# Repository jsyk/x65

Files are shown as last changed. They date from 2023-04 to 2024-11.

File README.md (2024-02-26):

X65
====

The X65 is an ultimate computer for everyone interested in the venerable 65-series of 8-bit and 16-bit CPUs,
i.e. the 6502 and 65816. Specifically, it is built with the W65C02S or W65C816S CPU chips from Western Design Centre.
The 16-bit 65816 (W65C816S) CPU variant is the default and preferred CPU, as all screen-shots shown below were done on the 16-bit system.
The 65816 CPU powered the [Super Nintendo Entertainment System (SNES)](https://en.wikipedia.org/wiki/Super_Nintendo_Entertainment_System) 
and the [Apple IIGS](https://en.wikipedia.org/wiki/Apple_IIGS).
The older 8-bit 6502 CPU was the heart of NES, Apple I and II, many Ataris, Commodore 64, and many many more.

The design of X65 is fully open-source and open-hardware, and we also prefer to use just the open-source development tools
whenever possible. The X65 computer hardware is designed with modern electronics parts, but with a little bit of retro feel.
The computer is backward compatible with the 8-bit Commander X16 -- i.e. it can run their ROM, but since that ROM is copyrighted
and non-free, this is a no-go in the long run.
The goal is to build a fully *open* 8/16-bit system with good architecture and retro-gaming performance.

Compared with modern powerful platforms like x86, ARM or RISC-V, the small 65-series 8-bit or 16-bit system has the advantage
that one person, a software programmer or electronics designer, can fully comprehend the whole system with all details. 
There are not many abstraction layers hidden in supporting libraries or big frameworks. (In fact, there are none. It is just bare metal.) 

_Interfaces_: VGA 640x480 out, Stereo sound out (FM and PSG), PS/2 keyboard and mouse, SNES controller 2x ports,
Ethernet LAN 10/100Mpbs with RJ45, SDHC card slot, power-in 5V USB-C port, In-Circuit Debugger (ICD) over the USB-C with 
PC host software in Python and supporting JTAG-like functions for the 65xx platform (CPU step, trace, memory dump & poke).

Project web pages: http://www.x65.eu  -> currently links to http://www.jsykora.info

3D-render of the *Single-Board Computer* version:

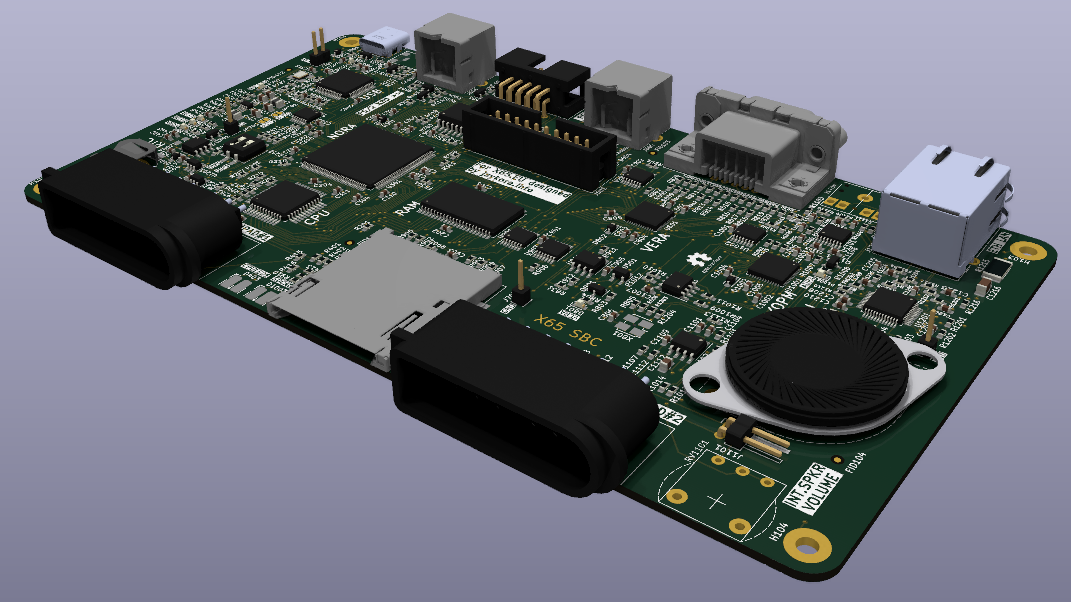
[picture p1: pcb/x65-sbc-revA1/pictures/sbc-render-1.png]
Version SBC


Desktop setup with X65-SBC, PS/2 mouse and keyboard and a VGA monitor. Running `Planet X16' by David Murray with CX16 ROMs:

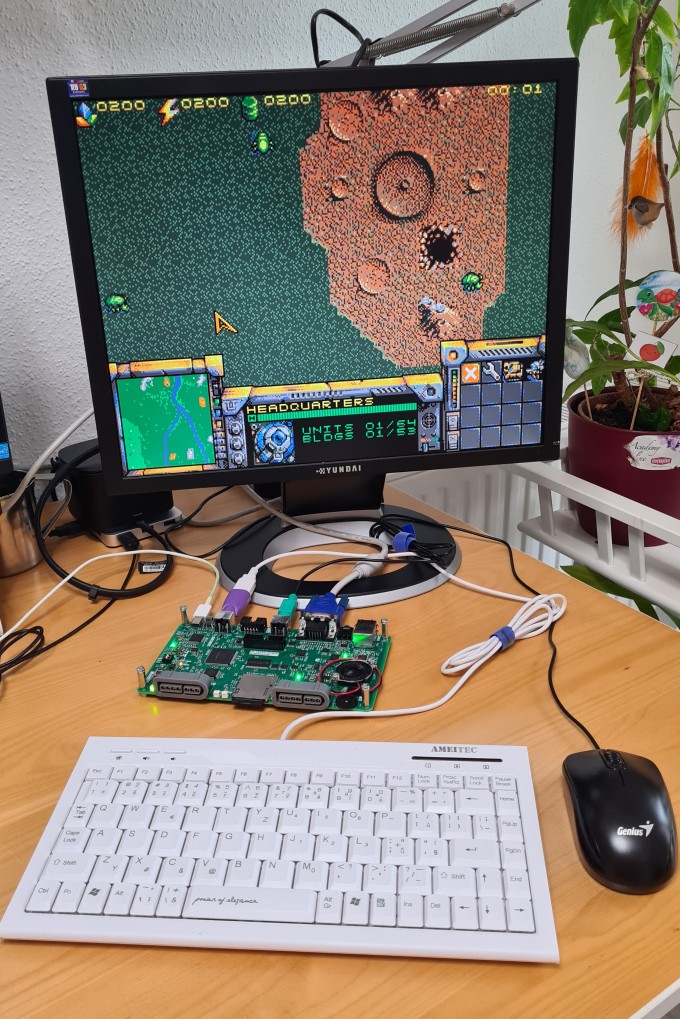
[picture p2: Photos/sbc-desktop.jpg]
Desktop with SBC


General Project Features:
-------------------------

* The CPU is W65C02 (8-bit) or the W65C816 (16-bit; default-preferred). The PCB supports both assembly options.
* Backward software compatibility with the [Commander X16](https://www.commanderx16.com/) computer.
  Can run unmodified CX16 ROM for testing purposes (beware: the ROMs are copyrighted non-free code!).
* Designed with components (chips) that are in production and available from normal electronics parts distributors in 2024,
  such as Mouser, Farnell, Digikey etc. We avoid obsolete parts.
* Balanced modern/retro design built around the central 65xx CPU supported by semi-ASICs (FPGAs) for system control (NORA),
  video (VERA) and audio (AURA) generation. The FPGAs are the little ones from the iCE40 series, and coded in verilog.
  These are modern takes on the "old masters'" designs with ULA, VIA, SID etc.
  *There is no hidden ARM or RISC-V doing heavy lifting in the background.*
* Free and open-source design. DIY and hobby-builders friendly. 
  Low-cost to build even in small quantities by individual hackers.

Block Diagram
---------------

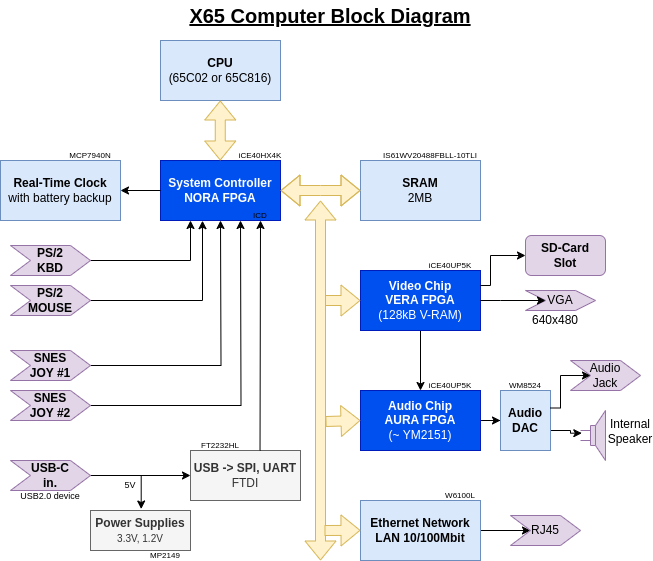
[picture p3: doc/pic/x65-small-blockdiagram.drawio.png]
Block Diagram


Hardware Specification:
------------------------

* **CPU**: [W65C02 or W65C816](doc/cpu02vs816.md) in the QFP-44 package, running at 8MHz, supplied by 3.3V.
* **Memory**: 2MB asynchronous SRAM, common for ROM and RAM.
* **System controller** semi-ASIC, aka north-bridge, aka NORA: Lattice FPGA iCE40HX4K (TQFP-144) handles address decoding, 
  glue logic, PS/2 interfaces, in-circuit debugger and more. 
  "NORA" stands for NORth Adapter, has a similar function like the north bridge in a PC/X86 architecture.
  NORA takes care of the [memory address map](doc/mem-map.md) and hosts most of the [IO registers](doc/ioregs.md).
* Two ports for **SNES-style controllers**, handled by NORA.
* Two **PS/2 ports** for keyboard and mouse, handled by NORA. (note: we reimplement CX16 arduino code in pure hardware logic in verilog.)
* **Colour video** output through VGA connector, up to 640x480 pixels. 
  Generated by [VERA FPGA](https://github.com/X16Community/vera-module): the Video Embedded Retro Adapter, in Lattice FPGA iCE40UP5K. 
  The same is used in Commander X16.
* **Stereo audio** output through 3.5mm jack port. 
  Sound comes from two sources: FM-synthesis (OPM) by YM2151 clone [IKAOPM](https://github.com/ika-musume/IKAOPM) 
  implemented in [AURA FPGA](doc/aura_ym2151.md) (iCE40UP5K),
  and Programmable Sound Generator (PSG) available in VERA FPGA. These are digitally mixed in AURA and passed to a DAC.
  Besides the output jack connector, the sound can be also heard from a small on-board mono speaker.
* **SD-card slot** supporting SDHC cards (handled by VERA FPGA).
* **LAN 10/100Mbps** Ethernet port (RJ45) implemented by [Wiznet W6100](https://www.wiznet.io/product-item/w6100/) chip, 
  with hardware-integrated TCP/IP v4/v6 stack.
* **Real-time clock** (RTC) chip with battery backup.
* [**In-circuit debugger**](doc/icd.md) (ICD) integrated with NORA and accessible over the device USB-C port from a host PC
  running Linux or Windows. The ICD can write all permanent (SPI-Flash) memories in the system, 
  even in a totally empty / bricked state. PC host software is written in Python and should be portable to other 
  fruitful systems besides Linux and Windows.
  Together with NORA the ICD supports JTAG-like functions like memory poke/dump, CPU stop/step, instruction
  trace buffer, interrupt forcing/blocking etc.
* **Power input** 5V from a standard USB Type-C device port.
  The X65 computer can be powered from a normal host-PC USB port (for development with ICD), 
  or runs standalone from a common Mains/USB phone charger with just 5V output.
* Single-board PCB 180x100mm, 4-layers.

Hardware Photos:
----------------

Overview photos (2024/02) - Single-Board version:

**SBC Front view photo**:

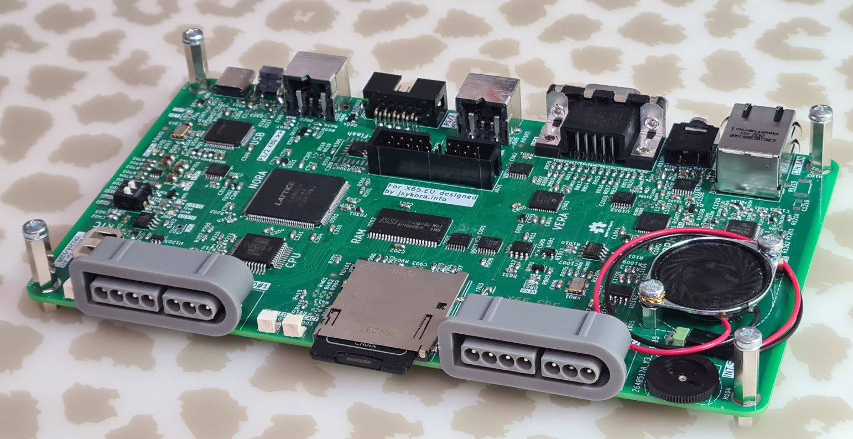
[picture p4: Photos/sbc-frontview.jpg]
Front view photo


**SBC Rear view photo**:

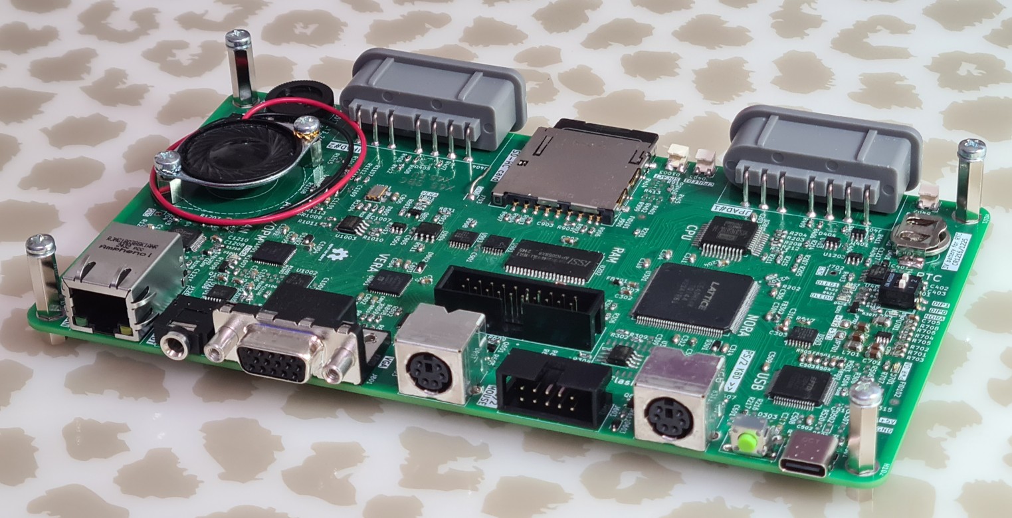
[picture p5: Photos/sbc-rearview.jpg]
Rear view photo


**SBC Top view with labels**:

Engineering testing samples, hand-assembled:

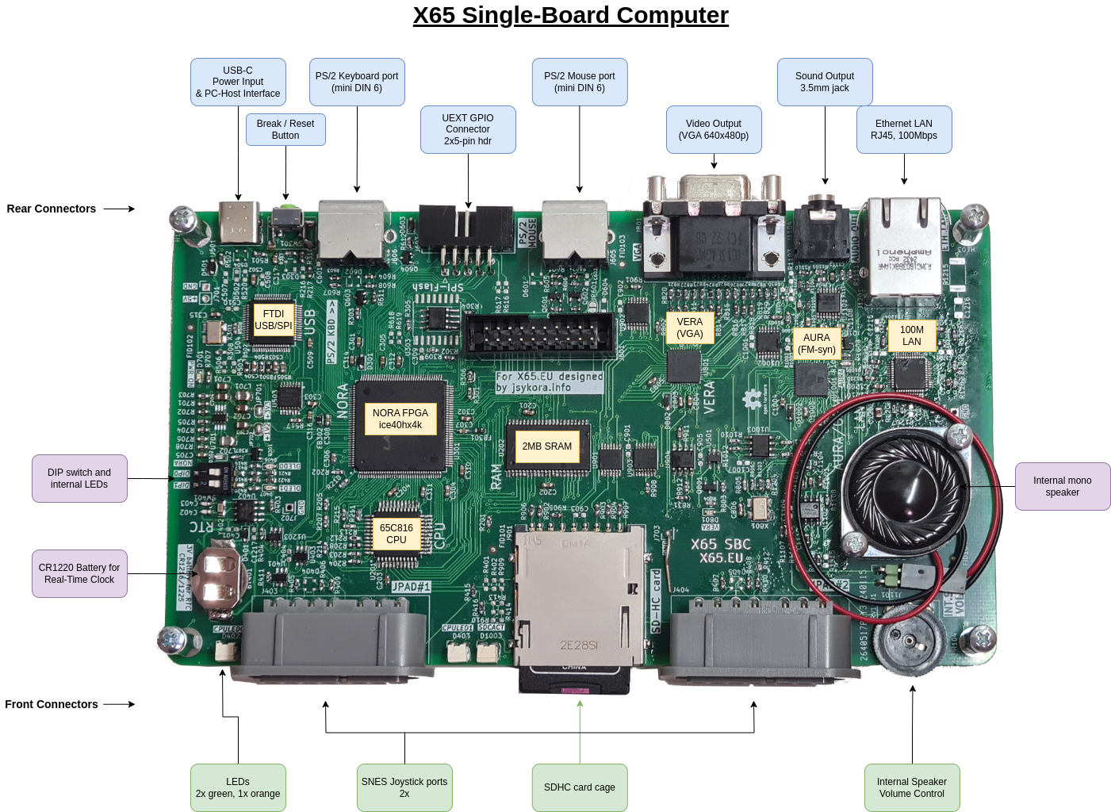
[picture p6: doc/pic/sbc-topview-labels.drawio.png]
SBC topview with labels


Demo Software Screen Photos
----------------------------

Running Commander X16 ROM and BASIC program (compatibility testing only, not allowed in production use due to a proprietary license):

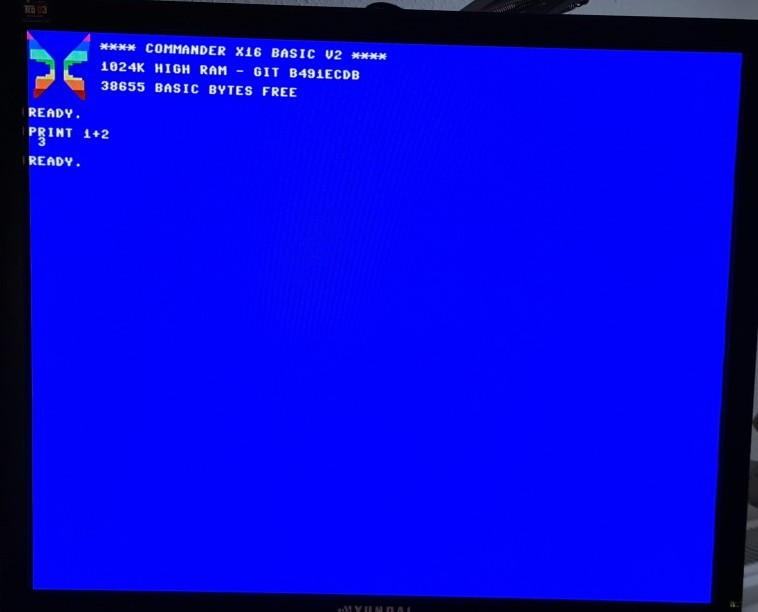
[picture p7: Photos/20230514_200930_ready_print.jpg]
X16 Booted


**BAD METAL** demo from CX16:

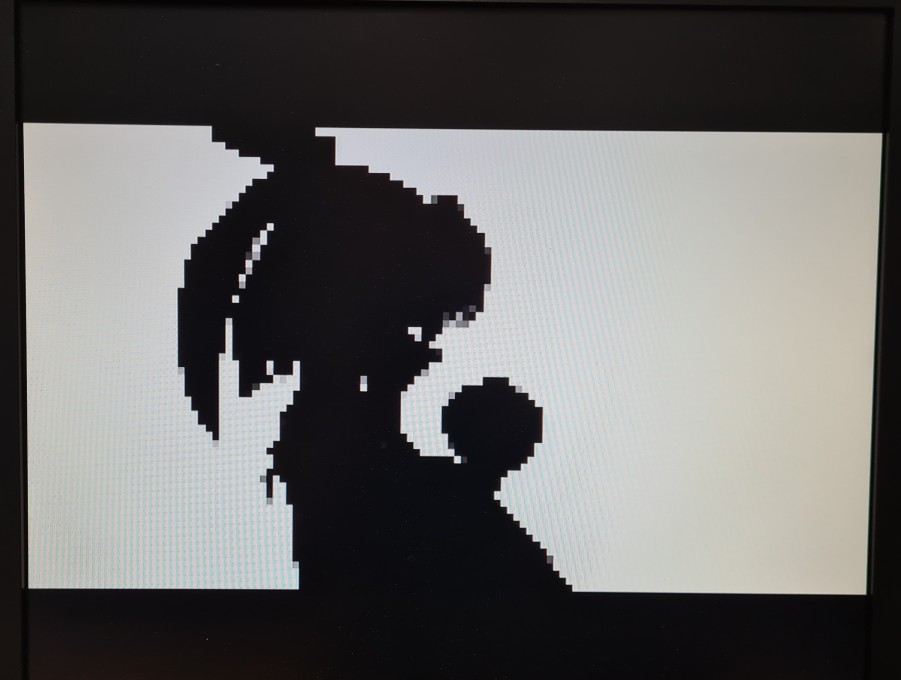
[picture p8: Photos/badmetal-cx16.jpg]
BadMetal


**CALLIOPE** music player from CX16:

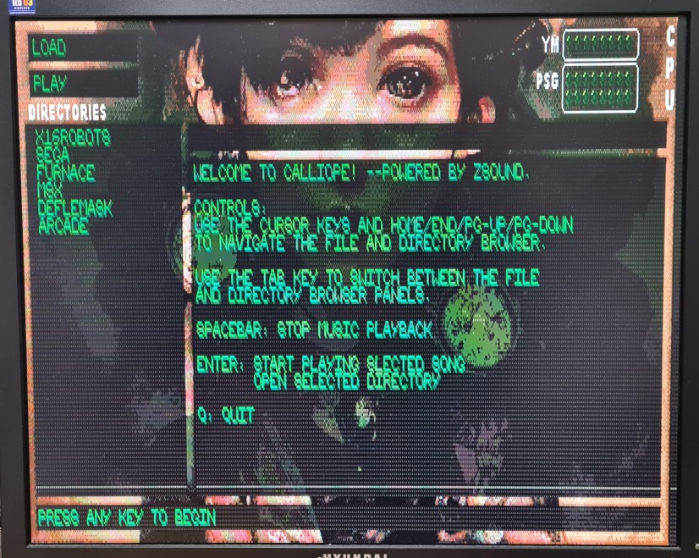
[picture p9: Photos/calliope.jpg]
Calliope


**Crazy Boulders**, a CX16 game by Dušan Štrakl:

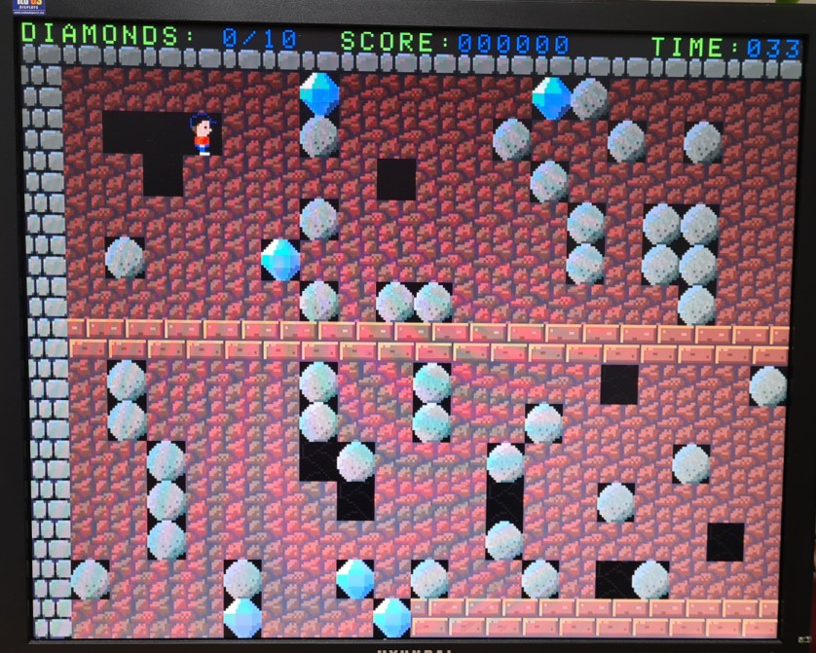
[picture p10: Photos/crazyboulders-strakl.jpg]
Crazy Boulders


**Crazy Lander**, a CX16 game by Dušan Štrakl:

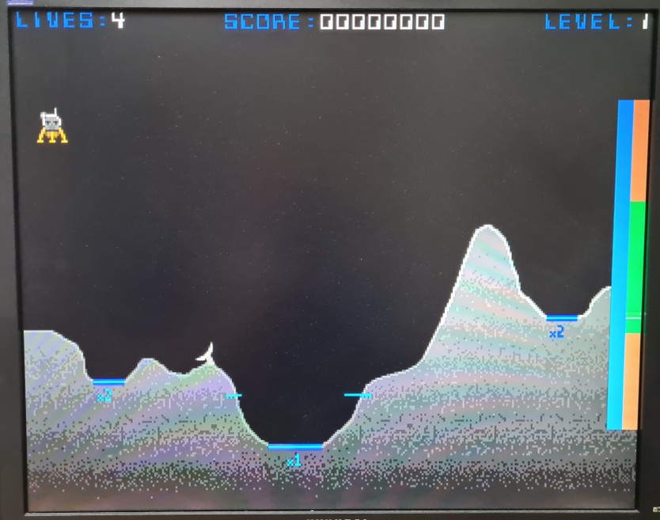
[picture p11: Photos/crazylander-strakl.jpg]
Crazy Lander


**Crazy Pong**, a CX16 game by Dušan Štrakl:

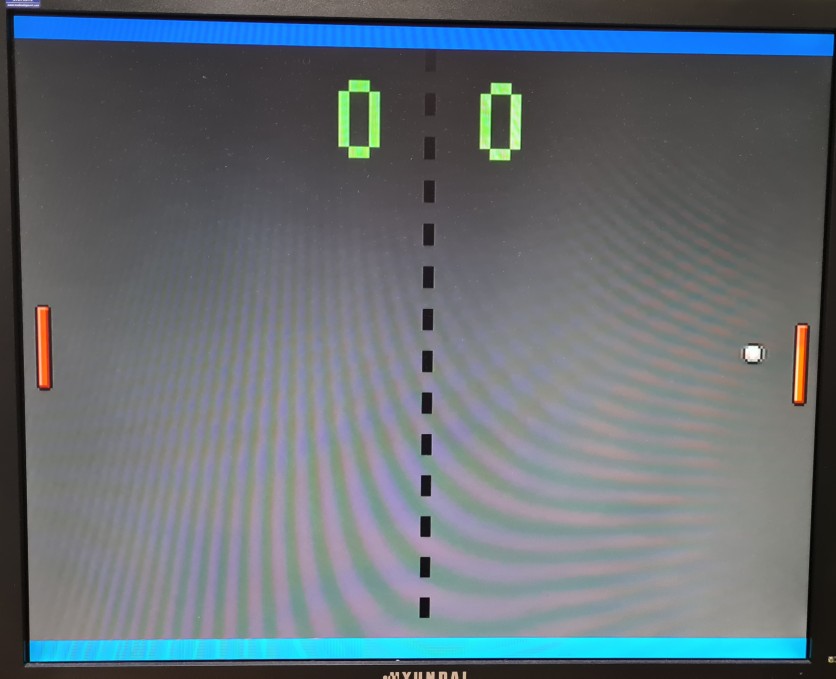
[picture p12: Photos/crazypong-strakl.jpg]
Crazy Pong


**Planet X16**, a CX16 game by David Murray:

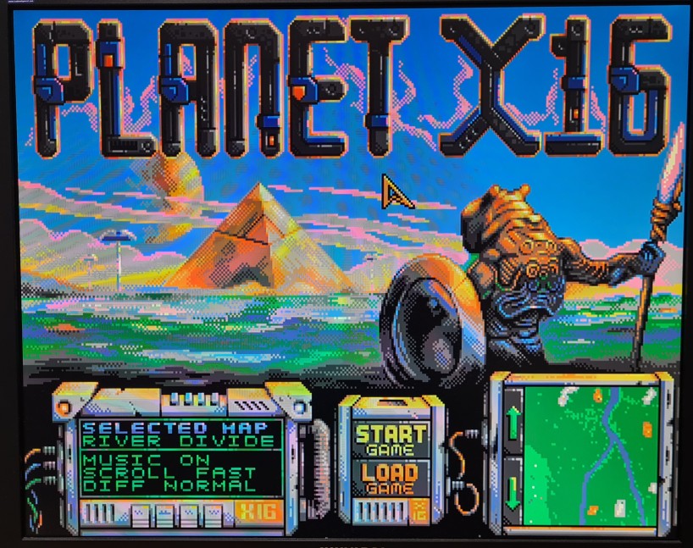
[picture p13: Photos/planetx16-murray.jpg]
Planet X16


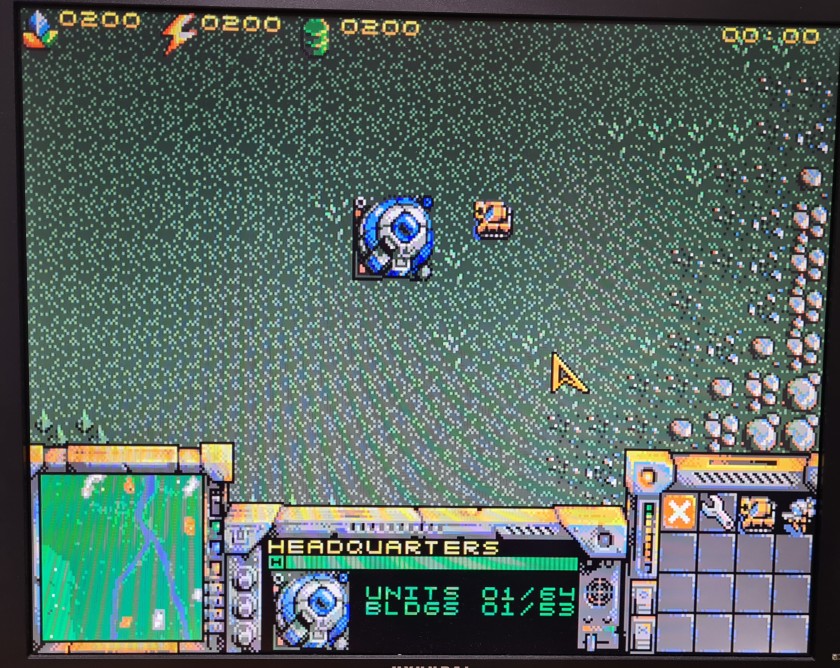
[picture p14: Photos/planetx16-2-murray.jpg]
Planet X16


[**Integrated In-Circuit Debugger**](doc/icd.md) can live-trace the CPU from a Linux PC over the USB:

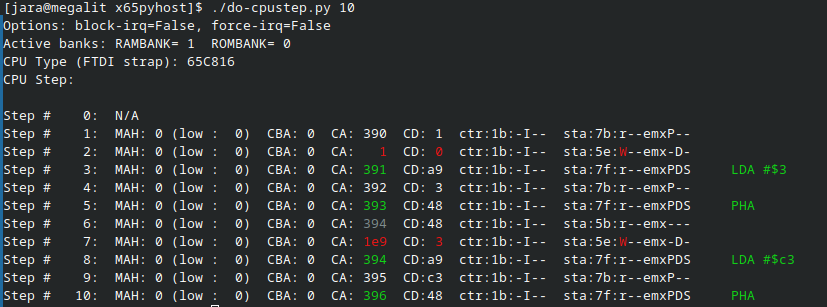
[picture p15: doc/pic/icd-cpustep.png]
ICD CpuStep


Structure of the GIT repository:
---------------------------------

* `doc' --> documentation
* `fpga-aura' --> verilog code for the AURA FPGA (Audio) with referenced IKAOPM sources.
* `fpga-nora' --> verilog code for the NORA FPGA on the motherboard.
* `fpga-vera' --> VERA FPGA bitstream (100% derived from https://github.com/fvdhoef/vera-module)
* `pcb' --> hardware projects in Kicad:
  - `mobo-rev01' --> Motherboard rev01 - OBSOLETE
  - `vabo-rev01' --> Video/Audio board rev01 - OBSOLETE
  - `x65-sbc-revA1' --> *Single-Board computer*
* `x65prog' --> linux software to program the on-board SPI flash memories from a host Linux PC via the USB link.
* `x65pyhost' --> python scripts for accessing/debugging the X65 from a host PC via the USB link.

Schematics in PDF:
------------------

**SBC Revision A1:**

* [X65-SBC, revA1 - PDF scm](pcb/x65-sbc-revA1/x65-sbc-revA1.pdf)

**SBC Revision B1:**

* [X65-SBC, revB1 - PDF scm](pcb/x65-sbc-revB1/x65-sbc-revB1.pdf)

Software:
-----------

The X65 is software-backwards-compatible with the *Commander X16*. 
It means the X65 could run unmodified CX16 ROM and programs, excluding programs depending on some of the hardware features 
in CX16 that are not supported here: cartridges, Commodore IEC port.
However, the CX16 ROM is a **proprietary**, non-open-source and non-free, piece of software created by Commodore
and (somehow) licensed to the CX16 creators. *The licensees do not wish that the ROM runs on any other HW than their own.*
Therefore, I could not recommend running that ROM on the X65 computer.

Presently I am not decided which operating system or runtime shell would be the best / easiest to port to X65.
There some existing systems that could be ported here, for example:

* [MEGA65 OPEN-ROMs](https://github.com/MEGA65/open-roms) (true free open-source sw),
* [FastBasic](https://github.com/dmsc/fastbasic)
* [GeckOS](http://www.6502.org/users/andre/osa/index.html)
* ...

Random Questions & Answers
---------------------------

**Why was this project started?**

This project started in March 2023 when I saw a prototype of Commander X16 in one of the youtube videos
of the 8-bit guy, David Murray. I immediately wanted to play with it but at the time his project was not released to the public,
the hardware could not be bought. So I decided to build one myself, based on public information available
about the CX16. And at the same time I was not too pleased with the architecture and implementation
of the CX16, not satisfied with many design choices they did. 
Consequently, my X65 tries to improve in many areas while being software-compatible.

**What is the relation to *Commander X16* and its authors?**

I have no relation or contact to the authors of Commander X16.
The public discussion forums for CX16 on discord and reddit have the policy that any discussion or mention of any
*clones* of CX16 is forbidden. 
While I find this policy strange for a community project, I respect it.
Therefore I do not tell the guys about the X65 project.

**What is the license of X65 project? Which copyrighted material was used?**

I used publicly available information on wikipedia and in the X16Community's public forums and repositories to reconstruct the CX16 architecture.
I don't have access to the schematics of X16, and I don't own that computer and never seen it in person.
My analysis of the CX16 architecture is available in the file [cx16.md](doc/cx16.md).
The [VERA](https://github.com/fvdhoef/vera-module) FPGA by Frank van den Hoef, also [here](https://github.com/X16Community/vera-module),
 was reused as-is and it is covered by the open-source MIT license.
The AURA FPGA is based on [IKAOPM](https://github.com/ika-musume/IKAOPM), a YM2151 reconstruction in verilog, and it is covered by the BSD 2-Clause License.
All my documents and designs in this repository are covered by the [MIT license](LICENSE).
The restricted CX16 ROMs are not part of this repository.

**What are the advantages of X65-SBC over other retro-modern-computers?**

The X65-SBC is a complete computer system with ports for a keyboard and a mouse, a high-resolution VGA output (128kB Video-RAM), 
and high-quality stereo audio capable of PCM, PSG (Programmable Sound Generator) and FM-synthesis sound generation.
Compared with other 65xx-based computers, we support the 16-bit processor 65C816 which is capable of direct addressing of 
up to 16MB of RAM; the X65-SBC includes 2MB of fast SRAM by default.
System controller is realized by NORA FPGA (lattice ice40hx4k) and potentially allows experimenting with additional
features like virtual memory or mathematical coprocessors.
The hardware supports direct programming of FPGA bitstreams via the USB-C port from a Linux PC; in a way the X65-SBC
is a self-contained FPGA development platform.
The design is fully open-source.

**Where can I get the hardware?**

As all relevant HW design data is available in this repository, anybody with appropriate electronics knowledge 
and a lab can build own copy of the X65-SBC hardware.
The cost of electronics components is around 130 EUR, plus the cost of board assembly (which can be done DIY if necessary).
Maybe in the future I can run a very small series build for interested programmers and "hackers". 
However, as these builds surely will not have the requisite FCC / UL / CE approvals (that costs addional money), 
the resulting devices could only be used in a lab for development purposes by knowledgable users.
I am open to the possibility that some company decides to commercionalize X65-SBC as a sellable product and puts it on the market :-)

**Is there an emulator for PC?**

Presently an emulator is not developed yet.
It could be done perhaps based on the [CX16 emulator](https://github.com/commanderx16/x16-emulator); 
the CPU emulation has to be extended to 65C816 and new features (registers)
available in NORA and in W6100 (ethernet interface) need be implemented.

Contact
--------

**Jaroslav Sýkora**
- Personal: http://www.jsykora.info,
- GIT account: https://github.com/jsyk,
- Mastodon: https://oldbytes.space/@jarda,
- (Physically in the Czech Republic.)

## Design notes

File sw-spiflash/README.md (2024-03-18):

Software in NORA's SPI-Flash
=============================

This directory contains the software for NORA's SPI-Flash, which acts as a ROM for the system.
The SPI-Flash is divided in blocks of 64kB.
The first three blocks (192kB) are reserved for NORA FPGA bitstream.
That is followed by a 64kB block for Secondary Bootloader (SBL), and then the operating system
or a standalone application.

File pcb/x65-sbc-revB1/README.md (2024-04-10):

X65-SBC-rev.B1
================

X65 Single-Board Computer, schematic & PCB revision B1.

3D render view of the X65-SBC rev.A1 (Kicad)

Schematic (PDF)

Interactive BOM

!! WORK IN PROGRESS !!
=======================

I restarted changes to revB1 on 04/2024 with the following goals:
* fix remaining issues (SDC power, ESD, see below)
* optimize for machine assembly

To-Be-Done changes from rev.A1 to rev.B1
-------------------------------------------
* add power switch for SDC +3.3V, add digital lines disconnect
    - probably AP2191D ?
* change ESD protection
* change decoupling caps
* move speaker connector
* ...??? see pdf

Implemented changes from rev.A1 to rev.B1
-------------------------------------------
* change green LED resistors to 2k7 (although this depends on LED).
* Remove D504 (USB ESD): the SP0503 is not suitable!
* Add 5V and +3.3V pins to J601 internal mem.bus connector.
* Changed AURA FPGA footprint to the smaller EP pad (now the footprint is the same as VERA)

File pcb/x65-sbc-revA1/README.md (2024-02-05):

X65-SBC-rev.A1
================

X65 Single-Board Computer, schematic & PCB revision A1.

3D render view of the X65-SBC rev.A1 (Kicad)

Schematic (PDF)

Interactive BOM

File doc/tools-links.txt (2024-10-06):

Tools and Sources
===================

Kicad 6, 7

Assembler: 
* ca65 / ld65 -- used in vera at least, in C16 ROMs
    https://cc65.github.io/doc/
    https://cc65.github.io/doc/ca65.html#ss1.1
    Part of Fedora RPMs package cc65
* cc65 - eg in C16 ROMs; can do 6502 and 65816 (directive .p816)
    https://github.com/cc65/cc65/tree/master
    Part of Fedora RPMs package cc65
* ACME - used in some examples; has 6502 and 65816
    https://github.com/martinpiper/ACME
    https://github.com/meonwax/acme

YosysHQ/IceStorm for iCE40 FPGA synthesis
    https://clifford.at/icestorm
    https://yosyshq.net/
    https://github.com/YosysHQ
    
* compiler for 65c816
    http://forum.6502.org/viewtopic.php?f=2&t=7573
    https://github.com/lcc-816
    https://github.com/hth313/Calypsi-tool-chains
    http://forum.6502.org/viewtopic.php?f=2&t=6717
    https://github.com/nArnoSNES/tcc-65816
    https://www.calypsi.cc/

https://llvm-mos.org/wiki/Welcome

https://wiki.superfamicom.org/
https://wiki.superfamicom.org/learning-65816-assembly

PROG8
    https://github.com/irmen/prog8

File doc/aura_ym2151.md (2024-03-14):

AURA FPGA: The replacement of YM2151
====================================

*Abstract:
The article discusses the sound system in the X65 computer. It explains that the sound is generated by two sources: 
the Programmable Sound Generator (PSG) in the VERA FPGA and the MIDI FM-synthesis chip YM2151. 
The article provides a block diagram of the sound subsystem and explains the functionality of each component. 
It also discusses the principle of FM sound synthesis and mentions the difficulty in finding modern software compatible 
replacements for the YM2151 and YM3012 chips. The article introduces an FPGA emulation solution called AURA, 
which uses the Lattice iCE40 FPGA to replicate the YM2151. The implementation of AURA on the x65 board is described, 
along with a cost comparison between the Yamaha chips and the AURA FPGA. 
The article concludes by mentioning a demo application called Calliope that runs on the x65 hardware 
and plays sound files through AURA. 
Overall, the AURA FPGA solution is presented as a viable and cost-effective alternative to the original Yamaha chips.*

Sound in Commander X16
-----------------------

Sound in Commander X16 is generated by two sources that are mixed together:

  1) by the Programmable Sound Generator (PSG) in VERA FPGA, and
  2) by the MIDI FM-synthesis chip YM2151. 

The following picture is a block diagram of the sound subsystem in C'X16:

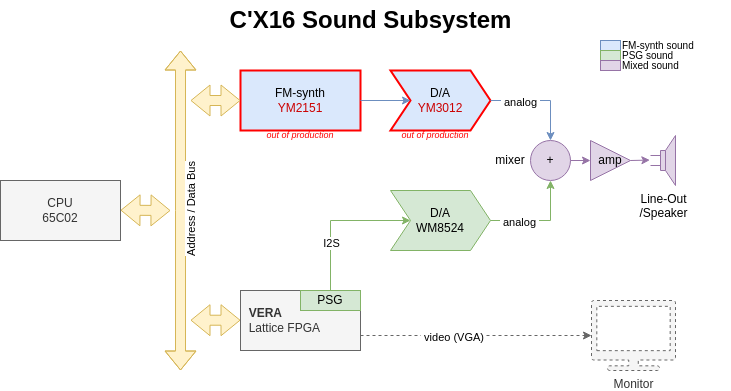
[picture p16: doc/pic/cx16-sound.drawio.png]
Block Diagram of Sound Generator in C'X16


The PSG in VERA FPGA is a stereo sound generator loosely based on SID. It supports 16 channels (voices) and PCM playback.
There is no ADSR or filters. This must be provided by software.
The PSG is an integral part of VERA FPGA user logic that also generates the VGA video output.

MIDI-like sound synthesis is provided by YM2151. Yamaha called it an FM operator Type-M (OPM).
The chip outputs sound digitally as a 10-bit mantissa / 3-bit exponent samples, two channels (left and right),
at the audio sample frequency of about 55 kHz. This digital sound stream is converted to an analog signal 
using special a D/A converter YM3012, also developed by Yamaha.
The picture below illustrates the basic circuit, as taken from the datasheet:

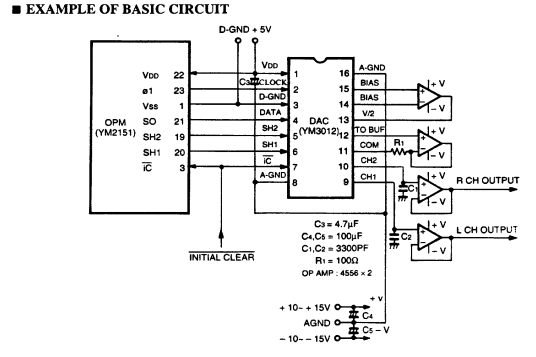
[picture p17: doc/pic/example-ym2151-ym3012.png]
Example of Basic Circuit ym2151+ym3012


YM2151 was created by Yamaha in 1980's, being used by Atari and Sega arcade systems starting in 1984.
As of 2023, this chip is perhaps a quarter of century out of production.
The chip interfaces with then-standard 5V TTL logic, and the D/A converter YM3012 even requires +/- 12V rails for its analog output.

Principle of FM Sound Synthesis
-------------------------------

FM sound synthesis is quite complex topic and I do not claim to understand it so well.
I would recommend the following article which provides some background and details:

https://www.perfectcircuit.com/signal/what-is-fm-synthesis

Sound in x65
------------

I was looking for a modern software compatible replacement of these chips and, since the architecture is unique, 
the only practical solution is via an emulation in FPGA. I wanted to use a Lattice iCE40 FPGA, to keep in line with the rest
of my x65 design (both NORA and VERA are iCE40 FPGAs). 
There are multiple YM2151 emulations for FPGA available on the open-source internet; I found two: jt51 and [IKAOPM](https://github.com/ika-musume/IKAOPM).
The problem with both, or rather the problem with the original design is that it is using a lot of flip-flops as delay shift-registers.
This is actually not a big deal for modern FPGAs from Altera/Intel or Xilinx/AMD, as they could implement shift-registers efficiently in LUTs.
But an old architecture like iCE40 struggles and is forced to use a lot of basic logic blocks to implement these shift registers.
Therefore, jt51 could not be used because it does not fit in a suitable FPGA of the iCE40 line.
The IKAOPM, after some configuration (USE_DPRAM=1), thankfully fits in the 5K device (ice40up5k-sg48) - allocating around 80% capacity of the 5K device.

I call the FPGA device implementing the compatible FM-synthesis "AURA", from AUdio Retro Adapter.
It is Lattice ice40up5k-sg48 FPGA, the same type used for VERA, so the x65 has twice the same FPGA on the board - for audio and for video.
The emulation main part is done by IKAOPM project, which is a verilog synthesisable replica of the YM2151.

The picture below shows the sound subsystem of x65:

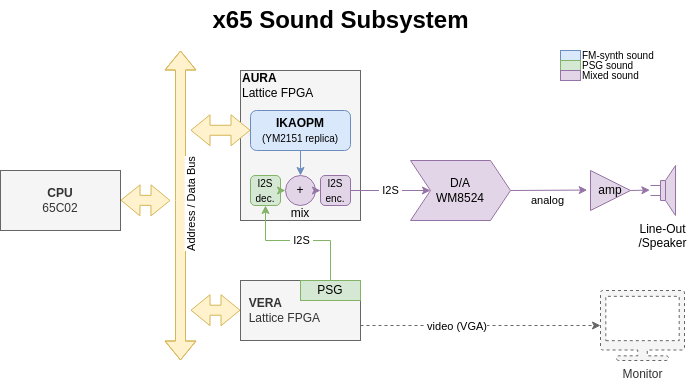
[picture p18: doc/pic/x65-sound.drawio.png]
x65 Sound Subsystem


AURA outputs the sound in the stereo 16-bit I2S format, which is converted to the analog signal by the WM8524 D/A converter.
The PSG sound from VERA is also in the same I2S format. AURA has an auxiliary I2S input for the PSG sound; mixing of both sound sources
is done digitally in AURA.

Implementation on the x65 Board
-------------------------------

The photo bellow shows the x65 audio/video board with the VERA and AURA FPGAs labelled. The DAC chip and the audio and video output connectors
are also visible and marked.

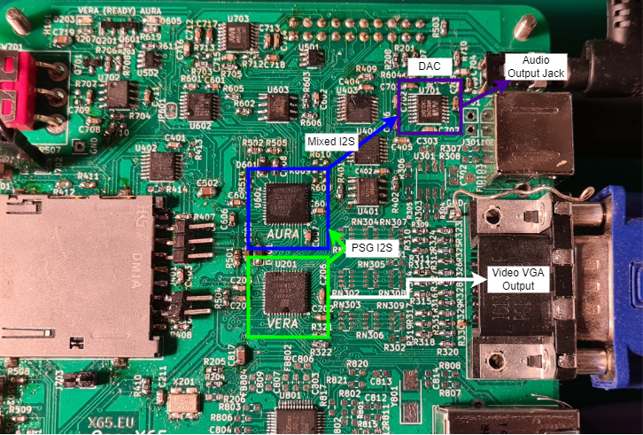
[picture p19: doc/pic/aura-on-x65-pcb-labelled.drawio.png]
Photo of x65 PCB with VERA, AURA and DAC chips labelled


TBD: record sound played through VERA + AURA.

Cost Comparison
---------------

Both Yamaha chips are long out of production (discontinued). 
It is not possible to buy them from normal distributors of electronic parts  like Mouser, Farnell, Digikey etc. 
The Yamaha chips are typically to be had on ebay from various sellers, in various quantities and prices.
A brief ebay listings overview shows that the D/A YM3012 costs around 1 EUR/1pc, and the FM-synth YM2151 around 9 EUR/1pc. 
Therefore the total cost using Yamaha parts could be 10 EUR, plus the analog sound mixer.

The AURA FPGA, ice40up5k-sg48, costs around 9.30 EUR/1pc, or 7.8 EUR in 100-piece quantity. 
To this we should add the cost of one SPI-Flash memory necessary to store the FPGA bitstream; 
I use W25Q16JVSNIQ which costs 0.45 EUR/1pc. 
I do not calculate the cost of the D/A converter WM8524 since it is equally present in both solution (for VERA PSG).
Therefore, the total cost using AURA FPGA is around 10 EUR in 1pc quantity (or better, if bought in quantity).

Demo
----

[Calliope](https://github.com/ZeroByteOrg/calliope) is a player / jukebox application for Commander X16.
It can play files in the ZSM format. It supports output through the VERA PSG and YM2151 FM-synth.
This is a photo od Calliope running on X65 hardware, playing a sound file through the AURA:

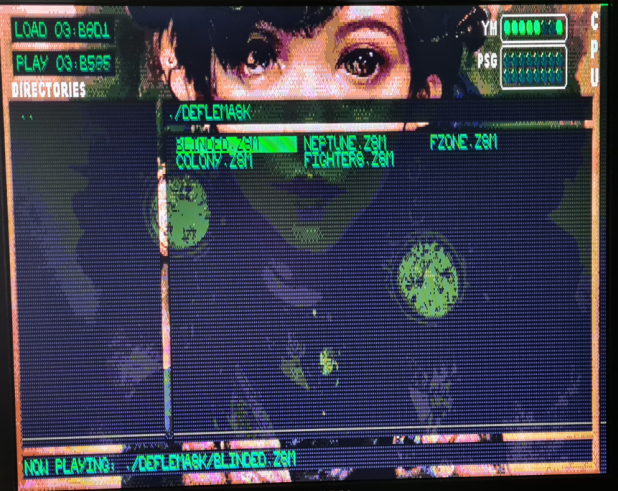
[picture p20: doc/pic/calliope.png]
Calliope on X65


Conclusion
----------

In conclusion, the solution with AURA FPGA has the following advantages:

* good availbility of chips at distributors, 
* the same or better cost, 
* direct interfacing with the 3.3V LVTTL logic used in the x65 design, 
* not requiring +/- 12V for the DAC, 
* smaller total footpring size on the PCB because of small component packages.

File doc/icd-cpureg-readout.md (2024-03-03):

Reading of 6502/65816 CPU Registers by a PC-based Debugger
============================================================

Modern microcontrollers and microprocessors have built-in facilities for external debuggers
to read/write registers, set breakpoints and generally fully control the CPU. 
This is one of the main usecases of the standard [JTAG](https://en.wikipedia.org/wiki/JTAG#Debugging) interface.
The 6502 and 65816 CPUs were created more than a _decade_ before the first version of JTAG was even defined.
They contain no support for external debuggers whatsoever. 

To overcome the lack of debugger support, the system bus controller "NORA" in X65 implements 
the necessary functions for a debugger running on a host PC (with Linux or Windows) and connected over the USB-C port. 
With this support in NORA a debugger can control the 6502/65816 CPU at the instruction level.

One of the basic functions of a debugger is to read out the contents of the programmer visible CPU registers.

For the 8-bit 6502 CPU these are: A, X, Y, S (= SP) (all 8-bit), PC (16-bit), and flags (8-bit); shown below:

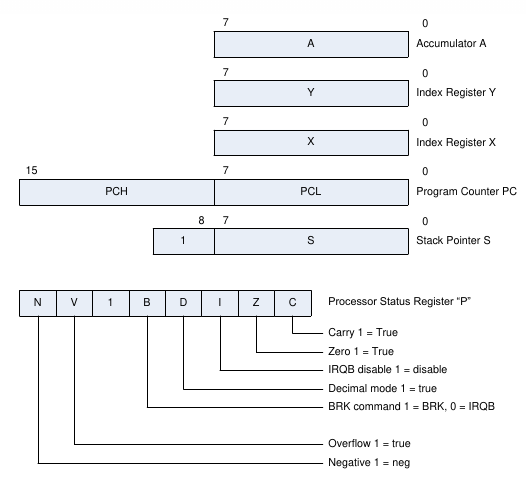
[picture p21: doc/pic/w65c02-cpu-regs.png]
W65C02 CPU registers


For the 16-bit 65816 CPU these are: A, X, Y, S (= SP) (all 16-bit), PC (24-bit), DBR (Data Bank Register, 8-bit), 
Direct Register (DH:DL, 16-bit), and the flags (8-bit); shown below:

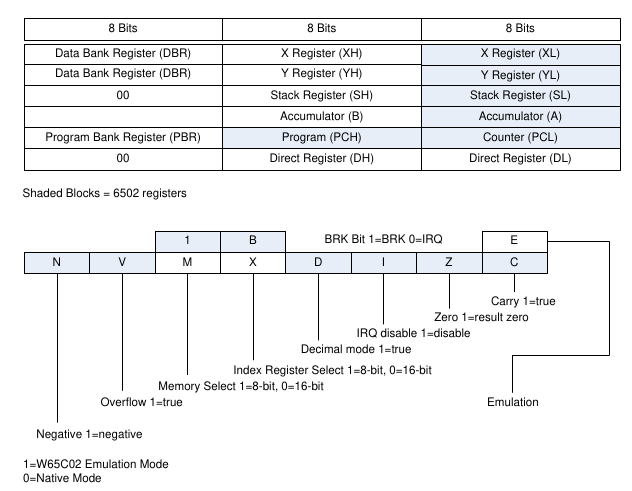
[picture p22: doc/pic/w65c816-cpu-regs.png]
W65C816 CPU registers


Block Diagram of NORA's In-Circuit Debugger (ICD)
--------------------------------------------------

The block diagram below shows the concept of the In-Circuit Debugger (ICD) in the X65 computer.
NORA FPGA implements all interfaces between the 65xx CPU, and the memory bus with SRAM, VERA and AURA FPGAs.
The particular verilog module in NORA that implements the CPU/memory interface is called [bus_controller](../fpga-nora/src/bus_controller.v).
Another module, the [phaser](../fpga-nora/src/phaser.v), generates the CPU clock signal PHI2 
and additional internal timing signals that must be in sync with the CPU execution. 
The third module mentioned in the picture is the [icd_controller](../fpga-nora/src/icd_controller.v)
which controls the bus_controller and phaser during debug sessions, and during system startups,
but othertimes it is idle.

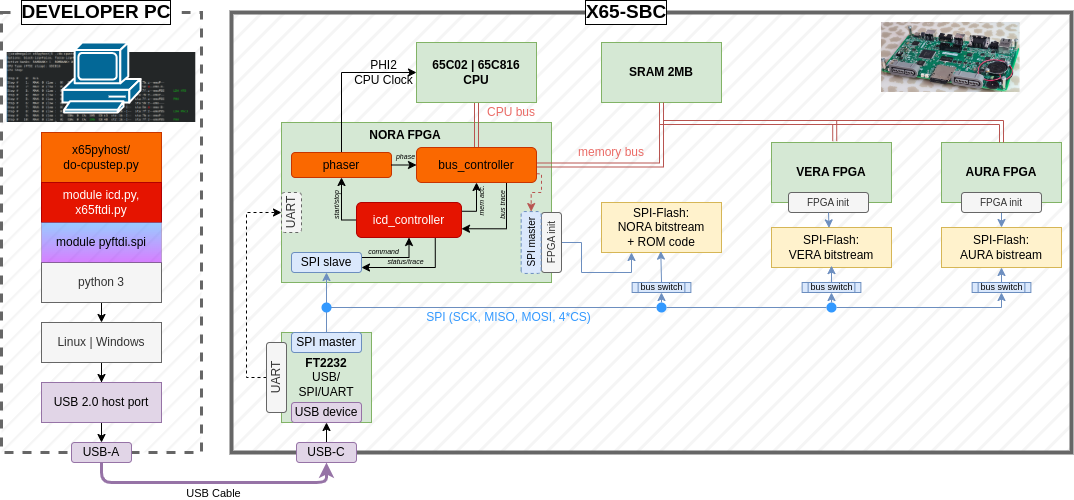
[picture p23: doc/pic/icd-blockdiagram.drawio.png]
ICD Block Diagram


The icd_controller itself responds to commands received from an [SPI Slave](../fpga-nora/src/spi_slave.v)
port, which is connected to physical SPI pins on the FPGA (signals ICD_CSn:in, ICD_MOSI:in, ICD_MISO:out, ICD_SCK:in).
These pins are connected on PCB to the FTDI USB/SPI+UART converter (FT2232H), and from there via a USB cable
to a host PC with a debugger software.

Debugger software for X65 is implemented in Python 3 (with the pyftdi module) and it is available in the
git repository in subfolder x65pyhost.
For simplicity of development, debugger commands are not yet integrated in an IDE but they are available as individual
programs called from a command line.
The most commonly used commands (= python scripts) are listed in the table:

| Command (script)  | Description |
| ---|---|
| do-cpureset.py | Reset and stop the 65xx CPU |
| do-cpurun.py | Run the CPU |
| do-cpustep.py | Stop the CPU and step it for the given number of instructions or CPU cycles |
| do-dump.py | Memory dump (including IO areas) |
| do-loadbin.py | Load a binary from specified host file into X65 memory |
| do-loadprg.py | Load a C64/CX16 program from a .PRG file into X65 memory |
| do-poke.py | Write memory location in X65 memory (incl. IO area) |
| do-readregs.py | Read CPU registers (the CPU must be stopped) |

Register Reading Sequence
--------------------------------------------------

Reading of 65xx CPU internal registers is implemented in the do-readregs.py and do-cpustep.py scripts that communicate
with the ICD module in NORA FPGA over the USB/SPI bridge implemented on the PCB of X65 computer.
Lets discuss how the registers are obtained from the CPU by NORA.
As mentioned previously, the 65xx CPUs have absolutely zero support for external debuggers wishing to access internal registers
outside of a program running in the processor.

The access is gained by forcing a predefined sequence of instructions to the CPU and observing
signals on the CPU Data and Address Buses.
At each CPU cycle, the 65xx processor accesses the external memory for either a read or write.
By observing CPU status signals VPA and VDA (or SYNC), it is possible to determine if any given cycle is an opcode fetch.
If it is an opcode fetch cycle, the debugger can instruct the ICD in NORA to force an *alternative* opcode
to the CPU than what would be read from a memory, thus altering the program flow at will.

The following instruction sequence is forced from the debugger to read out all registers:

    orig_pc:
        PHP             ; we get PC, SP, Flags
        PLP             ; 
        STA $2          ; block writes; We get A, and on 65816 we get B depending on flag M, and we get DH:DL (DPR) on address bus
        STX $4440       ; block writes; We get X, and on 65816 we get XH depending on flag X, we get DBR from CPU Bank Address.
        STY $6          ; block writes; We get Y, and on 65816 we get YH depending on flag X
        BRA orig_pc     ; jump back to the back to leave CPU registers in the original state

The code (PHP-PLP-STA-STX-STY-BRA) is position-independent: it could be execute at any CPU state.
The first two 65xx instructions are *PHP* (Push Flags to Stack) and *PLP* (Pull Flags from Stack).
NORA captures the trace of the the CPU Data Bus, Address Bus and Status signals while these instruction execute
and the debugger uses the trace to reconstruct the original PC (Program Counter) address and 
the SP (Stack Pointer) address, and the flags register.

Screenshot below shows the trace output of *do-cpustep.py* (on Linux PC) when the 65xx CPU (actually 65C816 in Emulation Mode)
is executing the opening PHP-PLP sequence. 
The screenshot is annotated at the top with explanations of trace columns, and at the bottom with the trace fields
that correspond to exposed CPU internal registers:

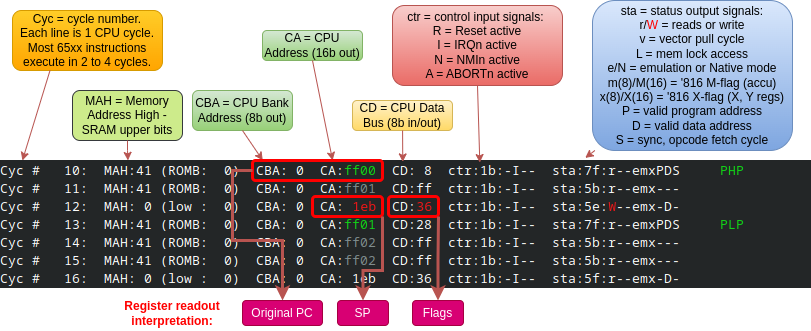
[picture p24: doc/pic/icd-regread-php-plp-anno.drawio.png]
Trace of PHP-PLP instruction in 6502, with annotations


The original PC (Program Counter) is the op-code fetch address of the first instruction.
The SP (Stack Pointer) is the write address in the third CPU cycle (Cyc #12), and the CPU flags are the data value
written to the memory at that cycle.
The instruction PLP is necessary to restore the contents of SP inside the CPU to the original value.

The next screenshot shows the trace of the remaining instructions in the sequence: STA-STX-STY-BRA.
The contents of registers A, X and Y is obtained from the data bus write cycles during the execution 
of the STA (Store Accumulator), STX (Store X-reg) and STY (Store Y-reg) instructions.
To not disturb the original memory contents by these writes, the memory write signal is silently blocked by NORA, 
although this is not reflected in the trace buffer.

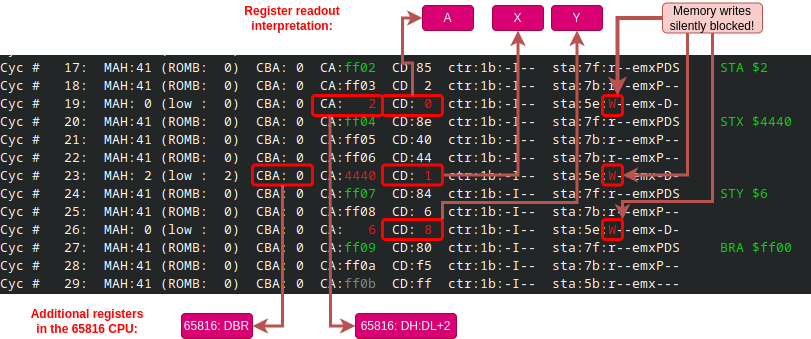
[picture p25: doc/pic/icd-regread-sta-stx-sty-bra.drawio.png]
Trace of STA-STX-STY-BRA


The final instruction BRA (Branch Always) is necessary to restore the original contents of the PC register; 
it instructs the CPU to jump five instruction back.

The 65816 CPU
---------------

So far we discussed how to obtain registers from the 8-bit 6502 processor.
The 16-bit 65816 processor has the common registers extended to 16-bits, plus it has some additional registers.
The traces shown above were obtained on the 65816 CPU running in the 8-bit *Emulation Mode*, where the processor
is behaving like the 8-bit 6502. 
(Emulation Mode is indicated by the "e" in the "sta" field of the trace. 
Mode information is available on an output pin of the processor.)

When the 65816 processor switches to the 16-bit *Native Mode*, the additional registers DBR (Data Bank Register),
PBR (Program Bank Register, part of PC) and DH:DL (Direct (Page) Register) get activated.
The traces above mark where these registers are exposed as well.
Then, depending if the new M and X flags in the CPU Flag Register are cleared, also the Accumulator and Index Registers X/Y are extended to 16-bits.
The M-flag controls the width of the accumulator (A -> AH:AL) and of the memory accesses (in all LD and ST-type instructions), 
and the X-flag control the widths of registers X (XH:XL) and Y (YH:YL).
These three important flags (Emulation or Native mode, M-flag, and X-flag) are available on CPU pins, 
therefore they are always visible in the trace buffer.

The screenshot below shows the trace of the sequence PHP-PLP-STA-STX-STY in case the 65816 CPU is in the 16-bit *Native Mode* 
and also the accumulator and index registers are switched to the 16-bit mode (i.e. M-flag=0, X-flag=0). 
(The BRA instruction is not shown for brevity, but it is also part of the forced sequence.)
We can see that the execution of the STA, STX and STY opcodes gains one additional CPU cycle during which the upper parts
of the A/X/Y registers are written to the memory (these writes are blocked in NORA), and exposed for the debugger.
The contents of the new address registers PBR, DBR, and DH:DL is meanwhile also available on the address bus.

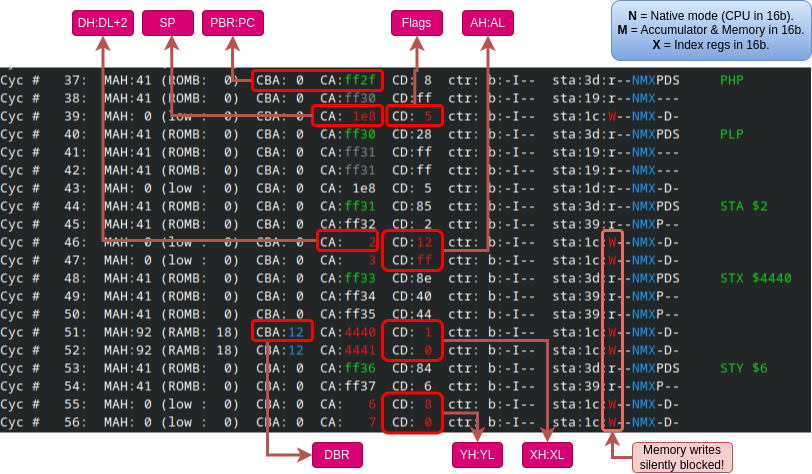
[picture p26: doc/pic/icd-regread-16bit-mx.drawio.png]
Trace of PHP-PLP-STA-STX-STY in 16-bit Native Mode


Integration
-------------

The complete register readout sequence is integrated in the script do-cpustep.py.
This script dumps the 65xx CPU trace buffer and then executes a user-specified number of following instructions.
Finally, the script executes the readout sequence in the background and prints the CPU register values.
The forced readout sequence is not shown in the printed trace, of course.

The screenshot below shows the user interface when the command "./do-cpustep.py 3" (step for 3 instruction) 
is started on a Linux host PC connected with a USB cable to the X65 computer.
The last line is the CPU register contents after the last instruction executed (and before "Upcoming", 
which has *not* been executed yet, it is just the prediction of the debugger based on PC).
Notice how the displayed contents of the A register ($03) in the last line corresponds to the LDA instruction (LDA #$03),
and the contents of the SP register ($1e9) corresponds to the push-address in the first PHA instruction 
($1ea = the SP is decremented AFTER pushing).

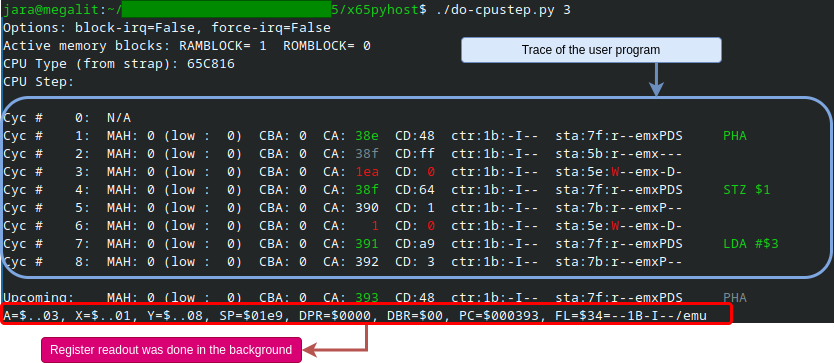
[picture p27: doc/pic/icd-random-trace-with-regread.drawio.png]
Register readout integrated in trace


Conclusion
------------

In embedded systems reading of processor registers via a JTAG connection from a host PC is the basic functionality
that we take for granted.
Using the "NORA" FPGA as the system controller in the X65 computer brings this functionality also to the world
of 6502/65816 processors.

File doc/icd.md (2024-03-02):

In-Circuit Debugger (ICD) for 6502/65816 CPUs
================================================

**In-circuit debugger** (ICD) integrated with NORA and accessible over the device USB-C port from a host PC
running Linux or Windows. 
The ICD can write all permanent (SPI-Flash) memories in the system, even in a totally empty / bricked state. 
PC host software is written in Python and should be portable to other fruitful systems besides Linux and Windows.

Together with NORA the ICD supports JTAG-like functions like memory poke/dump, CPU stop/step, instruction
trace buffer, interrupt forcing/blocking etc.

Example: Live trace/step of the CPU:

ICD CpuStep

Example: Dump of the IO area ($9F00 to $9FFF):

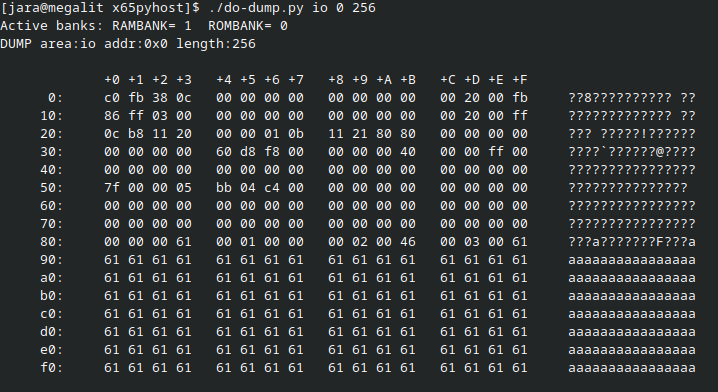
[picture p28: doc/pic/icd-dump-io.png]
ICD Dump of IO area


ICD Block Diagram

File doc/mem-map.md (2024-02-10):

Memory Map
===========

This document describes the memory map of the X65 computer.

Introduction
-------------

To follow the 6502 aesthetics, we write here addresses in hexadecimal numbers with the leading character '$'.
For example, $1234 is the hexadecimal address 0x1234. If the underscore '_' character is used, it hase no functional meaning 
and serves just to visually divide long hex string into human-readable chunks. For example, $123456 could be written also $12_3456.

The X65 computer supports two slightly different processors: 65C02 and 65C816. Default is 65C816.
Following the CPU type, the CPU address space is either 64kB (16-bit) long in case of 65C02 CPU, 
or 16MB (24-bit) long in case of 65C816 CPU.

The 16-bit addresses are specified with four hex-digits, and the 24-bit addresses with 6 hex digits.
When we specify a 16-bit address, e.g. $1234, in the context of the 65C816 this gets extended on the left by 00, 
i.e. it is just identical to $001234 (= $00_1234).

Memory Quantities
------------------

The official 65C02 and 65C816 documentation defines the following multi-byte quantities:

* **PAGE** = 256 Bytes (typically alligned).
* **BANK** = 64 kB (alligned).

The 8-bit 65C02 processor has the special **PAGE ZERO** from $0000 to $00FF and **PAGE ONE** from $0100 to $01FF, for stack. 
It has exactly one 64kB **BANK** from $0000 to $FFFF, which is its entire address space.

The 16-bit 65C816 processor is more complex. It has a **DIRECT PAGE**, which by default is the same as the ZERO PAGE in 65C02, 
but software can relocate it anywhere in the first **BANK** (64kB) of the address space (even to an unaligned address).

Then the 16-bit processor has 256 BANKs of 64kB each. The BANK address is simply the highest-order 8 bits of the 24-bit address.
The lower 16 address bits specify offset within a BANK, which can be up to 64kB.
Since 256 * 64kB = 16MB, this defines the entire CPU 65C816 address space.

Relation to Commander X16 "banks"
---------------------------------

Quite unfortunately, in the Commander X16 (CX16) parlance, the english word "bank" is used in the RAMBANK and ROMBANK mechanism 
that provides 8kB and 16kB-based multiplexing of "high memory" (above 64kB boundary) into the base 64k memory of 65C02. 
This use of the word "bank" clashes with the official BANK (64kB quntity) from the 65C816 CPU documentation.

In X65 computer the identical memory multiplexing mechanism is called RAMBLOCK and ROMBLOCK, 
to distinguish it from the BANK registers of the 65C816 processor.
Functionally our RAMBLOCK and ROMBLOCK registers are compatible with CX16's RAMBANK and ROMBANK.

CPU Address Space View
------------------------

The picture below shows the CPU address map view.
The entire physical space is 2MB and it is mostly direct-mapped to the 2MB SRAM.
The bottom 64kB (BANK 00) of CPU has a special layout comprising of IOREGS, RAM-Block frame and ROM-Block frame.

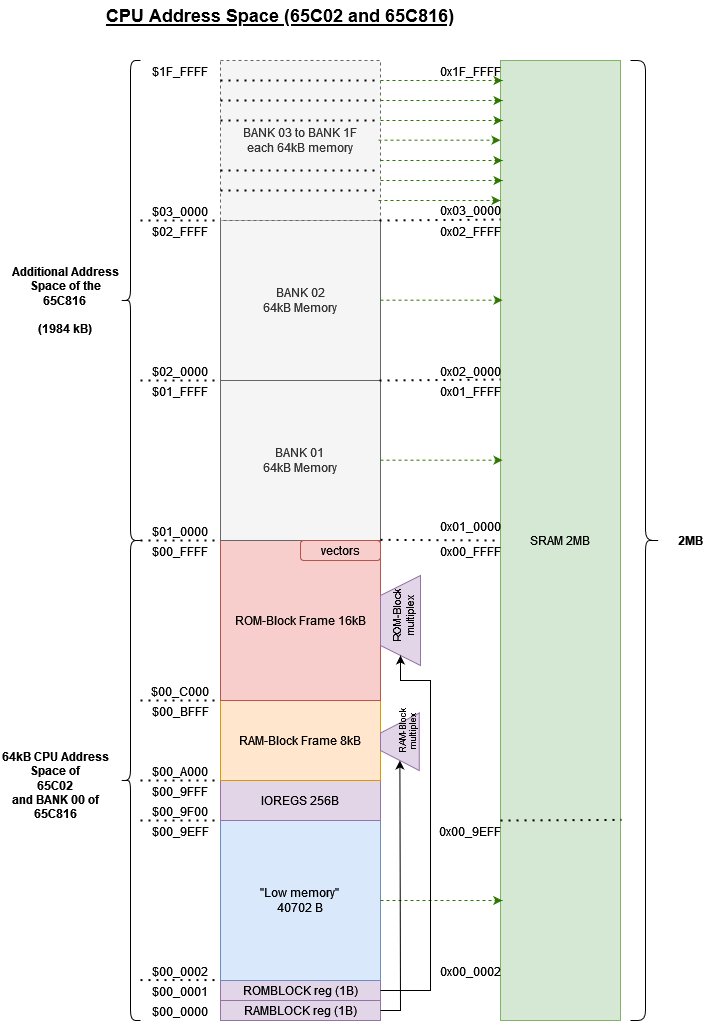
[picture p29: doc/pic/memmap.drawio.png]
CPU Memory Map


SRAM 2MB
---------

The SRAM is 2MB or 2048kB long (physical address is 21-bits wide).
Since X65 has no traditional parallel ROM devices, all "ROM" code is just loaded in RAM and made accessible as such.
(In case of legacy CX16 runtime mode, the CX16 system 'sees' just 1MB of RAM through the RAM-Block mechanism
because the other 1MB is used to store the ROM blocks and the low memory.)

In case of the 16-bit processor 65C816 the 2MB SRAM is directly accessible starting from the bottom of the CPU address space at the address $00_0000.
The 2048kB of SRAM is (2048/64) = 32 BANKs, therefore the (64kB) BANKs 0 to 31 directly map to the SRAM.
In other words the 65C816 CPU sees the RAM from $00_0000 to $1F_FFFF. Banks 32-255 are not defined.
The first bank, BANK 0, has a special mapping as shown above.

In case of the 8-bit processor 65C02, which can directly address just the BANK 0 (64kB), the first cca 40kB of the SRAM are mapped to the CPU address space ($0000 to $9EFF).
The other cca 24kB of the 65C02 address space is used by I/O space and by the RAM and ROM BLOCK frame - see below.
With the RAM and ROM BLOCK mechanism the 65C02 can indirectly access the whole 2MB of the SRAM, but at the cost of added SW complexity.

RAM/ROM-Block multiplexing registers - RAMBLOCK and ROMBLOCK
---------------------------------------------------------------------

To gain access to the whole 2MB of SRAM from 65C02, which is limited to BANK 0 (64kB), the system employs 
a memory multiplexing mechanism called RAMBLOCK and ROMBLOCK.
(Note: the mechanism described here works exactly the same in the 65C816 processor as well.)
The 8kB area of CPU address space from $A000 to $BFFF (in CPU BANK 0) is called a RAMBLOCK Frame.
And the 16kB area of CPU address space from $C000 to $FFFF (in CPU BANK 0) is called a ROMBLOCK Frame.
For these Frames there are two corresponding 8-bit register called RAMBLOCK and ROMBLOCK that multiplex SRAM blocks in the frames.
The register RAMBLOCK is at the address $0000 (in BANK 0) and ROMBLOCK is at the address $0001 (in BANK 0).
The registers are described in detail in [I/O Registers](ioregs.md).

__Mapping of RAMBLOCKs to SRAM__

The 2MB SRAM has exactly (2048kB / 8kB) = 256 of 8kB RAM-Blocks. With the RAMBLOCK-Frame multiplexing any byte of the SRAM is potentially reachable through the frame.
Mapping of a RAM-Block number 0 - 255 to SRAM is straight-forward albeit with a small detail: 
the top bit (bit 7) of RAMBLOCK register is inverted and then the result is taken as SRAM memory address bits 21:14. 
Therefore, RAMBLOCKs 0 to 127 are mapped to the SRAM area between 1MB and 2MB (from $10_0000 to $1F_0000),
and RAMBLOCKs 128 to 256 are mapped to SRAM area between 0 and 1MB (from $00_0000 to $0F_FFFF).
The reason for this twisted mapping is software compatibility. 
Legacy SW, such as CX16 ROMs, will use RAMBLOCKs starting from 0 up to some number, and we don't want
to have these mapped at the beginning of SRAM where the important low-memory (BANK 0) is located.

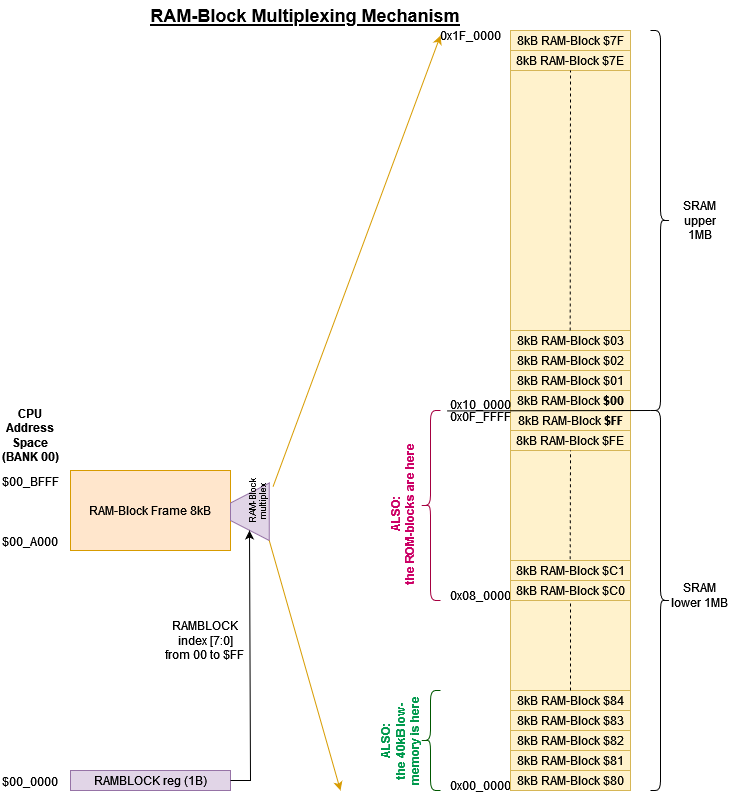
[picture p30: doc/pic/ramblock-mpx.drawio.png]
ROM-Block Multiplexing Mechanism


__Mapping of ROMBLOCKs to SRAM__

There are 32 ROM-Blocks, each 16kB, for a combined capacity (32 * 16kB) = 512kB.
ROM-Blocks are mapped in the SRAM in the area between 512kB and 1MB.
ROM-Block 0 maps to SRAM address from $08_0000 to $08_3FFF, followed by ROM-Block 1 from $08_4000 to $08_7FFF, and so on.
Tha last ROM-Block 31 is in SRAM address from $0F_C000 to $0F_FFFF, which is the middle of SRAM.

Note that the SRAM area from $08_0000 to $0F_FFFF used by ROM-Blocks is also accessible via the RAM-Block mechanism.
ROM-Block 0 is the same as RAM-Block 192 and 193 (remember ROM-Blocks are 16kB but RAM-Blocks 8kB, so we need two),
ROM-Block 1 is at RAM-Block 194 and 195, and so on, until ROM-Block 31 is at RAM-Block 254 and 255.

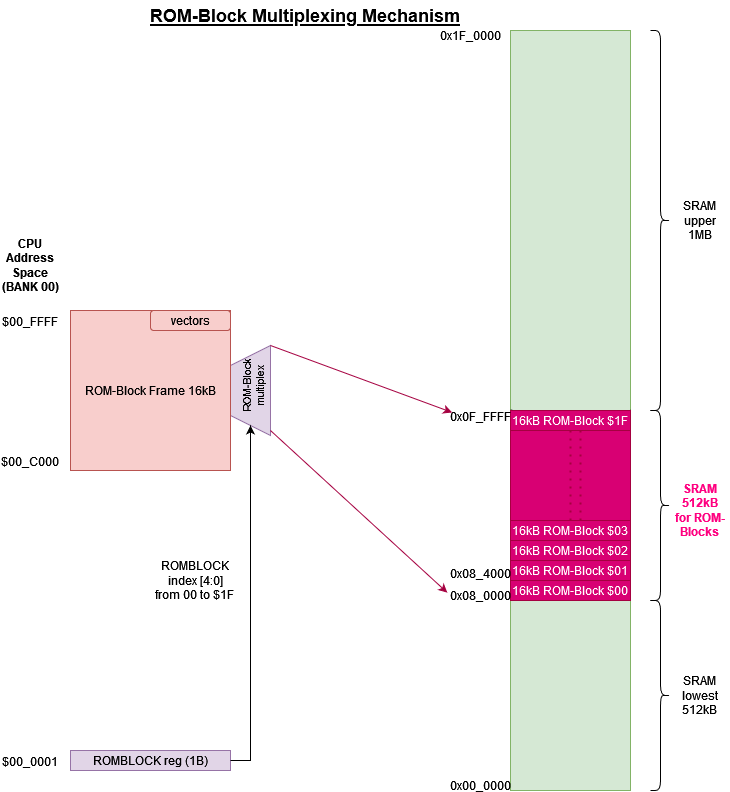
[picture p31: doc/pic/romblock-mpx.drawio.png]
ROM-Block Multiplexing Mechanism


I/O device space: 256 Bytes from $9F00 to $9FFF
------------------------------------------------

The 256 Byte long I/O device space is mapped in CPU address space from $9F00 to $9FFF in CPU BANK 0.
Find more details in [ioregs.md](ioregs.md).

PBL (Primary Bootloader) ROM: 512 Bytes
------------------------------------------

PBL ROM gets activated when register ROMBLOCK bit 7 is 1.
Then it is dislayed in the ROM-Block Frame starting at $00_C000. 
The 512B PBL ROM is mirrored over the entire 16kB ROM-Block frame.

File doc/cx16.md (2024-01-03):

Commander X16 - Architecture Analysis
======================================

Useful links regarding the CX16:

* Wiki: https://www.c64-wiki.com/wiki/Commander_X16
* Sources: https://github.com/X16Community
* https://www.reddit.com/r/CommanderX16/
* Tips for CX16 commands: https://voidstar.blog/voidstars-commander-x16-notes/

Memory Map (CPU view):
----------------------

    Address Range 	Size 	Description
    0x0000-0x0001 	2 bytes 	RAM, ROM bank control bytes
        
        Address 	Description
        $0000 	Current RAM bank (0-255)
        $0001 	Current ROM bank (0-31)

                    SRAM fixed low-mem:
    0x0002-0x0021 	32 bytes 	16 bit ABI registers r0-r15 for KERNAL API
    0x0022-0x007F 	94 bytes 	User zero page
    0x0080-0x00FF 	128 bytes 	KERNAL and BASIC zero page variables
    0x0100-0x01FF 	256 bytes 	Accumulator stack
    0x0200-0x03FF 	512 bytes 	KERNAL and BASIC variables, vectors
    0x0400-0x07FF 	1024 bytes 	User space

    0x0800-0x9EFF 	38,656 bytes 	BASIC program/variable RAM

                    I/O Area
    0x9F00-0x9FFF 	256 bytes 	I/O registers

        This is the memory map of the I/O Area:
        Addresses 	Description
        9F00−9F0F 	VIA I/O controller #1
                    GPIO mapping:
                    Port A:
                        PA0 => I2C_SDA
                        PA1 => I2C_SCL
                        PA2 => NESLATCH
                        PA3 => NESCLOCK
                        PA4 => (NESDATA3)
                        PA5 => (NESDATA2)
                        PA6 => NESDATA1
                        PA7 => NESDATA0
                    Port B:
                        PB0 => unused
                        PB1 => unused
                        PB2 => unused
                        PB4..PB7 => IEEE bus

        9F10−9F1F 	VIA I/O controller #2 (optional - not fitted)
        9F20−9F3F 	VERA video controller
                    https://github.com/X16Community/vera-module
        9F40−9F41 	YM2151 audio controller
        9F42−9F4F 	Reserved
        9F50−9F5F 	Reserved
        9F60−9FFF 	External devices

                    SRAM banked:
    0xA000-0xBFFF 	8192 bytes* 	RAM Bank window (512K total, expandable to 2MB)

        This is the allocation of banked RAM in the KERNAL/BASIC environment.
        Bank 	Description
        0 	Used for KERNAL/CBDOS variables and buffers
        1-255 	Available to the user

        (On systems with only 512 KB RAM, banks 64-255 are unavailable.)

        During startup, the KERNAL activates RAM bank 1 as the default for the user.

                    ROM banked:
    0xC000-0xFFFF 	16,384 bytes* 	ROM Bank window (512K total)

        This is the allocation of the banks of banked ROM:
        Bank 	Name 	Description
        0 	KERNAL 	KERNAL operating system and drivers
        1 	KEYBD 	Keyboard layout tables
        2 	CBDOS 	The computer-based CBM-DOS for FAT32 SD cards
        3 	GEOS 	GEOS KERNAL
        4 	BASIC 	BASIC interpreter
        5 	MONITOR 	Machine Language Monitor
        6 	CHARSET 	PETSCII and ISO character sets (uploaded into VRAM)
        7 	CODEX 	CodeX16 Interactive Assembly Environment / Monitor
        8 	GRAPH 	Kernal graph and font routines
        9 	DEMO 	Demo routines
        10 	AUDIO 	Audio routines
        11-31 	– 	[Currently unused]

GPIO Map (VIA I/O Controllers)
-------------------------------

VIA I/O Controller #1 (9F00−9F0F):

    Pin     Direction       Description
    PA0     Bidi            I2C SDA
    PA1     Bidi            I2C SCL
    PA2     Out             NES Common Latch
    PA3     Out             NES Common Clock
    PA4     In              NES 3 Data
    PA5     In              NES 2 Data
    PA6     In              NES 1 Data
    PA7     In              NES 0 Data

    PB0-7                   TBD

VIA I/O Controller #2 (9F10−9F1F):

    All pins unused.

I2C Map
----------

I2C bus is bit-banged by the CPU on VIA #1 GPIO ports PA0 (SDA) and PA1 (SCL).

There are two slave devices on the bus:
* SMC (System Management Controller) on the 7-bit (unshifted) I2C address 0x42
* Real-Time Clock (RTC) chip MCP7940N on the 7-bit (unshifted) I2C address 0x6F

SMC I2C Slave registers:

        Register 	Value 	Description
        $01 	    $00 	Power off
        $01 	    $01 	Hard reboot
        $02 	    $00 	Inject RESET
        $03 	    $00 	Inject NMI
        $04 	    00..FF 	Power LED brightness
        $05 	    00..FF 	Activity LED brightness
        $08                 debug: set echo_byte // read echo_byte
        $09                 debug: print echo_byte

        $07 	    - 	    Read from keyboard buffer (.ino:264)
        $18 	    - 	    Read ps2 status  //Get keyboard command status (.ino:278: ret Keyboard.getCommandStatus() 
                                            -> PS2_CMD_STATUS: IDLE = 0,  CMD_PENDING = 1,   CMD_ACK = 0xFA,  CMD_ERR = 0xFE)
        $19 	00..FF 	    Send ps2 command: //Send command to keyboard (one byte) (.ino:251)
        $1A                 //Send command to keyboard (two bytes) (.ino:255) ** not documented!
        
        $21 	    - 	    Read from mouse buffer: //Get mouse packet (.ino:281) -- ret 3B or 0

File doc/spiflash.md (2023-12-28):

SPI Flash Memories
====================

TBD: Describe here which SPI Flash memories we have, how they are connected and used.

NORA ROM
W25Q128JVS          8p-SOIC-208mil
(16MB)

AURA, VERA ROM
W25Q16JVSNIQ        8p-SOIC-150mil
(2MB)

--> change to??
W25Q16JVSSIQ        8p-SOIC-208mil??

--> a) make all footprints compatible with both 150mil and 208mil packages???
--> b) for NORA, provide overlapping footprints for 8p-SOIC-150mil (208mil??) and 16p-SOIC-300mil

W25Q512JVFIQ        16p-SOIC-300mil (10.3mm x 7.5mm)
(64MB)

IS25WP256D-xM
(32MB)

SOIC-16
up to 1Gb devices available from Infineon

also SOP2-16
up to 1Gb devices available from Micron

PSRAM:
IS66WVS4M8BLL-104NLI-TR

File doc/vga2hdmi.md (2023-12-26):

VGA to HDMI
=============

Tested:
Vention VGA to HDMI Converter
https://ventiontech.com/products/hdmi-to-vga-converter

Available from:
https://www.amazon.com/Monitor-Connector-VENTION-Adapter-Computer/dp/B08GZ159FJ?th=1    
https://www.alza.cz/vention-vga-to-hdmi-converter-with-female-micro-usb-and-audio-port-0-15m-black-d5827559.htm

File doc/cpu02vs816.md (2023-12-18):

Differences between the 65C02 and 65C816 Processors in 8-bit Mode
====================================================================

In X65 the assembled CPU is either the 8-bit W65C02S or 16-bit W65C816S. 
The W65C816S is (partially) compatible with W65C02S. 
This page summarizes the differences from the low-level hardware point of view and in the case that the 65C816
is running in the 8-bit *Emulation Mode*.

These two photos shows the processors assembled on X65 main board:

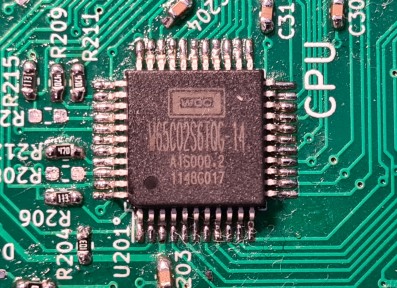
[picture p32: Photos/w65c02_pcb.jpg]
W65C02 on PCB

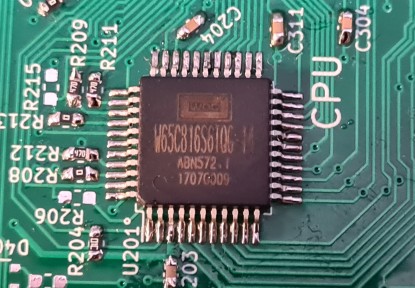
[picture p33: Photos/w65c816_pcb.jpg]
W65C816 on PCB


Processor Pinout Comparison
----------------------------

Both processors are available in the same QFP-44 package, so they could be assembled alternatively on the same PCB.

The drawing below shows processor pin functions side by side.
I marked pins with differing function in red colour:

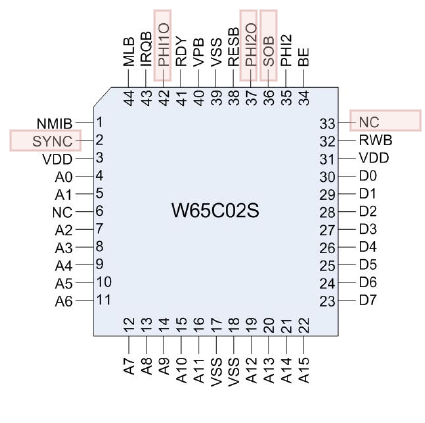
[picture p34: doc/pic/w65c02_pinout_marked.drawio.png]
W65C02 pinout

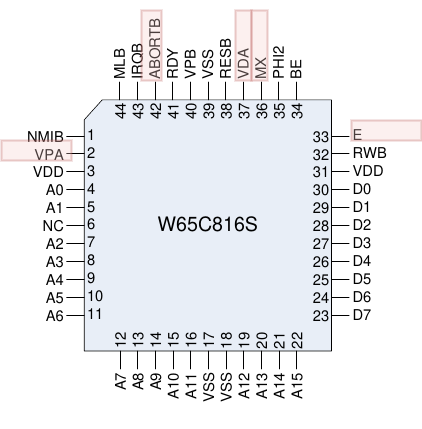
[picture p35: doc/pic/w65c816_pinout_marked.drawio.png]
W65C816 pinout


The following table compares those pins.
In case of 65C02, most of these pins (except of SYNC) can be just ignored since their function is not important.
In case of 65C816 the pins provide additional status information from the processor (E, MX, VPA, VDA),
or new features (ABORTB).

| Pin | 65C02 | 65C816 | Difference |
|-----|---|---|---|
| 2 | SYNC | VPA | See below. |
| 33  | NC (no connect)  | E | 816: Status of the E-flag (emulation mode). |
| 36  | SOB (Set Overf.) | MX | 02: Ignore (pull-up). 816: Status of M and X flags. |
| 37  | PHI2O | VDA | 02: Ignore. 816: see below. |
| 42  | PHI1O | ABORTB | 02: Ignore. 816: Instruction abort input (MMU support). |

The SYNC pin in 65C02 provides an important feature for instruction tracing: it goes high when 
the first instruction byte is being fetched by the CPU. By observing SYNC it is possible to single-step
the CPU or reconstruct the instruction stream.

In case of 65C816, instead of SYNC two other signals are provided: VPA (Valid Program Address)
and VDA (Valid Data Address). All four combinations of VPA and VDA provide useful processor status:

| VDA | VPA | State (65C816) |
|-----|-----|---|
| 0 | 0 | Internal Operation Address and Data Bus available. The Address Bus may be invalid. |
| 0 | 1 | Valid program address-may be used for program cache control. |
| 1 | 0 | Valid data address-may be used for data cache control. |
| 1 | 1 | Opcode fetch-may be used for program cache control and single step control. == SYNC in 65C02 !! |

The SYNC signal of 65C02 is equivalent to (VPA==1 && VDA==1) in 65C816.

Bus Signal Timing Comparison
-----------------------------

Below I put the bus timing pictures of 65C02 and 65C816 next to each other.
I colour-marked the differences between the processors: 
* **green** marks the identical timing of read and write data: they are valid at the falling edge of PHI2.
* **red** marks the new feature of Bank Address, which is available on Data Bus at the rising edge of PHI2.
    This was not present in 65C02.
* **yellow** marks new signals in 65C816, not available previously.

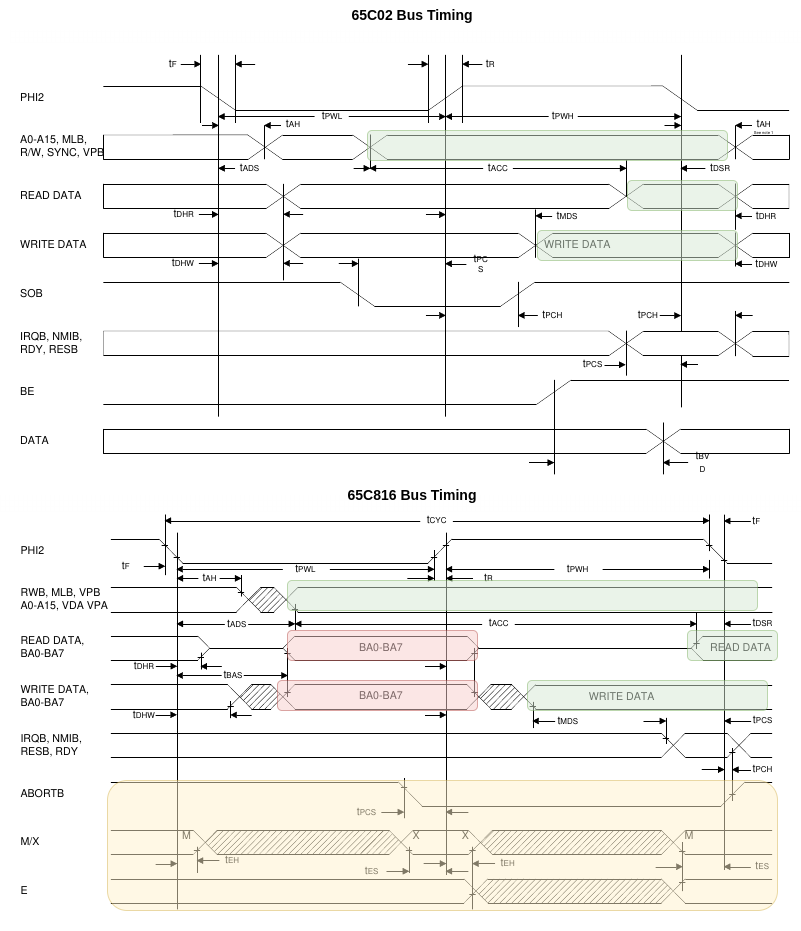
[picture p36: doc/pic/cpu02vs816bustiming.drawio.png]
CPU Bus Timing Comparison


Observations:

* Data Bus is always actively driven by 65C816 in the first half-cycle (PHI2 low) to provide the Bank Address to the outside world,
    even if the current cycle is a Read (RWB=1). Therefore, external circuits must never drive the Data Bus
    when PHI2=low. The RWB applies just to the second phase (PHI2=high).
* New signals VPA and VDA indicate a valid address. In case both are zero, then the memory address provided by the CPU is potentially
    invalid ==> the external circuit must not decode & respond to that address.

Instruction Cycle Timing Comparison
-------------------------------------

Looking at cycle-by-cycle traces of one example instruction 'ROL $a823' we can spot some minor differences.
This instruction is supposed to read a value at memory address $a823, rotate left by 1 bit, and write the result
back to the same memory location.

**65C02:**

    Step #   1:  MAH:c0 (ROMB:  0)  CA:d54a  CD:2e  ctr: b:-I--  sta:3f:r--EPDS     ROL $a823
    Step #   2:  MAH:c0 (ROMB:  0)  CA:d54b  CD:23  ctr: b:-I--  sta:1f:r--E-D-     
    Step #   3:  MAH:c0 (ROMB:  0)  CA:d54c  CD:a8  ctr: b:-I--  sta:1f:r--E-D-     
    Step #   4:  MAH: 0 (RAMB:  0)  CA:a823  CD:ff  ctr: b:-I--  sta:1f:r--E-D-     
    Step #   5:  MAH: 0 (RAMB:  0)  CA:a823  CD:ff  ctr: b:-I--  sta: f:r-LE-D-     
    Step #   6:  MAH: 0 (RAMB:  0)  CA:a823  CD:ff  ctr: b:-I--  sta: e:W-LE-D-     

**65C816:** (in Emulation Mode)

    Step #   1:  MAH:c0 (ROMB:  0)  CA:d54a  CD:2e  ctr: b:-I--  sta:3f:r--EPDS     ROL $a823
    Step #   2:  MAH:c0 (ROMB:  0)  CA:d54b  CD:23  ctr: b:-I--  sta:3b:r--EP--     
    Step #   3:  MAH:c0 (ROMB:  0)  CA:d54c  CD:a8  ctr: b:-I--  sta:3b:r--EP--     
    Step #   4:  MAH: 0 (RAMB:  0)  CA:a823  CD:ff  ctr: b:-I--  sta: f:r-LE-D-     
    Step #   5:  MAH: 0 (RAMB:  0)  CA:a823  CD:ff  ctr: b:-I--  sta: a:W-LE---     
    Step #   6:  MAH: 0 (RAMB:  0)  CA:a823  CD:ff  ctr: b:-I--  sta: e:W-LE-D-     

First, what is identical:
* Cycle count = 6
* Addresses seen on the address bus (field CA) are identical.
* The first 3 steps are reading the instruction bytes. We can see the bytes "2e 23 a8" on the data bus (field CD).
    - The 65C02 generates the SYNC flag just on the first op-code byte. (The D flag in field 'sta' is fixed to 1 in NORA for 65C02 processors, 
        so it is *always* set in the traces and therefore meaningless.)
    - The 65C816 does not have a dedicated SYNC pin, but it sets the P and D flags (these are the VPA and VDA signals)
        on the op-code fetch (Step 1), and then just the P flag on the operand value fetches (Steps 2 and 3).
        This is as expected and the P flags provides a potentially valuable information to NORA that these are instruction fetches.

Then there are differences:
* In Step 4 both processors read the value at memory address $a823. It happens to be $ff.
    - 65C02 reads the value *without a lock*.
    - 65C816 reads the value *with lock* signal set (flag L). I would expect this behaviour.
* In Step 5, the behaviour differs quite a lot:
    - 65C02 reads (flag 'r') the value at $a823 again, but this time *with* lock flag set (L).
    - 65C816 already *writes* to memory (flag 'w'), but it **does not** set any of P or D flags (VPA, VDA) => the memory address on CA
        is potentially invalid and this write should be ignored in the memory! 
* In Step 6, both processors behave the same - the result value is written to the memory with lock flag (L) set
    and the D flag (VDA; 65C816 only) set.

Instruction Set Comparison
----------------------------

So far the differences mentioned are quite minor.
However, regarding the Instruction Set Architecture (ISA), 32 instructions are different between the processors.
The following two tables, copied from datasheets of the processors, highlight them.
They are in the column 7 and F, i.e. the problematic instructions have the op-code x7 and xF, where x is 0..F.

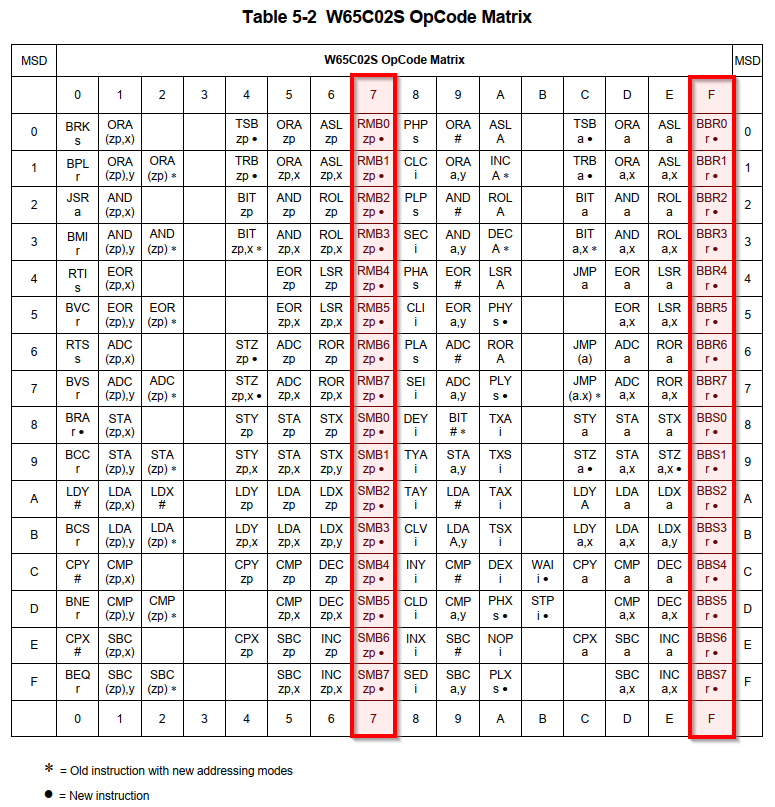
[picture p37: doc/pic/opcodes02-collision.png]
Opcodes 65C02

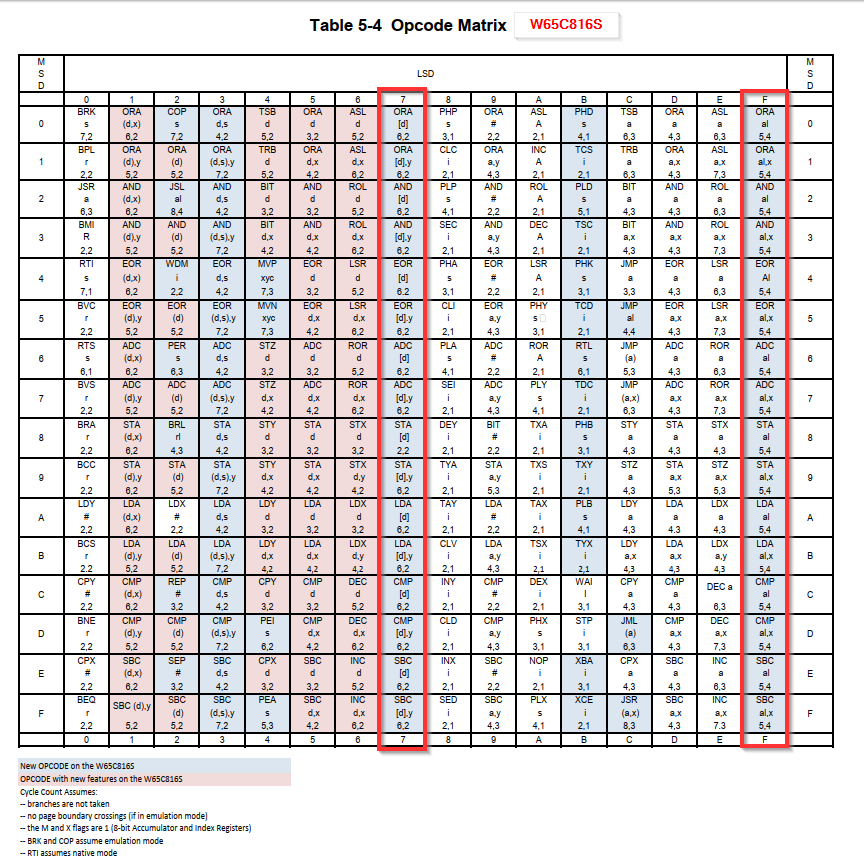
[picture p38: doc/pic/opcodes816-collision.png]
Opcodes 65C816


The problematic instructions (from the 65C816 point of view) are the following 65C02 instructions:
* RMB0..RMB7 = Reset Memory Bit
* SMB0..SMB7 = Set Memory Bit
* BBR0..BBR7 = Branch on Bit Set
* BBS0..BBS7 = Branch on Bit Reset

If 65C816 (in the Emulation Mode) should run a program originally written for 65C02, these instructions must be replaced
with an alternative code.

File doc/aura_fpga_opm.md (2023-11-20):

AURA FPGA: The replacement of YM2151 and YM3012
===============================================

Sound in Commander X16
-----------------------

Sound in Commander X16 is generated by two sources that are mixed together:

  1) by the Programmable Sound Generator (PSG) in VERA FPGA, and
  2) by the MIDI FM-synthesis chip YM2151. 

The following picture is a block diagram of the sound subsystem in C'X16:

Block Diagram of Sound Generator in C'X16

The PSG in VERA FPGA is a stereo sound generator loosely based on SID. It supports 16 channels (voices) and PCM playback.
There is no ADSR or filters. This must be provided by software.
The PSG is an integral part of VERA FPGA user logic that also generates the VGA video output.

MIDI-like sound synthesis is provided by YM2151. Yamaha called it an FM operator Type-M (OPM).
The chip outputs sound digitally as a 10-bit mantissa / 3-bit exponent samples, two channels (left and right),
at the audio sample frequency of about 55 kHz. This digital sound stream is converted to an analog signal 
using special a D/A converter YM3012, also developed by Yamaha.
The picture below illustrates the basic circuit, as taken from the datasheet:

Example of Basic Circuit ym2151+ym3012

YM2151 was created by Yamaha in 1980's, being used by Atari and Sega arcade systems starting in 1984.
As of 2023, this chip is perhaps a quarter of century out of production.
The chip interfaces with then-standard 5V TTL logic, and the D/A converter YM3012 even requires +/- 12V rails for its analog output.

Principle of FM Sound Synthesis
-------------------------------

https://www.perfectcircuit.com/signal/what-is-fm-synthesis

Sound in x65
------------

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

I call the FPGA device implementing the compatible FM-synthesis "AURA", from AUdio Retro Adapter.
It is Lattice ice40up5k-sg48 FPGA, the same type used for VERA, so the x65 has twice the same FPGA on the board - for audio and for video.
The emulation main part is done by IKAOPM project, which is a verilog synthesisable replica of the YM2151.

The picture below shows the sound subsystem of x65:

x65 Sound Subsystem

AURA outputs the sound in the stereo 16-bit I2S format, which is converted to the analog signal by the WM8524 D/A converter.
The PSG sound from VERA is also in the same I2S format. AURA has an auxiliary I2S input for the PSG sound; mixing of both sound sources
is done digitally in AURA.

Implementation on the x65 Board
-------------------------------

The photo bellow shows the x65 audio/video board with the VERA and AURA FPGAs labelled. The DAC chip and the audio and video output connectors
are also visible and marked.

Photo of x65 PCB with VERA, AURA and DAC chips labelled

Cost Comparison
---------------

Since both Yamaha chips are long out of production, it is not possible to buy them from normal distributors of electronic parts 
like Mouser, Farnell, Digikey etc. The parts are typically to be had on ebay from various sellers, in various quantities and prices.
Ideally one gets an old new stock part, or in a bad case a sub-par clone.
A brief ebay listings overview shows that the D/A YM3012 costs around 1 EUR/1pc, and the FM-synth YM2151 around 9 EUR/1pc. 
So the total cost with original new-old Yamaha parts could be 10 EUR, plus the analog sound mixer.

The ice40up5k-sg48 FPGA costs around 9.30 EUR/1pc, or 7.8 EUR in 100-piece quantity. To this we should add the cost of one SPI-Flash
memory necessary to store the FPGA bitstream; I use W25Q16JVSNIQ which costs 0.45 EUR/1pc. 
I do not add the cost of the D/A converter WM8524 since it is also present in the C'X16 solution for the VERA PSG output conversion.
Therefore, the total cost using AURA FPGA is also around 10 EUR in 1pc quantity (or better, if bought in quantity).

Demo
----

[Calliope](https://github.com/ZeroByteOrg/calliope) is a player / jukebox application for Commander X16.
It can play files in the ZSM format. It supports output through the VERA PSG and YM2151 FM-synth.
This is a photo od Calliope running on X65 hardware, playing a sound file through the AURA:

Calliope on X65

Conclusion
----------

In conclusion, the solution with AURA FPGA has the following advantages:

* good availbility of modern parts, 
* same or better cost, 
* direct interfacing with the 3.3V LVTTL logic of the x65 design, 
* not requiring +/- 12V for the DAC, 
* and the smaller total footpring size on the PCB because of modern component packages.

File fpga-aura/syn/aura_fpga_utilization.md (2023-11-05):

AURA FPGA Device Utilization
============================

Device: Lattice iCE40UP5K-SG48

Info: Device utilisation:
Info:            ICESTORM_LC:  4765/ 5280    90%
Info:           ICESTORM_RAM:    10/   30    33%
Info:                  SB_IO:    30/   96    31%
Info:                  SB_GB:     8/    8   100%

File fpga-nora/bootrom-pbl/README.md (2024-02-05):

Primary Bootloader
===================

This directory provides the sources of the Primary Bootloader (PBL).
Compiled code is stored in 512Byte BlockRAM inside of NORA FPGA. It gets there as part of verilog synthesis.
This special BlockRAM is mapped to CPU address space at $FE00 by configuring the register ROMBLOCK bit 7 = 1 (i.e. 0x80).
That is the default after a system reset, so that PBL starts automatically.

Note: Vector Pull (RESET, IRQ, NMI, ...) always happens from ROMBLOCK = 0, *unless* ROMBLOCK[7] = 1 is configured; 
then it happens from the PBL ROMBLOCK.

The PBL must be short (less than 512B) to fit in the FPGA.
It initializes NORA's SPI-Flash and reads the SBL starting at offset 256kB. 
(NORA bitstream takes the first cca 132kB, and flash erase is done in 64kB increments.)
Presently we load 256kB of secondary ROM.

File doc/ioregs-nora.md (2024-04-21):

NORA Registers
===============

Two special registers at the beginning of the CPU zero page ARE ONLY AVAILABLE IF THE BIT [5] MIRROR_ZP IN RMBCTRL REG. IS SET.
Otherwise, normal memory is displayed.

    Address         Reg.name            Bits        Description
    $0000           RAMBLOCK            [7:0]       MIRROR OF THE REGISTER RamBLOCK_AB at $9F50.
                                                    This 8-bit register specifies which 8kB-BLOCK of the 2MB SRAM
                                                    is mapped into the 8kB RAM-BLOCK FRAME visible at the CPU address $A000 to $BFFF.
                                                    See description of RamBLOCK_AB below.
    
    $0001           ROMBLOCK                        MIRROR OF THE REGISTER ROMBLOCK at $9F51.
                                        [4:0]       This 5-bit register specifies which 16kB-BLOCK from the SRAM's 
                                                    512kB area 0x08_0000 to 0x0F_FFFF is mapped into the 16kB ROM-BLOCK FRAME
                                                    visible at the CPU address $C000 to $FFFF.
                                                    See description of ROMBLOCK below.

NORA's main register block starts at $00_9F50 (65816 address), that is $9F50 in 6502.
The first two registers support *RAM-Block mapping* (at $A000) and *system reset* functions:

    Address         Reg.name            Bits        Description
    $9F50           RamBLOCK_AB         [7:0]       This 8-bit register specifies which 8kB-BLOCK of the 2MB SRAM
                                                    is mapped into the 8kB RAM-BLOCK FRAME visible at the CPU address $A000 to $BFFF. The contents 
                                                    of this 8b register is bit-wise ANDed with the register RAMBMASK (at $9F52) and the result 
                                                    is the SRAM RAM-block number.
                                                    (As described in memory-map, the 2MB SRAM has 256 of 8kB BLOCKs).
                                                    These RAM-Blocks are numbered in the 2MB SRAM starting in the MIDDLE and wrapping around: 
                                                        RAM-Block #0   is from SRAM 0x10_0000 to 0x10_1FFF,
                                                        RAM-Block #1   is from SRAM 0x10_2000 to 0x10_3FFF, etc.,
                                                        RAM-Block #127 is from SRAM 0x1F_E000 to 0x1F_FFFF,
                                                        RAM-Block #128 is from SRAM 0x00_0000 to 0x00_1FFF,
                                                        RAM-Block #129 is from SRAM 0x00_2000 to 0x00_2FFF, etc.,
                                                        RAM-Block #255 is from SRAM 0x0F_E000 to 0x0F_FFFF.
                                                    Note 1: in CX16 parlance this register is called "RAMBANK", but the function is (basically) the same.
                                                    Note 2: RAM-Blocks 128 to 132 are always mapped to the CPU "low-memory" addresses from $0000 to $9EFF. 
                                                    (65816: from $00_0000 to $00_9EFF => in Bank 0.)
                                                    RAM-Blocks 192 to 255 are also available as ROM-Blocks, see below.
    
    $9F51           RamBLOCK_CD                     [SHARED ADDRESS WITH ROMBLOCK reg (SEE BELOW). Must be enabled in bit [3] ENABLE_RA_CD of RMBCTRL]
                                                    This 8-bit register specifies which 8kB-BLOCK of the 2MB SRAM
                                                    is mapped into the 8kB RAM-BLOCK FRAME visible at the CPU address $C000 to $DFFF. 
                                                    The contents  of this 8b register is bit-wise ANDed with the register RAMBMASK (at $9F52) 
                                                    and the result is the SRAM RAM-block number. The mapping to SRAM is the same as for the $A000 area
                                                    -> see RamBLOCK_AB description above.
                                                    Bit [3] ENABLE_RA_CD of RMBCTRL must be set to 1 to enable this register.

    $9F51           ROMBLOCK                        [SHARED ADDRESS WITH RamBLOCK_CD reg (SEE ABOVE). Must be enabled in bit [4] ENABLE_RO_CDEF of RMBCTRL]
                                        
                                        [7:5]   reserved, write 0
                                        
                                        [4:0]   This 5-bit register specifies which 16kB-BLOCK from the SRAM's 
                                                512kB area 0x08_0000 to 0x0F_FFFF is mapped into the 16kB ROM-BLOCK FRAME
                                                visible at the CPU address $C000 to $FFFF.
                                                There are 32 x 16kB ROM-Blocks in SRAM:
                                                    ROM-Block #0  is from SRAM 0x08_0000 to 0x08_3FFF (= also known as the 8kB RAM-Blocks #192 and #193),
                                                    ROM-Block #1  is from SRAM 0x08_4000 to 0x08_7FFF (= also known as the 8kB RAM-Blocks #194 and #195), etc.,
                                                    ROM-Block #31 is from SRAM 0x0F_C000 to 0x0F_FFFF (= also known as the 8kB RAM-Blocks #254 and #255).
                                                The ROMBLOCK register allows addressing up to 64 ROM-Blocks, but only the first 32 are available in the SRAM.

    $9F52           RamBMASK            [7:0]       Mask register for RamBLOCK_AB and RamBLOCK_CD effective address calculation. 
                                                    The effective RAM-Block number is = RAMBLOCK & RAMBMASK.
                                                    For CX16 ROMs this register should be set to 0x7F to limit the RAMBLOCK addressing to 1MB.
                                                    Otherwise, RAM-Blocks 128-132, mapped to CPU "low-memory", get overwriten by the OS.
                                                    For software aware of X65 memory map this register could be set to 0xFF to allow full SRAM access even 
                                                    from 8-bit (6502) code.
                                                    (For 16-bit code (65816) using 24-bit native linear addressing the RAMBMASK is irrelevant.)
    
    $9F53           RMBCTRL                         Controls the Ram/ROM Block region mapping between $A000 to $FFFF and the function of register $9F51.

                                        [7] bit MAP_BOOTROM:
                                                When set to 1, NORA's BootRom is displayed in the ROM-Block Frame from $D000 to $FFFF, and any ROMBLOCK setting is ignored.
                                                When cleared to 0, the ROMBLOCK, if enabled in bit 4, define the contents of ROM-Block Frame.
                                                BootRom is 512B and mirrored over the 8kB frame.

                                        [6] bit AUTO_UNMAP_BOOTROM:
                                                When set to 1 together with bit [7], then the next RTI instruction (Return From Interrupt)
                                                will automatically clear bits [7] and [6], thus taking the BootRom out of the ROM-Block Frame.
                                                NMI is automatically blocked while bit [6] is set, and all other interrupts should be blocked in Sw.
                                                This is used by special handlers like ISAFIX.

                                        [5] bit MIRROR_ZP:
                                                When set to 1 the registers $9F50 and $9F51 are _also_ displayed in the zero page at the absolute 
                                                addresses $00_0000 and $00_0001. This is useful for 6502 code that needs to access these registers often
                                                and it is necessary for compatibility with CX16 code (= their "RAMBANK" and "ROMBANK" registers).
                                                When cleared to 0, the registers are not mirrored to the zero page.
                                                For 65816 systems in Native 16-bit mode, it is recommended _not_ to mirror these registers to the zero page,
                                                i.e. clear this bit to 0.
                                        
                                        [4] bit ENABLE_ROM_CDEF:
                                                When set to 1, the 16kB ROM-Block Frame from $C000 to $FFFF is enabled, 
                                                and the CPU sees the ROM-Block selected by the ROMBLOCK register at $9F51 (and $01 if MIRROR_ZP is set).
                                                When cleared to 0, the ROM-Block Frame is disabled, and the CPU sees the SRAM directly at $C000 to $FFFF.
                                                This is useful to enable for generic 6502 code and it is necessary for compatibility with CX16 code.
                                                For 65816 systems in Native 16-bit mode, it is recommended to clear this bit to 0 and not use ROM-Blocks.
                                        
                                        [3] bit ENABLE_RAM_CD:
                                                When set to 1, the second 8kB RAM-Block Frame between $C000 to $DFFF is enabled, and the CPU sees 
                                                the RAM-Block selected by the RamBLOCK_CD ($9F51) register.
                                                When cleared to 0, the second RAM-Block Frame is disabled, and the CPU sees the SRAM directly at $C000 to $DFFF.
                                                For 6502 system (8-bit) the ROM-Block Frame should be enabled (bit ENABLE_RO_CDEF=1) and this bit should be cleared to 0;
                                                this is also the necessary setting for compatibility with CX16 code.

                                                Note: it is not allowed to simultaneosly set ENABE_RAM_CD and ENABLE_ROM_CDEF bits to 1 !!
                                        
                                        [2] bit RDONLY_EF:
                                                When set (1), Read-only protect the area from $E000 to $FFFF.
                                            
                                        [1] bit RDONLY_CD:
                                                When set (1), Read-only protect the area from $C000 to $DFFF.

                                        [0] reserved, write 0

    $9F54           SYSCTRL                         System control / reset trigger.
                                        [7] bit UNLOCK: to prevent unintended system resets, the SYSCTRL must be first unlocked by writing 0x80 into the register.
                                            This bit always reads 0.
                                        [6] bit ABRT02: writing 1 (after UNLOCKing) will enable ABORTing of 65C02-only opcodes
                                            encountered during the Emulation mode of the 65816 processor: BBR, BBS, RMB, SMB.
                                            Software should then emulate the behaviour of the 65C02 instructions in the ABORT handler.
                                        [5] unused, write 0
                                        [4] unused, write 0
                                        [3] unused, write 0
                                        [2] bit NORARESET: writing 1 (after UNLOCKing) will trigger a hard NORA reset - bitstream reloading.
                                            This bit always reads 0.
                                        [1] bit CPUSTOP: writing 1 (after UNLOCKing) will stop the CPU forever.
                                            This bit always reads 0.
                                        [0] bit CPURESET: writing 1 (after UNLOCKing) will trigger CPU reset sequence. 
                                            Note: ROMBANK or any other registers are not affected!
                                            This bit always reads 0.

The next three registers control the *USB_UART* periphery:

    Address         Reg.name            Bits        Description
    $9F55           USB_UART_CTRL
                                        [2:0] = Baud Rate
                                                000 = reserved
                                                001 = reserved
                                                010 = 9600 Bd
                                                011 = 57600 Bd
                                                100 = 115200 Bd = DEFAULT
                                                101 = 230400 Bd
                                                110 = 1000000 Bd (non-standard freq)
                                                111 = 3000000 Bd (non-standard freq)
                                        [3] = Enable Parity generation/checking, DEFAULT=0
                                        [4] = Parity Configuration: 0=even (DEFAULT), 1=odd.
                                        [5] = Enable HW-FlowCtrl (RTS/CTS) - honoring the CTS signal.
                                                When the CTS input is active (low), transmission from FIFO is allowed.
                                                When the CTS input is inactive (high), transmissions are blocked.
                                                DEFAULT = OFF.
                                        [6] = Enable IRQ activation on not(RX-FIFO-empty)
                                        [7] = Enable IRQ activation on not(TX-FIFO-full)

    $9F56           USB_UART_STAT                   USB(FTDI)-UART Status
                                        [0] = reserved, 0.
                                        [1] = Is RX FIFO full?
                                        [2] = Is TX FIFO empty AND all chars were sent?
                                        [3] = Is TX FIFO full (no more TX chars can be accepted)?
                                        [4] = Framing Error Flag, latching, clear by writing 0.
                                        [5] = Parity Error Flag, latching, clear by writing 0.
                                        [6] = CTS signal Status: 1=CTS inactive (voltage=high), 0=CTS active (voltage=low).
                                        [7] = Is RX FIFO empty?

    $9F57           USB_UART_DATA       [7:0]       Reading dequeues data from the RX FIFO.
                                                    Writing enqueues to the TX FIFO.

The next three registers control the *UEXT_UART* periphery, currently NOT IMPLEMENTED:

    Address         Reg.name            Bits        Description
    $9F58           UEXT_UART_CTRL                  Same as USB_UART_CTRL but for UEXT UART. 
                                                    RTS/CTS Hw-Flow-Control is not supported on UEXT UART,
    $9F59           UEXT_UART_STAT                  Same as USB_UART_STAT but for UEXT UART. 
    $9F5A           UEXT_UART_DATA                  Same as USB_UART_DATA but for UEXT UART. 

The next three registers control the *I2C Master* periphery:

    Address         Reg.name            Bits        Description
    $9F5B           I2C_CTRL
                                        [2:0] = I2C_Command field:
                                                000 = idle/no operation.
                                                001 = START_ADDRESS: generate START condition, send ADDRESS (passed via the DATA register),
                                                        then read the ACK bit, which gets written into the DATA register.
                                                010 = SEND_DATA_READ_ACK: send data to I2C from the DATA reg., read ACK bit and write it to the DATA reg.
                                                011 = RECV_DATA: receive data from the I2C bus into DATA reg
                                                100 = WRITE_ACK
                                                101 = WRITE_NACK
                                                111 = STOP: generate stop condition
                                        
                                        [6:3] = reserved, 0
                                        [7] = Enable IRQ when not(BUSY)

    $9F5C           I2C_STAT            [3:0] = view of internal FSM state; see verilog
                                        [4] = SCL link state (high/low)
                                        [5] = SDA link state (high/low)
                                        [6] = TIMEOUT flag: reads 1 if last operation had to be cancelled due to I2C bus timeout.
                                              The flag is automatically cleared when a new operation is started.
                                        [7] = BUSY flag: reads 1 if operation in progress, otherwise 0.

    $9F5D           I2C_DATA            [7:0]       Reads/writes the DATA register.

The next five registers control the dual-PS/2 periphery through the SMC:

    Address         Reg.name            Bits        Description
    $9F5E           PS2_CTRL                        PS2 Control register
                                        [7:2] = reserved, 0
                                        [1] = Enable IRQ when kbd buffer has a byte, or mouse buffer has >= 3 bytes
                                        [0] = Disable scancode-to-keycode translation in HW. 
                                              Default is 0 = translation enabled = PS2K_BUF reads IBM key-codes.
                                              If 1 = translation disabled = PS2K_BUF reads PS/2 scan-codes.

    $9F5F           PS2_STAT                        PS2 Status Register
                                        [7] = KBD Buffer FIFO is non-empty
                                        [6] = Mouse Buffer RX-FIFO is non-empty
                                        [5] = Mouse buffer RX-FIFO has 3 or more bytes [3B = mouse movement packet]
                                        [4:0] = unused, 0

    $9F60           PS2K_BUF            [7:0]       Keyboard buffer (FIFO output).
                                                    Reading gets the next keycode (scancode) received from the keyboard,
                                                    or 0x00 if the buffer was empty.
                                                    Writing will enqueue a 1-byte command for the keyboard.
                                                    See https://wiki.osdev.org/PS/2_Keyboard#Scan_Code_Sets for the hints.

    $9F61           PS2K_RSTAT          [7:0]       Reply status from keyboard (in response from a command).
                                                    Possible values:
                                                        0x00 => idle (no transmission started)
                                                        0x01 => transmission pending
                                                        0xFA => ACK received
                                                        0xFE => ERR received
                                                    Special case: Writing will enqueue a 2-byte command for the keyboard
                                                    (both bytes must be written in PS2K_RSTAT consequtevely.)

    $9F62           PS2M_BUF            [7:0]       Mouse buffer (FIFO output).

The next three registers control the *SPI-Master* periphery in NORA.
The SPI-Master can access NORA's UNIFIED ROM (really the SPI-Flash primarilly for NORA bitstream), and the SPI bus on UEXT port:

    Address         Reg.name            Bits        Description
    $9F63           N_SPI_CTRL
                                        [7:6] = reserved, 0
                                        TBD: IRQ???
                                        [5:3] = set the SPI speed - SCK clock frequency:
                                                000 = 100kHz
                                                001 = 400kHz
                                                010 = 1MHz
                                                011 = 8MHz
                                                100 = 24MHz
                                                other = reserved.
                   
                                        [2:0] = set the target SPI slave (1-7), or no slave (CS high) when 0.
                                                000 = no slave (all deselect)
                                                001 = UNIFIED ROM = NORA's SPI-Flash
                                                010 = UEXT SPI-Bus
                                                other = reserved.

    $9F64           N_SPI_STAT                      SPI Status
                                        [0] = Is RX FIFO empty?
                                        [1] = Is RX FIFO full?
                                        [2] = Is TX FIFO empty?
                                        [3] = Is TX FIFO full?
                                        [4] = reserved, 0
                                        [5] = reserved, 0
                                        [6] = reserved, 0
                                        [7] = Is BUSY - is TX/RX in progress?

    $9F65           N_SPI_DATA                      Reading dequeues data from the RX FIFO.
                                                    Writing enqueues to the TX FIFO.

The next register controls global IRQ/NMI masking:

    $9F63           IRQCTRL         
                                        [7] = VERAIRQ_EN
                                        [6] = AURAIRQ_EN
                                        [5] = ETHIRQ_EN
                                        [4] = UEXTIRQ_EN
                                        [3] = NORAIRQ_EN (PS2, UART, IRQ, SPI)
                                        [2] = unused
                                        [1] = unused
                                        [0] = unused
    
    $9F64           IRQSTAT

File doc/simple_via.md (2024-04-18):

Simple-VIA
============

TBD: describe what is implemented in the simple-via and what not in comparison with the 6522

**Simplified VIA #1** (65C22)
------------------------------

Provides basic GPIO and Timer service.
(Timer not implemented so far.)

    Port B:  PRB @ 0x9F00, DDRB @ 0x9F02
        PB0 = CPUTYPE02 (0 => 65816, 1 => 6502)
        PB1 = 
        PB2 = 
        PB3..PB7 = IEEE488, unused, reads 11000.

    Port A: PRA @ 0x9F01, DDRB @ 0x9F03
        PA0 = SDA
        PA1 = SCL
        PA2 = NESLATCH
        PA3 = NESCLOCK
        PA4 = (NESDATA3) = 1
        PA5 = (NESDATA2) = 1
        PA6 = NESDATA1
        PA7 = NESDATA0

**Simplified VIA #2** (65C22)
------------------------------

    Port B: PRB @ 0x9F10, DDRB @ 0x9F12
        PB0 = out:CPULED0 (green, front), in:/SD_CD
        PB1 = out:CPULED1 (orange, front), in:SD_WP
        PB2 = DIPLED0, yellow, internal
        PB3 = DIPLED1, yellow, internal
        PB4 = unused
        PB5 = unused
        PB6 = unused
        PB7 = ERST, Wiznet ethernet reset, active low (has pull-up)

    Port A: PRA @ 0x9F11, DDRB @ 0x9F13
        PA0 = 
        PA1 = 
        PA2 = 
        PA3 = 
        PA4 = 
        PA5 = 
        PA6 = 
        PA7 =

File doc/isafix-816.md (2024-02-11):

ISAFIX-816
==============

Regarding the Instruction Set Architecture (ISA), 32 instructions are different between the 6502 and 65816 processors.
The following two tables, copied from datasheets of the processors, highlight them.
They are in the column 7 and F, i.e. the problematic instructions have the op-code x7 and xF, where x is 0..F.

Opcodes 65C02
Opcodes 65C816

The problematic instructions (from the 65C816 point of view) are the following 65C02 instructions:
* RMB0..RMB7 zp = Reset Memory Bit in zero-page
* SMB0..SMB7 zp = Set Memory Bit in zero-page
* BBR0..BBR7 zp, rr = Branch on Bit Set in zero-page to relative address
* BBS0..BBS7 zp, rr = Branch on Bit Reset in zero-page to relative address

If 65C816 (in the Emulation Mode) should run a program originally written for 65C02, these instructions must be replaced
with an alternative code. 

Replace:

    RMBn/SMBn   zp              ; ?7 zp

With:

    NOP                         ; EA; skip over bad instruction
    NOP                         ; EA; skip over its operand; catch zp from memory

and make changes to "(zp)" in NORA behind the scene.

Replace:

    BBRn/BBSn   zp, rr               ; ?F zp rr

With:

    NOP                         ; EA; skip over bad instruction
    BRA                         ; 80; catch zp from memory
                                ; NORA checks if interested bit is 0/1 in the zp, if the branch would be taken/not-taken.

If 6502 would not-take the branch, then we just need to skip the rr byte and we will be on correct path.
Therefore, force:

    00                         ; BRA continues to next instruction

On the other hand, if 6502 *would* take the branch, then force instruction

    .                           ; let BRA pick up the correct rr from next byte and continue.

ALTERNATIVE APPROACH: MAX IN SW
---------------------------------

Detect wrong instruction during S5H.
Generate RDY=LOW (maybe delay S5H by 1cc to ensure good RDY setup).
Then PHY2 falling edge.
Do RDY=HIGH and ABORT=LOW => the CPU should abort the bad instruction and go to the abort handler.
Rest in SW (maybe with HW accel if necessary).

IMPROVEMENT:
All the wrong instructions are multi-byte.
We could do ABORT on the second instruction byte and the result is the same!

Step #   -2:  MAH:40 (ROMB:  0)  CBA: 0  CA:ff1a  CD: 0  ctr:13:RI--  sta:5b:r--emx---     
Step #   -1:  MAH:40 (ROMB:  0)  CBA: 0  CA:ff1a  CD: 0  ctr:13:RI--  sta:5b:r--emx---     
Step #    0:  MAH:40 (ROMB:  0)  CBA: 0  CA:ff1a  CD: 0  ctr:13:RI--  sta:5b:r--emx---     
Step #    1:  MAH:40 (ROMB:  0)  CBA: 0  CA:ff1a  CD: 0  ctr:1b:-I--  sta:5b:r--emx---     
Step #    2:  MAH:40 (ROMB:  0)  CBA: 0  CA:ff1a  CD: 0  ctr:1b:-I--  sta:5b:r--emx---     
Step #    3:  MAH:41 (ROMB:  0)  CBA: 0  CA:ffff  CD:ff  ctr:1b:-I--  sta:7f:r--emxPDS     SBC $434241,X    ; WARNING: 6502-only opcode while in the EMU mode!
Step #    4:  MAH:42 (ROMB:  1)  CBA: 0  CA:ff1a  CD:58  ctr:1b:-I--  sta:5b:r--emx---     
Step #    5:  MAH: 0 (low :  0)  CBA: 0  CA: 1ff  CD: 3  ctr:1b:-I--  sta:5f:r--emx-D-     
Step #    6:  MAH: 0 (low :  0)  CBA: 0  CA: 1fe  CD:14  ctr:1b:-I--  sta:5f:r--emx-D-     
Step #    7:  MAH: 0 (low :  0)  CBA: 0  CA: 1fd  CD:24  ctr:1b:-I--  sta:5f:r--emx-D-     
Step #    8:  MAH:41 (ROMB:  0)  CBA: 0  CA:fffc  CD: 0  ctr:1b:-I--  sta:57:rv-emx-D-     
Step #    9:  MAH:41 (ROMB:  0)  CBA: 0  CA:fffd  CD:ff  ctr:1b:-I--  sta:57:rv-emx-D-     
Step #   10:  MAH:41 (ROMB:  0)  CBA: 0  CA:ff00  CD:a2  ctr:1b:-I--  sta:7f:r--emxPDS     LDX #$ff
Step #    1:  MAH:41 (ROMB:  0)  CBA: 0  CA:ff01  CD:ff  ctr:1b:-I--  sta:7b:r--emxP--     
Step #    2:  MAH:41 (ROMB:  0)  CBA: 0  CA:ff02  CD:9a  ctr:1b:-I--  sta:7f:r--emxPDS     TXS
Step #    3:  MAH:41 (ROMB:  0)  CBA: 0  CA:ff03  CD:9a  ctr:1b:-I--  sta:5b:r--emx---     
Step #    4:  MAH:41 (ROMB:  0)  CBA: 0  CA:ff03  CD:a9  ctr:1b:-I--  sta:7f:r--emxPDS     LDA #$2
Step #    5:  MAH:41 (ROMB:  0)  CBA: 0  CA:ff04  CD: 2  ctr:1b:-I--  sta:7b:r--emxP--     
Step #    6:  MAH:41 (ROMB:  0)  CBA: 0  CA:ff05  CD:8d  ctr:1b:-I--  sta:7f:r--emxPDS     STA $9f02
Step #    7:  MAH:41 (ROMB:  0)  CBA: 0  CA:ff06  CD: 2  ctr:1b:-I--  sta:7b:r--emxP--     
Step #    8:  MAH:41 (ROMB:  0)  CBA: 0  CA:ff07  CD:9f  ctr:1b:-I--  sta:7b:r--emxP--     
Step #    9:  MAH:41 (ROMB:  0)  CBA: 0  CA:9f02  CD: 2  ctr:1b:-I--  sta:5e:W--emx-D-     
Step #   10:  MAH:41 (ROMB:  0)  CBA: 0  CA:ff08  CD:a9  ctr:1b:-I--  sta:7f:r--emxPDS     LDA #$1
Step #    1:  MAH:41 (ROMB:  0)  CBA: 0  CA:ff09  CD: 1  ctr:1b:-I--  sta:7b:r--emxP--     
Step #    2:  MAH:41 (ROMB:  0)  CBA: 0  CA:ff0a  CD:48  ctr:1b:-I--  sta:7f:r--emxPDS     PHA
Step #    3:  MAH:41 (ROMB:  0)  CBA: 0  CA:ff0b  CD:48  ctr:1b:-I--  sta:5b:r--emx---     
Step #    4:  MAH: 0 (low :  0)  CBA: 0  CA: 1ff  CD: 1  ctr:1b:-I--  sta:5e:W--emx-D-     
Step #    5:  MAH:41 (ROMB:  0)  CBA: 0  CA:ff0b  CD:29  ctr:1b:-I--  sta:7f:r--emxPDS     AND #$2
Step #    6:  MAH:41 (ROMB:  0)  CBA: 0  CA:ff0c  CD: 2  ctr:1b:-I--  sta:7b:r--emxP--     
Step #    7:  MAH:41 (ROMB:  0)  CBA: 0  CA:ff0d  CD:8d  ctr:1b:-I--  sta:7f:r--emxPDS     STA $9f00
Step #    8:  MAH:41 (ROMB:  0)  CBA: 0  CA:ff0e  CD: 0  ctr:1b:-I--  sta:7b:r--emxP--     
Step #    9:  MAH:41 (ROMB:  0)  CBA: 0  CA:ff0f  CD:9f  ctr:1b:-I--  sta:7b:r--emxP--     
Step #   10:  MAH:41 (ROMB:  0)  CBA: 0  CA:9f00  CD: 0  ctr:1b:-I--  sta:5e:W--emx-D-     
Step #    1:  MAH:41 (ROMB:  0)  CBA: 0  CA:ff10  CD:a9  ctr:1b:-I--  sta:7f:r--emxPDS     LDA #$2
Step #    2:  MAH:41 (ROMB:  0)  CBA: 0  CA:ff11  CD: 2  ctr:1b:-I--  sta:7b:r--emxP--     
Step #    3:  MAH:41 (ROMB:  0)  CBA: 0  CA:ff12  CD:68  ctr:1b:-I--  sta:7f:r--emxPDS     PLA
Step #    4:  MAH:41 (ROMB:  0)  CBA: 0  CA:ff13  CD:68  ctr:1b:-I--  sta:5b:r--emx---     
Step #    5:  MAH:41 (ROMB:  0)  CBA: 0  CA:ff13  CD:68  ctr:1b:-I--  sta:5b:r--emx---     
Step #    6:  MAH: 0 (low :  0)  CBA: 0  CA: 1ff  CD: 1  ctr:1b:-I--  sta:5f:r--emx-D-     
Step #    7:  MAH:41 (ROMB:  0)  CBA: 0  CA:ff13  CD:1a  ctr:1b:-I--  sta:7f:r--emxPDS     INC A
Step #    8:  MAH:41 (ROMB:  0)  CBA: 0  CA:ff14  CD:1a  ctr:1b:-I--  sta:5b:r--emx---     
Step #    9:  MAH:41 (ROMB:  0)  CBA: 0  CA:ff14  CD: 7  ctr:1b:-I--  sta:7f:r--emxPDS     ORA [$3]    ; WARNING: 6502-only opcode while in the EMU mode!
Step #   10:  MAH:41 (ROMB:  0)  CBA: 0  CA:ff15  CD: 3  ctr:1a:-I-A  sta:7b:r--emxP--     
Step #   11:  MAH: 0 (low :  0)  CBA: 0  CA:   3  CD: 0  ctr:1b:-I--  sta:5f:r--emx-D-     
Step #   12:  MAH: 0 (low :  0)  CBA: 0  CA:   4  CD: 0  ctr:1b:-I--  sta:5f:r--emx-D-     
Step #   13:  MAH: 0 (low :  0)  CBA: 0  CA:   5  CD: 0  ctr:1b:-I--  sta:5f:r--emx-D-     
Step #   14:  MAH: 0 (low :  0)  CBA: 0  CA:   0  CD: 7  ctr:1b:-I--  sta:5f:r--emx-D-     
Step #   15:  MAH:41 (ROMB:  0)  CBA: 0  CA:ff16  CD:87  ctr:1b:-I--  sta:7f:r--emxPDS     STA [$3]    ; WARNING: 6502-only opcode while in the EMU mode!
Step #   16:  MAH:41 (ROMB:  0)  CBA: 0  CA:ff16  CD:f0  ctr:1b:-I--  sta:5b:r--emx---     
Step #   17:  MAH: 0 (low :  0)  CBA: 0  CA: 1ff  CD:ff  ctr:1b:-I--  sta:5e:W--emx-D-     
Step #   18:  MAH: 0 (low :  0)  CBA: 0  CA: 1fe  CD:14  ctr:1b:-I--  sta:5e:W--emx-D-     
Step #   19:  MAH: 0 (low :  0)  CBA: 0  CA: 1fd  CD:24  ctr:1b:-I--  sta:5e:W--emx-D-     
Step #   20:  MAH:41 (ROMB:  0)  CBA: 0  CA:fff8  CD:1a  ctr:1b:-I--  sta:57:rv-emx-D-     
Step #    1:  MAH:41 (ROMB:  0)  CBA: 0  CA:fff9  CD:ff  ctr:1b:-I--  sta:57:rv-emx-D-     
Step #    2:  MAH:41 (ROMB:  0)  CBA: 0  CA:ff1a  CD:48  ctr:1b:-I--  sta:7f:r--emxPDS     PHA
Step #    3:  MAH:41 (ROMB:  0)  CBA: 0  CA:ff1b  CD:48  ctr:1b:-I--  sta:5b:r--emx---     
Step #    4:  MAH: 0 (low :  0)  CBA: 0  CA: 1fc  CD: 2  ctr:1b:-I--  sta:5e:W--emx-D-     
Step #    5:  MAH:41 (ROMB:  0)  CBA: 0  CA:ff1b  CD:68  ctr:1b:-I--  sta:7f:r--emxPDS     PLA
Step #    6:  MAH:41 (ROMB:  0)  CBA: 0  CA:ff1c  CD:68  ctr:1b:-I--  sta:5b:r--emx---     
Step #    7:  MAH:41 (ROMB:  0)  CBA: 0  CA:ff1c  CD:68  ctr:1b:-I--  sta:5b:r--emx---     
Step #    8:  MAH: 0 (low :  0)  CBA: 0  CA: 1fc  CD: 2  ctr:1b:-I--  sta:5f:r--emx-D-     
Step #    9:  MAH:41 (ROMB:  0)  CBA: 0  CA:ff1c  CD:40  ctr:1b:-I--  sta:7f:r--emxPDS     RTI
Step #   10:  MAH:41 (ROMB:  0)  CBA: 0  CA:ff1d  CD:40  ctr:1b:-I--  sta:5b:r--emx---     
Step #   11:  MAH:41 (ROMB:  0)  CBA: 0  CA:ff1d  CD:40  ctr:1b:-I--  sta:5b:r--emx---     
Step #   12:  MAH: 0 (low :  0)  CBA: 0  CA: 1fd  CD:24  ctr:1b:-I--  sta:5f:r--emx-D-     
Step #   13:  MAH: 0 (low :  0)  CBA: 0  CA: 1fe  CD:14  ctr:1b:-I--  sta:5f:r--emx-D-     
Step #   14:  MAH: 0 (low :  0)  CBA: 0  CA: 1ff  CD:ff  ctr:1b:-I--  sta:5f:r--emx-D-     
Step #   15:  MAH:41 (ROMB:  0)  CBA: 0  CA:ff14  CD: 7  ctr:1b:-I--  sta:7f:r--emxPDS     ORA [$3]    ; WARNING: 6502-only opcode while in the EMU mode!
Step #   16:  MAH:41 (ROMB:  0)  CBA: 0  CA:ff15  CD: 3  ctr:1b:-I--  sta:7b:r--emxP--     
Step #   17:  MAH: 0 (low :  0)  CBA: 0  CA:   3  CD: 0  ctr:1b:-I--  sta:5f:r--emx-D-     
Step #   18:  MAH: 0 (low :  0)  CBA: 0  CA:   4  CD: 0  ctr:1b:-I--  sta:5f:r--emx-D-     
Step #   19:  MAH: 0 (low :  0)  CBA: 0  CA:   5  CD: 0  ctr:1b:-I--  sta:5f:r--emx-D-     
Step #   20:  MAH: 0 (low :  0)  CBA: 0  CA:   0  CD: 7  ctr:1b:-I--  sta:5f:r--emx-D-     

We need extra support to place the ABORT handler in special ROMBLOCK, switch to it / remember the old one in a shadow reg.
In the handler, disable all IRQs/NMIs, switch to Native mode and jump to secondary handler (in CBA != 0).
In the secondary handler, restore the original ROMBLOCK - so that the CBA=0 space is as-original.
Now inspect the faulting instruction and emulate it (maybe with co-proc. help).
Finally, get back to the special ROMBLOCK, switch to emulation mode and RTI; original ROMBLOCK must be restored by hw during the RTI!!
Is this easier if we can put part of the code to unpaged memory in CBA=0 ?

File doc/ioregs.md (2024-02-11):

IO Registers
=============

There are 256 Bytes of address space reserved for I/O registers, mapped from $9F00 to $9FFF
(65816: from $009F00 to $009FFF) in the CPU address space.
This 256B is generally diveded in 16-byte blocks that are assigned to individual "modules"
or "devices" in the system, roughly corresponding to individual chip-select signals.

In addition, there are two special registers outside this I/O area: RAMBLOCK and ROMBLOCK.
These are mapped in the CPU Zero page at the addresses $0000 and $0001, respectively (65816: $000000 and $000001).

Overall I/O layout
----------------------

Note: In case of 65816 CPU, all I/O registers are visible just in the first 64k-Bank $00.
    => to read the tables below correctly, just add $00 in front of the presented addresses
    to obtain the 24-bit physical address.

| Address | Module |
|---|---|
| $0000 ... $0001 | [NORA](ioregs-nora.md): RAMBLOCK, ROMBLOCK registers  |
| $9F00 ... $9F0F | [Simple-VIA #1](simple_via.md) |
| $9F10 ... $9F1F | [Simple-VIA #2](simple_via.md) |
| $9F20 ... $9F3F | [VERA](ioregs-vera.md) |
| $9F40 ... $9F4F | [AURA](ioregs-aura.md) |
| $9F50 ... $9F6F | [NORA](ioregs-nora.md) |
| $9F70 ... $9F7F | unused, reserved for NORA |
| $9F80 ... $9F8F | [W6100L](ioregs-wiznet.md) ethernet controller |
| $9F90 ... $9FEF | unused |
| $9FF0 ... $9FFF | SRAM scratchpad, used by ISAFIX handler under ABORT |

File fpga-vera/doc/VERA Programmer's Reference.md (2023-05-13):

# VERA Programmer's Reference

Version 0.9

_Author: Frank van den Hoef_

**This is preliminary documentation and the specification can still change at any point.**

This document describes the **V**ersatile **E**mbedded **R**etro **A**dapter or VERA. The VERA consists of:

- Video generator featuring:
  - Multiple output formats (VGA, NTSC Composite, NTSC S-Video, RGB video) at a fixed resolution of 640x480@60Hz
  - Support for 2 layers, both supporting either tile or bitmap mode.
  - Support for up to 128 sprites.
  - Embedded video RAM of 128kB.
  - Palette with 256 colors selected from a total range of 4096 colors.
- 16-channel Programmable Sound Generator with multiple waveforms (Pulse, Sawtooth, Triangle, Noise)
- High quality PCM audio playback from an 4kB FIFO buffer featuring up to 48kHz 16-bit stereo sound.
- SPI controller for SecureDigital storage.

# Registers

<table>
	<tr>
		<th>Addr</th>
		<th>Name</th>
		<th>Bit&nbsp;7</th>
		<th>Bit&nbsp;6</th>
		<th>Bit&nbsp;5 </th>
		<th>Bit&nbsp;4</th>
		<th>Bit&nbsp;3 </th>
		<th>Bit&nbsp;2</th>
		<th>Bit&nbsp;1 </th>
		<th>Bit&nbsp;0</th>
	</tr>
	<tr>
		<td>$00</td>
		<td>ADDRx_L (x=ADDRSEL)</td>
		<td colspan="8" align="center">VRAM Address (7:0)</td>
	</tr>
	<tr>
		<td>$01</td>
		<td>ADDRx_M (x=ADDRSEL)</td>
		<td colspan="8" align="center">VRAM Address (15:8)</td>
	</tr>
	<tr>
		<td>$02</td>
		<td>ADDRx_H (x=ADDRSEL)</td>
		<td colspan="4" align="center">Address Increment</td>
		<td colspan="1" align="center">DECR</td>
		<td colspan="2" align="center">-</td>
		<td colspan="1" align="center">VRAM Address (16)</td>
	</tr>
	<tr>
		<td>$03</td>
		<td>DATA0</td>
		<td colspan="8" align="center">VRAM Data port 0</td>
	</tr>
	<tr>
		<td>$04</td>
		<td>DATA1</td>
		<td colspan="8" align="center">VRAM Data port 1</td>
	</tr>
	<tr>
		<td>$05</td>
		<td>CTRL</td>
		<td colspan="1" align="center">Reset</td>
		<td colspan="5" align="center">-</td>
		<td colspan="1" align="center">DCSEL</td>
		<td colspan="1" align="center">ADDRSEL</td>
	</tr>
	<tr>
		<td>$06</td>
		<td>IEN</td>
		<td colspan="1" align="center">IRQ Line (8)</td>
		<td colspan="1" align="center">Scan Line (8)</td>
		<td colspan="2" align="center">-</td>
		<td colspan="1" align="center">AFLOW</td>
		<td colspan="1" align="center">SPRCOL</td>
		<td colspan="1" align="center">LINE</td>
		<td colspan="1" align="center">VSYNC</td>
	</tr>
	<tr>
		<td>$07</td>
		<td>ISR</td>
		<td colspan="4" align="center">Sprite collissions</td>
		<td colspan="1" align="center">AFLOW</td>
		<td colspan="1" align="center">SPRCOL</td>
		<td colspan="1" align="center">LINE</td>
		<td colspan="1" align="center">VSYNC</td>
	</tr>
	<tr>
		<td>$08</td>
		<td>IRQLINE_L (Write only)</td>
		<td colspan="8" align="center">IRQ line (7:0)</td>
	</tr>
	<tr>
		<td>$08</td>
		<td>SCANLINE_L (Read only)</td>
		<td colspan="8" align="center">Scan line (7:0)</td>
	</tr>
	<tr>
		<td>$09</td>
		<td>DC_VIDEO (DCSEL=0)</td>
		<td colspan="1" align="center">Current Field</td>
		<td colspan="1" align="center">Sprites Enable</td>
		<td colspan="1" align="center">Layer1 Enable</td>
		<td colspan="1" align="center">Layer0 Enable</td>
		<td colspan="1" align="center">-</td>
		<td colspan="1" align="center">Chroma Disable</td>
		<td colspan="2" align="center">Output Mode</td>
	</tr>
	<tr>
		<td>$0A</td>
		<td>DC_HSCALE (DCSEL=0)</td>
		<td colspan="8" align="center">Active Display H-Scale</td>
	</tr>
	<tr>
		<td>$0B</td>
		<td>DC_VSCALE (DCSEL=0)</td>
		<td colspan="8" align="center">Active Display V-Scale</td>
	</tr>
	<tr>
		<td>$0C</td>
		<td>DC_BORDER (DCSEL=0)</td>
		<td colspan="8" align="center">Border Color</td>
	</tr>
	<tr>
		<td>$09</td>
		<td>DC_HSTART (DCSEL=1)</td>
		<td colspan="8" align="center">Active Display H-Start (9:2)</td>
	</tr>
	<tr>
		<td>$0A</td>
		<td>DC_HSTOP (DCSEL=1)</td>
		<td colspan="8" align="center">Active Display H-Stop (9:2)</td>
	</tr>
	<tr>
		<td>$0B</td>
		<td>DC_VSTART (DCSEL=1)</td>
		<td colspan="8" align="center">Active Display V-Start (8:1)</td>
	</tr>
	<tr>
		<td>$0C</td>
		<td>DC_VSTOP (DCSEL=1)</td>
		<td colspan="8" align="center">Active Display V-Stop (8:1)</td>
	</tr>
	<tr>
		<td>$0D</td>
		<td>L0_CONFIG</td>
		<td colspan="2" align="center">Map Height</td>
		<td colspan="2" align="center">Map Width</td>
		<td colspan="1" align="center">T256C</td>
		<td colspan="1" align="center">Bitmap Mode</td>
		<td colspan="2" align="center">Color Depth</td>
	</tr>
	<tr>
		<td>$0E</td>
		<td>L0_MAPBASE</td>
		<td colspan="8" align="center">Map Base Address (16:9)</td>
	</tr>
	<tr>
		<td>$0F</td>
		<td>L0_TILEBASE</td>
		<td colspan="6" align="center">Tile Base Address (16:11)</td>
		<td colspan="1" align="center">Tile Height</td>
		<td colspan="1" align="center">Tile Width</td>
	</tr>
	<tr>
		<td>$10</td>
		<td>L0_HSCROLL_L</td>
		<td colspan="8" align="center">H-Scroll (7:0)</td>
	</tr>
	<tr>
		<td>$11</td>
		<td>L0_HSCROLL_H</td>
		<td colspan="4" align="center">-</td>
		<td colspan="8" align="center">H-Scroll (11:8)</td>
	</tr>
	<tr>
		<td>$12</td>
		<td>L0_VSCROLL_L</td>
		<td colspan="8" align="center">V-Scroll (7:0)</td>
	</tr>
	<tr>
		<td>$13</td>
		<td>L0_VSCROLL_H</td>
		<td colspan="4" align="center">-</td>
		<td colspan="8" align="center">V-Scroll (11:8)</td>
	</tr>
	<tr>
		<td>$14</td>
		<td>L1_CONFIG</td>
		<td colspan="2" align="center">Map Height</td>
		<td colspan="2" align="center">Map Width</td>
		<td colspan="1" align="center">T256C</td>
		<td colspan="1" align="center">Bitmap Mode</td>
		<td colspan="2" align="center">Color Depth</td>
	</tr>
	<tr>
		<td>$15</td>
		<td>L1_MAPBASE</td>
		<td colspan="8" align="center">Map Base Address (16:9)</td>
	</tr>
	<tr>
		<td>$16</td>
		<td>L1_TILEBASE</td>
		<td colspan="6" align="center">Tile Base Address (16:11)</td>
		<td colspan="1" align="center">Tile Height</td>
		<td colspan="1" align="center">Tile Width</td>
	</tr>
	<tr>
		<td>$17</td>
		<td>L1_HSCROLL_L</td>
		<td colspan="8" align="center">H-Scroll (7:0)</td>
	</tr>
	<tr>
		<td>$18</td>
		<td>L1_HSCROLL_H</td>
		<td colspan="4" align="center">-</td>
		<td colspan="8" align="center">H-Scroll (11:8)</td>
	</tr>
	<tr>
		<td>$19</td>
		<td>L1_VSCROLL_L</td>
		<td colspan="8" align="center">V-Scroll (7:0)</td>
	</tr>
	<tr>
		<td>$1A</td>
		<td>L1_VSCROLL_H</td>
		<td colspan="4" align="center">-</td>
		<td colspan="8" align="center">V-Scroll (11:8)</td>
	</tr>
	<tr>
		<td>$1B</td>
		<td>AUDIO_CTRL</td>
		<td colspan="1" align="center">FIFO Full / FIFO Reset</td>
		<td colspan="1" align="center">FIFO Empty</td>
		<td colspan="1" align="center">16-Bit</td>
		<td colspan="1" align="center">Stereo</td>
		<td colspan="4" align="center">PCM Volume</td>
	</tr>
	<tr>
		<td>$1C</td>
		<td>AUDIO_RATE</td>
		<td colspan="8" align="center">PCM Sample Rate</td>
	</tr>
	<tr>
		<td>$1D</td>
		<td>AUDIO_DATA</td>
		<td colspan="8" align="center">Audio FIFO data (write-only)</td>
	</tr>
	<tr>
		<td>$1E</td>
		<td>SPI_DATA</td>
		<td colspan="8" align="center">Data</td>
	</tr>
	<tr>
		<td>$1F</td>
		<td>SPI_CTRL</td>
		<td colspan="1" align="center">Busy</td>
		<td colspan="4" align="center">-</td>
		<td colspan="1" align="center">Auto-tx</td>
		<td colspan="1" align="center">Slow clock</td>
		<td colspan="1" align="center">Select</td>
	</tr>
</table>

## VRAM address space layout

| Address range | Description |
| --- | --- |
| $00000 - $1F9BF | Video RAM |
| $1F9C0 - $1F9FF | PSG registers |
| $1FA00 - $1FBFF | Palette |
| $1FC00 - $1FFFF | Sprite attributes |

**_Important note:
Video RAM locations 1F9C0-1FFFF contain registers for the PSG/Palette/Sprite attributes. Reading anywhere in VRAM will always read back the 128kB VRAM itself (not the contents of the (write-only) PSG/Palette/Sprite attribute registers). Writing to a location in the register area will write to the registers in addition to writing the value also to VRAM. Since the VRAM contains random values at startup the values read back in the register area will not correspond to the actual values in the write-only registers until they are written to once.
Because of this it is highly recommended to initialize the area from 1F9C0-1FFFF at startup._**

## Video RAM access

The video RAM (VRAM) isn't directly accessible on the CPU bus. VERA only exposes an address space of 32 bytes to the CPU as described in the section [Registers](#registers). To access the VRAM (which is 128kB in size) an indirection mechanism is used. First the address to be accessed needs to be set (ADDRx_L/ADDRx_M/ADDRx_H) and then the data on that VRAM address can be read from or written to via the DATA0/1 register. To make accessing the VRAM more efficient an auto-increment mechanism is present.

There are 2 data ports to the VRAM. Which can be accessed using DATA0 and DATA1. The address and increment associated with the data port is specified in ADDRx_L/ADDRx_M/ADDRx_H. These 3 registers are multiplexed using the ADDR_SEL in the CTRL register. When ADDR_SEL = 0, ADDRx_L/ADDRx_M/ADDRx_H become ADDR0_L/ADDR0_M/ADDR0_H.  
When ADDR_SEL = 1, ADDRx_L/ADDRx_M/ADDRx_H become ADDR1_L/ADDR1_M/ADDR1_H.

By setting the 'Address Increment' field in ADDRx_H, the address will be increment after each access to the data register. The increment register values and corresponding increment amounts are shown in the following table:

| Register value | Increment amount |
| ---: | ---: |
| 0 | 0 |
| 1 | 1 |
| 2 | 2 |
| 3 | 4 |
| 4 | 8 |
| 5 | 16 |
| 6 | 32 |
| 7 | 64 |
| 8 | 128 |
| 9 | 256 |
| 10 | 512 |
| 11 | 40 |
| 12 | 80 |
| 13 | 160 |
| 14 | 320 |
| 15 | 640 |

Setting the **DECR** bit, will decrement instead of increment by the value set by the 'Address Increment' field.

## Reset

When **RESET** in **CTRL** is set to 1, the FPGA will reconfigure itself. All registers will be reset. The palette RAM will be set to its default values.

## Interrupts

Interrupts will be generated for the interrupt sources set in the lower 4 bits of **IEN**.
**ISR** will indicate the interrupts that have occurred. Writing a 1 to one of the lower 3 bits in **ISR** will clear that interrupt status. **AFLOW** can only be cleared by filling the audio FIFO for at least 1/4.

**IRQ_LINE** (write-only) specifies at which line the **LINE** interrupt will be generated. Note that bit 8 of this value is present in the **IEN** register. For interlaced modes the interrupt will be generated each field and the bit 0 of **IRQ_LINE** is ignored.

**SCANLINE** (read-only) indicates the current scanline being sent to the screen. Bit 8 of this value is present in the **IEN** register. The value is 0 during the first visible line and 479 during the last. This value continues to count beyond the last visible line, but returns $1FF for lines 512-524 that are beyond its 9-bit resolution. **SCANLINE** is not affected by interlaced modes and will return either all even or all odd values during an even or odd field, respectively. Note that VERA renders lines ahead of scanout such that line 1 is being rendered while line 0 is being scanned out. Visible changes may be delayed one scanline because of this.

The upper 4 (read-only) bits of the **ISR** register contain the [sprite collisions](#sprite-collisions) as determined by the sprite renderer.

## Display composer

The display composer is responsible of combining the output of the 2 layer renderers and the sprite renderer into the image that is sent to the video output.

The video output mode can be selected using OUT_MODE in DC_VIDEO.

| OUT_MODE | Description |
| ---: | --- |
| 0 | Video disabled |
| 1 | VGA output |
| 2 | NTSC composite |
| 3 | RGB interlaced, composite sync (via VGA connector) |

Setting **'Chroma Disable'** disables output of chroma in NTSC composite mode and will give a better picture on a monochrome display. _(Setting this bit will also disable the chroma output on the S-video output.)_

**'Current Field'** is a read-only bit which reflects the active interlaced field in composite and RGB modes. (0: even, 1: odd)

Setting **'Layer0 Enable'** / **'Layer1 Enable'** / **'Sprites Enable'** will respectively enable output from layer0 / layer1 and the sprites renderer.

**DC_HSCALE** and **DC_VSCALE** will set the fractional scaling factor of the active part of the display. Setting this value to 128 will output 1 output pixel for every input pixel. Setting this to 64 will output 2 output pixels for every input pixel.

**DC_BORDER** determines the palette index which is used for the non-active area of the screen.

**DC_HSTART**/**DC_HSTOP** and **DC_VSTART**/**DC_VSTOP** determines the active part of the screen. The values here are specified in the native 640x480 display space. HSTART=0, HSTOP=640, VSTART=0, VSTOP=480 will set the active area to the full resolution. Note that the lower 2 bits of **DC_HSTART**/**DC_HSTOP** and the lower 1 bit of **DC_VSTART**/**DC_VSTOP** isn't available. This means that horizontally the start and stop values can be set at a multiple of 4 pixels, vertically at a multiple of 2 pixels.

## Layer 0/1 registers

**'Map Base Address'** specifies the base address of the tile map. _Note that the register only specifies bits 16:9 of the address, so the address is always aligned to a multiple of 512 bytes._

**'Tile Base Address'** specifies the base address of the tile data. _Note that the register only specifies bits 16:11 of the address, so the address is always aligned to a multiple of 2048 bytes._

**'H-Scroll'** specifies the horizontal scroll offset. A value between 0 and 4095 can be used. Increasing the value will cause the picture to move left, decreasing will cause the picture to move right.

**'V-Scroll'** specifies the vertical scroll offset. A value between 0 and 4095 can be used. Increasing the value will cause the picture to move up, decreasing will cause the picture to move down.

**'Map Width'**, **'Map Height'** specify the dimensions of the tile map:

| Value | Map width / height |
| ----: | --- |
| 0 | 32 tiles |
| 1 | 64 tiles |
| 2 | 128 tiles |
| 3 | 256 tiles |

**'Tile Width'**, **'Tile Height'** specify the dimensions of a single tile:

| Value | Tile width / height |
| ----: | --- |
| 0 | 8 pixels |
| 1 | 16 pixels |

In bitmap modes, the **'H-Scroll (11:8)'** register is used to specify the palette offset for the bitmap.

### Layer display modes

The features of the 2 layers are the same. Each layer supports a few different modes which are specified using **T256C** / **'Bitmap Mode'** / **'Color Depth'** in Lx_CONFIG.

**'Color Depth'** specifies the number of bits used per pixel to encode color information:

| Color Depth | Description |
| ---: | --- |
| 0 | 1 bpp |
| 1 | 2 bpp |
| 2 | 4 bpp |
| 3 | 8 bpp |

The layer can either operate in tile mode or bitmap mode. This is selected using the **'Bitmap Mode'** bit; 0 selects tile mode, 1 selects bitmap mode.

The handling of 1 bpp tile mode is different from the other tile modes. Depending on the **T256C** bit the tiles use either a 16-color foreground and background color or a 256-color foreground color. Other modes ignore the **T256C** bit.

### Tile mode 1 bpp (16 color text mode)

**T256C** should be set to 0.

**MAP_BASE** points to a tile map containing tile map entries, which are 2 bytes each:

<table>
	<tr>
		<th>Offset</th>
		<th>Bit&nbsp;7</th>
		<th>Bit&nbsp;6</th>
		<th>Bit&nbsp;5</th>
		<th>Bit&nbsp;4</th>
		<th>Bit&nbsp;3</th>
		<th>Bit&nbsp;2</th>
		<th>Bit&nbsp;1</th>
		<th>Bit&nbsp;0</th>
	</tr>
	<tr>
		<td>0</td>
		<td align="center" colspan="8">Character index</td>
	</tr>
	<tr>
		<td>1</td>
		<td align="center" colspan="4">Background color</td>
		<td align="center" colspan="4">Foreground color</td>
	</tr>
</table>

**TILE_BASE** points to the tile data.

Each bit in the tile data specifies one pixel. If the bit is set the foreground color as specified in the map data is used, otherwise the background color as specified in the map data is used.

### Tile mode 1 bpp (256 color text mode)

**T256C** should be set to 1.

**MAP_BASE** points to a tile map containing tile map entries, which are 2 bytes each:

<table>
	<tr>
		<th>Offset</th>
		<th>Bit&nbsp;7</th>
		<th>Bit&nbsp;6</th>
		<th>Bit&nbsp;5</th>
		<th>Bit&nbsp;4</th>
		<th>Bit&nbsp;3</th>
		<th>Bit&nbsp;2</th>
		<th>Bit&nbsp;1</th>
		<th>Bit&nbsp;0</th>
	</tr>
	<tr>
		<td>0</td>
		<td align="center" colspan="8">Character index</td>
	</tr>
	<tr>
		<td>1</td>
		<td align="center" colspan="8">Foreground color</td>
	</tr>
</table>

**TILE_BASE** points to the tile data.

Each bit in the tile data specifies one pixel. If the bit is set the foreground color as specified in the map data is used, otherwise color 0 is used (transparent).

### Tile mode 2/4/8 bpp

**MAP_BASE** points to a tile map containing tile map entries, which are 2 bytes each:

<table>
	<tr>
		<th>Offset</th>
		<th>Bit&nbsp;7</th>
		<th>Bit&nbsp;6</th>
		<th>Bit&nbsp;5</th>
		<th>Bit&nbsp;4</th>
		<th>Bit&nbsp;3</th>
		<th>Bit&nbsp;2</th>
		<th>Bit&nbsp;1</th>
		<th>Bit&nbsp;0</th>
	</tr>
	<tr>
		<td>0</td>
		<td align="center" colspan="8">Tile index (7:0)</td>
	</tr>
	<tr>
		<td>1</td>
		<td align="center" colspan="4">Palette offset</td>
		<td align="center">V-flip</td>
		<td align="center">H-flip</td>
		<td align="center" colspan="2">Tile index (9:8)</td>
	</tr>
</table>

**TILE_BASE** points to the tile data.

Each pixel in the tile data gives a color index of either 0-3 (2bpp), 0-15 (4bpp), 0-255 (8bpp). This color index is modified by the palette offset in the tile map data using the following logic:

- Color index 0 (transparent) and 16-255 are unmodified.
- Color index 1-15 is modified by adding 16 x palette offset.

### Bitmap mode 1/2/4/8 bpp

**MAP_BASE** isn’t used in these modes. **TILE_BASE** points to the bitmap data.

**TILEW** specifies the bitmap width. TILEW=0 results in 320 pixels width and TILEW=1 results in 640 pixels width.

The palette offset (in **'H-Scroll (11:8)'**) modifies the color indexes of the bitmap in the same way as in the tile modes.
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

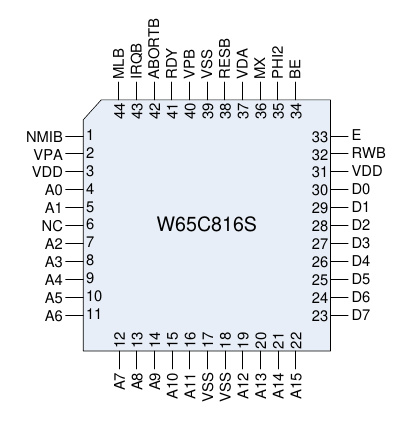
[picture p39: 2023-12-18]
doc/pic/w65c816_pinout.png

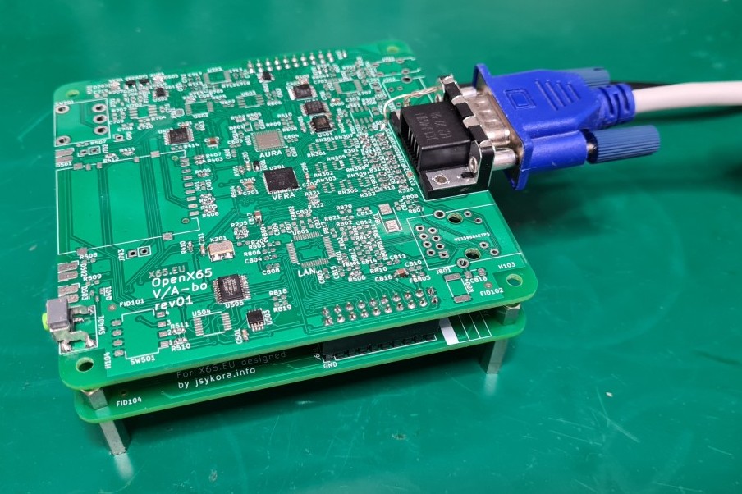
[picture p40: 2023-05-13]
Photos/20230508_200647-overview.jpg

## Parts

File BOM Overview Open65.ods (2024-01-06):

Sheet: MOBO+VABO_Rev01
module | Qty | Type | Description/Note | Cena/ks | Cena/pol | Link
Main | 1 | W65C816S6TQG-14 | cpu 16-bit | 274,00 Kč | 274,00 Kč | https://cz.mouser.com/ProductDetail/Western-Design-Center-WDC/W65C816S6TQG-14?qs=9lcNTSmDlCpDFNJ8GRf7eQ%3D%3D
Main | 1 | W65C02S6TQG-14 | cpu 8-bit | 260,00 Kč | 260,00 Kč | https://cz.mouser.com/ProductDetail/Western-Design-Center-WDC/W65C02S6TQG-14?qs=opBjA1TV900Cx5CoX8hQeQ%3D%3D
Main | 1 | ICE40HX4K-TQ144 | FPGA for NORA | 211,00 Kč | 211,00 Kč | https://cz.mouser.com/ProductDetail/Lattice/iCE40HX4K-TQ144?qs=F9A14TELRMvGNTZXkNDuOw%3D%3D
Main | 1 | IS61WV20488FBLL-10TLI | 2Mx8 SRAM | 290,00 Kč | 290,00 Kč | https://cz.mouser.com/ProductDetail/ISSI/IS61WV20488FBLL-10TLI?qs=l7cgNqFNU1hrNZYLU3MwTg%3D%3D
Main | 1 | W25Q128JVSIQ | Spi-flash 16MB, alt. | 41,00 Kč | 41,00 Kč | https://eu.mouser.com/ProductDetail/Winbond/W25Q128JVSIQ-TR?qs=qSfuJ%252Bfl%2Fd7vTyLA9kNdGw%3D%3D
Main | 1 | MCP7940N-I/SN | RTC | 21,00 Kč | 21,00 Kč | https://cz.mouser.com/ProductDetail/Microchip-Technology-Atmel/MCP7940N-I-SN?qs=o%2FJGMiCJeCOTsMP4nrR5Uw%3D%3D
Main | 0 | FT2232H-56Q-TRAY | FTDI (VQFN56) | 125,00 Kč | 0,00 Kč | https://eu.mouser.com/ProductDetail/FTDI/FT2232H-56Q-TRAY?qs=u4lROS522ZW4g0YyKZT0kg%3D%3D
Main | 1 | FT2232HL | FTDI alt. (LQFP64) | 173,00 Kč | 173,00 Kč | https://cz.farnell.com/ftdi/ft2232hl-r/usb-uart-fifo-2232-dual-64lqfp/dp/1697461?st=ft2232hl
Main | 1 | SG5032CAN 12.000000M-TJGA0 | oscillator 12M | 29,00 Kč | 29,00 Kč | https://cz.mouser.com/ProductDetail/Epson-Timing/SG5032CAN-12.000000M-TJGA0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
Main | 2 | 5749180-1 | Minidin-6 for PS/2 | 49,00 Kč | 98,00 Kč | https://cz.mouser.com/ProductDetail/TE-Connectivity/5749180-1?qs=XlZqES4cpWZV2xh%2FjR2Ukw%3D%3D
Main | 1 | USB4085-GF-A | Usb-c | 22,00 Kč | 22,00 Kč | https://cz.mouser.com/ProductDetail/GCT/USB4085-GF-A?qs=KUoIvG%2F9Ilba1bQOahfWjw%3D%3D
Main | 4 | GBK160808T-221Y-N | ferrite bead | 0,24 Kč | 0,96 Kč | https://cz.mouser.com/ProductDetail/Pulse-Electronics/GBK160808T-221Y-N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
Main | 0 | CM8V-T1A-32.768kHz-12.5pF-20PPM-TA-QC | Crystal 32.768k, SMD | 14,00 Kč | 0,00 Kč | https://cz.mouser.com/ProductDetail/Micro-Crystal/CM8V-T1A-32.768kHz-12.5pF-20PPM-TA-QC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
Main | 2 | SMD1206B050TF/15 | polyfuse 0,5A | 2,30 Kč | 4,60 Kč | https://cz.mouser.com/ProductDetail/YAGEO/SMD1206B050TF-15?qs=PzGy0jfpSMtHs3qJt7INeg%3D%3D
Main | 2 | SN74LVC2G17DBVR | driver | 10,00 Kč | 20,00 Kč | https://cz.mouser.com/ProductDetail/Texas-Instruments/SN74LVC2G17DBVR?qs=X1HXWTtiZ0RnstCufGEJxQ%3D%3D
Main | 1 | SN74LVC2G04DBVR | inverter | 10,00 Kč | 10,00 Kč | https://cz.mouser.com/ProductDetail/Texas-Instruments/SN74LVC2G04DBVR?qs=HE9hdJajmeqXJJ9RII89dg%3D%3D
Main | 1 | MP2149GJ-Z | dc/dc | 45,00 Kč | 45,00 Kč | https://cz.mouser.com/ProductDetail/Monolithic-Power-Systems-MPS/MP2149GJ-Z?qs=pdFhdcvjjggGberHhgLWyQ%3D%3D
Main | 3 | GRM21BC81C226ME44L | 22uF/16V/0805 | 10,00 Kč | 30,00 Kč | https://cz.mouser.com/ProductDetail/Murata-Electronics/GRM21BC81C226ME44L
Main | 2 | DFE252010P-2R2M=P2 | 2,2uH | 5,00 Kč | 10,00 Kč | https://cz.mouser.com/ProductDetail/Murata-Electronics/DFE252010P-2R2M%3dP2?qs=KuGPmAKtFKVG0t9I2u6EsA%3D%3D
Main | 5 | DFE252010P-1R0M=P2 | inductor 1uH/2.7A | 7,00 Kč | 35,00 Kč | https://cz.mouser.com/ProductDetail/Murata-Electronics/DFE252010P-1R0M%3dP2?qs=KuGPmAKtFKWP3jienGLHRQ%3D%3D
Main | 3 | CUS10S30,H3F | schotky | 8,00 Kč | 24,00 Kč | https://cz.mouser.com/ProductDetail/Toshiba/CUS10S30H3F?qs=cW4DzVrAanO4Xm6ySrHr7g%3D%3D
Main | 3 | LTST-S270GKT | green LED sideview 0603 | 6,00 Kč | 18,00 Kč | https://cz.mouser.com/ProductDetail/Lite-On/LTST-S270GKT?qs=sGAEpiMZZMvyj6n1w4pZD47FdTXqFYht4VAmSqE1GNY%3D
Main | 1 | LTST-S270EKT | red LED sideview 0603 | 6,00 Kč | 6,00 Kč | https://cz.mouser.com/ProductDetail/Lite-On/LTST-S270EKT?qs=O%2FWRddok7POgALoShN20Tw%3D%3D
Main | 1 | BAT-HLD-012-SMT | battery holder | 9,00 Kč | 9,00 Kč | https://cz.mouser.com/ProductDetail/Linx-Technologies/BAT-HLD-012-SMT?qs=Z0V%2FpEl%252BOGfZsSJil9WIXw%3D%3D
Main | 1 | EVQ-PUL02K | pushbutton | 14,00 Kč | 14,00 Kč | https://cz.mouser.com/ProductDetail/Panasonic/EVQ-PUL02K?qs=m7HfDvvzlLb0VFxnw%2FUN1w%3D%3D
Main | 7 | BSS123, T2N7002AK,LM | mosfet n, SOT-23 | 5,00 Kč | 35,00 Kč | https://cz.mouser.com/ProductDetail/Toshiba/T2N7002AKLM?qs=pzVvXTvk9PzfX4hYglwZ9Q%3D%3D
Main | 29 | CL10A105KO8NNWC | 1uF/16V/0603 | 1,00 Kč | 29,00 Kč | https://cz.mouser.com/ProductDetail/Samsung-Electro-Mechanics/CL10A105KO8NNWC
Main | 5 | SP0503BAHT | 3x transil 5.5V | 18,00 Kč | 90,00 Kč | https://cz.farnell.com/littelfuse/sp0503bahtg/esd-protection-device-5-5v-sot/dp/1827633?st=sp0503baht
Main | 1 | 74CBTLV3126PW,118 | bus switch | 11,40 Kč | 11,40 Kč | https://cz.farnell.com/nexperia/74cbtlv3126pw-118/bus-switch-4-bit-tssop-14/dp/2445215?st=74cbtlv3126pw,118
Main | 2 | xXxx | SNES connector |  |  | aliexpress
VABO | 2 | ICE40UP5K-SG48I | FPGA for VERA and AURA | 209,00 Kč | 418,00 Kč | https://cz.mouser.com/ProductDetail/Lattice/ICE40UP5K-SG48I?qs=Rp3RbKSfAt3UqOG1AN4%2FAg%3D%3D
VABO | 1 | WM8524CGEDT | audio DAC | 62,00 Kč | 62,00 Kč | https://cz.mouser.com/ProductDetail/Cirrus-Logic/WM8524CGEDT-R?qs=G8wrXCBxhFtUpBbVDBGrKA%3D%3D
VABO | 2 | W25Q16JVSNIQ | Flash | 12,00 Kč | 24,00 Kč | https://cz.mouser.com/ProductDetail/Winbond/W25Q16JVSNIQ?qs=qSfuJ%252Bfl%2Fd5tzEnNt99V4A%3D%3D
VABO | 1 | THS7314D | video amp | 22,00 Kč | 22,00 Kč | https://cz.mouser.com/ProductDetail/Texas-Instruments/THS7314D?qs=vD%252BlfiDS0%252BMvkYWNzhF7qg%3D%3D
VABO | 1 | DM1AA-SF-PEJ | Hirose SD-cage | 90,00 Kč | 90,00 Kč | https://cz.mouser.com/ProductDetail/Hirose-Connector/DM1AA-SF-PEJ82?qs=q%252B4FLHukgWBHaRKRr0HV%252Bw%3D%3D | https://www.tme.eu/cz/details/dm1aa-sf-pej-72/konektory-ke-kartam/hirose/dm1aa-sf-pej-72/
VABO | 1 | SG5032CAN 25.000000M-TJGA3 | oscillator 25MHz | 54,00 Kč | 54,00 Kč | https://cz.mouser.com/ProductDetail/Epson-Timing/SG5032CAN-25.000000M-TJGA3?qs=6J2kD0vu%2F2UTKuQJNmHNTw%3D%3D
VABO | 4 | 74CBTLV3126PW,118 | bus switch 4x | 14,00 Kč | 56,00 Kč | https://cz.mouser.com/ProductDetail/Nexperia/74CBTLV3126PW118?qs=jquClx72t9AHVJOkpgZFFw%3D%3D
VABO | 1 | 74AHC00PW | 4xNAND | 10,00 Kč | 10,00 Kč | https://cz.mouser.com/ProductDetail/Nexperia/74AHC00PW-Q100J?qs=5XOdhvmYM0MxkByL6vy0aA%3D%3D
VABO | 4 | BSS138 | mosfet n, SOT-23 | 1,00 Kč | 4,00 Kč | https://www.tme.eu/cz/details/bss138-tp/tranzistory-s-kanalem-n-smd/micro-commercial-components/
VABO | 2 | AA4040LCGCK-AMT | Green side-view LED, PLCC2 | 16,00 Kč | 32,00 Kč | https://cz.mouser.com/ProductDetail/Kingbright/AA4040LCGCK-AMT?qs=amGC7iS6iy%252B6P2%252BdTiLV9w%3D%3D
VABO | 2 | AA4040SESK | Orange side-view LED, PLCC2 | 11,00 Kč | 22,00 Kč | https://cz.mouser.com/ProductDetail/Kingbright/AA4040SESK?qs=rY7msk5yxfakL8ejDgvfOw%3D%3D
VABO | 9 | CAY16-1001F4LF | resistor net 4x1k | 1,00 Kč | 9,00 Kč | https://cz.mouser.com/ProductDetail/Bourns/CAY16-1001F4LF?qs=UmpSLsh52mXZ1nJ1YNGPvg%3D%3D | https://www.tme.eu/cz/details/yc164-fr-071kl/rezistorove-site/yageo/
VABO | 1 | DS1093-01-BN40 CONNFLY | S-video connector miniDin-4, alt | 20,00 Kč | 20,00 Kč | https://www.tme.eu/cz/details/mdc-204e/konektory-mini-din/connfly/ds1093-01-bn40/
VABO | 1 | ICD15S13E4GV00LF | VGA connector | 35,00 Kč | 35,00 Kč | https://cz.mouser.com/ProductDetail/Amphenol-FCI/ICD15S13E4GV00LF?qs=XRaITl65jntmDA26LPPFrA%3D%3D | https://www.tme.eu/cz/details/icd15s13e4gv00lf/zastrcky-a-zasuvky-d-sub/amphenol-communications-solutions/
VABO | 1 | 1503 07 LUMBERG | Jack 3.5mm stereo, no switch | 28,00 Kč | 28,00 Kč | https://www.tme.eu/cz/details/1503-07/konektory-jack/lumberg/1503-07/
VABO | 1 | W6100L | Wiznet hard-wired tcp/ip, LQFP48 | 99,00 Kč | 99,00 Kč | https://cz.mouser.com/ProductDetail/WIZnet/W6100L?qs=pUKx8fyJudARLmbJE2EKlA%3D%3D
VABO | 1 | RJMG1BD3B8K1ANR | RJ45 magjack | 72,00 Kč | 72,00 Kč | https://cz.mouser.com/ProductDetail/WIZnet/W6100L?qs=pUKx8fyJudARLmbJE2EKlA%3D%3D | https://www.tme.eu/cz/details/rjmg1bd3b8k1anr/konektory-rj/amphenol-communications-solutions/
VABO | 4 | GBK160808T-221Y-N | ferrite bead | 0,24 Kč | 0,96 Kč | https://cz.mouser.com/ProductDetail/Pulse-Electronics/GBK160808T-221Y-N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
VABO | 0 | LD-SP-2209 | speaker (very small) | 50,00 Kč | 0,00 Kč | https://www.tme.eu/cz/details/ld-sp-2209/reproduktory/loudity/
 | 1 | CMS-28528N-L152 | speaker (small round) | 83,00 Kč |  | https://cz.mouser.com/ProductDetail/CUI-Devices/CMS-28528N-L152?qs=Jwe3UnxISIZQi8VPnU78jQ%3D%3D
VABO | 2 | DS1023-2*10S21 | Pin-socket 2x10p | 9,00 Kč | 18,00 Kč | https://www.tme.eu/cz/details/zl262-20dg/konektory-hrebinky/connfly/ds1023-2-10s21/
VABO | 2 | DS1021-2*10SF11-B | Pin-header 2x10p | 4,30 Kč | 8,60 Kč | https://www.tme.eu/cz/details/zl202-20g/konektory-hrebinky/connfly/ds1021-2-10sf11-b/
VABO | 2 | SN74LVC1G11DBVR | 3-input AND gate, SOT-23-6 | 5,00 Kč | 10,00 Kč | https://cz.mouser.com/ProductDetail/Texas-Instruments/SN74LVC1G11DBVR?qs=nqigI8dpoHLbam7841cE5w%3D%3D | https://www.tme.eu/cz/details/sn74lvc1g11dbvr/hradla-invertory/texas-instruments/
VABO | 1 | LM4890MX/NOPB | audio amp 1W | 33,00 Kč | 33,00 Kč | https://cz.mouser.com/ProductDetail/Texas-Instruments/LM4890MX-NOPB?qs=QbsRYf82W3Fh0LrOOJ2vSA%3D%3D
VABO | 1 | 5MS3S102AM6QE | Switch slide 3-pos ON-OFF-ON | 28,00 Kč | 28,00 Kč | https://www.tme.eu/cz/details/5ms3s102am6qe/posuvne-prepinace/
VABO | 1 | A6SN-4101 OMRON OCB | Switch 4xDIP | 19,00 Kč | 19,00 Kč | https://www.tme.eu/cz/details/a6sn-4101/prepinace-dip-switch/omron-ocb/
VABO | 2 | PTS645VM13SMTR92 LFS | Mikrospínač TACT; SPST-NO; pol: 2; 0,05A/12VDC; úhlové,THT??; není | 10,00 Kč | 20,00 Kč | https://www.tme.eu/cz/details/pts645vm13smtr92/mikrospinace-tact/c-k/pts645vm13smtr92-lfs/
VABO | 1 | 74AHCT573PW,118 | 8x latch | 13,00 Kč | 13,00 Kč | https://cz.mouser.com/ProductDetail/Nexperia/74AHCT573PW118?qs=P62ublwmbi8w1EdI1aXXbg%3D%3D
VABO | 1 | 74LVC2G02DP,125 | NOR gate 2x | 11,00 Kč | 11,00 Kč | https://cz.mouser.com/ProductDetail/Nexperia/74LVC2G02DP125?qs=me8TqzrmIYWiSMBpOBB%252Bsg%3D%3D
VABO | 1 | CRCW251210M0JNTHBC | Rezistor: thick film; SMD; 2512; 10MΩ; 1W; ±5%; -55÷155°C; 200ppm/°C | 2,30 Kč | 2,30 Kč | https://www.tme.eu/cz/details/crcw251210m0jnthbc/rezistory-smd/vishay/
VABO | 1 | 1206B102K202CT | Kondenzátor: keramický; 1nF; 2kV; X7R; ±10%; SMD; 1206; 1,25mm | 3,00 Kč | 3,00 Kč | https://www.tme.eu/cz/details/1206b102k202/kondenzatory-mlcc-smd/walsin/1206b102k202ct/
VABO | 29 | CL10A105KO8NNWC | 1uF/16V/0603 | 1,00 Kč | 29,00 Kč | https://cz.mouser.com/ProductDetail/Samsung-Electro-Mechanics/CL10A105KO8NNWC
 |  | celkem: |  |  | 3 063,82 Kč
 |  |  |  |  | €122.55

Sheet: Removed
Main | 0 | W65C22S6TQG-14 | VIA, tbd included in FPGA | 245,00 Kč | 0,00 Kč | https://cz.mouser.com/ProductDetail/Western-Design-Center-WDC/W65C22S6TQG-14?qs=9lcNTSmDlCo21Y0m5rRDww%3D%3D
Main | 0 | SG5032CAN 16.000000M-TJGA | oscillator 16M | 29,00 Kč | 0,00 Kč | https://cz.mouser.com/ProductDetail/Epson-Timing/SG5032CAN-16.000000M-TJGA0?qs=MyNHzdoqoQL1oatJdxkATQ%3D%3D
Main | 0 | 93LC56BT-I/SN | EEPROM for FTDI | 8,00 Kč | 0,00 Kč | https://cz.mouser.com/ProductDetail/Microchip-Technology-Atmel/93LC56BT-I-SN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
Main | 0 | ABM3-12.000MHZ-D2Y-T | crystal 12MHz, 5x3mm | 11,00 Kč | 0,00 Kč | https://cz.mouser.com/ProductDetail/ABRACON/ABM3-12.000MHZ-D2Y-T?qs=ihRgKfnEsN4a%252Bhdo6LkcSg%3D%3D
Main | 0 | AB38T-32.768KHZ | crystal 32.768kHz, THT | 3,80 Kč | 0,00 Kč | https://cz.mouser.com/ProductDetail/ABRACON/AB38T-32.768KHZ?qs=m%252BUhWDcpCfbdp9ovMbeW3g%3D%3D
Main | 0 | SD05C-7 | transil 5.5V, SOD3V3 | 10,00 Kč | 0,00 Kč | https://cz.farnell.com/diodes-inc/sd05c-7/tvs-diode-bidir-5-5v-640w-sod/dp/3945780?st=sd05
VABO | 0 | MD-40S | S-video connector miniDin-4 | 41,00 Kč | 0,00 Kč | https://cz.mouser.com/ProductDetail/CUI-Devices/MD-40S?qs=WyjlAZoYn51t2gfmSwkdjw%3D%3D
VABO | 0 | ICE5LP1K-SG48ITR | FPGA, QFN-48 --- for AURA | 114,00 Kč | 0,00 Kč | https://cz.mouser.com/ProductDetail/Lattice/ICE5LP1K-SG48ITR?qs=ZwKJWZfDtNg6punXjA%252B0Og%3D%3D
VABO | 0 | ICE5LP2K-SG48ITR | FPGA, QFN-48 --- for AURA | 145,00 Kč | 0,00 Kč | https://cz.mouser.com/ProductDetail/Lattice/ICE5LP2K-SG48ITR?qs=ZwKJWZfDtNgAWzMHJRGDug%3D%3D
VABO | 0 | ICE5LP4K-SG48ITR | FPGA, QFN-48 --- for AURA | 181,00 Kč | 0,00 Kč | https://cz.mouser.com/ProductDetail/Lattice/ICE5LP4K-SG48ITR?qs=ZwKJWZfDtNj9QagUtdRf4g%3D%3D
VABO | 0 | SL 14 187 20 G | Pin-header 2x10p long | 97,00 Kč | 0,00 Kč | https://www.tme.eu/cz/details/sl14.187.20g/konektory-hrebinky/fischer-elektronik/sl-14-187-20-g/
VABO | 0 | ABM3-25.000MHZ-D2Y-T | crystal 25MHz for Wiznet | 13,00 Kč | 0,00 Kč | https://cz.mouser.com/ProductDetail/ABRACON/ABM3-25.000MHZ-D2Y-T?qs=ihRgKfnEsN6FZPAss%252Bj6lw%3D%3D

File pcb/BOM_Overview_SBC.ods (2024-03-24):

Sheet: SBC
Category | Qty | Type | Description/Note | Cena/ks | Cena/pol | Stock 12/23 | Stock 01/24 | Stock 2024-03-24 | Missing | Link | Line2 | Link3
Flash | 1 | W25Q128JVSIQ | SPI-Flash 128Mbit (16MB) | 41,00 Kč | 41,00 Kč | 0 | 0 | 0 | 1 | https://eu.mouser.com/ProductDetail/Winbond/W25Q128JVSIQ-TR?qs=qSfuJ%252Bfl%2Fd7vTyLA9kNdGw%3D%3D
Small Active | 1 | SG5032CAN 25.000000M-TJGA3 | oscillator 25MHz | 54,00 Kč | 54,00 Kč | 1 | 0 | 0 | 1 | https://cz.mouser.com/ProductDetail/Epson-Timing/SG5032CAN-25.000000M-TJGA3?qs=6J2kD0vu%2F2UTKuQJNmHNTw%3D%3D
Small Active | 1 | WM8524CGEDT | audio DAC | 62,00 Kč | 62,00 Kč | 1 | 0 | 0 | 1 | https://cz.mouser.com/ProductDetail/Cirrus-Logic/WM8524CGEDT-R?qs=G8wrXCBxhFtUpBbVDBGrKA%3D%3D
ASIC | 1 | W6100L | Wiznet hard-wired tcp/ip, LQFP48 | 99,00 Kč | 99,00 Kč | 1 | 0 | 0 | 1 | https://cz.mouser.com/ProductDetail/WIZnet/W6100L?qs=pUKx8fyJudARLmbJE2EKlA%3D%3D
Flash | 0 | W25Q512JVFIQ | SPI-Flash 512Mbit (64MB) in SOIC-16-300mil | 141,00 Kč | 0,00 Kč | 0 | 0 | 0 | 0 | https://cz.mouser.com/ProductDetail/Winbond/W25Q512JVFIQ?qs=l7cgNqFNU1heFREGHhA6IQ%3D%3D
FPGA | 2 | ICE40UP5K-SG48I | FPGA for VERA and AURA | 209,00 Kč | 418,00 Kč | 2 | 0 | 0 | 2 | https://cz.mouser.com/ProductDetail/Lattice/ICE40UP5K-SG48I?qs=Rp3RbKSfAt3UqOG1AN4%2FAg%3D%3D
ASIC | 1 | W65C816S6TQG-14 | cpu 16-bit | 274,00 Kč | 274,00 Kč | 1 | 0 | 0 | 1 | https://cz.mouser.com/ProductDetail/Western-Design-Center-WDC/W65C816S6TQG-14?qs=9lcNTSmDlCpDFNJ8GRf7eQ%3D%3D
Small Active | 1 | SG5032CAN 12.000000M-TJGA0 | oscillator 12M | 29,00 Kč | 29,00 Kč | 1 | 0 | 1 | 0 | https://cz.mouser.com/ProductDetail/Epson-Timing/SG5032CAN-12.000000M-TJGA0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
Small Active | 1 | LM4890MX/NOPB | audio amp 1W | 33,00 Kč | 33,00 Kč | 1 | 0 | 1 | 0 | https://cz.mouser.com/ProductDetail/Texas-Instruments/LM4890MX-NOPB?qs=QbsRYf82W3Fh0LrOOJ2vSA%3D%3D
Conn | 1 | RJMG1BD3B8K1ANR | RJ45 magjack | 72,00 Kč | 72,00 Kč | 1 |  | 1 | 0 | https://cz.mouser.com/ProductDetail/Amphenol-Commercial-Products/RJMG1BD3B8K1ANR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 | https://www.tme.eu/cz/details/rjmg1bd3b8k1anr/konektory-rj/amphenol-communications-solutions/
Conn | 1 | CMS-28528N-L152 | speaker (small round) | 83,00 Kč | 83,00 Kč | 1 |  | 1 | 0 | https://cz.mouser.com/ProductDetail/CUI-Devices/CMS-28528N-L152?qs=Jwe3UnxISIZQi8VPnU78jQ%3D%3D
Conn | 1 | DM1AA-SF-PEJ | Hirose SD-cage | 90,00 Kč | 90,00 Kč | 1 | 0 | 1 | 0 | https://cz.mouser.com/ProductDetail/Hirose-Connector/DM1AA-SF-PEJ82?qs=q%252B4FLHukgWBHaRKRr0HV%252Bw%3D%3D | https://www.tme.eu/cz/details/dm1aa-sf-pej-72/konektory-ke-kartam/hirose/dm1aa-sf-pej-72/
ASIC | 1 | FT2232HL | FTDI (LQFP64) | 173,00 Kč | 173,00 Kč | 1 | 0 | 1 | 0 | https://cz.mouser.com/ProductDetail/FTDI/FT2232HL-REEL?qs=D1%2FPMqvA100v7FHcEx164g%3D%3D | https://cz.farnell.com/ftdi/ft2232hl-r/usb-uart-fifo-2232-dual-64lqfp/dp/1697461?st=ft2232hl
FPGA | 1 | ICE40HX4K-TQ144 | FPGA for NORA | 211,00 Kč | 211,00 Kč | 2 | 1 | 1 | 0 | https://cz.mouser.com/ProductDetail/Lattice/iCE40HX4K-TQ144?qs=F9A14TELRMvGNTZXkNDuOw%3D%3D
Passive | 1 | DFE252010P-2R2M=P2 | 2,2uH | 5,00 Kč | 5,00 Kč | 1 | 2 | 2 | 0 | https://cz.mouser.com/ProductDetail/Murata-Electronics/DFE252010P-2R2M%3dP2?qs=KuGPmAKtFKVG0t9I2u6EsA%3D%3D
Passive | 1 | DFE252010P-1R0M=P2 | inductor 1uH/2.7A | 7,00 Kč | 7,00 Kč | 1 | 2 | 2 | 0 | https://cz.mouser.com/ProductDetail/Murata-Electronics/DFE252010P-1R0M%3dP2?qs=KuGPmAKtFKWP3jienGLHRQ%3D%3D
Conn | 1 | BAT-HLD-012-SMT | battery holder | 9,00 Kč | 9,00 Kč | 3 | 2 | 2 | 0 | https://cz.mouser.com/ProductDetail/Linx-Technologies/BAT-HLD-012-SMT?qs=Z0V%2FpEl%252BOGfZsSJil9WIXw%3D%3D
Small Active | 2 | SN74LVC2G17DBVR | driver | 10,00 Kč | 20,00 Kč | 3 | 1 | 2 | 0 | https://cz.mouser.com/ProductDetail/Texas-Instruments/SN74LVC2G17DBVR?qs=X1HXWTtiZ0RnstCufGEJxQ%3D%3D
Conn | 1 | JC-128 | Jack 3,5mm with switch | 11,00 Kč | 11,00 Kč | 0 | 2 | 2 | 0 | https://www.tme.eu/cz/details/jc-128/konektory-jack/
Flash | 2 | W25Q16JVSNIQ | SPI-Flash 16Mbit (2MB) | 12,00 Kč | 24,00 Kč | 3 | 2 | 2 | 0 | https://cz.mouser.com/ProductDetail/Winbond/W25Q16JVSNIQ?qs=qSfuJ%252Bfl%2Fd5tzEnNt99V4A%3D%3D
Conn | 1 | 1825058-1TE CONNECTIVITY | DIP-2 switch | 19,00 Kč | 19,00 Kč | 0 | 2 | 2 | 0 | https://www.tme.eu/cz/details/1825058-1/prepinace-dip-switch/te-connectivity/
ASIC | 1 | MCP7940N-I/SN | RTC | 21,00 Kč | 21,00 Kč | 2 | 1 | 2 | 0 | https://cz.mouser.com/ProductDetail/Microchip-Technology-Atmel/MCP7940N-I-SN?qs=o%2FJGMiCJeCOTsMP4nrR5Uw%3D%3D
Conn | 1 | USB4085-GF-A | Usb-c | 22,00 Kč | 22,00 Kč | 1 | 0 | 2 | 0 | https://cz.mouser.com/ProductDetail/GCT/USB4085-GF-A?qs=KUoIvG%2F9Ilba1bQOahfWjw%3D%3D
Conn | 1 | ICD15S13E4GV00LF | VGA connector | 35,00 Kč | 35,00 Kč | 1 | 0 | 2 | 0 | https://cz.mouser.com/ProductDetail/Amphenol-FCI/ICD15S13E4GV00LF?qs=XRaITl65jntmDA26LPPFrA%3D%3D | https://www.tme.eu/cz/details/icd15s13e4gv00lf/zastrcky-a-zasuvky-d-sub/amphenol-communications-solutions/
Small Active | 1 | MP2149GJ-Z | dc/dc | 45,00 Kč | 45,00 Kč | 2 | 1 | 2 | 0 | https://cz.mouser.com/ProductDetail/Monolithic-Power-Systems-MPS/MP2149GJ-Z?qs=pdFhdcvjjggGberHhgLWyQ%3D%3D
Conn | 2 | 5749180-1 | Minidin-6 for PS/2 | 49,00 Kč | 98,00 Kč | 3 | 2 | 2 | 0 | https://cz.mouser.com/ProductDetail/TE-Connectivity/5749180-1?qs=XlZqES4cpWZV2xh%2FjR2Ukw%3D%3D
SRAM | 1 | IS61WV20488FBLL-10TLI | 2Mx8 SRAM | 290,00 Kč | 290,00 Kč | 1 | 0 | 2 | 0 | https://cz.mouser.com/ProductDetail/ISSI/IS61WV20488FBLL-10TLI?qs=l7cgNqFNU1hrNZYLU3MwTg%3D%3D
Small Active | 1 | 24AA025E48T-I/OT | EEPROM 2K, 256x8 1.8V Serial with EUI-48 | 7,80 Kč | 7,80 Kč | 0 | 8 | 3 | 0 | https://cz.mouser.com/ProductDetail/Microchip-Technology/24AA025E48T-I-OT?qs=GCDK0xhvQh4RRiPFFnzHdA%3D%3D | https://cz.farnell.com/microchip/24aa025e48t-i-ot/serial-eeprom-2kbit-400khz-sot/dp/1814891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 | https://www.tme.eu/cz/details/24aa025e48t-i_ot/pameti-eeprom-seriove/microchip-technology/
Small Active | 1 | 74AHC00PW | 4xNAND | 10,00 Kč | 10,00 Kč | 4 | 3 | 3 | 0 | https://cz.mouser.com/ProductDetail/Nexperia/74AHC00PW-Q100J?qs=5XOdhvmYM0MxkByL6vy0aA%3D%3D
Passive | 1 | R0141-2-100K | SR-PASSIVES trimmer pot 100k | 11,00 Kč | 11,00 Kč | 0 | 3 | 3 | 0 | https://www.tme.eu/cz/details/r0141-2-100k/potenciometry-jednootackove-tht/sr-passives/
Passive | 1 | CM8V-T1A-32.768kHz-9pF-20PPM-TA-QC | Crystal 32.768k, SMD | 15,00 Kč | 15,00 Kč | 0 |  | 3 | 0 | https://cz.mouser.com/ProductDetail/Micro-Crystal/CM8V-T1A-32.768kHz-9pF-20PPM-TA-QC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
Conn | 1 | DS1013-10RSIB CONNFLY | UEXT connector, 2x5 pin header angled | 3,70 Kč | 3,70 Kč | 0 | 4 | 4 | 0 | https://www.tme.eu/cz/details/zl231-10kg/konektory-idc/connfly/ds1013-10rsib/
Conn | 1 | 826631-2 TE CONNECTIVITY | lezaty pin hdr: Kolíková lišta; kolíkové; AMPMODU MOD II; vidlice; PIN: 2; 2,54mm | 6,20 Kč | 6,20 Kč | 0 | 4 | 4 | 0 | https://www.tme.eu/cz/details/826631-2/konektory-hrebinky/te-connectivity/
Small Active | 5 | SP0503BAHT | 3x transil 5.5V | 18,00 Kč | 90,00 Kč | 5 | 5 | 4 | 1 | https://cz.farnell.com/littelfuse/sp0503bahtg/esd-protection-device-5-5v-sot/dp/1827633?st=sp0503baht
Conn | 2 | SNES_SOCKET_90DEG | SNES connector, 90deg, aliexpress | 20,00 Kč | 40,00 Kč | 4 | 2 | 6 | 0 | https://www.aliexpress.com/item/32838396935.html
LED | 1 | AA4040SESK | Orange side-view LED, PLCC2 | 11,00 Kč | 11,00 Kč | 9 | 8 | 7 | 0 | https://cz.mouser.com/ProductDetail/Kingbright/AA4040SESK?qs=rY7msk5yxfakL8ejDgvfOw%3D%3D
LED | 2 | AA4040LCGCK-AMT | Green side-view LED, PLCC2 | 16,00 Kč | 32,00 Kč | 7 | 5 | 7 | 0 | https://cz.mouser.com/ProductDetail/Kingbright/AA4040LCGCK-AMT?qs=amGC7iS6iy%252B6P2%252BdTiLV9w%3D%3D
Conn | 1 | PTS645VM13SMTR92 LFS | Mikrospínač TACT; SPST-NO; pol: 2; 0,05A/12VDC; úhlové,THT??; není | 10,00 Kč | 10,00 Kč | 9 | 8 | 8 | 0 | https://www.tme.eu/cz/details/pts645vm13smtr92/mikrospinace-tact/c-k/pts645vm13smtr92-lfs/ | https://cz.mouser.com/ProductDetail/CK/PTS645VM13SMTR92LFS?qs=%252B1mt6%252Bz2kvyajIXwbqsx1g%3D%3D
Passive | 1 | CRCW251210M0JNTHBC | Rezistor: thick film; SMD; 2512; 10MΩ; 1W; ±5%; -55÷155°C; 200ppm/°C | 2,30 Kč | 2,30 Kč |  | 9 | 9 | 0 | https://www.tme.eu/cz/details/crcw251210m0jnthbc/rezistory-smd/vishay/
Passive | 1 | 1206B102K202CT | Kondenzátor: keramický; 1nF; 2kV; X7R; ±10%; SMD; 1206; 1,25mm | 3,00 Kč | 3,00 Kč |  | 9 | 9 | 0 | https://www.tme.eu/cz/details/1206b102k202/kondenzatory-mlcc-smd/walsin/1206b102k202ct/
Small Active | 1 | SN74LVC1G08DBVR | 2-input AND gate | 7,00 Kč | 7,00 Kč | 0 |  | 9 | 0 | https://cz.mouser.com/ProductDetail/Texas-Instruments/SN74LVC1G08DBVR?qs=8yeEWhuAOtNjtL049wSCoQ%3D%3D | https://cz.farnell.com/texas-instruments/sn74lvc1g08dbvr/ic-gate-single-2-input-5sot23/dp/3120596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 | https://www.tme.eu/cz/details/sn74lvc1g08dbvr/hradla-invertory/texas-instruments/
Passive | 8 | GBK160808T-221Y-N | ferrite bead | 0,24 Kč | 1,92 Kč | 20 | 12 | 10 | 0 | https://cz.mouser.com/ProductDetail/Pulse-Electronics/GBK160808T-221Y-N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
LED | 3 |  | green LED 0603 normal |  |  |  |  | 10 | 0
Passive | 7 | GRM21BC81C226ME44L | 22uF/16V/0805 | 10,00 Kč | 70,00 Kč | 15 | 8 | 11 | 0 | https://cz.mouser.com/ProductDetail/Murata-Electronics/GRM21BC81C226ME44L | https://www.tme.eu/cz/details/grm21bc81c226me44l/kondenzatory-mlcc-smd/murata/
Small Active | 4 | 74CBTLV3126PW,118 | bus switch 4x | 14,00 Kč | 56,00 Kč | 6 |  | 12 | 0 | https://cz.mouser.com/ProductDetail/Nexperia/74CBTLV3126PW118?qs=jquClx72t9AHVJOkpgZFFw%3D%3D | https://cz.farnell.com/nexperia/74cbtlv3126pw-118/bus-switch-4-bit-tssop-14/dp/2445215?st=74cbtlv3126pw,118
Conn | 1 | DS1013-20SSIB1-B-0 CONNFLY | Zásuvka; IDC; vidlice; PIN: 20; přímý; THT; zlacený; 2,54mm | 9,30 Kč | 9,30 Kč | 0 | 4 | 14 | 0 | https://www.tme.eu/cz/details/zl231-20pg/konektory-idc/connfly/ds1013-20ssib1-b-0/
Passive | 8 | CL10A335KP8NNNC | 3.3uF/10V/0603 | 1,66 Kč | 13,28 Kč |  |  | 50 | 0 | https://cz.mouser.com/ProductDetail/Samsung-Electro-Mechanics/CL10A335KP8NNNC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
Small Active | 7 | BSS123, T2N7002AK,LM, BSS138 | mosfet n, SOT-23 | 5,00 Kč | 35,00 Kč | 10 | 10 | 94 | 0 | https://cz.mouser.com/ProductDetail/Toshiba/T2N7002AKLM?qs=pzVvXTvk9PzfX4hYglwZ9Q%3D%3D
Small Active | 6 | CUS10S30,H3F | schotky | 8,00 Kč | 48,00 Kč | 13 | 7 | 100 | 0 | https://cz.mouser.com/ProductDetail/Toshiba/CUS10S30H3F?qs=cW4DzVrAanO4Xm6ySrHr7g%3D%3D | https://cz.farnell.com/toshiba/cus10s30-h3f-t/schottky-diode-30v-1a-sod-323/dp/3872252?st=CUS10S30,H3F | https://www.tme.eu/cz/details/cus10s30/diody-schottky-smd/toshiba/cus10s30-h3f-t/
Passive | 60 | CL10A105KO8NNWC | 1uF/16V/0603 | 1,00 Kč | 60,00 Kč | 30 | 0 | 1000 | 0 | https://cz.mouser.com/ProductDetail/Samsung-Electro-Mechanics/CL10A105KO8NNWC

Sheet: notused
Main | 0 | LTST-S270GKT | green LED sideview 0603 | 6,00 Kč | 0,00 Kč | 7 | 0 | https://cz.mouser.com/ProductDetail/Lite-On/LTST-S270GKT?qs=sGAEpiMZZMvyj6n1w4pZD47FdTXqFYht4VAmSqE1GNY%3D
VABO | 0 | DS1021-2*10SF11-B | Pin-header 2x10p | 4,30 Kč | 0,00 Kč | 8 | 0 | https://www.tme.eu/cz/details/zl202-20g/konektory-hrebinky/connfly/ds1021-2-10sf11-b/
Main | 0 | EVQ-PUL02K | pushbutton | 14,00 Kč | 0,00 Kč | 1 | 0 | https://cz.mouser.com/ProductDetail/Panasonic/EVQ-PUL02K?qs=m7HfDvvzlLb0VFxnw%2FUN1w%3D%3D

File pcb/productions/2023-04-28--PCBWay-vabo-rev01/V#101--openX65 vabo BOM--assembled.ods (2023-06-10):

Source: | /home/jara/ownCloud/elektronika/Open65/pcb/vabo-rev01/openX65-vabo.kicad_sch
Date: | Pá 28. dubna 2023, 13:01:42
Tool: | Eeschema 6.0.11-3.fc36
Generator: | /usr/share/kicad/plugins/bom_csv_grouped_by_value_with_fp.py
Component Count: | 201
Ref | Qnty | Value | Cmp name | Footprint | Description | Vendor
C201, C202, C203, C205, C206, C211, C401, C402, C404, C405, C501, C601, C602, C603, C604, C606, C607, C608, C702, C703, C709, C711, C801, C802, C803, C804, C805, C807, C808, C809, C810, | 31 | 1u | C_Small | Capacitor_SMD:C_0603_1608Metric_Pad1.08x0.95mm_HandSolder | Unpolarized capacitor, small symbol
C302, C502, C719, C816, C817, | 5 | 22u/16V | C | Capacitor_SMD:C_0805_2012Metric_Pad1.18x1.45mm_HandSolder | Unpolarized capacitor
C403, C706, C707, | 3 | 4u7 | C_Small | Capacitor_SMD:C_0603_1608Metric_Pad1.08x0.95mm_HandSolder | Unpolarized capacitor, small symbol
C701, C806, | 2 | 3u3 | C_Small | Capacitor_SMD:C_0603_1608Metric_Pad1.08x0.95mm_HandSolder | Unpolarized capacitor, small symbol
C704, C705, | 2 | 2n7 | C_Small | Capacitor_SMD:C_0603_1608Metric_Pad1.08x0.95mm_HandSolder | Unpolarized capacitor, small symbol
C708, | 1 | 330n | C | Capacitor_SMD:C_0603_1608Metric_Pad1.08x0.95mm_HandSolder | Unpolarized capacitor
C811, C812, C815, | 3 | 100n | C_Small | Capacitor_SMD:C_0603_1608Metric_Pad1.08x0.95mm_HandSolder | Unpolarized capacitor, small symbol
C818, | 1 | 1nF/2kV | C | Capacitor_SMD:C_1206_3216Metric_Pad1.33x1.80mm_HandSolder | Unpolarized capacitor
D201, D601, | 2 | CUS10S30,H3F | D_Schottky | Diode_SMD:D_SOD-323_HandSoldering | Schottky diode
D203, D605, | 2 | LED_GREEN_0603 | LED | LED_SMD:LED_0603_1608Metric_Pad1.05x0.95mm_HandSolder | Light emitting diode
D501, | 1 | AA4040LCGCK-AMT | LED | ledplcc2:PLCC2_4x4mm | Light emitting diode
D502, D503, | 2 | AA4040SESK | LED | ledplcc2:PLCC2_4x4mm | Light emitting diode
FB801, FB802, FB803, FB804, | 4 | GBK160808T-221Y-N | FerriteBead_Small | Resistor_SMD:R_0603_1608Metric_Pad0.98x0.95mm_HandSolder | Ferrite bead, small symbol
J302, | 1 | DS1093-01-BN40 | Mini-DIN-4-SH | vera-module:DS1093-01-BN40 | 4-pin Mini-DIN connector
J303, | 1 | ICD15S13E4GV00LF | DB15_Female_HighDensity_MountingHoles | vera-module:ICD15S13E4GV00LF | 15-pin female D-SUB connector, High density (3 columns), Triple Row, Generic, VGA-connector, Mounting Hole
J401, | 1 | DM1AA-SF-PEJ | SD_Card_wSwitches | Connector_Card:SD_Hirose_DM1AA_SF_PEJ82 | SD Card Reader
J501, J502, | 2 | SOCK 2x10p 2,54mm | Conn_02x10_Odd_Even | Connector_PinSocket_2.54mm:PinSocket_2x10_P2.54mm_Vertical | Generic connector, double row, 02x10, odd/even pin numbering scheme (row 1 odd numbers, row 2 even numbers), script generated (kicad-library-utils/schlib/autogen/connector/)
J701, | 1 | Lumberg 1503-07 | AudioJack3 | Connector_Audio:Jack_3.5mm_Lumberg_1503_07_Horizontal | Audio Jack, 3 Poles (Stereo / TRS)
J702, J703, | 2 | PINS 1x2 | Conn_01x02 | Connector_PinHeader_2.54mm:PinHeader_1x02_P2.54mm_Vertical | Generic connector, single row, 01x02, script generated (kicad-library-utils/schlib/autogen/connector/)
J801, | 1 | RJMG1BD3B8K1ANR | RJ45_Amphenol_RJMG1BD3B8K1ANR | Connector_RJ:RJ45_Amphenol_RJMG1BD3B8K1ANR | 1 Port RJ45 Magjack Connector Through Hole 10/100 Base-T, AutoMDIX
Q201, Q401, Q601, Q701, | 4 | BSS138 | BSS123 | Package_TO_SOT_SMD:SOT-23 | 0.17A Id, 100V Vds, N-Channel MOSFET, SOT-23
R201, R203, R401, R402, R409, R410, R411, R412, R501, R502, R503, R504, R505, R506, R510, R511, R601, R602, R603, R604, R605, R606, R611, R704, R706, R708, R803, R806, R819, | 29 | 10k | R | Resistor_SMD:R_0603_1608Metric_Pad0.98x0.95mm_HandSolder | Resistor
R204, R205, R206, R809, R810, R811, R812, | 7 | 50R | R | Resistor_SMD:R_0603_1608Metric_Pad0.98x0.95mm_HandSolder | Resistor
R207, R303, R304, R507, R508, R509, R619, R807, R808, R818, | 10 | 470R | R | Resistor_SMD:R_0603_1608Metric_Pad0.98x0.95mm_HandSolder | Resistor
R208, R305, R607, | 3 | 0R | R | Resistor_SMD:R_0603_1608Metric_Pad0.98x0.95mm_HandSolder | Resistor
R301, R302, | 2 | 1k | R_Small | Resistor_SMD:R_0603_1608Metric_Pad0.98x0.95mm_HandSolder | Resistor, small symbol
R307, R308, | 2 | 75R | R_Small | Resistor_SMD:R_0603_1608Metric_Pad0.98x0.95mm_HandSolder | Resistor, small symbol
R309, R313, R317, | 3 | 510R | R_Small | Resistor_SMD:R_0603_1608Metric_Pad0.98x0.95mm_HandSolder | Resistor, small symbol
R310, R314, R318, | 3 | 910R | R_Small | Resistor_SMD:R_0603_1608Metric_Pad0.98x0.95mm_HandSolder | Resistor, small symbol
R311, R315, R319, | 3 | 2k | R_Small | Resistor_SMD:R_0603_1608Metric_Pad0.98x0.95mm_HandSolder | Resistor, small symbol
R312, R316, R320, | 3 | 4k3 | R_Small | Resistor_SMD:R_0603_1608Metric_Pad0.98x0.95mm_HandSolder | Resistor, small symbol
R321, R322, R821, | 3 | 820R | R | Resistor_SMD:R_0603_1608Metric_Pad0.98x0.95mm_HandSolder | Resistor
R323, R326, R329, | 3 | 27R | R_Small | Resistor_SMD:R_0603_1608Metric_Pad0.98x0.95mm_HandSolder | Resistor, small symbol
R324, R327, R330, | 3 | 160R | R_Small | Resistor_SMD:R_0603_1608Metric_Pad0.98x0.95mm_HandSolder | Resistor, small symbol
R325, R328, R331, | 3 | 150R | R_Small | Resistor_SMD:R_0603_1608Metric_Pad0.98x0.95mm_HandSolder | Resistor, small symbol
R403, R404, R405, R406, R407, R408, | 6 | 47k | R_Small | Resistor_SMD:R_0603_1608Metric_Pad0.98x0.95mm_HandSolder | Resistor, small symbol
R413, R707, | 2 | 4k7 | R | Resistor_SMD:R_0603_1608Metric_Pad0.98x0.95mm_HandSolder | Resistor
R701, R702, R709, R710, | 4 | 560R | R_Small | Resistor_SMD:R_0603_1608Metric_Pad0.98x0.95mm_HandSolder | Resistor, small symbol
R703, R705, | 2 | 39k | R | Resistor_SMD:R_0603_1608Metric_Pad0.98x0.95mm_HandSolder | Resistor
R801, | 1 | 12k | R | Resistor_SMD:R_0603_1608Metric_Pad0.98x0.95mm_HandSolder | Resistor
R802, | 1 | 300R | R | Resistor_SMD:R_0603_1608Metric_Pad0.98x0.95mm_HandSolder | Resistor
R804, | 1 | 10M | R | Resistor_SMD:R_2512_6332Metric_Pad1.40x3.35mm_HandSolder | Resistor
R813, R814, R815, R816, | 4 | 3R3 | R | Resistor_SMD:R_0603_1608Metric_Pad0.98x0.95mm_HandSolder | Resistor
R820, | 1 | 1k5 | R | Resistor_SMD:R_0603_1608Metric_Pad0.98x0.95mm_HandSolder | Resistor
RN301, RN302, RN303, RN304, RN305, RN306, RN307, RN308, RN309, | 9 | CAY16-1001F4LF | R_Pack04 | Resistor_SMD:R_Array_Convex_4x0603 | 4 resistor network, parallel topology
SW401, | 1 | PTS645VM13SMTR92 LFS | SW_Push_SH | switches:PTS645VM13SMTR92 LFS | Push button switch, generic, two pins
SW501, | 1 | A6SN-4101 | SW_DIP_x04 | Button_Switch_SMD:SW_DIP_SPSTx04_Slide_Omron_A6S-410x_W8.9mm_P2.54mm | 4x DIP Switch, Single Pole Single Throw (SPST) switch, small symbol
SW701, | 1 | 5MS3S102AM6QE | SW_SPDT_MSM | switches:Switch_5M_M6 | Switch, single pole double throw, center OFF position
U201, | 1 | ICE40UP5K-SG48ITR50 | ICE40UP5K-SG48ITR50 | Package_DFN_QFN:QFN-48-1EP_7x7mm_P0.5mm_EP5.3x5.3mm
U301, | 1 | THS7314D | THS7314D | Package_SO:SOIC-8_3.9x4.9mm_P1.27mm
U401, U603, | 2 | W25Q16JVSNIQ | W25Q32JVSS | Package_SO:SOIC-8_3.9x4.9mm_P1.27mm | 32Mb Serial Flash Memory, Standard/Dual/Quad SPI, SOIC-8
U402, U404, U504, U602, | 4 | 74CBTLV3126PW,118 | 74CBTLV3126PW,118 | Package_SO:TSSOP-14_4.4x5mm_P0.65mm
U403, | 1 | 74AHC00PW | 74HC00 | Package_SO:TSSOP-14_4.4x5mm_P0.65mm | quad 2-input NAND gate
U501, U502, | 2 | 74LVC1G11 | 74LVC1G11 | Package_TO_SOT_SMD:SOT-23-6_Handsoldering | Single AND 3 Input Gate, Low-Voltage CMOS
U503, | 1 | 74LVC2G02 | 74LVC2G02 | Package_SO:TSSOP-8_3x3mm_P0.65mm | Dual NOR Gate, Low-Voltage CMOS
U505, | 1 | 74AHCT573PW | 74AHCT573PW | Package_SO:TSSOP-20_4.4x6.5mm_P0.65mm
U601, | 1 | ICE5LP{1,2,4}K-SG48 | ICE5LP1K-SG48 | Package_DFN_QFN:QFN-48-1EP_7x7mm_P0.5mm_EP5.6x5.6mm | iCE40 Ultra FPGA, 1100 LUTs, 1.2V, 48-pin QFN
U701, U703 | 2 | WM8524CGEDT | WM8524CGEDT | Package_SO:TSSOP-16_4.4x5mm_P0.65mm
U702, | 1 | LM4890MX | LM4890MX | Package_SO:SOIC-8_3.9x4.9mm_P1.27mm
U801, | 1 | W6100L | W6100L | Package_QFP:LQFP-48_7x7mm_P0.5mm
X201, | 1 | SG5032CAN_25.000000M-TJGA3 | SG-5032CAN | Oscillator:Oscillator_SMD_SeikoEpson_SG8002LB-4Pin_5.0x3.2mm_HandSoldering | CMOS Clock Oscillator 1 to 75 MHz

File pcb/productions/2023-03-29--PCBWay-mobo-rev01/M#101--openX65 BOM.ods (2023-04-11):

Source: | D:\HOME\elektronika\Open65\pcb\mobo-rev01\open65.kicad_sch
Date: | 30/03/2023 13:13
Tool: | Eeschema (6.0.7)
Generator: | C:\Program Files\KiCad\6.0\bin\scripting\plugins/bom_csv_grouped_by_value.py
Component Count: | 173
Individual Components:
Item | Qty | Reference(s) | Value | LibPart | Footprint | Datasheet
 |  | BT401 | BAT-HLD-012-SMT | Device:Battery_Cell | Battery:BatteryHolder_LINX_BAT-HLD-012-SMT | ~
 |  | C201 | 1u | Device:C | Capacitor_SMD:C_0603_1608Metric_Pad1.08x0.95mm_HandSolder | ~
 |  | C202 | 1u | Device:C | Capacitor_SMD:C_0603_1608Metric_Pad1.08x0.95mm_HandSolder | ~
 |  | C203 | 1u | Device:C | Capacitor_SMD:C_0603_1608Metric_Pad1.08x0.95mm_HandSolder | ~
 |  | C204 | 1u | Device:C | Capacitor_SMD:C_0603_1608Metric_Pad1.08x0.95mm_HandSolder | ~
 |  | C301 | 1u | Device:C | Capacitor_SMD:C_0603_1608Metric_Pad1.08x0.95mm_HandSolder | ~
 |  | C302 | 1u | Device:C | Capacitor_SMD:C_0603_1608Metric_Pad1.08x0.95mm_HandSolder | ~
 |  | C303 | 1u | Device:C | Capacitor_SMD:C_0603_1608Metric_Pad1.08x0.95mm_HandSolder | ~
 |  | C304 | 1u | Device:C | Capacitor_SMD:C_0603_1608Metric_Pad1.08x0.95mm_HandSolder | ~
 |  | C305 | 1u | Device:C | Capacitor_SMD:C_0603_1608Metric_Pad1.08x0.95mm_HandSolder | ~
 |  | C306 | 1u | Device:C | Capacitor_SMD:C_0603_1608Metric_Pad1.08x0.95mm_HandSolder | ~
 |  | C307 | 1u | Device:C | Capacitor_SMD:C_0603_1608Metric_Pad1.08x0.95mm_HandSolder | ~
 |  | C308 | 1u | Device:C | Capacitor_SMD:C_0603_1608Metric_Pad1.08x0.95mm_HandSolder | ~
 |  | C309 | 1u | Device:C | Capacitor_SMD:C_0603_1608Metric_Pad1.08x0.95mm_HandSolder | ~
 |  | C310 | 1u | Device:C | Capacitor_SMD:C_0603_1608Metric_Pad1.08x0.95mm_HandSolder | ~
 |  | C311 | 1u | Device:C | Capacitor_SMD:C_0603_1608Metric_Pad1.08x0.95mm_HandSolder | ~
 |  | C312 | 1u | Device:C | Capacitor_SMD:C_0603_1608Metric_Pad1.08x0.95mm_HandSolder | ~
 |  | C314 | 1u | Device:C | Capacitor_SMD:C_0603_1608Metric_Pad1.08x0.95mm_HandSolder | ~
 |  | C315 | 1u | Device:C | Capacitor_SMD:C_0603_1608Metric_Pad1.08x0.95mm_HandSolder | ~
 |  | C316 | 1u | Device:C | Capacitor_SMD:C_0603_1608Metric_Pad1.08x0.95mm_HandSolder | ~
 |  | C317 | 100n | Device:C | Capacitor_SMD:C_0603_1608Metric_Pad1.08x0.95mm_HandSolder | ~
 |  | C401 | 1u | Device:C | Capacitor_SMD:C_0603_1608Metric_Pad1.08x0.95mm_HandSolder | ~
 |  | C402 | 6p | Device:C | Capacitor_SMD:C_0603_1608Metric_Pad1.08x0.95mm_HandSolder | ~
 |  | C403 | 6p | Device:C | Capacitor_SMD:C_0603_1608Metric_Pad1.08x0.95mm_HandSolder | ~
 |  | C404 | 1u | Device:C | Capacitor_SMD:C_0603_1608Metric_Pad1.08x0.95mm_HandSolder | ~
 |  | C405 | 1u | Device:C | Capacitor_SMD:C_0603_1608Metric_Pad1.08x0.95mm_HandSolder | ~
 |  | C406 | 1u | Device:C | Capacitor_SMD:C_0603_1608Metric_Pad1.08x0.95mm_HandSolder | ~
 |  | C501 | 100n | Device:C | Capacitor_SMD:C_0603_1608Metric_Pad1.08x0.95mm_HandSolder | ~
 |  | C502 | 3u3 | Device:C | Capacitor_SMD:C_0603_1608Metric_Pad1.08x0.95mm_HandSolder | ~
 |  | C503 | 3u3 | Device:C | Capacitor_SMD:C_0603_1608Metric_Pad1.08x0.95mm_HandSolder | ~
 |  | C504 | 3u3 | Device:C | Capacitor_SMD:C_0603_1608Metric_Pad1.08x0.95mm_HandSolder | ~
 |  | C507 | 1u | Device:C | Capacitor_SMD:C_0603_1608Metric_Pad1.08x0.95mm_HandSolder | ~
 |  | C508 | 1u | Device:C | Capacitor_SMD:C_0603_1608Metric_Pad1.08x0.95mm_HandSolder | ~
 |  | C509 | 1u | Device:C | Capacitor_SMD:C_0603_1608Metric_Pad1.08x0.95mm_HandSolder | ~
 |  | C510 | 1u | Device:C | Capacitor_SMD:C_0603_1608Metric_Pad1.08x0.95mm_HandSolder | ~
 |  | C601 | 1u | Device:C | Capacitor_SMD:C_0603_1608Metric_Pad1.08x0.95mm_HandSolder | ~
 |  | C602 | 1u | Device:C | Capacitor_SMD:C_0603_1608Metric_Pad1.08x0.95mm_HandSolder | ~
 |  | C701 | 22u/16V | Device:C | Capacitor_SMD:C_0805_2012Metric_Pad1.18x1.45mm_HandSolder | ~
 |  | C702 | 22u/16V | Device:C | Capacitor_SMD:C_0805_2012Metric_Pad1.18x1.45mm_HandSolder | ~
 |  | C703 | 22u/16V | Device:C | Capacitor_SMD:C_0805_2012Metric_Pad1.18x1.45mm_HandSolder | ~
 |  | D301 | CUS10S30,H3F | Device:D_Schottky | Diode_SMD:D_SOD-323_HandSoldering | ~
 |  | D302 | LTST-S270GKT | Device:LED | LED_SMD:LED_0603_1608Metric_Pad1.05x0.95mm_HandSolder | ~
 |  | D303 | SP0503BAHT | Power_Protection:SP0503BAHT | Package_TO_SOT_SMD:SOT-143 | http://www.littelfuse.com/~/media/files/littelfuse/technical%20resources/documents/data%20sheets/sp05xxba.pdf
 |  | D401 | CUS10S30,H3F | Device:D_Schottky | Diode_SMD:D_SOD-323_HandSoldering | ~
 |  | D402 | LTST-S270GKT | Device:LED | LED_SMD:LED_0603_1608Metric_Pad1.05x0.95mm_HandSolder | ~
 |  | D403 | LTST-S270EKT | Device:LED | LED_SMD:LED_0603_1608Metric_Pad1.05x0.95mm_HandSolder | ~
 |  | D404 | SP0503BAHT | Power_Protection:SP0503BAHT | Package_TO_SOT_SMD:SOT-143 | http://www.littelfuse.com/~/media/files/littelfuse/technical%20resources/documents/data%20sheets/sp05xxba.pdf
 |  | D405 | SP0503BAHT | Power_Protection:SP0503BAHT | Package_TO_SOT_SMD:SOT-143 | http://www.littelfuse.com/~/media/files/littelfuse/technical%20resources/documents/data%20sheets/sp05xxba.pdf
 |  | D501 | CUS10S30,H3F | Device:D_Schottky | Diode_SMD:D_SOD-323_HandSoldering | ~
 |  | D502 | LTST-S270GKT | Device:LED | LED_SMD:LED_0603_1608Metric_Pad1.05x0.95mm_HandSolder | ~
 |  | D504 | SP0503BAHT | Power_Protection:SP0503BAHT | Package_TO_SOT_SMD:SOT-143 | http://www.littelfuse.com/~/media/files/littelfuse/technical%20resources/documents/data%20sheets/sp05xxba.pdf
 |  | D601 | SP0503BAHT | Power_Protection:SP0503BAHT | Package_TO_SOT_SMD:SOT-143 | http://www.littelfuse.com/~/media/files/littelfuse/technical%20resources/documents/data%20sheets/sp05xxba.pdf
 |  | D602 | SP0503BAHT | Power_Protection:SP0503BAHT | Package_TO_SOT_SMD:SOT-143 | http://www.littelfuse.com/~/media/files/littelfuse/technical%20resources/documents/data%20sheets/sp05xxba.pdf
 |  | D701 | LTST-S270GKT | Device:LED | LED_SMD:LED_0603_1608Metric_Pad1.05x0.95mm_HandSolder | ~
 |  | F401 | SMD1206B050TF/15 | Device:Polyfuse | Fuse:Fuse_1206_3216Metric_Pad1.42x1.75mm_HandSolder | ~
 |  | F501 | SMD1206B050TF/15 | Device:Polyfuse | Fuse:Fuse_1206_3216Metric_Pad1.42x1.75mm_HandSolder | ~
 |  | F601 | SMD1206B050TF/15 | Device:Polyfuse | Fuse:Fuse_1206_3216Metric_Pad1.42x1.75mm_HandSolder | ~
 |  | FB301 | GBK160808T-221Y-N | Device:FerriteBead_Small | Resistor_SMD:R_0603_1608Metric_Pad0.98x0.95mm_HandSolder | ~
 |  | FB302 | GBK160808T-221Y-N | Device:FerriteBead_Small | Resistor_SMD:R_0603_1608Metric_Pad0.98x0.95mm_HandSolder | ~
 |  | FB501 | GBK160808T-221Y-N | Device:FerriteBead_Small | Resistor_SMD:R_0603_1608Metric_Pad0.98x0.95mm_HandSolder | ~
 |  | FB502 | GBK160808T-221Y-N | Device:FerriteBead_Small | Resistor_SMD:R_0603_1608Metric_Pad0.98x0.95mm_HandSolder | ~
 |  | J403 | SNES_Controller_Conn | :SNES_Controller_Conn_1 | snes:SNES_Controller_Conn_7p_90deg_P1Left
 |  | J404 | SNES_Controller_Conn | libsnes:SNES_Controller_Conn | snes:SNES_Controller_Conn_7p_90deg_P1Left
 |  | J501 | USB4085-GF-A | Connector:USB_C_Receptacle_USB2.0 | Connector_USB:USB_C_Receptacle_GCT_USB4085 | https://www.usb.org/sites/default/files/documents/usb_type-c.zip
 |  | J601 | PINS 2x10p 2,54mm | Connector_Generic:Conn_02x10_Odd_Even | Connector_PinHeader_2.54mm:PinHeader_2x10_P2.54mm_Vertical | ~
 |  | J602 | PINS 2x10p 2,54mm | Connector_Generic:Conn_02x10_Odd_Even | Connector_PinHeader_2.54mm:PinHeader_2x10_P2.54mm_Vertical | ~
 |  | J603 | Conn_01x14 | Connector_Generic:Conn_01x14 | Connector_PinSocket_2.54mm:PinSocket_1x14_P2.54mm_Vertical | ~
 |  | J604 | Conn_01x04 | Connector_Generic:Conn_01x04 | Connector_PinSocket_2.54mm:PinSocket_1x04_P2.54mm_Vertical_SMD_Pin1Left | ~
 |  | J605 | TE 5749180-1 | Connector:Mini-DIN-6 | mini-DIN:TE_5749180-1 | http://service.powerdynamics.com/ec/Catalog17/Section%2011.pdf
 |  | J606 | TE 5749180-1 | Connector:Mini-DIN-6 | mini-DIN:TE_5749180-1 | http://service.powerdynamics.com/ec/Catalog17/Section%2011.pdf
 |  | J702 | Conn_01x01 | Connector_Generic:Conn_01x01 | Connector_PinHeader_2.54mm:PinHeader_1x01_P2.54mm_Vertical | ~
 |  | J703 | Conn_01x01 | Connector_Generic:Conn_01x01 | Connector_PinHeader_2.54mm:PinHeader_1x01_P2.54mm_Vertical | ~
 |  | L701 | DFE252010P-2R2M=P2 | Device:L | Inductor_SMD:L_1008_2520Metric_Pad1.43x2.20mm_HandSolder | ~
 |  | L702 | DFE252010P-1R0M=P2 | Device:L | Inductor_SMD:L_1008_2520Metric_Pad1.43x2.20mm_HandSolder | ~
 |  | Q301 | BSS123 | Transistor_FET:BSS123 | Package_TO_SOT_SMD:SOT-23 | http://www.diodes.com/assets/Datasheets/ds30366.pdf
 |  | Q401 | BSS123 | Transistor_FET:BSS123 | Package_TO_SOT_SMD:SOT-23 | http://www.diodes.com/assets/Datasheets/ds30366.pdf
 |  | Q402 | BSS123 | Transistor_FET:BSS123 | Package_TO_SOT_SMD:SOT-23 | http://www.diodes.com/assets/Datasheets/ds30366.pdf
 |  | Q601 | BSS123 | Transistor_FET:BSS123 | Package_TO_SOT_SMD:SOT-23 | http://www.diodes.com/assets/Datasheets/ds30366.pdf
 |  | Q602 | BSS123 | Transistor_FET:BSS123 | Package_TO_SOT_SMD:SOT-23 | http://www.diodes.com/assets/Datasheets/ds30366.pdf
 |  | Q603 | BSS123 | Transistor_FET:BSS123 | Package_TO_SOT_SMD:SOT-23 | http://www.diodes.com/assets/Datasheets/ds30366.pdf
 |  | Q604 | BSS123 | Transistor_FET:BSS123 | Package_TO_SOT_SMD:SOT-23 | http://www.diodes.com/assets/Datasheets/ds30366.pdf
 |  | R201 | 10k | Device:R | Resistor_SMD:R_0603_1608Metric_Pad0.98x0.95mm_HandSolder | ~
 |  | R202 | 10k | Device:R | Resistor_SMD:R_0603_1608Metric_Pad0.98x0.95mm_HandSolder | ~
 |  | R203 | 10k | Device:R | Resistor_SMD:R_0603_1608Metric_Pad0.98x0.95mm_HandSolder | ~
 |  | R204 | 10k | Device:R | Resistor_SMD:R_0603_1608Metric_Pad0.98x0.95mm_HandSolder | ~
 |  | R205 | 10k | Device:R | Resistor_SMD:R_0603_1608Metric_Pad0.98x0.95mm_HandSolder | ~
 |  | R206 | 10k | Device:R | Resistor_SMD:R_0603_1608Metric_Pad0.98x0.95mm_HandSolder | ~
 |  | R207 | 10k | Device:R | Resistor_SMD:R_0603_1608Metric_Pad0.98x0.95mm_HandSolder | ~
 |  | R209 | 50R | Device:R | Resistor_SMD:R_0603_1608Metric_Pad0.98x0.95mm_HandSolder | ~
 |  | R211 | 50R | Device:R | Resistor_SMD:R_0603_1608Metric_Pad0.98x0.95mm_HandSolder | ~
 |  | R212 | 50R | Device:R | Resistor_SMD:R_0603_1608Metric_Pad0.98x0.95mm_HandSolder | ~
 |  | R214 | 10k | Device:R | Resistor_SMD:R_0603_1608Metric_Pad0.98x0.95mm_HandSolder | ~
 |  | R215 | 10k | Device:R | Resistor_SMD:R_0603_1608Metric_Pad0.98x0.95mm_HandSolder | ~
 |  | R301 | 10k | Device:R | Resistor_SMD:R_0603_1608Metric_Pad0.98x0.95mm_HandSolder | ~
 |  | R302 | 10k | Device:R | Resistor_SMD:R_0603_1608Metric_Pad0.98x0.95mm_HandSolder | ~
 |  | R303 | 10k | Device:R | Resistor_SMD:R_0603_1608Metric_Pad0.98x0.95mm_HandSolder | ~
 |  | R304 | 10k | Device:R | Resistor_SMD:R_0603_1608Metric_Pad0.98x0.95mm_HandSolder | ~
 |  | R305 | 10k | Device:R | Resistor_SMD:R_0603_1608Metric_Pad0.98x0.95mm_HandSolder | ~
 |  | R306 | 10k | Device:R | Resistor_SMD:R_0603_1608Metric_Pad0.98x0.95mm_HandSolder | ~
 |  | R307 | 470R | Device:R | Resistor_SMD:R_0603_1608Metric_Pad0.98x0.95mm_HandSolder | ~
 |  | R308 | 0R | Device:R | Resistor_SMD:R_0603_1608Metric_Pad0.98x0.95mm_HandSolder | ~
 |  | R309 | 0R | Device:R | Resistor_SMD:R_0603_1608Metric_Pad0.98x0.95mm_HandSolder | ~
 |  | R310 | 10k | Device:R | Resistor_SMD:R_0603_1608Metric_Pad0.98x0.95mm_HandSolder | ~
 |  | R311 | 2k2 | Device:R | Resistor_SMD:R_0603_1608Metric_Pad0.98x0.95mm_HandSolder | ~
 |  | R401 | 0R | Device:R | Resistor_SMD:R_0603_1608Metric_Pad0.98x0.95mm_HandSolder | ~
 |  | R402 | 0R | Device:R | Resistor_SMD:R_0603_1608Metric_Pad0.98x0.95mm_HandSolder | ~
 |  | R403 | 10k | Device:R | Resistor_SMD:R_0603_1608Metric_Pad0.98x0.95mm_HandSolder | ~
 |  | R404 | 10k | Device:R | Resistor_SMD:R_0603_1608Metric_Pad0.98x0.95mm_HandSolder | ~
 |  | R405 | 100R | Device:R | Resistor_SMD:R_0603_1608Metric_Pad0.98x0.95mm_HandSolder | ~
 |  | R406 | 100R | Device:R | Resistor_SMD:R_0603_1608Metric_Pad0.98x0.95mm_HandSolder | ~
 |  | R407 | 100R | Device:R | Resistor_SMD:R_0603_1608Metric_Pad0.98x0.95mm_HandSolder | ~
 |  | R408 | 100R | Device:R | Resistor_SMD:R_0603_1608Metric_Pad0.98x0.95mm_HandSolder | ~
 |  | R409 | 100R | Device:R | Resistor_SMD:R_0603_1608Metric_Pad0.98x0.95mm_HandSolder | ~
 |  | R410 | 100R | Device:R | Resistor_SMD:R_0603_1608Metric_Pad0.98x0.95mm_HandSolder | ~
 |  | R411 | 10k | Device:R | Resistor_SMD:R_0603_1608Metric_Pad0.98x0.95mm_HandSolder | ~
 |  | R412 | 10k | Device:R | Resistor_SMD:R_0603_1608Metric_Pad0.98x0.95mm_HandSolder | ~
 |  | R413 | 10k | Device:R | Resistor_SMD:R_0603_1608Metric_Pad0.98x0.95mm_HandSolder | ~
 |  | R414 | 10k | Device:R | Resistor_SMD:R_0603_1608Metric_Pad0.98x0.95mm_HandSolder | ~
 |  | R415 | 470R | Device:R | Resistor_SMD:R_0603_1608Metric_Pad0.98x0.95mm_HandSolder | ~
 |  | R416 | 470R | Device:R | Resistor_SMD:R_0603_1608Metric_Pad0.98x0.95mm_HandSolder | ~
 |  | R501 | 5k1 | Device:R | Resistor_SMD:R_0603_1608Metric_Pad0.98x0.95mm_HandSolder | ~
 |  | R502 | 5k1 | Device:R | Resistor_SMD:R_0603_1608Metric_Pad0.98x0.95mm_HandSolder | ~
 |  | R503 | 806k | Device:R | Resistor_SMD:R_0603_1608Metric_Pad0.98x0.95mm_HandSolder | ~
 |  | R504 | 12k | Device:R | Resistor_SMD:R_0603_1608Metric_Pad0.98x0.95mm_HandSolder | ~
 |  | R505 | 1k | Device:R | Resistor_SMD:R_0603_1608Metric_Pad0.98x0.95mm_HandSolder | ~
 |  | R506 | 10k | Device:R | Resistor_SMD:R_0603_1608Metric_Pad0.98x0.95mm_HandSolder | ~
 |  | R507 | 2k2 | Device:R | Resistor_SMD:R_0603_1608Metric_Pad0.98x0.95mm_HandSolder | ~
 |  | R508 | 10k | Device:R | Resistor_SMD:R_0603_1608Metric_Pad0.98x0.95mm_HandSolder | ~
 |  | R509 | 10k | Device:R | Resistor_SMD:R_0603_1608Metric_Pad0.98x0.95mm_HandSolder | ~
 |  | R510 | 0R | Device:R | Resistor_SMD:R_0603_1608Metric_Pad0.98x0.95mm_HandSolder | ~
 |  | R511 | 0R | Device:R | Resistor_SMD:R_0603_1608Metric_Pad0.98x0.95mm_HandSolder | ~
 |  | R512 | 0R | Device:R | Resistor_SMD:R_0603_1608Metric_Pad0.98x0.95mm_HandSolder | ~
 |  | R513 | 0R | Device:R | Resistor_SMD:R_0603_1608Metric_Pad0.98x0.95mm_HandSolder | ~
 |  | R514 | 0R | Device:R | Resistor_SMD:R_0603_1608Metric_Pad0.98x0.95mm_HandSolder | ~
 |  | R515 | 0R | Device:R | Resistor_SMD:R_0603_1608Metric_Pad0.98x0.95mm_HandSolder | ~
 |  | R516 | 0R | Device:R | Resistor_SMD:R_0603_1608Metric_Pad0.98x0.95mm_HandSolder | ~
 |  | R517 | 10k | Device:R | Resistor_SMD:R_0603_1608Metric_Pad0.98x0.95mm_HandSolder | ~
 |  | R518 | 0R | Device:R | Resistor_SMD:R_0603_1608Metric_Pad0.98x0.95mm_HandSolder | ~
 |  | R519 | 0R | Device:R | Resistor_SMD:R_0603_1608Metric_Pad0.98x0.95mm_HandSolder | ~
 |  | R520 | 470R | Device:R | Resistor_SMD:R_0603_1608Metric_Pad0.98x0.95mm_HandSolder | ~
 |  | R521 | 1k | Device:R | Resistor_SMD:R_0603_1608Metric_Pad0.98x0.95mm_HandSolder | ~
 |  | R601 | 100R | Device:R | Resistor_SMD:R_0603_1608Metric_Pad0.98x0.95mm_HandSolder | ~
 |  | R602 | 100R | Device:R | Resistor_SMD:R_0603_1608Metric_Pad0.98x0.95mm_HandSolder | ~
 |  | R603 | 100R | Device:R | Resistor_SMD:R_0603_1608Metric_Pad0.98x0.95mm_HandSolder | ~
 |  | R604 | 100R | Device:R | Resistor_SMD:R_0603_1608Metric_Pad0.98x0.95mm_HandSolder | ~
 |  | R605 | 10k | Device:R | Resistor_SMD:R_0603_1608Metric_Pad0.98x0.95mm_HandSolder | ~
 |  | R606 | 10k | Device:R | Resistor_SMD:R_0603_1608Metric_Pad0.98x0.95mm_HandSolder | ~
 |  | R607 | 10k | Device:R | Resistor_SMD:R_0603_1608Metric_Pad0.98x0.95mm_HandSolder | ~
 |  | R608 | 10k | Device:R | Resistor_SMD:R_0603_1608Metric_Pad0.98x0.95mm_HandSolder | ~
 |  | R701 | 806k | Device:R | Resistor_SMD:R_0603_1608Metric_Pad0.98x0.95mm_HandSolder | ~
 |  | R702 | 182k | Device:R | Resistor_SMD:R_0603_1608Metric_Pad0.98x0.95mm_HandSolder | ~
 |  | R703 | 10R | Device:R | Resistor_SMD:R_0603_1608Metric_Pad0.98x0.95mm_HandSolder | ~
 |  | R704 | 806k | Device:R | Resistor_SMD:R_0603_1608Metric_Pad0.98x0.95mm_HandSolder | ~
 |  | R705 | 825k | Device:R | Resistor_SMD:R_0603_1608Metric_Pad0.98x0.95mm_HandSolder | ~
 |  | R706 | 10R | Device:R | Resistor_SMD:R_0603_1608Metric_Pad0.98x0.95mm_HandSolder | ~
 |  | R707 | 470R | Device:R | Resistor_SMD:R_0603_1608Metric_Pad0.98x0.95mm_HandSolder | ~
 |  | SW301 | EVQ-PUL02K | Switch:SW_Push | Button_Switch_SMD:Panasonic_EVQPUL_EVQPUC | ~
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

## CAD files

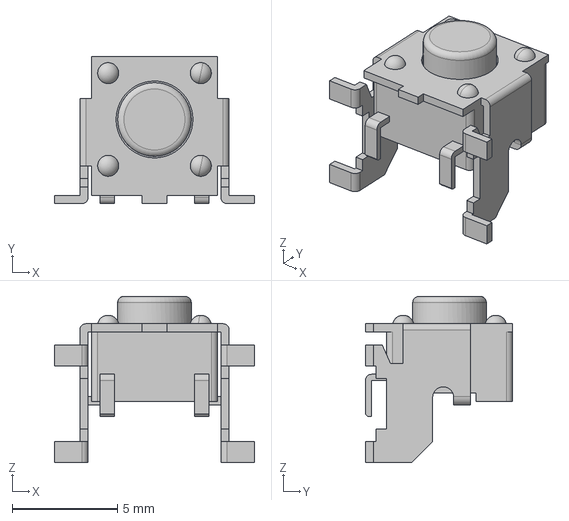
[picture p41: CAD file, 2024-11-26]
pcb/3dshapes/PTS645VN13SMTR92LFS.stp
9.50 x 7.00 x 7.90 mm

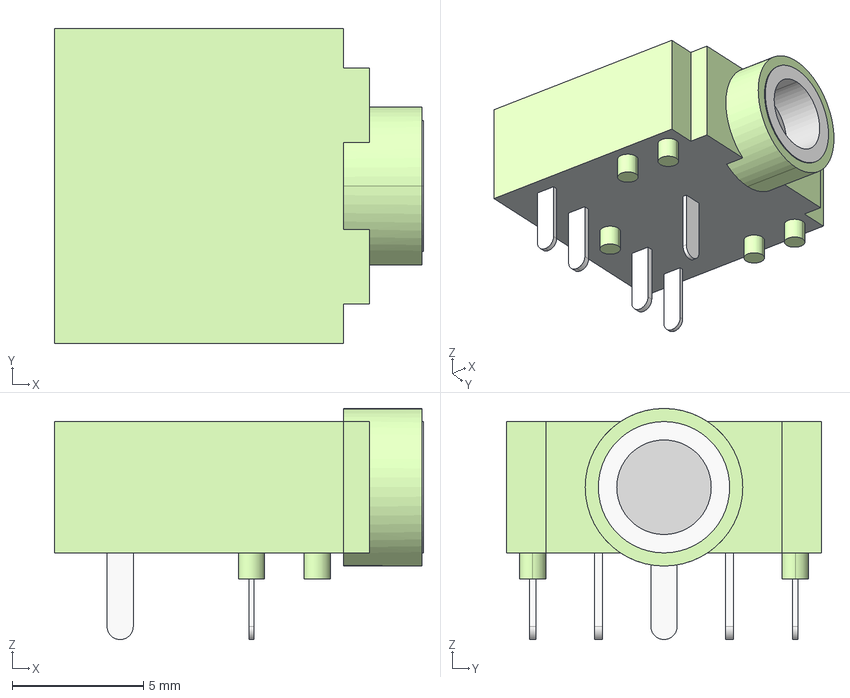
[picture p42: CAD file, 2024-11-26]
pcb/3dshapes/Same_Sky_SJ1-3525NG-GR.stp
14.1 x 12.0 x 8.80 mm

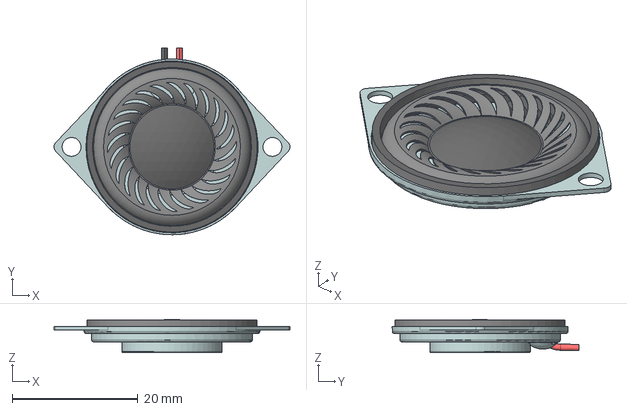
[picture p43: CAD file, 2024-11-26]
pcb/3dshapes/CMS-28528N-L152.stp
37.6 x 29.7 x 5.32 mm

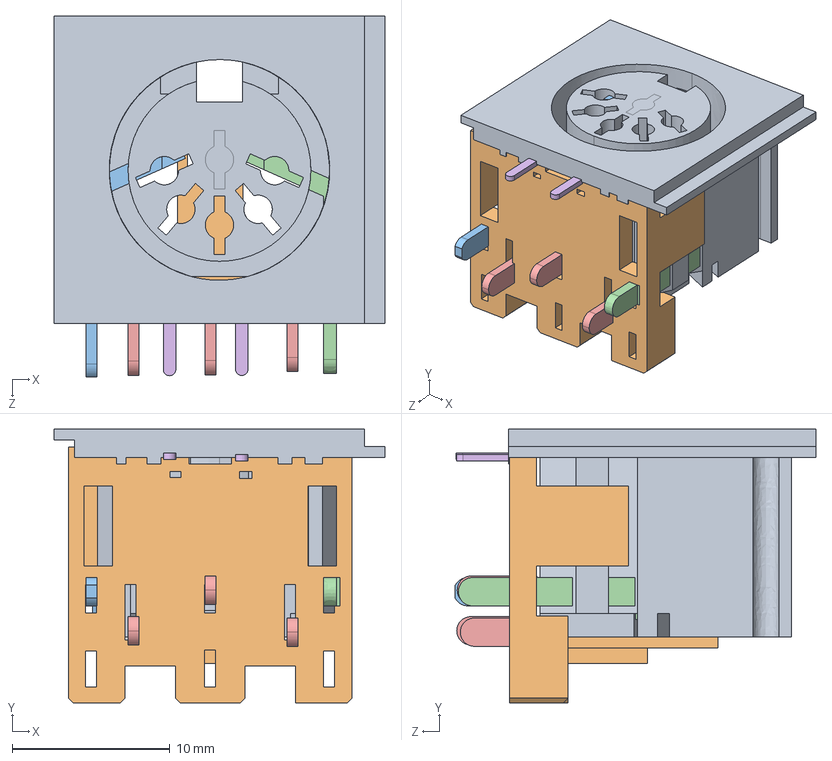
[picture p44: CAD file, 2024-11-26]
pcb/3dshapes/lumberg_0105_05.stp
21.0 x 17.4 x 22.9 mm
PRT0017
PRT0018
PRT0019
PRT0020
PRT0021
PRT0022
PRT0022_1
PRT0023
PRT0024

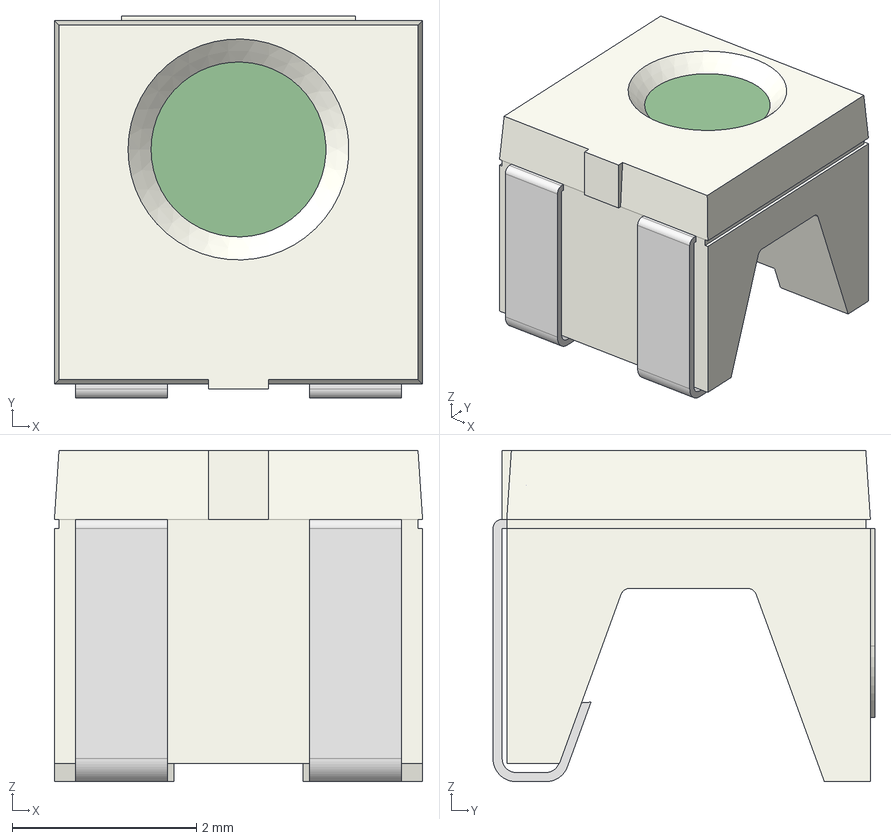
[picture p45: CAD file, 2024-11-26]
pcb/3dshapes/AA4040.stp
4.00 x 4.15 x 3.60 mm

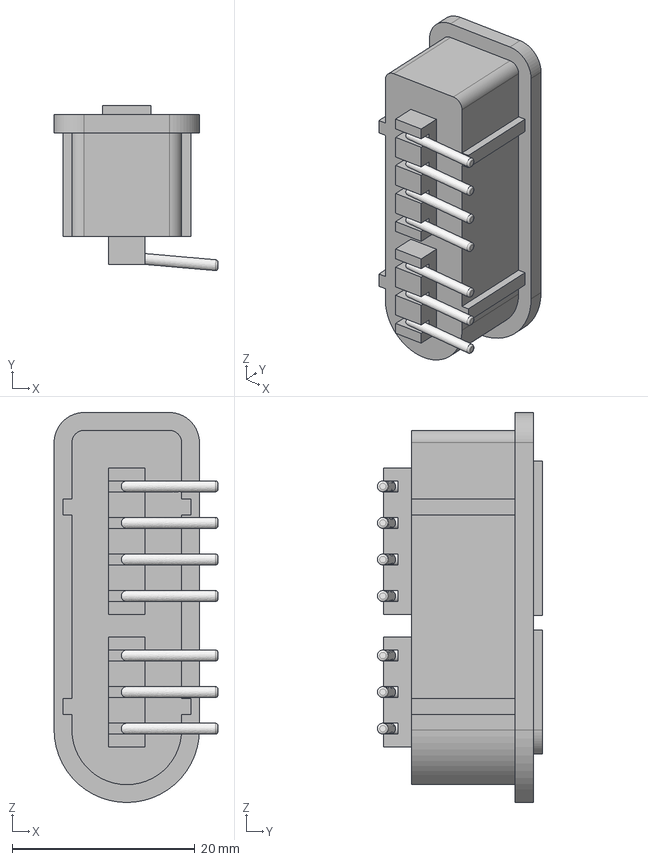
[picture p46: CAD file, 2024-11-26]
pcb/3dshapes/SNES_RA.stp
17.9 x 18.1 x 42.6 mm

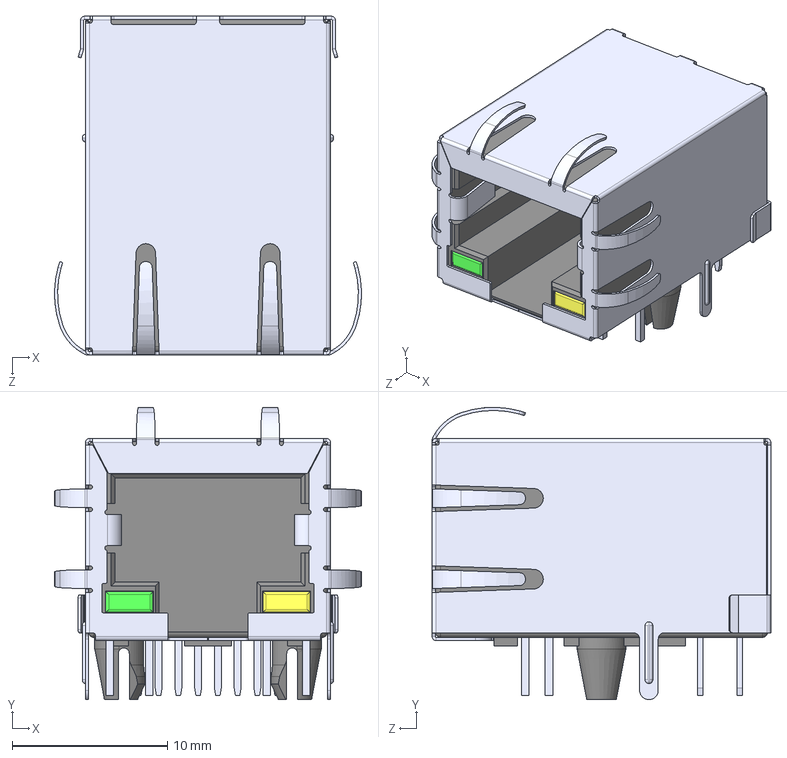
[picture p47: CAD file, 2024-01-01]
pcb/3dshapes/RJMG1BD3B8K1ANR--3DModel-STEP-56544.STEP
19.7 x 18.8 x 21.8 mm

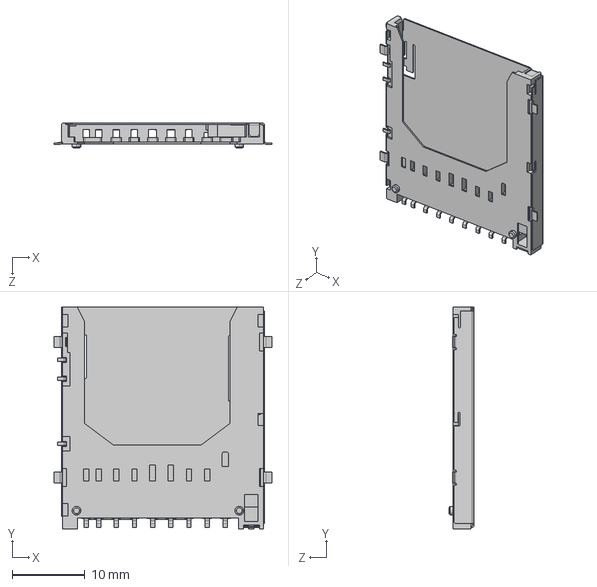
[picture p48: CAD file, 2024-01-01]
pcb/3dshapes/DM1AA-SF-PEJ.STEP
30.0 x 30.5 x 3.45 mm

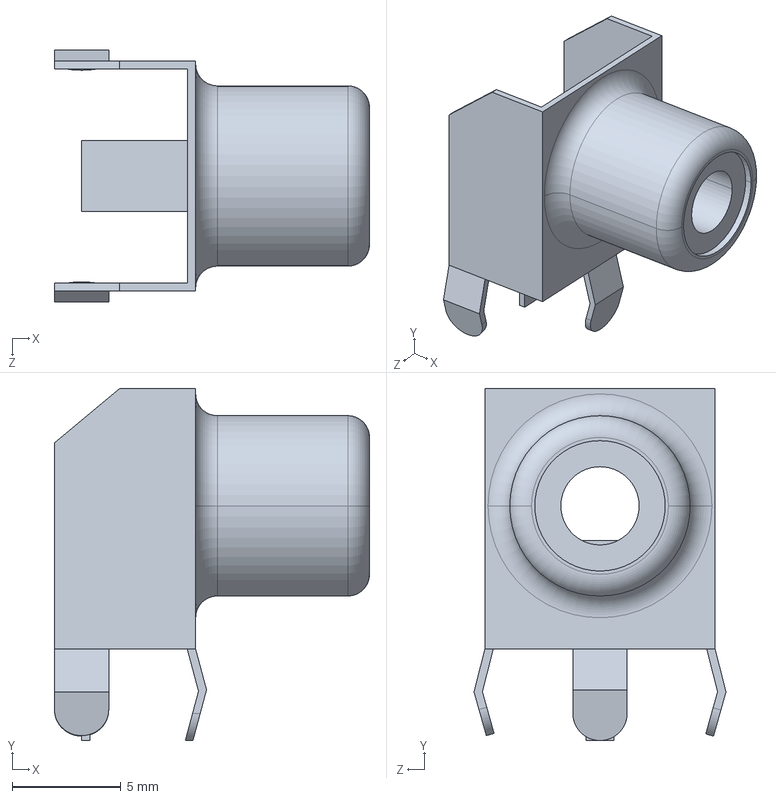
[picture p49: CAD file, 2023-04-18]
pcb/3dshapes/CUI_RCJ-014.step
14.5 x 16.2 x 11.6 mm

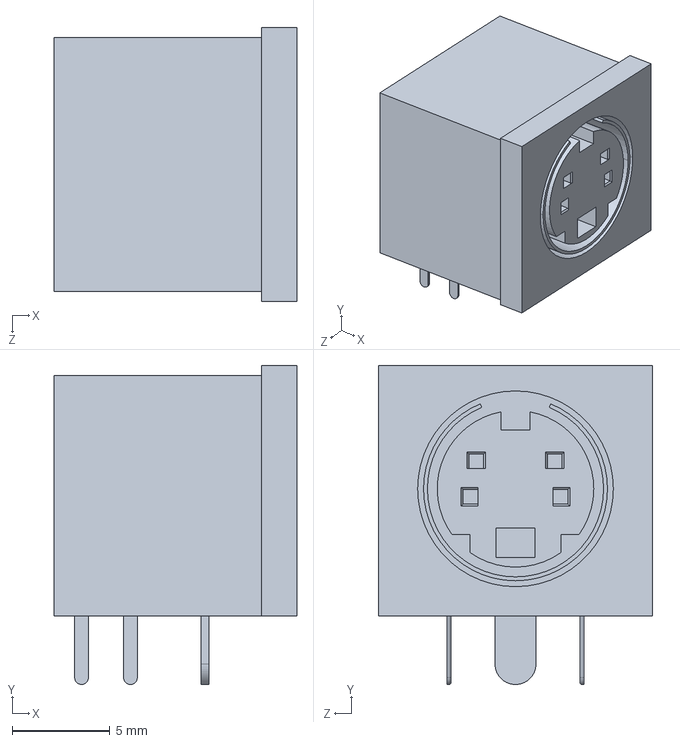
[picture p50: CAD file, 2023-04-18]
pcb/3dshapes/CUI_MD-40S.step
12.4 x 16.3 x 14.0 mm

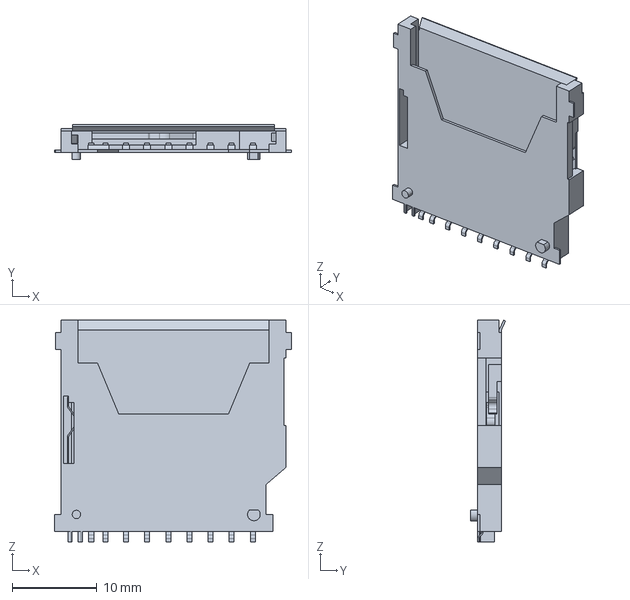
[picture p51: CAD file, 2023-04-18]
pcb/3dshapes/c-2041021-3-b-3d.stp
28.0 x 4.15 x 26.2 mm

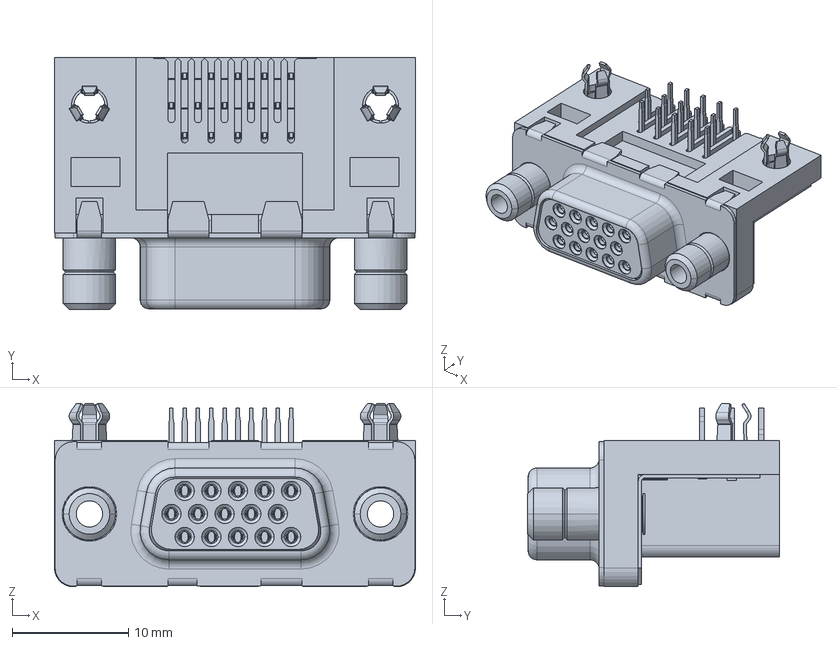
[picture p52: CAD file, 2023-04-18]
pcb/3dshapes/ICD15S13E4GV00LFc.stp
31.0 x 21.6 x 15.8 mm

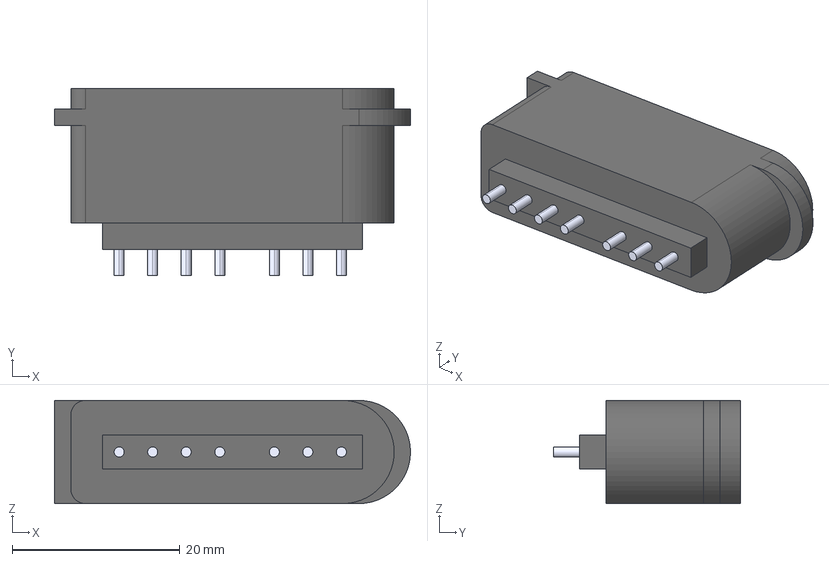
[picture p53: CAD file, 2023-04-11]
pcb/3dshapes/snes_connector_v1.STEP
42.4 x 22.4 x 12.3 mm
body_v1
pin18mm x 7

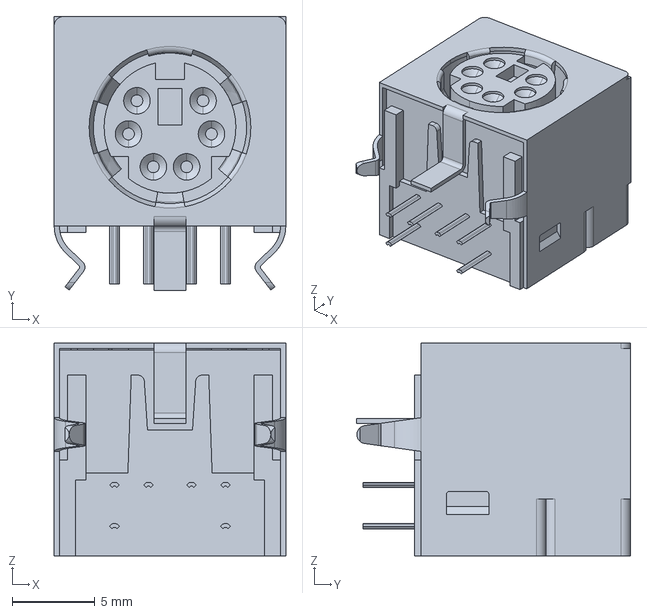
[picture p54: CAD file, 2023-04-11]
pcb/libminidin/5749180-1.step
14.0 x 16.5 x 12.8 mm

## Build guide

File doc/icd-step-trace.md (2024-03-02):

Instruction Tracing in 6502/65816 CPUs by a PC-based Debugger
==============================================================

    FPGA clk = 48MHz (1T = 20ns):
        ____      ____      ____      ____      ____      ____      ____
    ___|    |____|    |____|    |____|    |____|    |____|    |____|
        S0L       S1L       S2L       S3H       S4H       S5H
        .release_cs.        .setup_cs .                   .release_wr.
                (stopped)

    CPHI2 = 8MHz (125ns period) for the 65xx CPU:
    ___                               _____________________________
        |_____________________________|                             |__________

The CPU PHI2 clock can be also stopped at any time by this module.

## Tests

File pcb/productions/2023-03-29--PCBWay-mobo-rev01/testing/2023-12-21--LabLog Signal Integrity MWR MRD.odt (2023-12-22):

21.12.2023

Measuring complete stack, with coax probe, MWR and MRD probed on VABO:

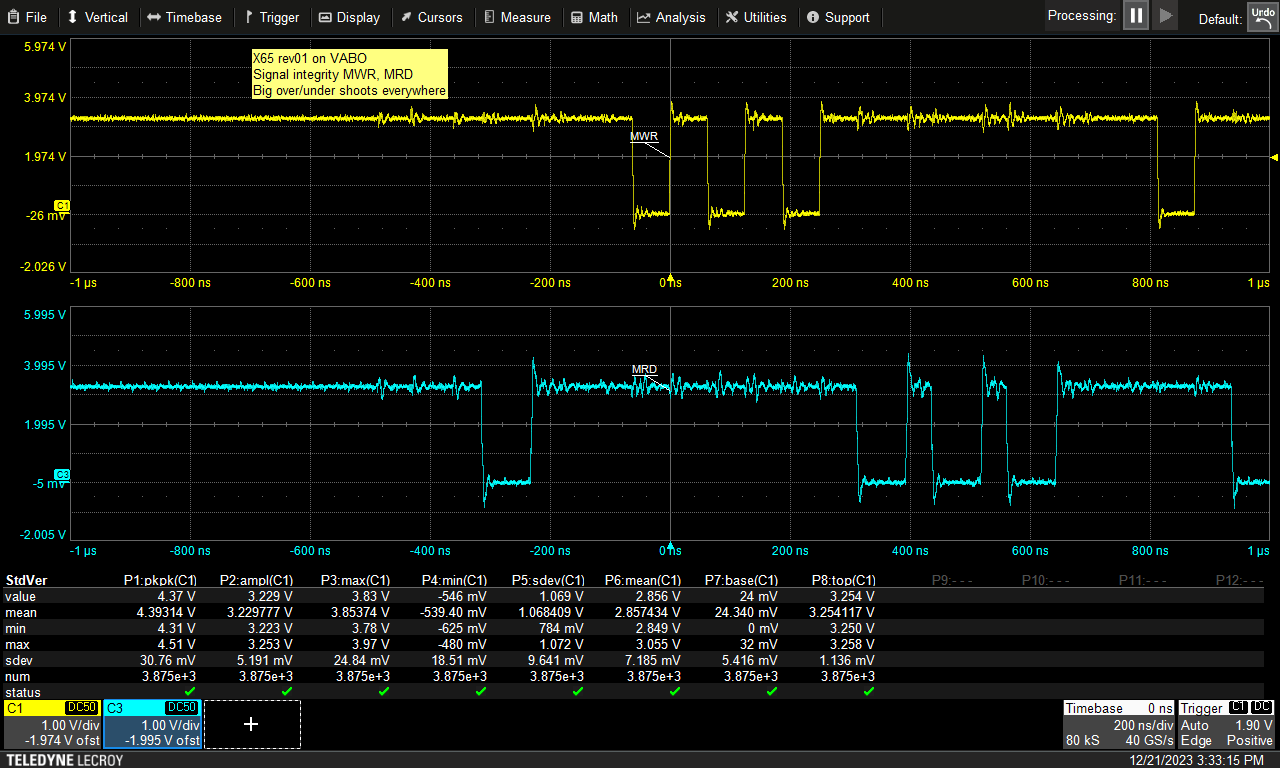
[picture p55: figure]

Edge speed is quite high:

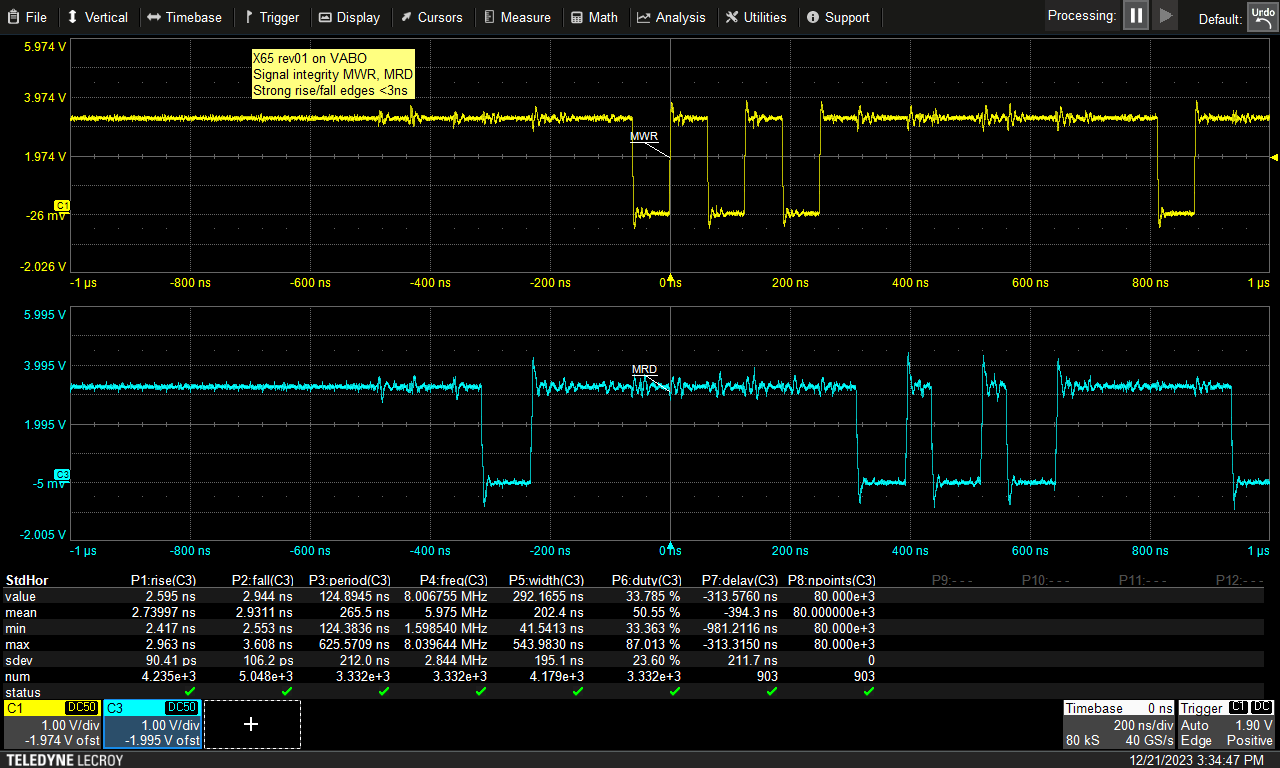
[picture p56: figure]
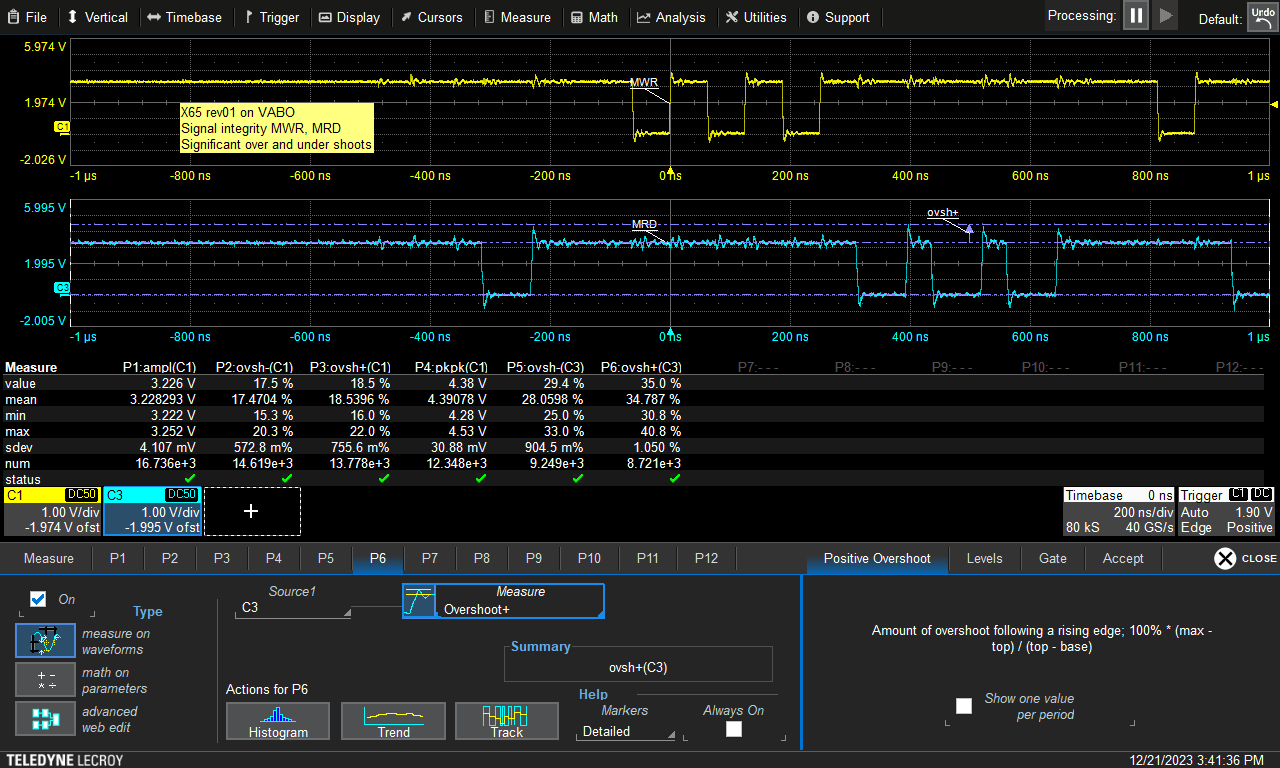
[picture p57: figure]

Without VABO – less loading much bigger overshoots!

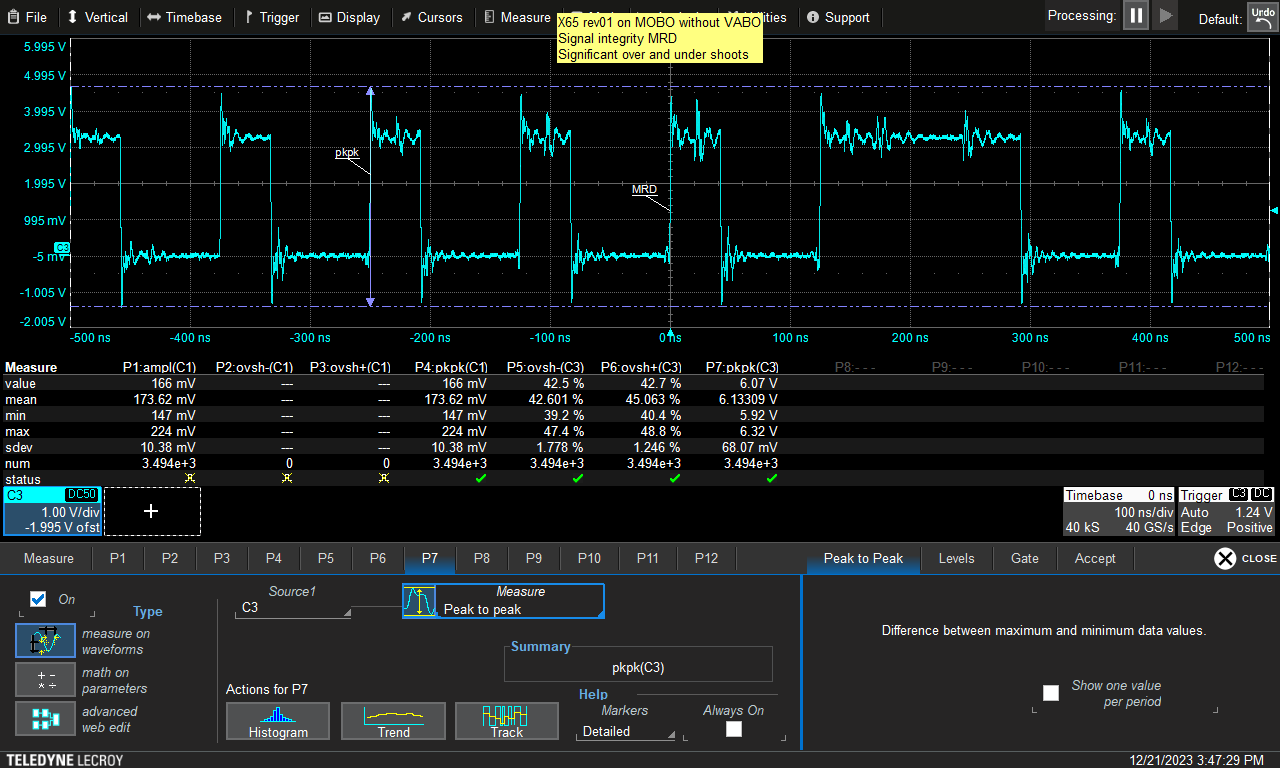
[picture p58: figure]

In detail:

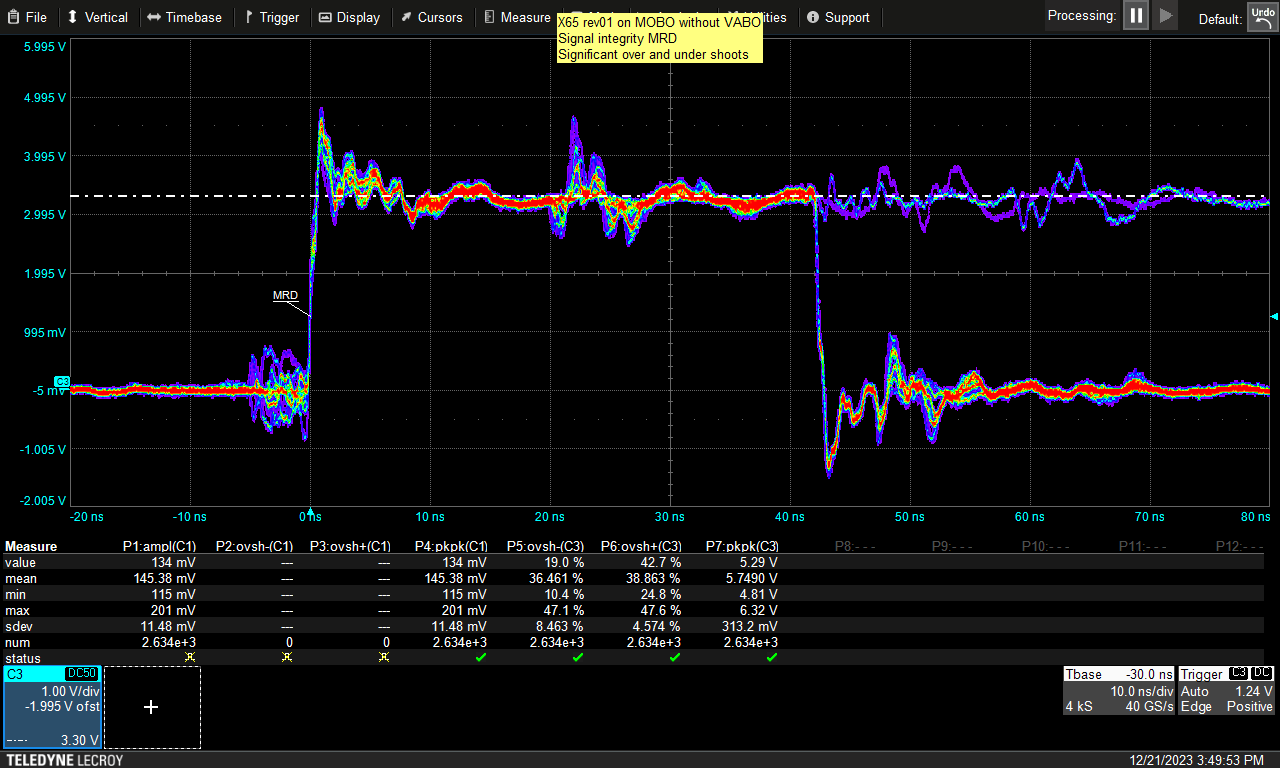
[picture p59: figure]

Rising edge in detail:

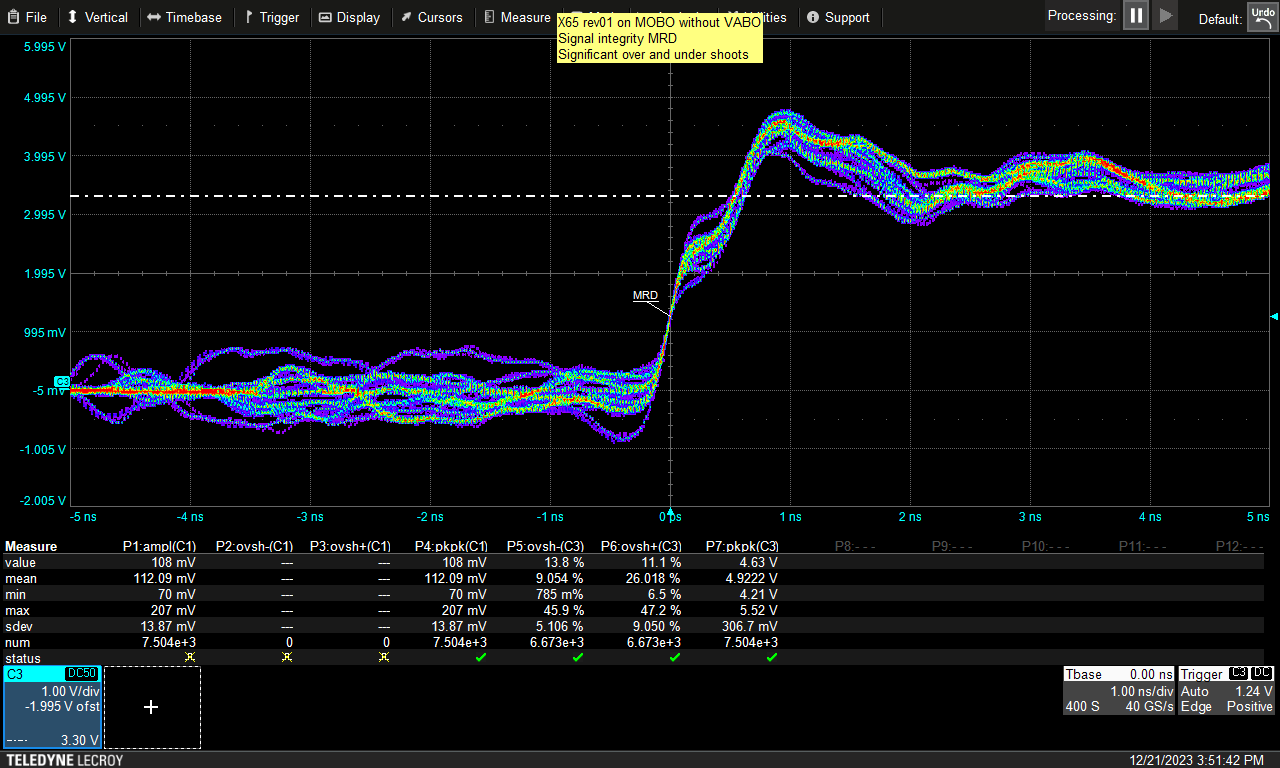
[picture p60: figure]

Same rising edge but with VABO loaded:

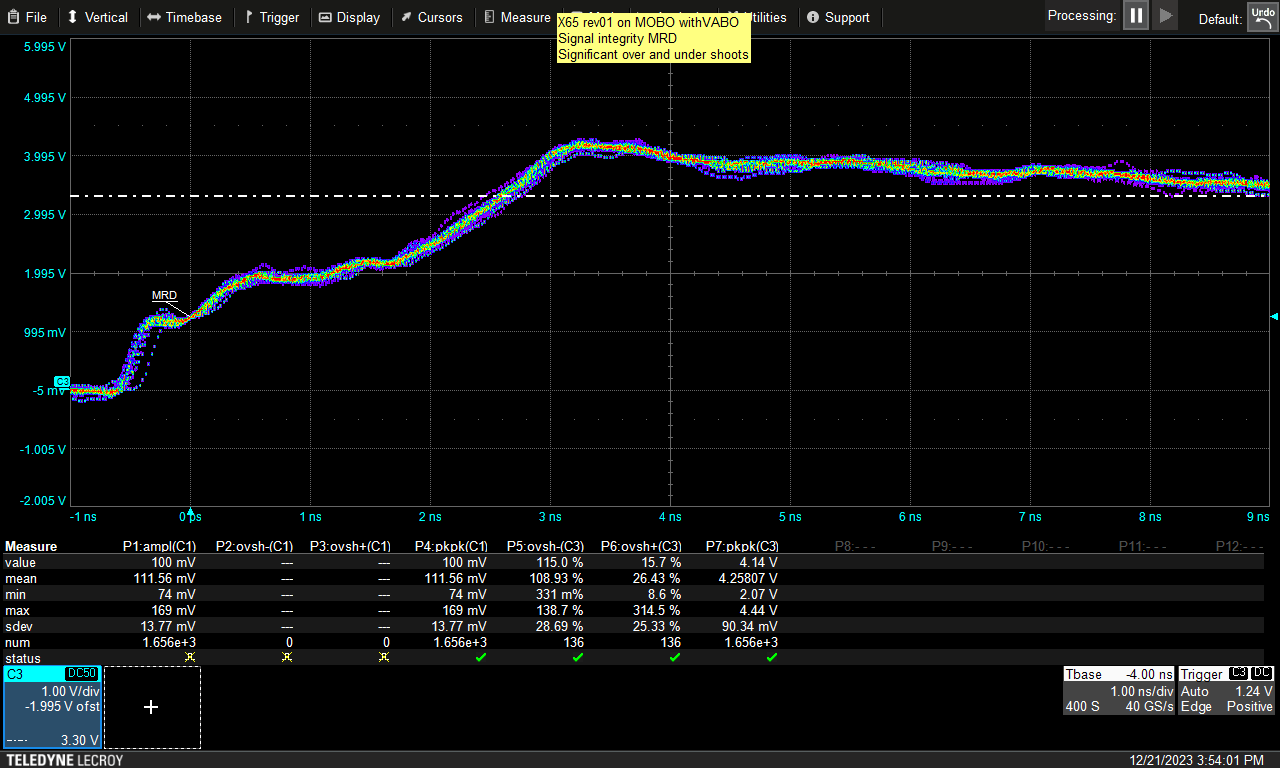
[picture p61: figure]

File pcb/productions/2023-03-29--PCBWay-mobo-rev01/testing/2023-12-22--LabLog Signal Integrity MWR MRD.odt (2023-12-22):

21.12.2023

Measuring complete stack, with coax probe, MWR and MRD probed on VABO:


Edge speed is quite high:


Without VABO – less loading much bigger overshoots!


In detail:


Rising edge in detail:


Same rising edge but with VABO loaded:


22.12.2023

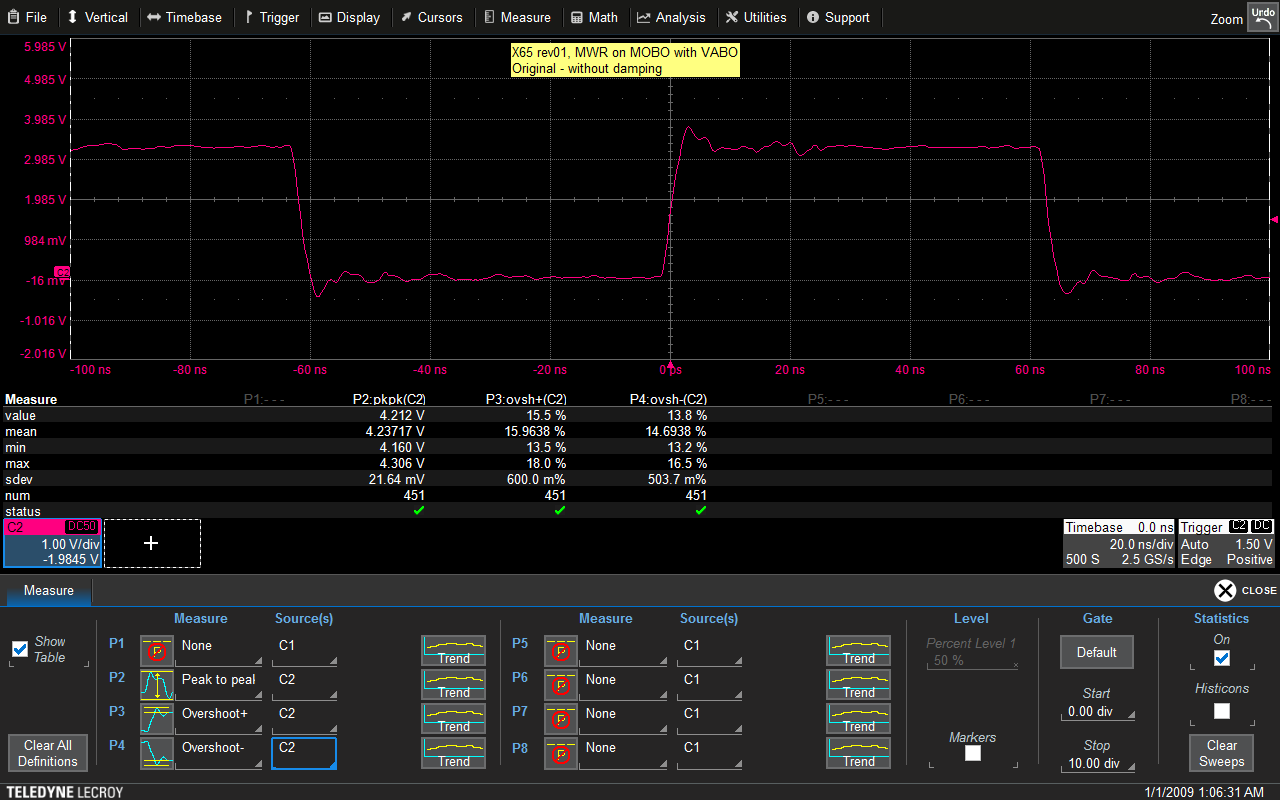
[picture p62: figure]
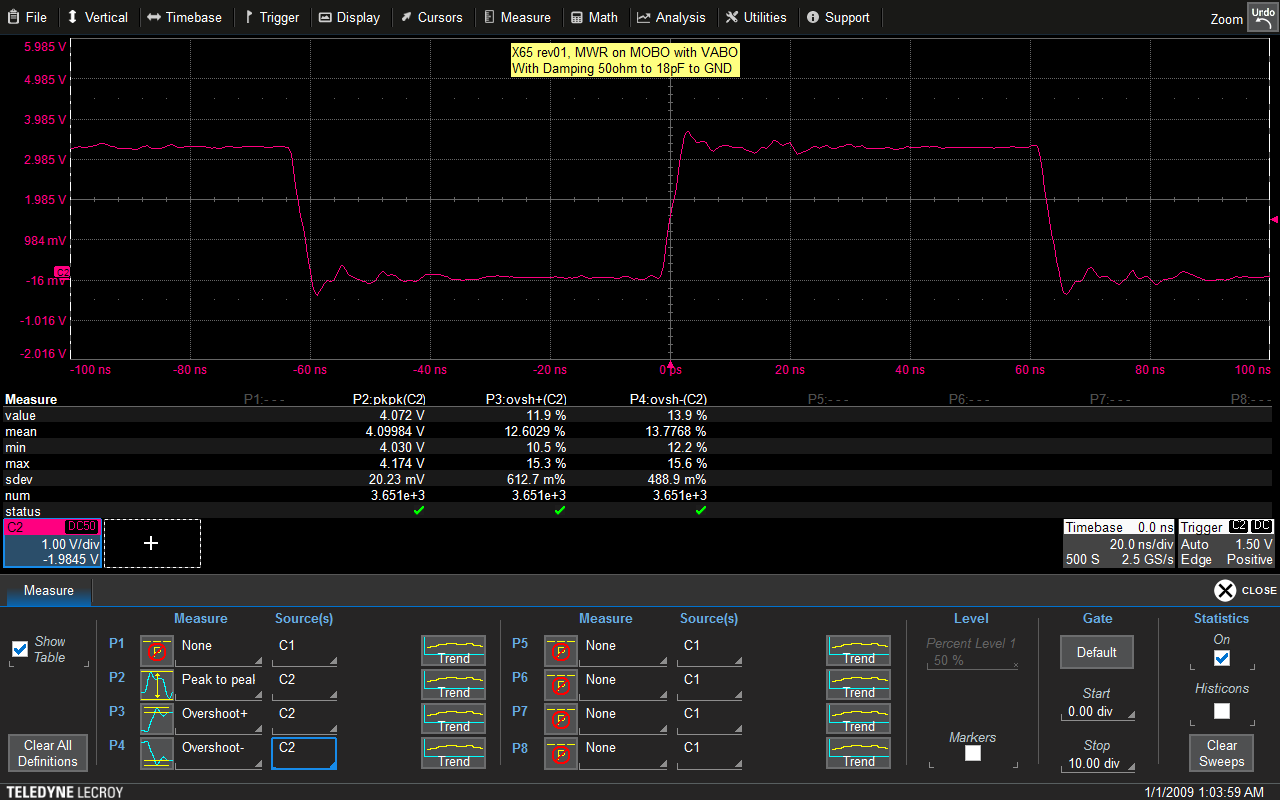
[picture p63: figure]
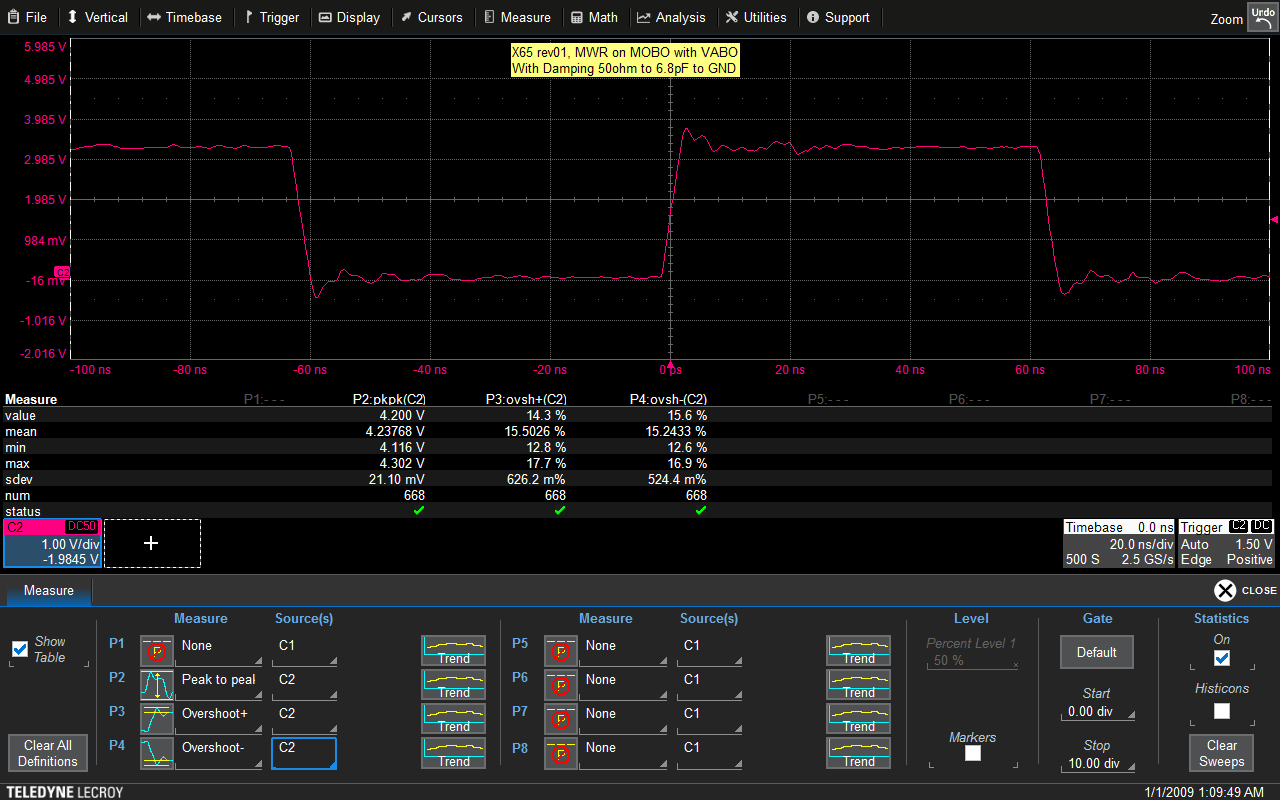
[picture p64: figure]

Damping network 50ohm+(7 to 18pF) does not help significantly!! (few percent points overshoot)

- Just better layout / 4 layer board could solve it !!??

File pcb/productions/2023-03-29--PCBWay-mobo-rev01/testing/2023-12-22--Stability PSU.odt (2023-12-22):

2023-12-22

Stability Measurement

3V3 at no Load:


3V3 at Load 100mA:


3V3 at 300mA load:


These are totally wrong!

Magnitude does not drop to zero! But rises after 1MHz.

Phase is around zero until 10kHz!

Alternate method: unit step 5mA 400mA (TTI Load)

3V3, coax probe:


1V2, no load:


Unit step from 5mA to 50mA at the 1V2:


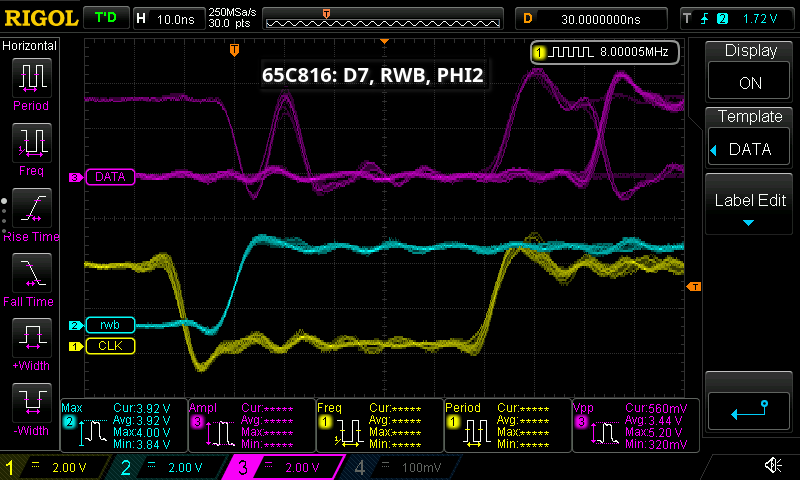
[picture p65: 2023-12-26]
pcb/productions/2023-03-29--PCBWay-mobo-rev01/testing/2023-12-25--CPU Data bus vs FPGA, D7, RWB, PHI2.png

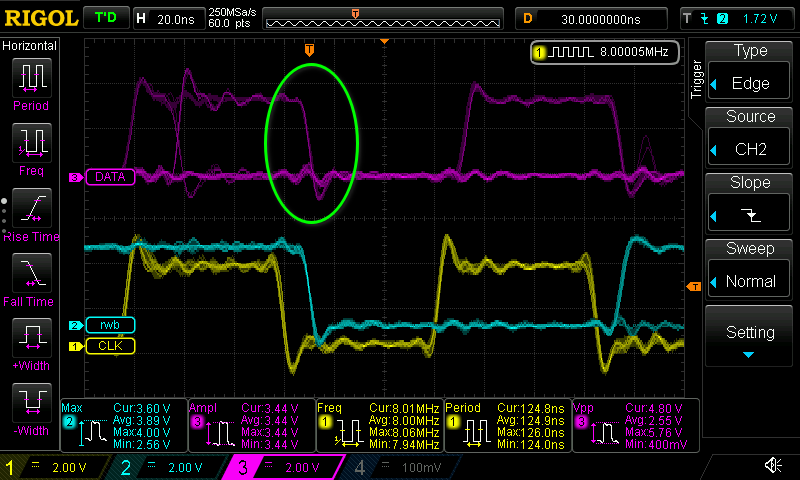
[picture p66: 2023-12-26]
pcb/productions/2023-03-29--PCBWay-mobo-rev01/testing/2023-12-25--B--CPU Data bus vs FPGA, D7, RWB, PHI2, read-to-write complete cycle.png

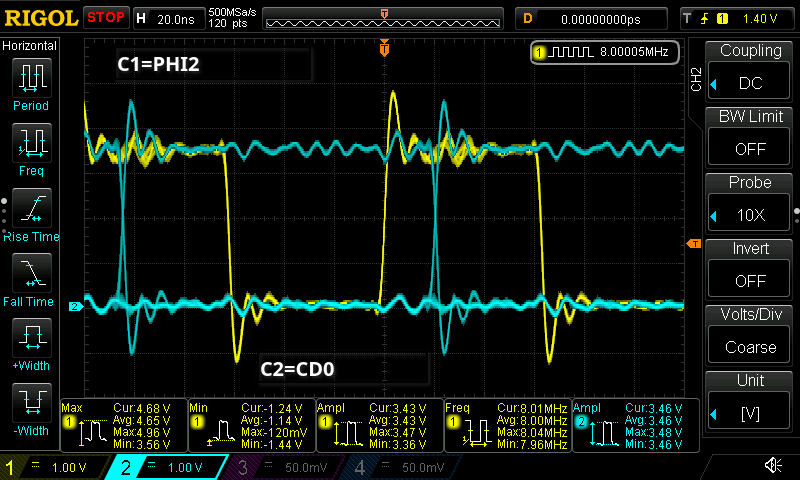
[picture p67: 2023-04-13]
pcb/productions/2023-03-29--PCBWay-mobo-rev01/testing/bus phi2 cd0.png

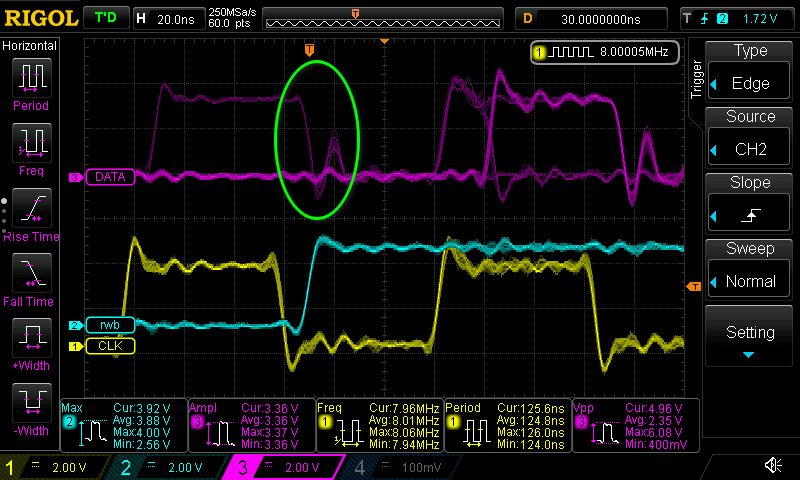
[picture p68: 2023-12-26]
pcb/productions/2023-03-29--PCBWay-mobo-rev01/testing/2023-12-25--B--CPU Data bus vs FPGA, D7, RWB, PHI2, write-to-read complete cycle.png

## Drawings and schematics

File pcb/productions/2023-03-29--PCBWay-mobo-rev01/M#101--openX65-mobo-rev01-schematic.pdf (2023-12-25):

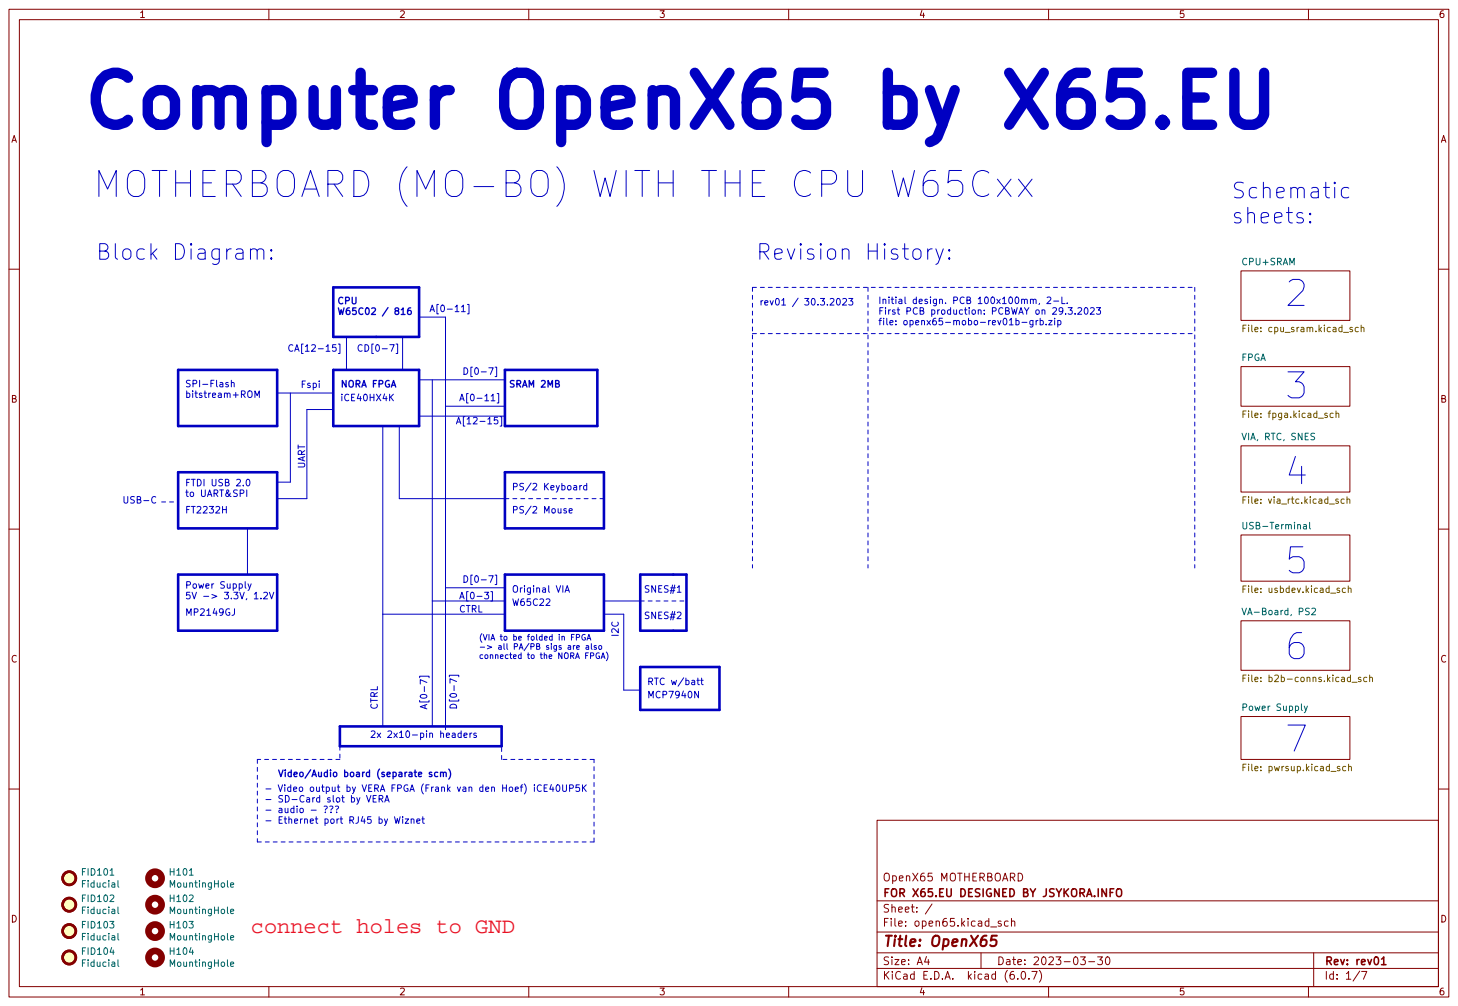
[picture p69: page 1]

iCE40HX4K CPU W65C02 / 816 MOTHERBOARD (MO-BO) WITH THE CPU W65Cxx

Block Diagram: SPI-Flash

File: fpga.kicad_sch CPU+SRAM

Initial design. PCB 100x100mm, 2-L.
First PCB production: PCBWAY on 29.3.2023
file: openx65-mobo-rev01b-grb.zip

File: cpu_sram.kicad_sch VIA, RTC, SNES

File: via_rtc.kicad_sch USB-Terminal File: usbdev.kicad_sch VA-Board, PS2 File: b2b-conns.kicad_sch Power Supply

(VIA to be folded in FPGA

Video/Audio board (separate scm)
- Video output by VERA FPGA (Frank van den Hoef) iCE40UP5K
- SD-Card slot by VERA
- audio - ???
- Ethernet port RJ45 by Wiznet

OpenX65 MOTHERBOARD
File: open65.kicad_sch Sheet: / FOR X65.EU DESIGNED BY JSYKORA.INFO

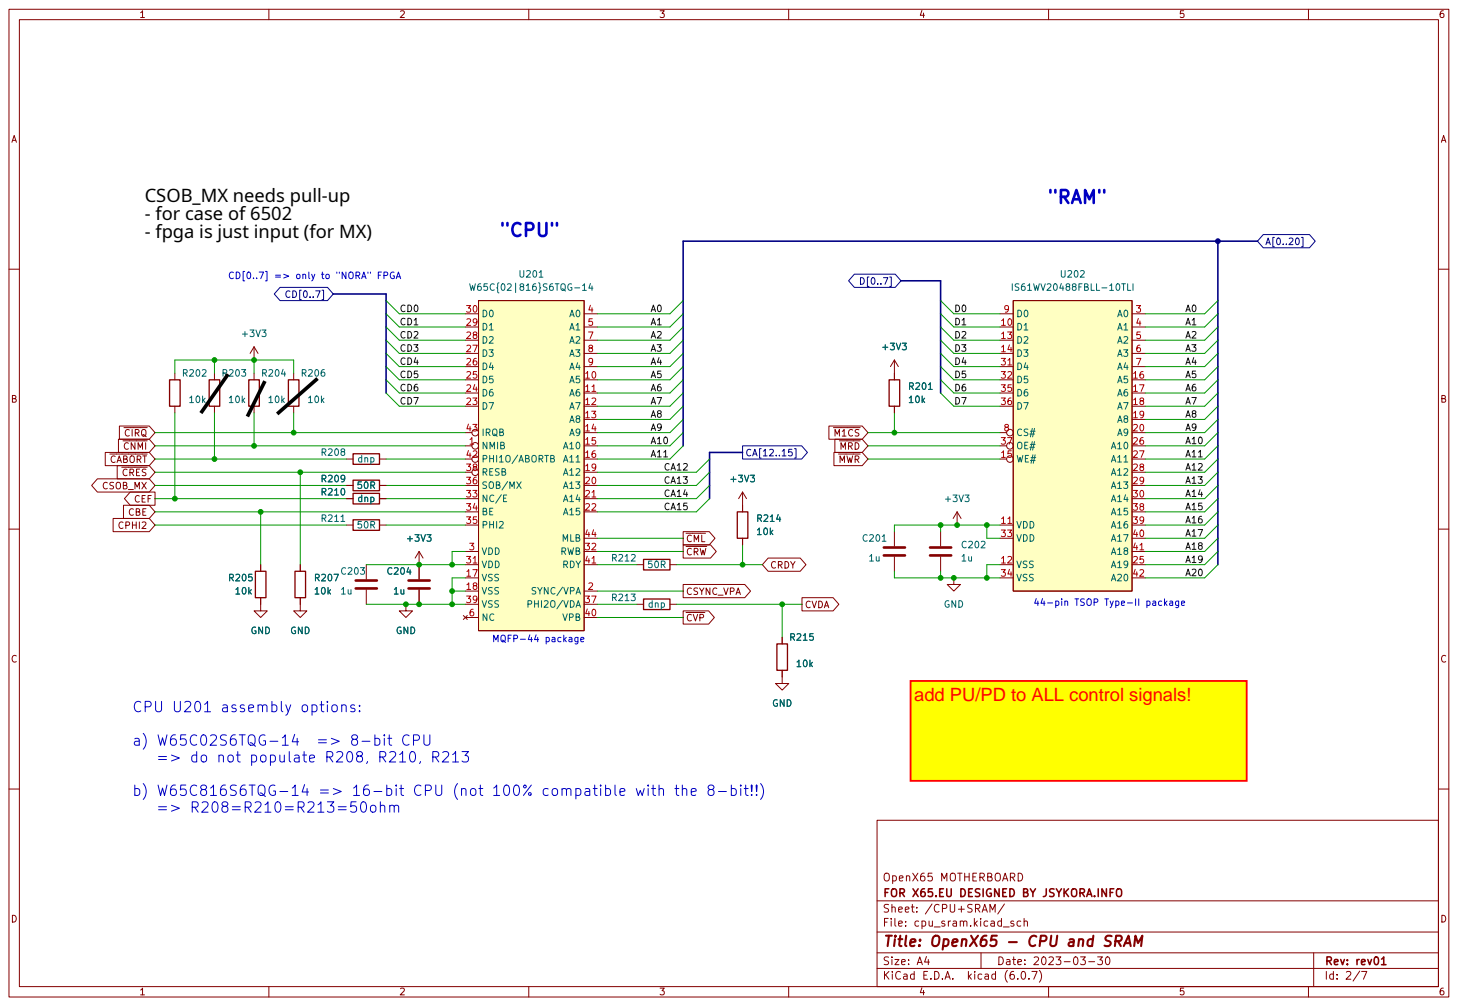
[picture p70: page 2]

CD[0..7] => only to "NORA" FPGA

44-pin TSOP Type-II package

b) W65C816S6TQG-14 => 16-bit CPU (not 100% compatible with the 8-bit!!)
=> R208=R210=R213=50ohm

OpenX65 MOTHERBOARD
File: cpu_sram.kicad_sch Sheet: /CPU+SRAM/ FOR X65.EU DESIGNED BY JSYKORA.INFO

Id: 2/7 Title: OpenX65 - CPU and SRAM

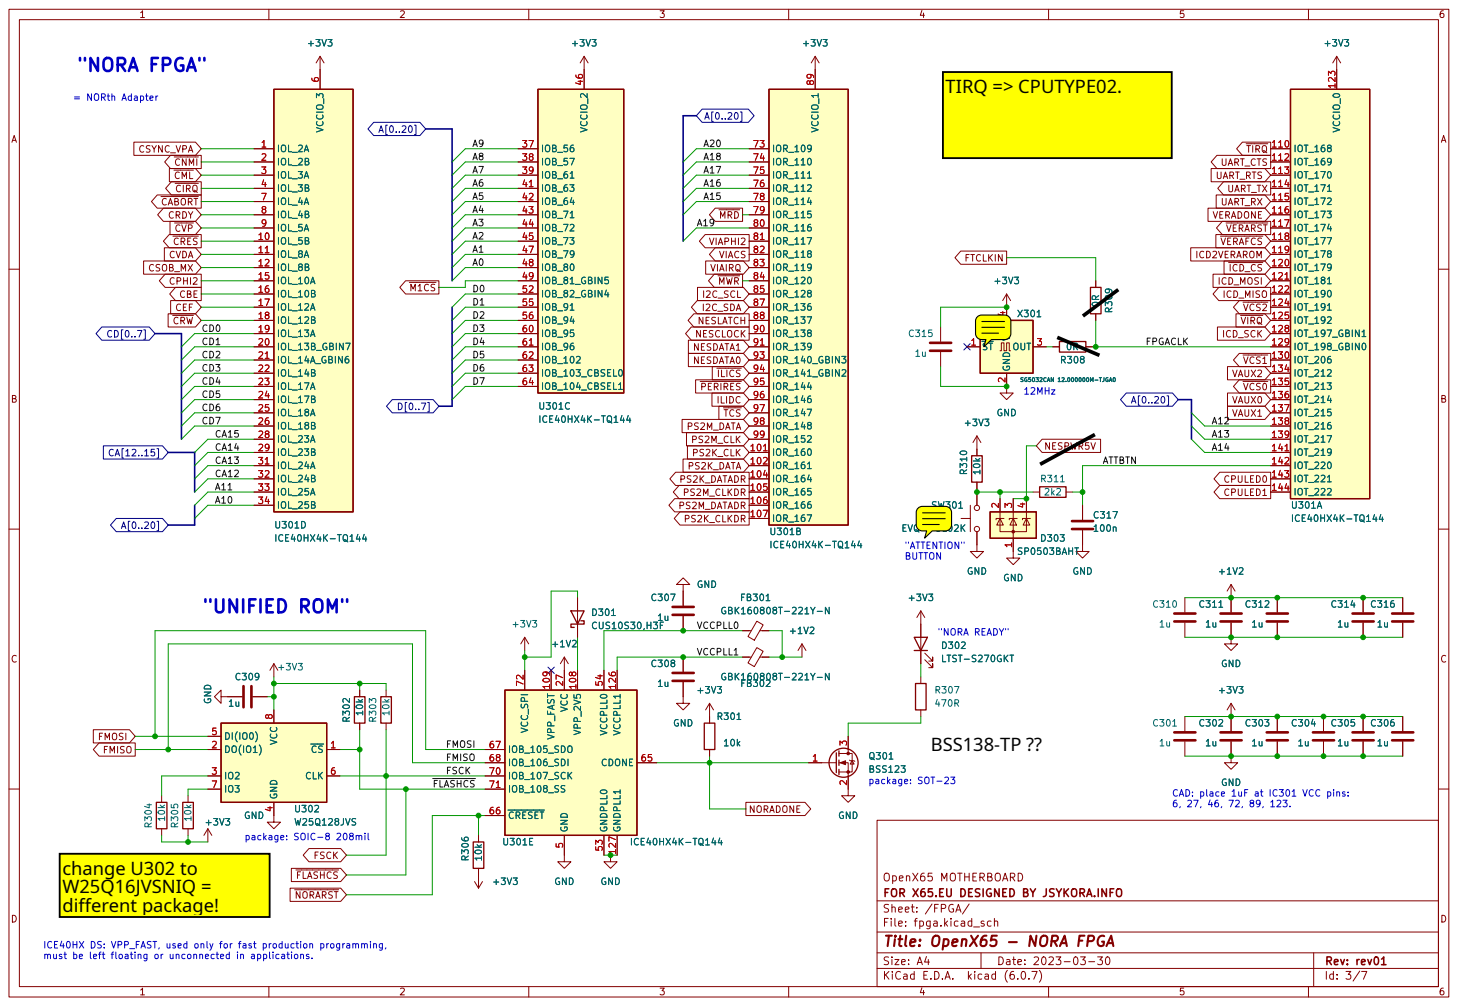
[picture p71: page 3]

CAD: place 1uF at IC301 VCC pins: 6, 27, 46, 72, 89, 123. +1V2 R309 0R GND

"ATTENTION" BUTTON "UNIFIED ROM"

"NORA READY" package: SOT-23

OpenX65 MOTHERBOARD
File: fpga.kicad_sch Sheet: /FPGA/ FOR X65.EU DESIGNED BY JSYKORA.INFO

Id: 3/7 Title: OpenX65 - NORA FPGA

ICE40HX DS: VPP_FAST, used only for fast production programming,
must be left floating or unconnected in applications.

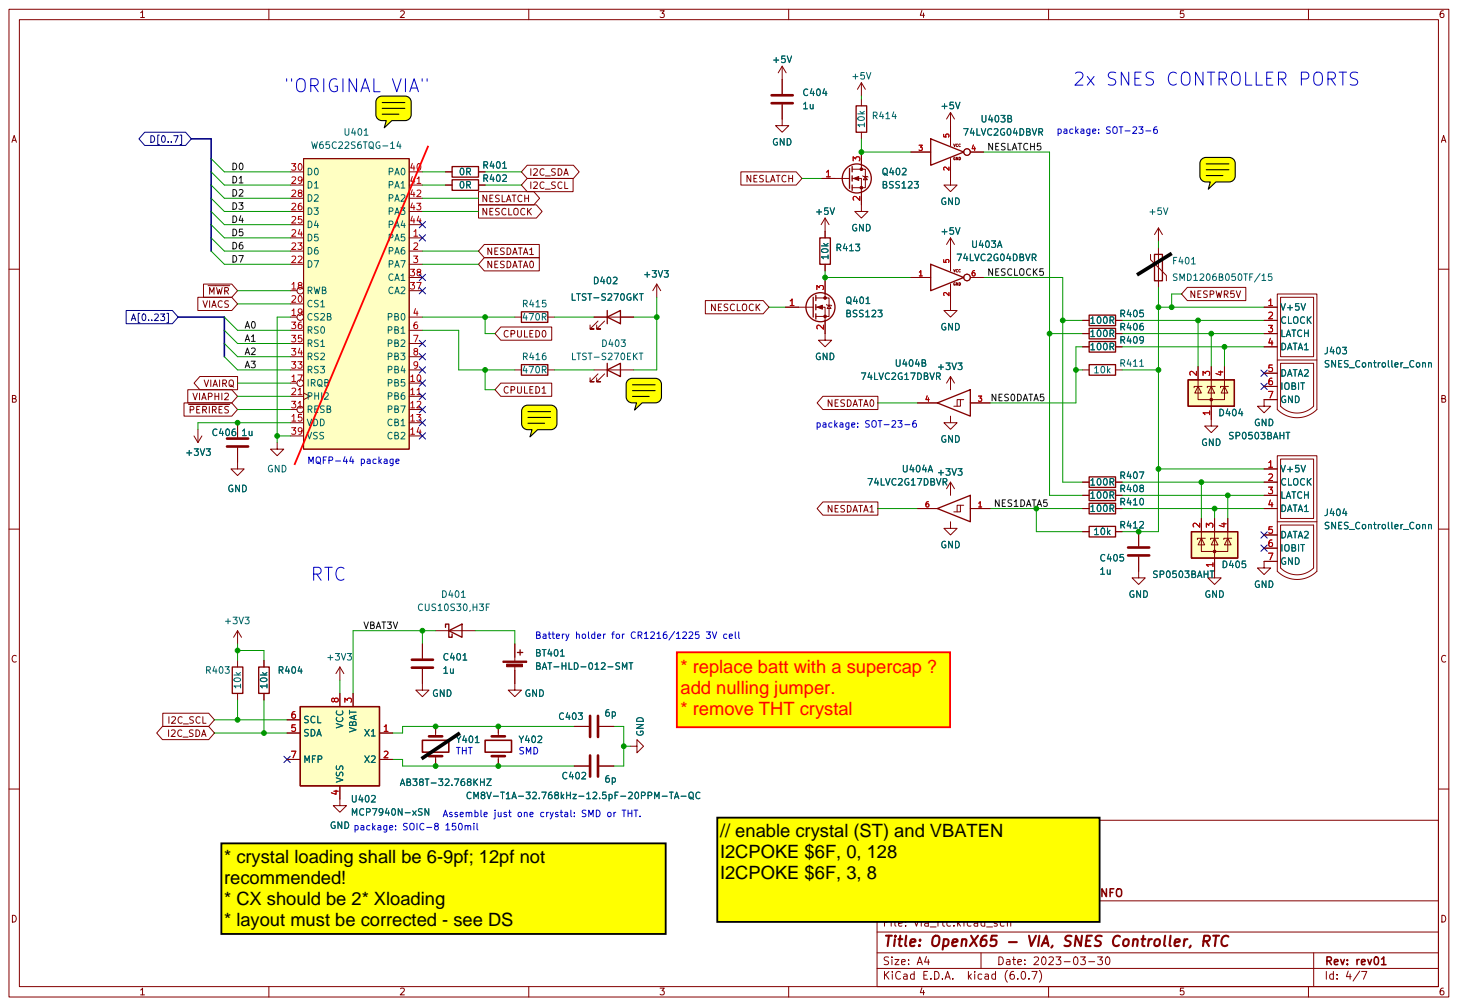
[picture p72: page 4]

4 SDA 5 SCL 6 MFP 7 VCC

Assemble just one crystal: SMD or THT. SMD

OpenX65 MOTHERBOARD
Sheet: /VIA, RTC, SNES/ FOR X65.EU DESIGNED BY JSYKORA.INFO

File: via_rtc.kicad_sch
Id: 4/7 Title: OpenX65 - VIA, SNES Controller, RTC

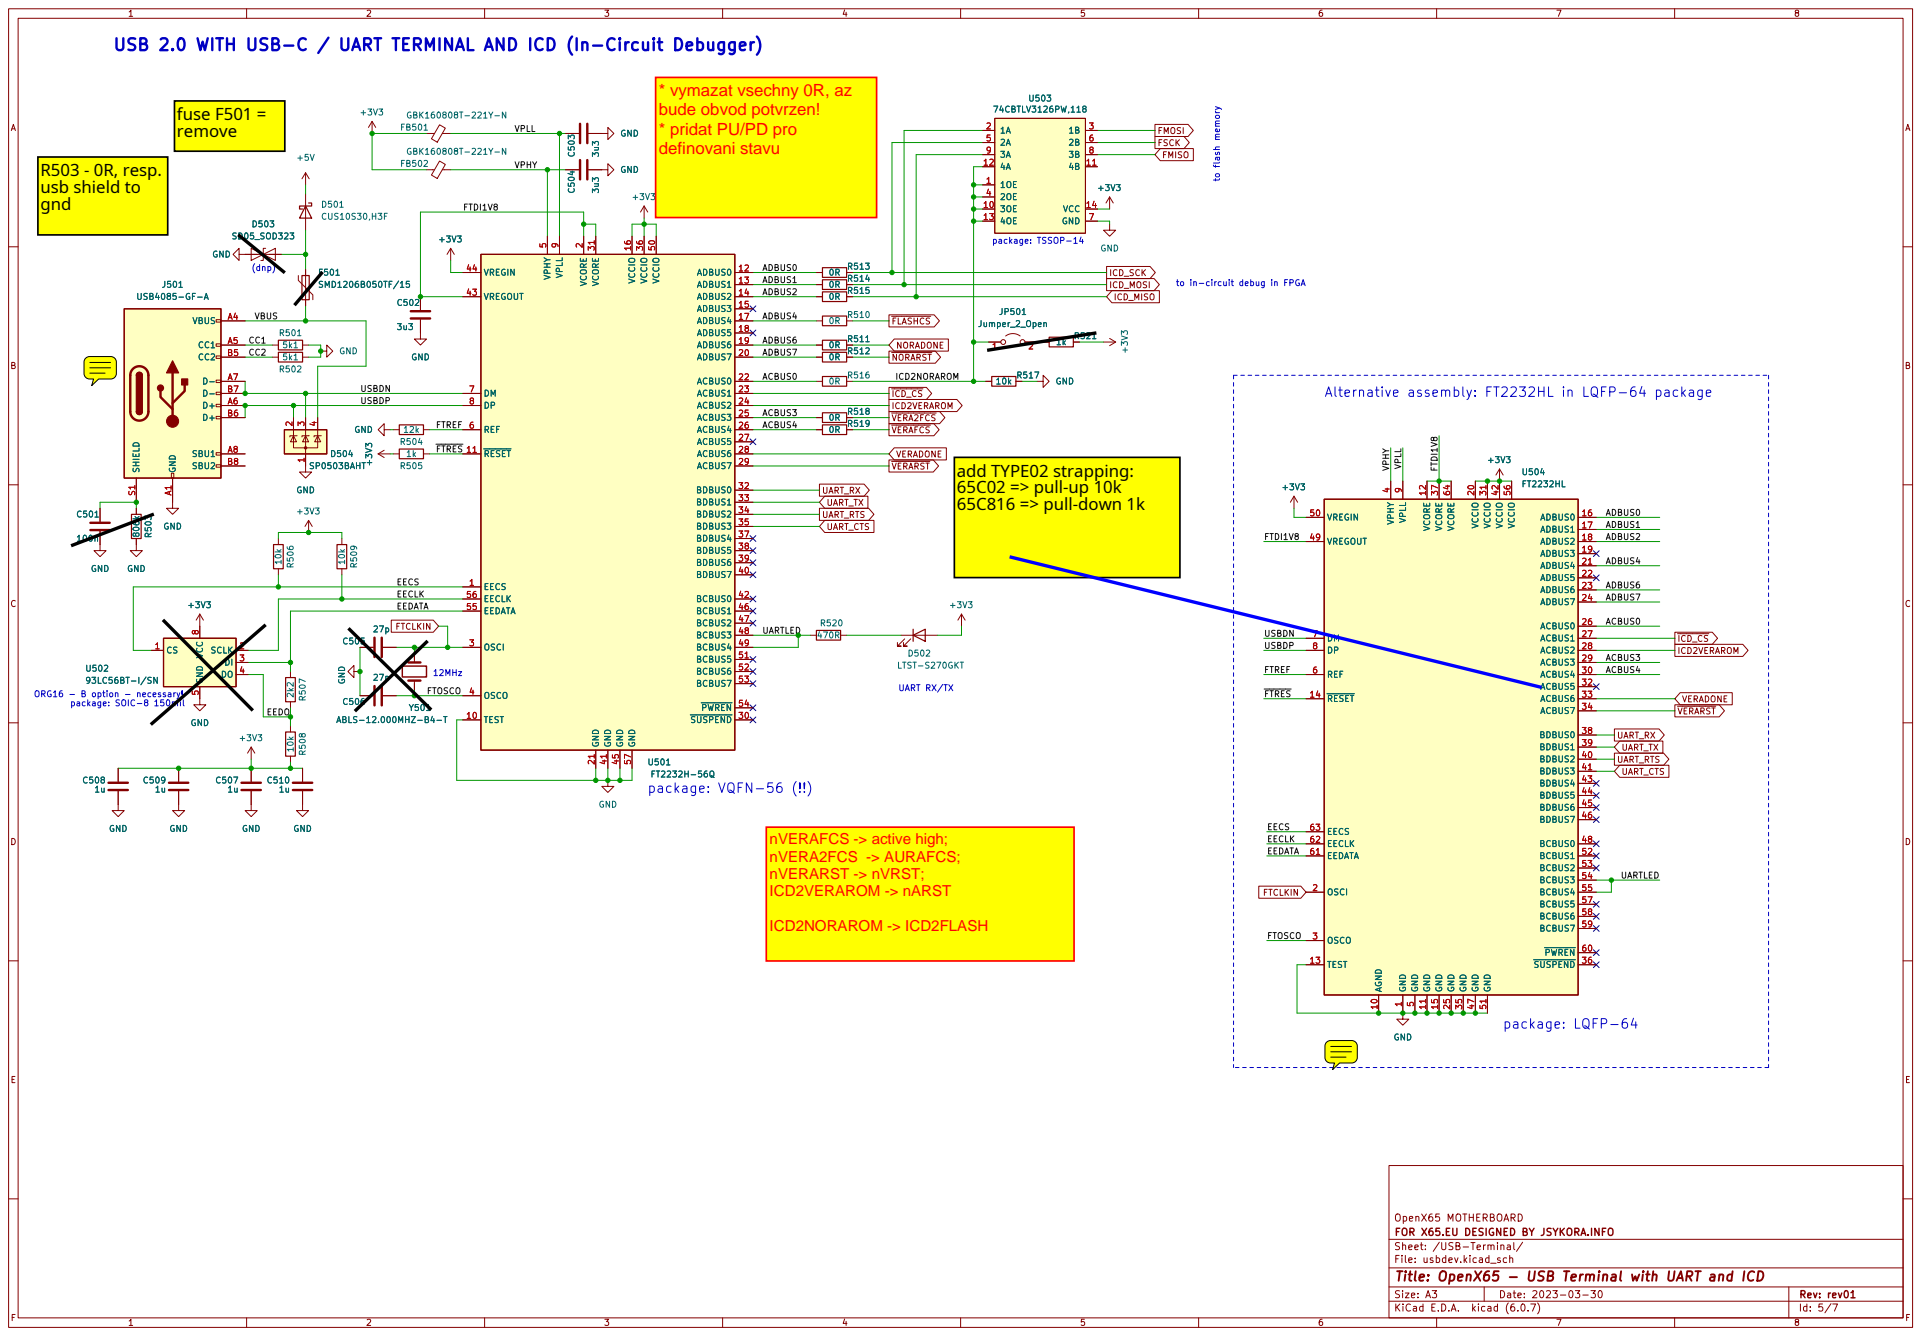
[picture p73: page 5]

USB 2.0 WITH USB-C / UART TERMINAL AND ICD (In-Circuit Debugger)
VPLL EEDO

2 ADBUS7 20 GND 21 ACBUS0 22 ACBUS1 23 ACBUS2 24 ACBUS3 25 ACBUS4 26 ACBUS5 27 ACBUS6 28 ACBUS7 29 OSCI 3 ~{SUSPEND} 30 VCORE 31 BDBUS0 32 BDBUS1 33 BDBUS2 34 BDBUS3 35 VCCIO 36 BDBUS4 37 BDBUS5 38 BDBUS6 39 OSCO 4 BDBUS7 40 GND 41 BCBUS0 42 VREGOUT 43 VREGIN 44 GND 45 BCBUS1 46 BCBUS2 47 BCBUS3 48 BCBUS4 49 VPHY

5 VCCIO 50 BCBUS5 51 BCBUS6 52 BCBUS7 53 ~{PWREN} 54 EEDATA 55 EECLK 56 GND 57 REF 6 DM 7 DP 8 VPLL

to in-circuit debug in FPGA

1 AGND 10 GND 11 VCORE 12 TEST 13 ~{RESET} 14 GND 15 ADBUS0 16 ADBUS1 17 ADBUS2 18 ADBUS3 19 OSCI 2 VCCIO 20 ADBUS4 21 ADBUS5 22 ADBUS6 23 ADBUS7 24 GND 25 ACBUS0 26 ACBUS1 27 ACBUS2 28 ACBUS3 29 OSCO 3 ACBUS4 30 VCCIO 31 ACBUS5 32 ACBUS6 33 ACBUS7 34 GND 35

4 BDBUS2 40 BDBUS3 41 VCCIO 42 BDBUS4 43 BDBUS5 44 BDBUS6 45 BDBUS7 46 GND 47 BCBUS0 48 VREGOUT 49 GND

5 VREGIN 50 GND 51 BCBUS1 52 BCBUS2 53 BCBUS3 54 BCBUS4 55 VCCIO 56 BCBUS5 57 BCBUS6 58 BCBUS7 59 REF 6 ~{PWREN} 60 EEDATA 61 EECLK 62 EECS 63 VCORE 64 DM 7 DP 8 VPLL

OpenX65 MOTHERBOARD
File: usbdev.kicad_sch Sheet: /USB-Terminal/ FOR X65.EU DESIGNED BY JSYKORA.INFO

Id: 5/7 Title: OpenX65 - USB Terminal with UART and ICD

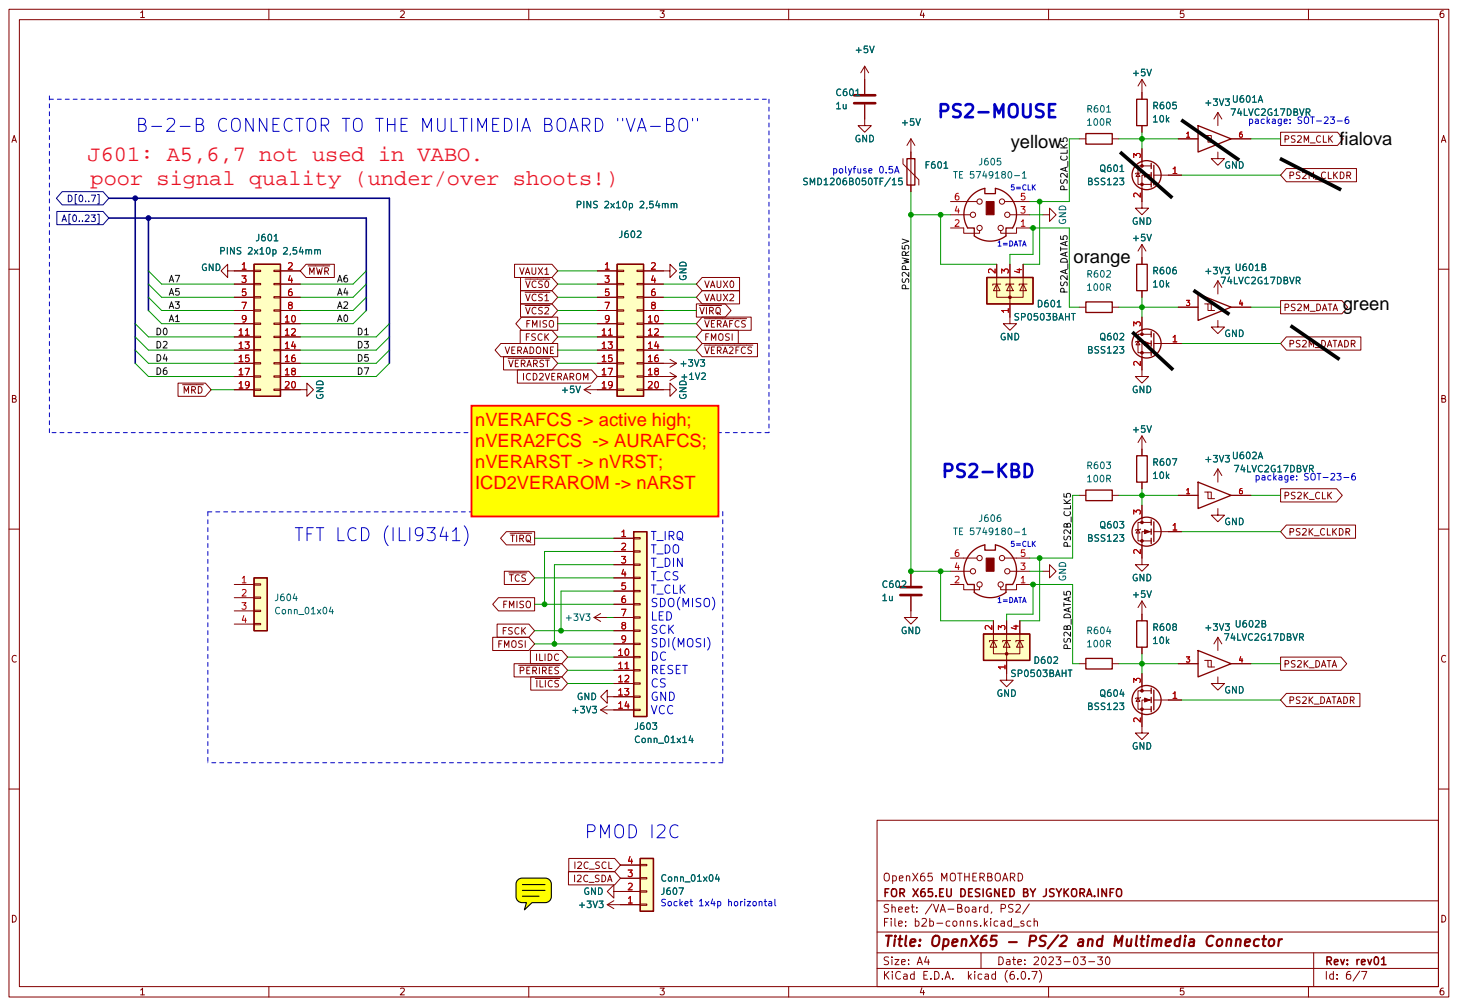
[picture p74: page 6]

B-2-B CONNECTOR TO THE MULTIMEDIA BOARD "VA-BO"

OpenX65 MOTHERBOARD
Sheet: /VA-Board, PS2/ FOR X65.EU DESIGNED BY JSYKORA.INFO

File: b2b-conns.kicad_sch
Id: 6/7 Title: OpenX65 - PS/2 and Multimedia Connector

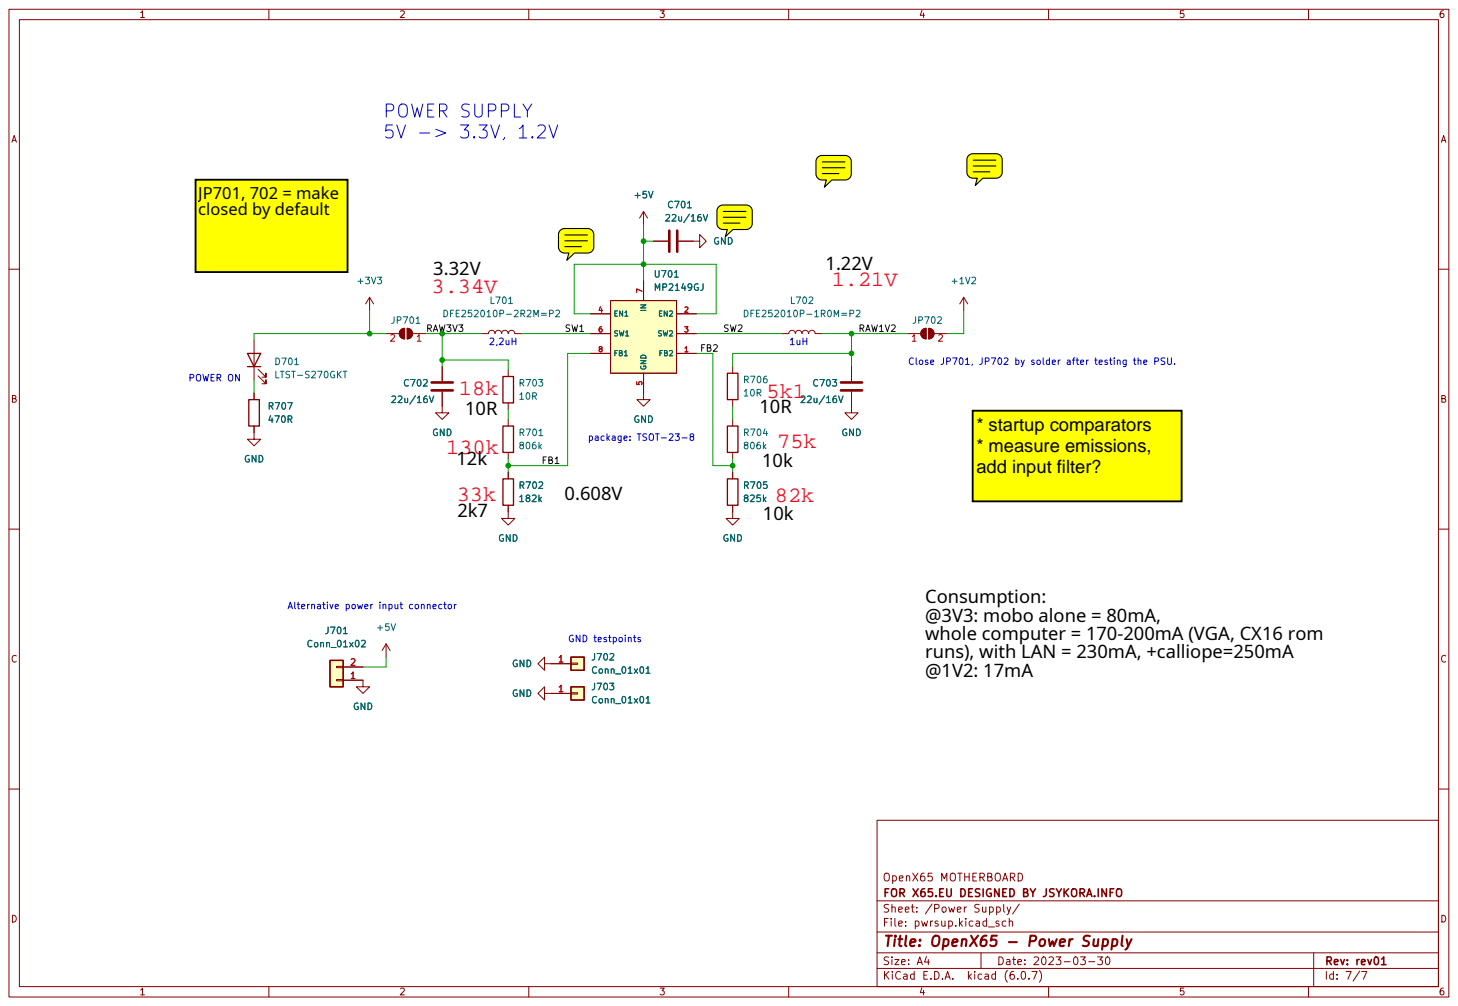
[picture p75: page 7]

Close JP701, JP702 by solder after testing the PSU.

package: TSOT-23-8 POWER ON

OpenX65 MOTHERBOARD
Sheet: /Power Supply/ FOR X65.EU DESIGNED BY JSYKORA.INFO

File: pwrsup.kicad_sch
Id: 7/7 Title: OpenX65 - Power Supply

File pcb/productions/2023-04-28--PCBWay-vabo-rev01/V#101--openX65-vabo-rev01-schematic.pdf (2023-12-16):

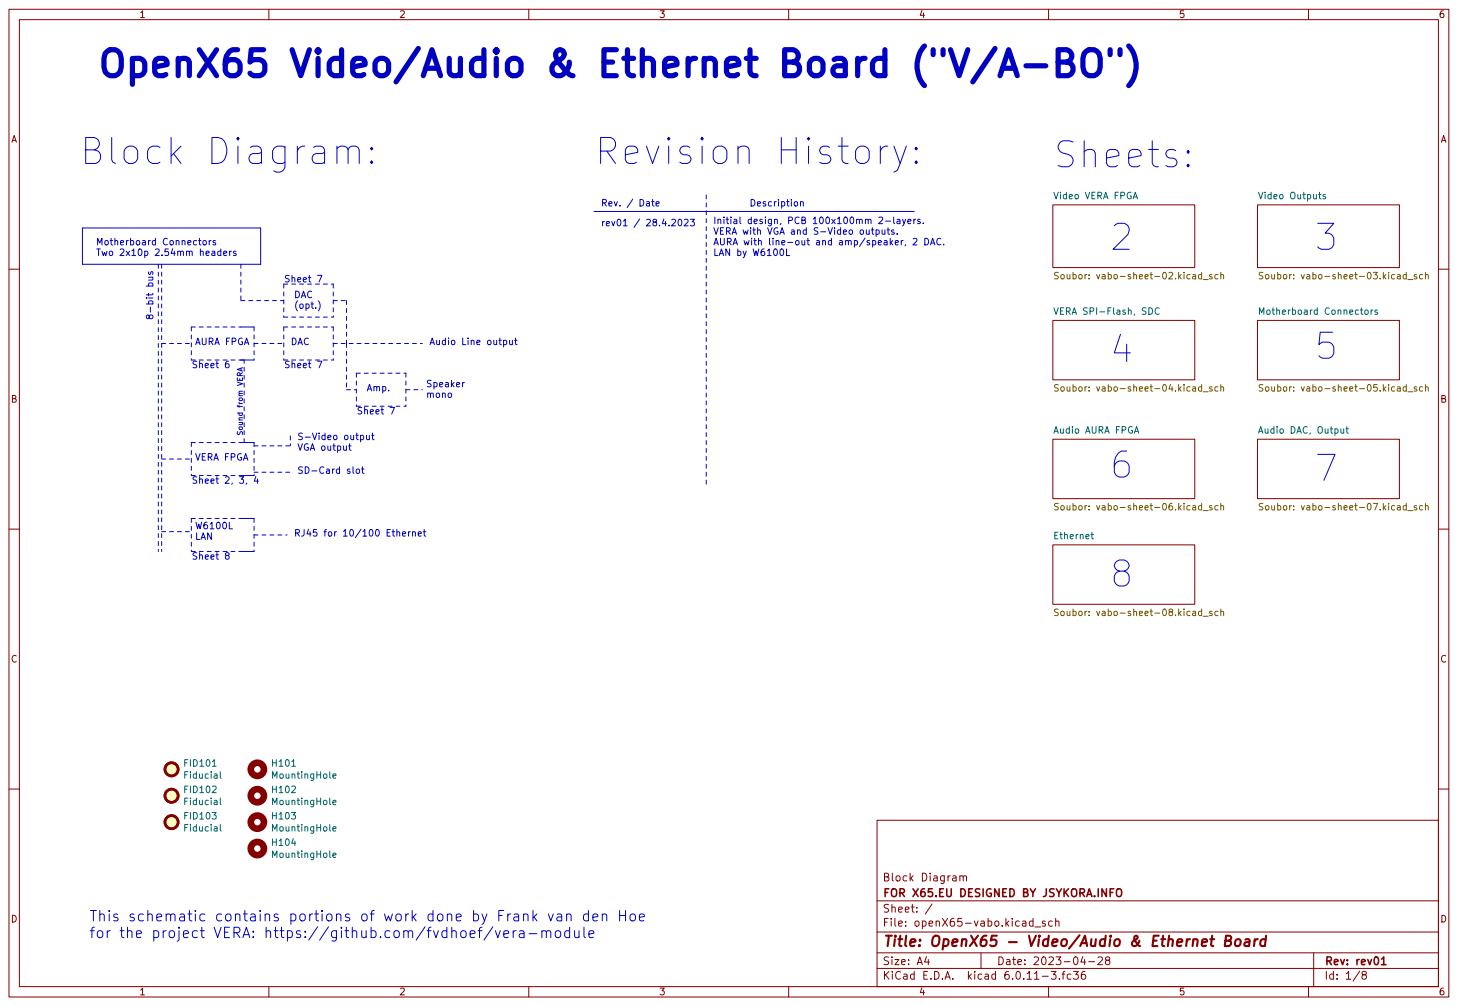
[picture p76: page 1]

Sheets:
Soubor: vabo-sheet-06.kicad_sch Video VERA FPGA

File: openX65-vabo.kicad_sch Sheet: / FOR X65.EU DESIGNED BY JSYKORA.INFO

Id: 1/8 Title: OpenX65 - Video/Audio & Ethernet Board

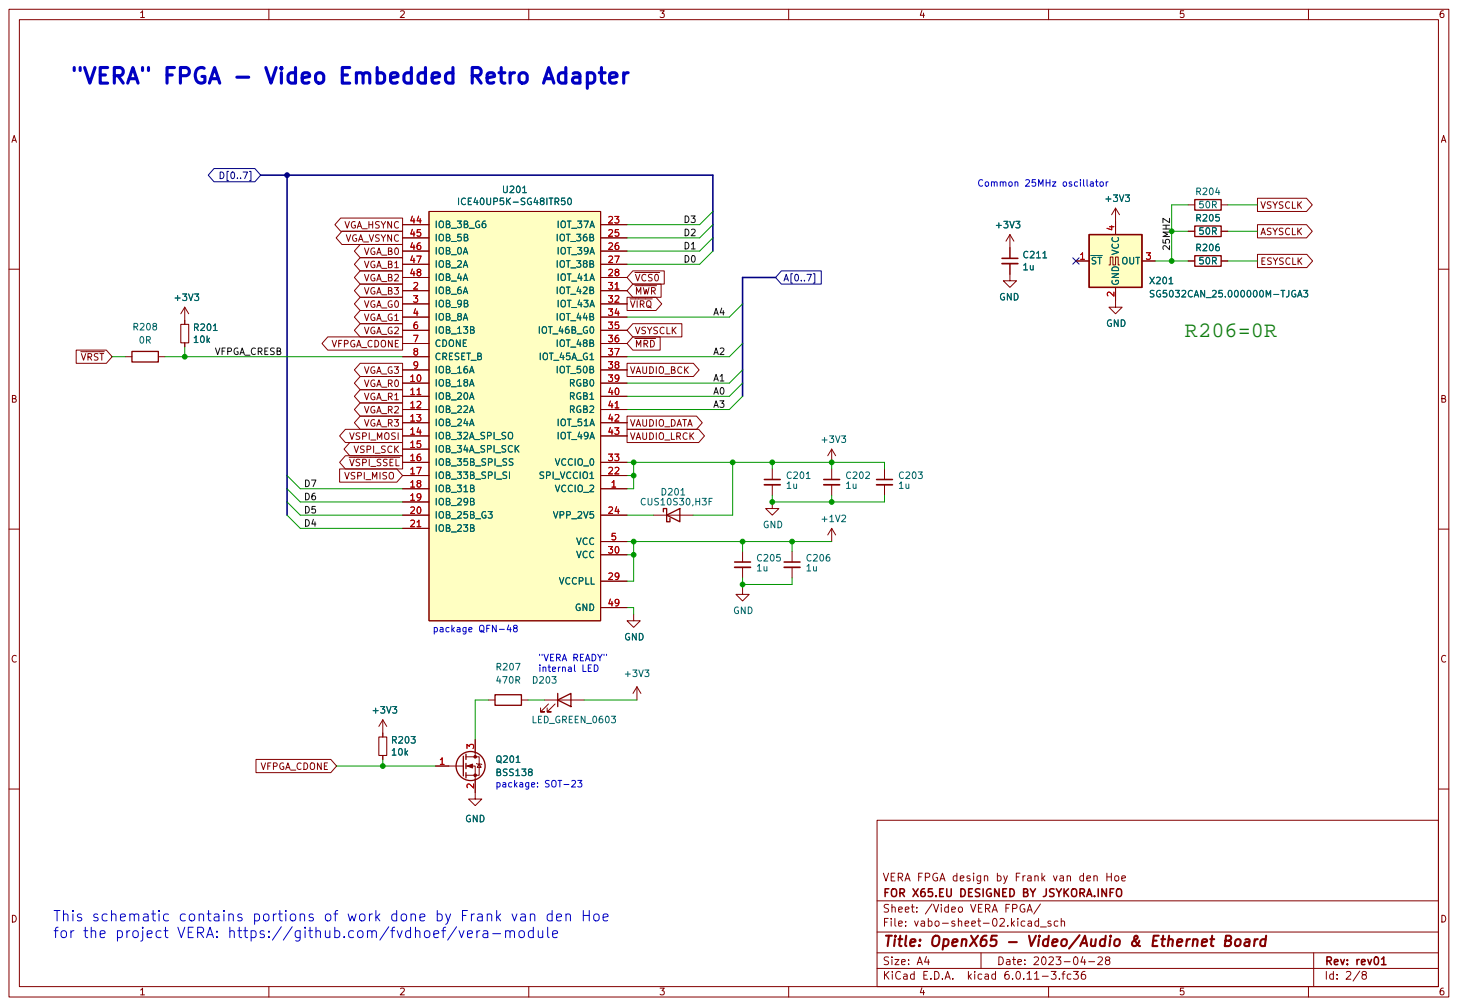
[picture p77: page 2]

Id: 2/8 Title: OpenX65 - Video/Audio & Ethernet Board

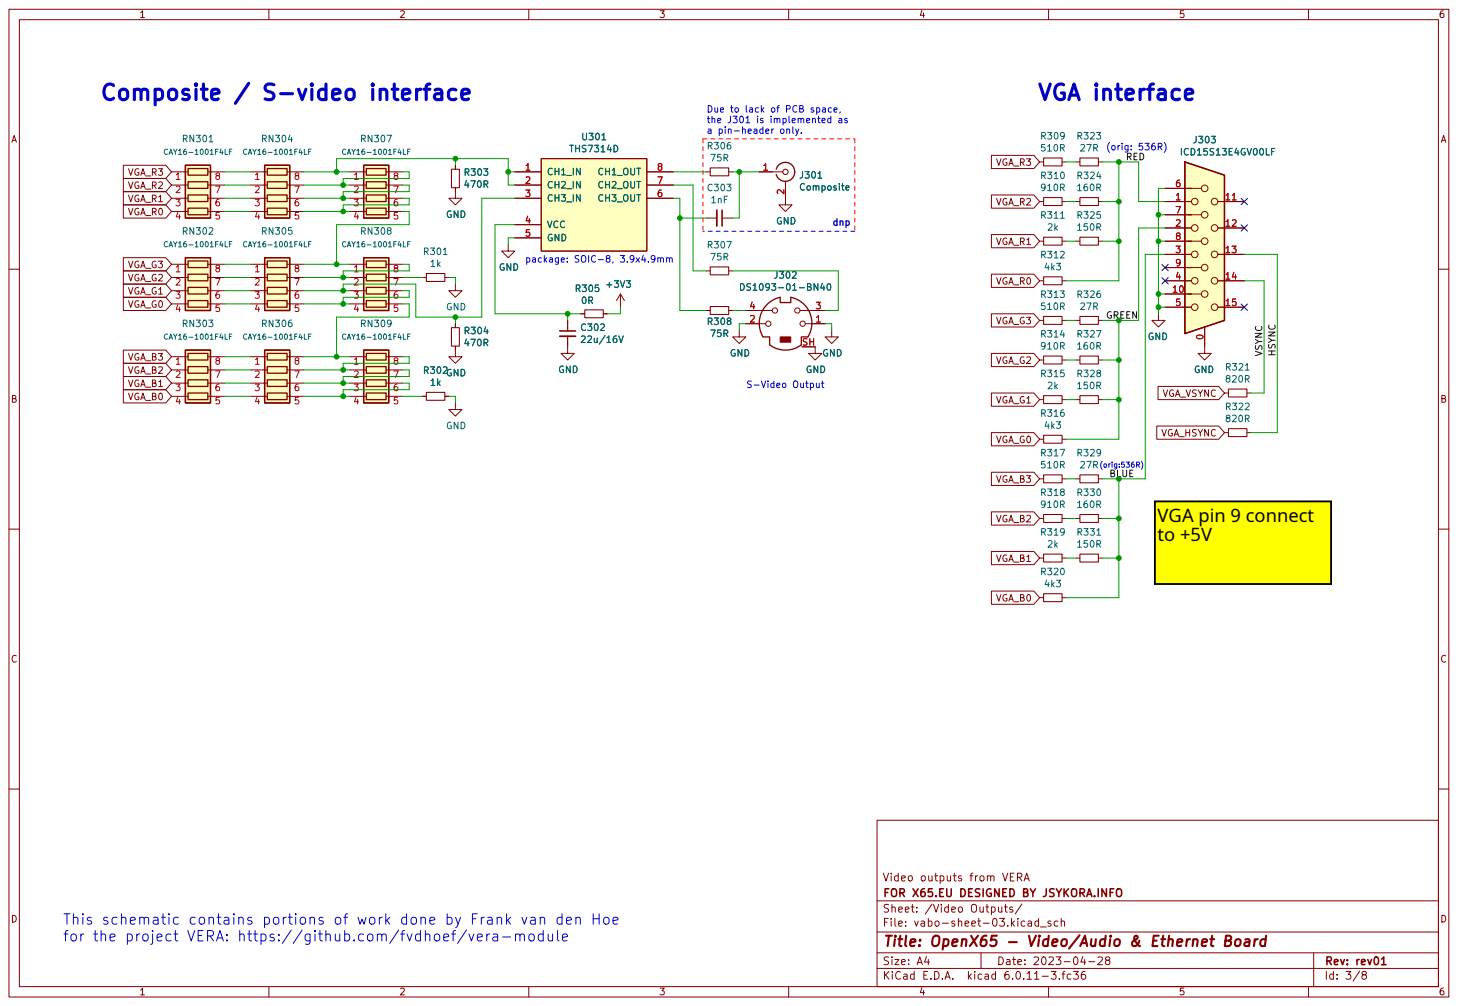
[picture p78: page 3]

Due to lack of PCB space,
+3V3 U301 THS7314D

7 2 | 7 | 7
6 3 | 6 | 6

7 2 | 7
6 3 | 6

Video outputs from VERA

Id: 3/8 Title: OpenX65 - Video/Audio & Ethernet Board

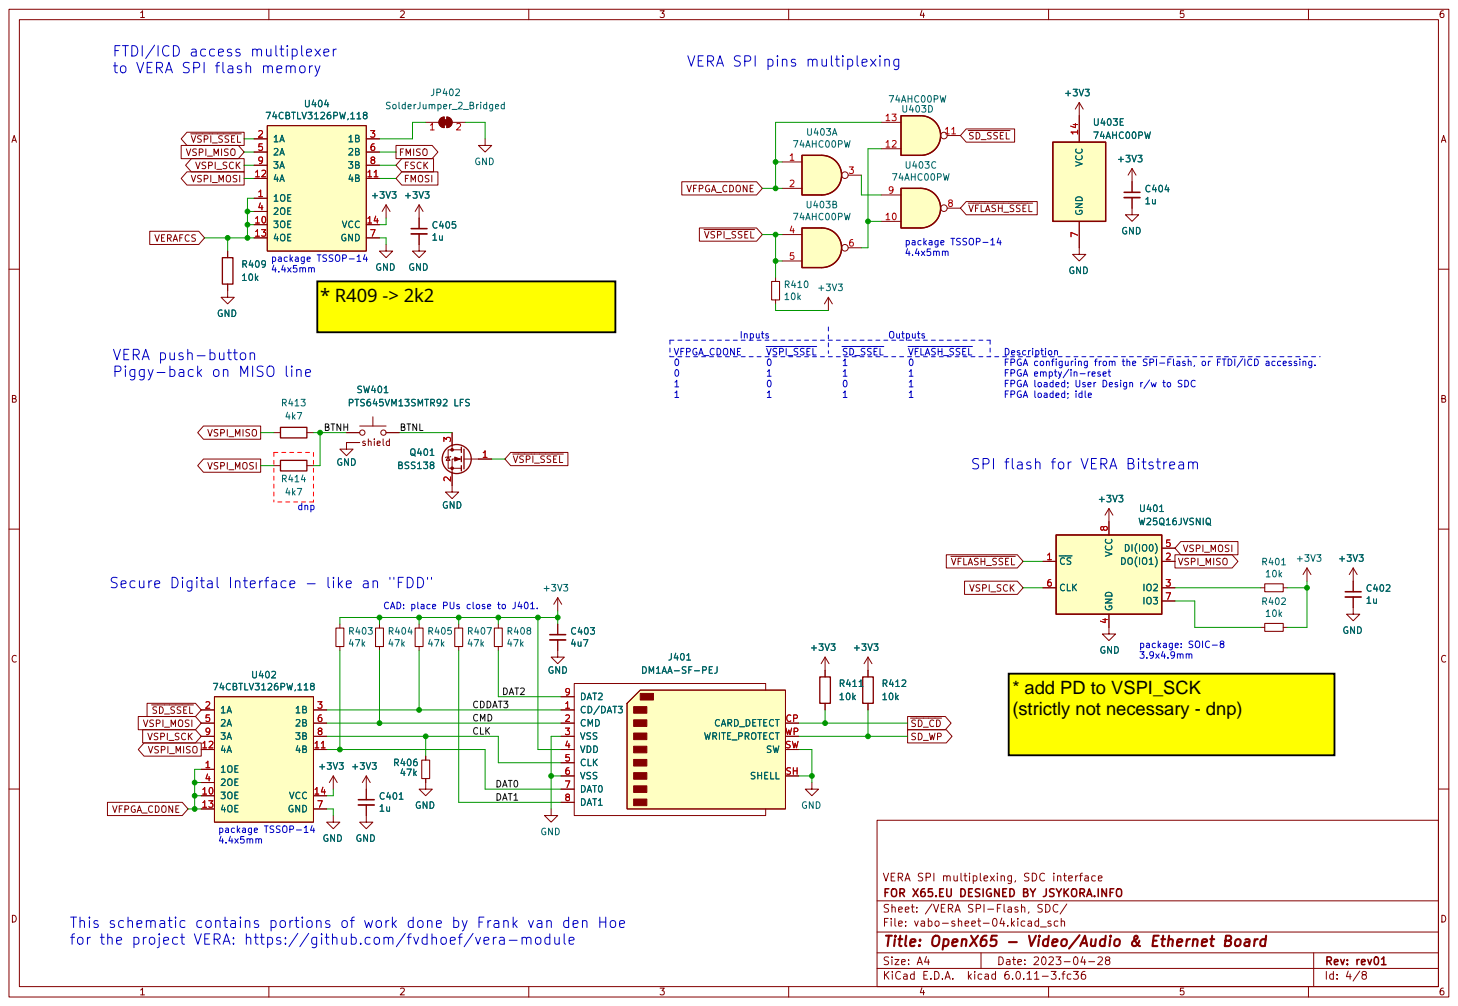
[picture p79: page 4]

Inputs CAD: place PUs close to J401. FTDI/ICD access multiplexer
~{VSPI_SSEL} VSPI_MOSI VSPI_MISO
FMOSI BTNH

8 8 | CLK
11 11

Id: 4/8 Title: OpenX65 - Video/Audio & Ethernet Board

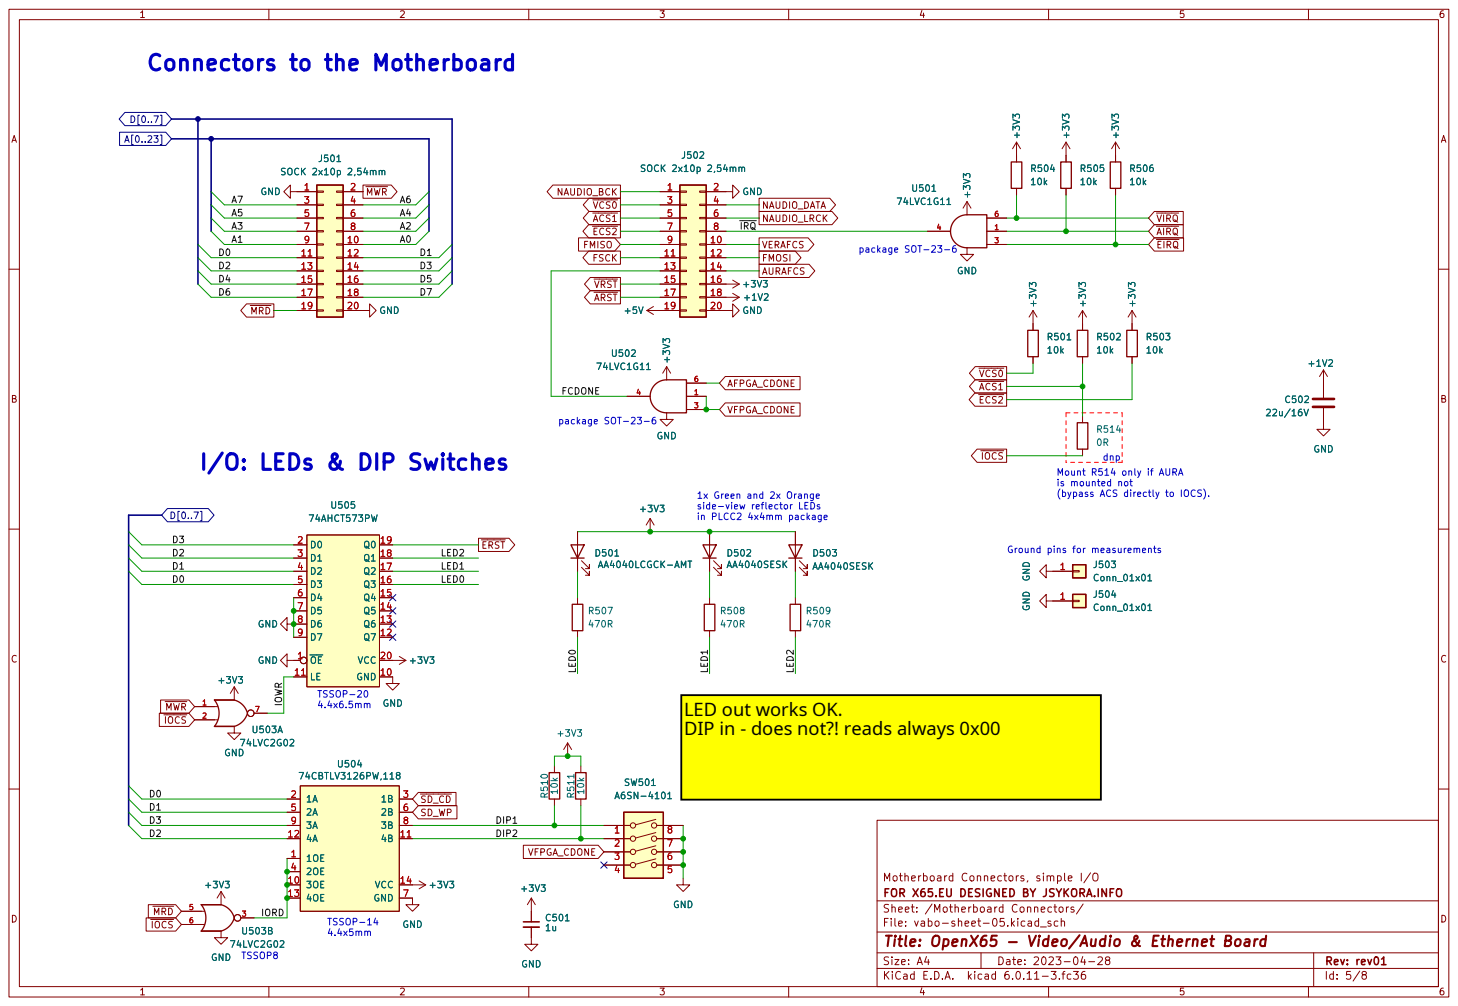
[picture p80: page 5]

4.4x6.5mm Connectors to the Motherboard

Id: 5/8 Title: OpenX65 - Video/Audio & Ethernet Board


4.4x5mm "AURA" FPGA - Audio Retro Adapter

package QFN-48 R608, R609, R610 mounted only if U601 (AURA) is not.

Id: 6/8 Title: OpenX65 - Video/Audio & Ethernet Board


Id: 7/8 Title: OpenX65 - Video/Audio & Ethernet Board


3u3 GND | RXIP

1 GND 10 XSCO 11 XSCI 12 1V2D 13 1V2O 14 3V3A 15 GNDA 16

R814 | TDN

File: vabo-sheet-08.kicad_sch Sheet: /Ethernet/ FOR X65.EU DESIGNED BY JSYKORA.INFO

Id: 8/8 Title: OpenX65 - Video/Audio & Ethernet Board

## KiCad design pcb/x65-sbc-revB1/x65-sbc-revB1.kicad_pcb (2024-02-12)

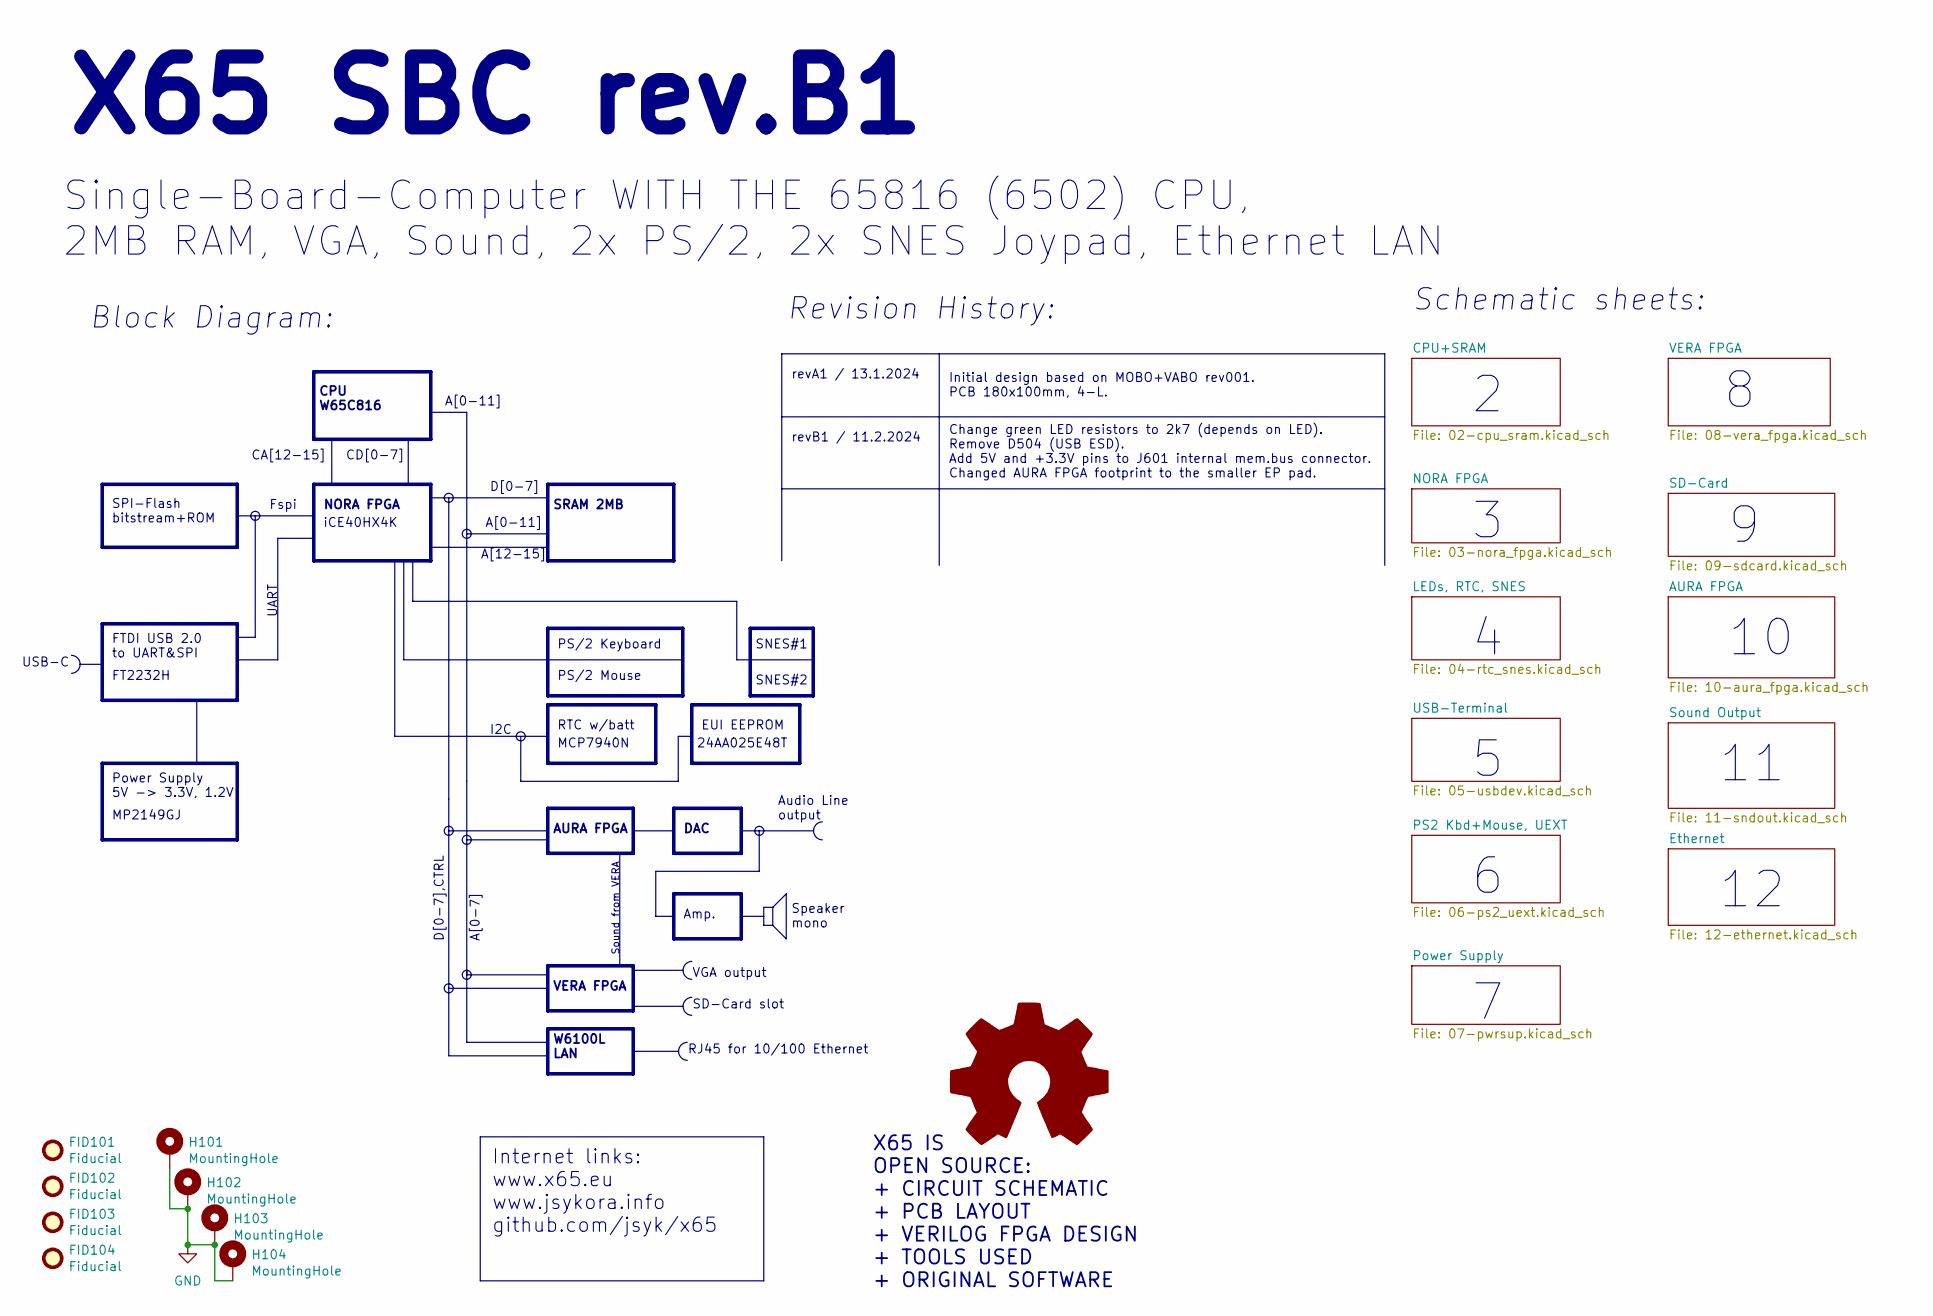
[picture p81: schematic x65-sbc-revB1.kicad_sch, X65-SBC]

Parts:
FID101, FID102, FID103, FID104: Fiducial; Fiducial_1mm_Mask2mm
H101, H102, H103, H104: MountingHole; MountingHole_3.2mm_M3_Pad
SYM101: Logo_Open_Hardware_Large; OSHW-Logo2_7.3x6mm_SilkScreen

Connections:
GND: H101.1, H102.1, H103.1, H104.1; also elsewhere on the board

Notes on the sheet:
Internet links: www.x65.eu www.jsykora.info github.com/jsyk/x65
Amp.
Block Diagram:
Initial design based on MOBO+VABO rev001. PCB 180x100mm, 4-L.
Schematic sheets:
MCP7940N
CA[12-15]
RJ45 for 10/100 Ethernet
CPU W65C816
A[12-15]
Single-Board-Computer WITH THE 65816 (6502) CPU, 2MB RAM, VGA, Sound, 2x PS/2, 2x SNES Joypad, Ethernet LAN
revB1 / 11.2.2024
A[0-11]
CD[0-7]
W6100L LAN
SNES#2
Sound from VERA
FT2232H
NORA FPGA
Fspi
X65 SBC rev.B1
SD-Card slot
Revision History:
EUI EEPROM
PS/2 Keyboard
revA1 / 13.1.2024
VERA FPGA
DAC
I2C
Speaker mono
UART
iCE40HX4K
VGA output
Power Supply 5V -> 3.3V, 1.2V
SPI-Flash bitstream+ROM
X65 IS OPEN SOURCE: + CIRCUIT SCHEMATIC + PCB LAYOUT + VERILOG FPGA DESIGN + TOOLS USED + ORIGINAL SOFTWARE
Change green LED resistors to 2k7 (depends on LED). Remove D504 (USB ESD). Add 5V and +3.3V pins to J601 internal mem.bus connector. Changed AURA FPGA footprint to the smaller EP pad.
MP2149GJ
RTC w/batt
USB-C

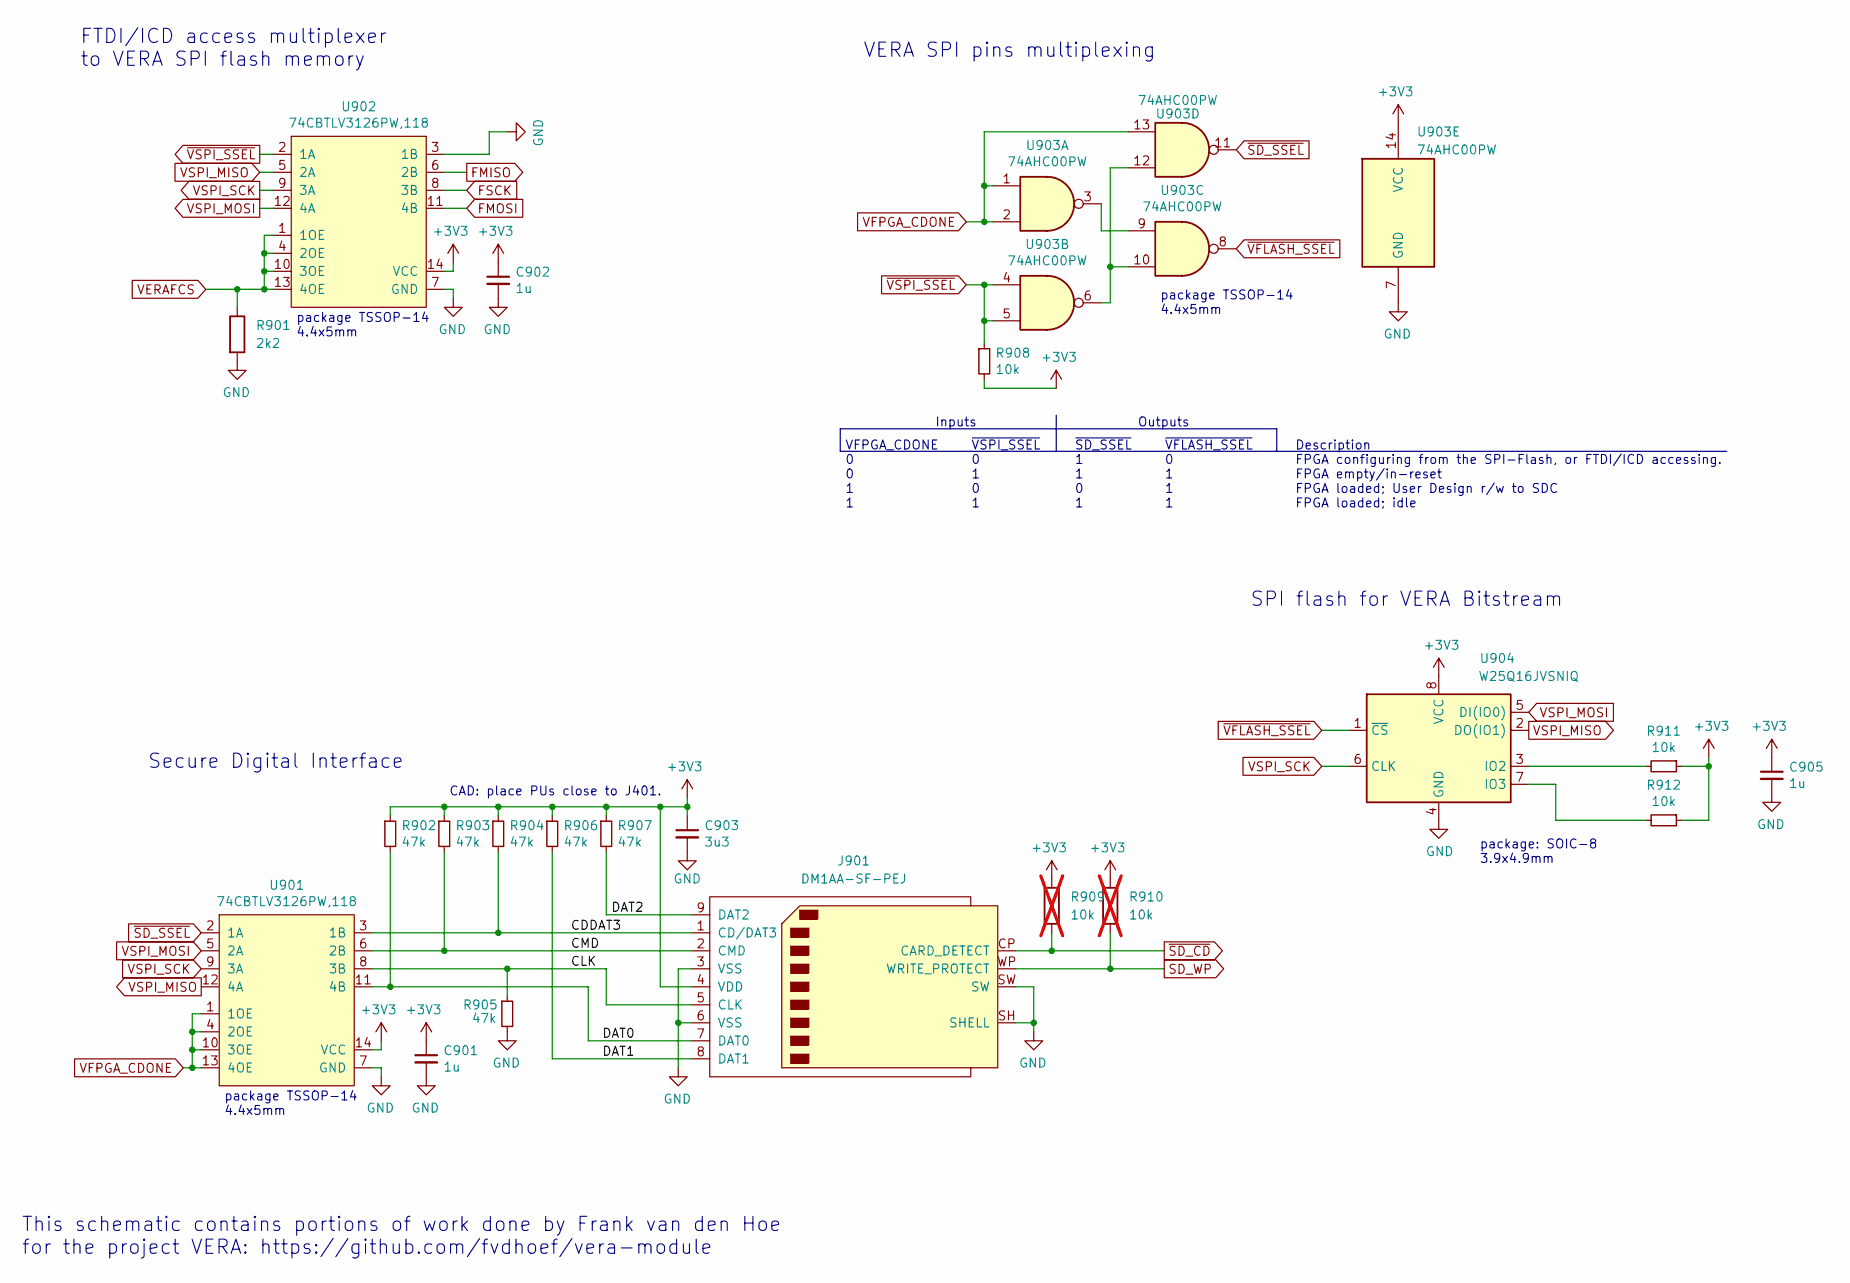
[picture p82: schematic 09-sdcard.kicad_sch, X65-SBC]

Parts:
C901, C902, C905: 1u; C_0603_1608Metric_Pad1.08x0.95mm_HandSolder
C903: 3u3; C_0603_1608Metric_Pad1.08x0.95mm_HandSolder
J901: DM1AA-SF-PEJ; SD_Hirose_DM1AA_SF_PEJ82
R901: 2k2; R_0603_1608Metric_Pad0.98x0.95mm_HandSolder
R902, R903, R904, R905, R906, R907: 47k; R_0603_1608Metric_Pad0.98x0.95mm_HandSolder
R908, R911, R912: 10k; R_0603_1608Metric_Pad0.98x0.95mm_HandSolder
R909, R910: 10k; R_0603_1608Metric_Pad0.98x0.95mm_HandSolder; not fitted
U901, U902: 74CBTLV3126PW,118; TSSOP-14_4.4x5mm_P0.65mm
U903: 74AHC00PW; TSSOP-14_4.4x5mm_P0.65mm
U904: W25Q16JVSNIQ; SOIC-8_3.9x4.9mm_P1.27mm

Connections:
+3V3: C901.1, C902.1, C903.1, C905.1, J901.4 (VDD), R902.1, R903.1, R904.1, R906.1, R907.1, R908.2, R909.1, R910.1, R911.1, R912.1, U901.14 (VCC), U902.14 (VCC), U903.14 (VCC), U904.8 (VCC); also elsewhere on the board
/SD-Card/CDDAT3: J901.1 (CD/DAT3), R904.2, U901.3 (1B)
/SD-Card/CLK: J901.5 (CLK), R905.1, U901.8 (3B)
/SD-Card/CMD: J901.2 (CMD), R903.2, U901.6 (2B)
/SD-Card/DAT0: J901.7 (DAT0), R902.2, U901.11 (4B)
/SD-Card/DAT1: J901.8 (DAT1), R906.2
/SD-Card/DAT2: J901.9 (DAT2), R907.2
FMISO: U902.6 (2B); also elsewhere on the board
FMOSI: U902.11 (4B); also elsewhere on the board
FSCK: U902.8 (3B); also elsewhere on the board
GND: C901.2, C902.2, C903.2, C905.2, J901.3 (VSS), J901.6 (VSS), J901.SH (SHELL), J901.SW, R901.2, R905.2, U901.7 (GND), U902.3 (1B), U902.7 (GND), U903.7 (GND), U904.4 (GND); also elsewhere on the board
unnamed: U903.3, U903.9
unnamed: U903.6, U903.10, U903.12
unnamed: R911.2, U904.3 (IO2)
unnamed: R912.2, U904.7 (IO3)
SD_WP: J901.WP (WRITE_PROTECT), R910.2; also elsewhere on the board
VERAFCS: R901.1, U902.1 (1OE), U902.4 (2OE), U902.10 (3OE), U902.13 (4OE); also elsewhere on the board
VFPGA_CDONE: U901.1 (1OE), U901.4 (2OE), U901.10 (3OE), U901.13 (4OE), U903.1, U903.2, U903.13; also elsewhere on the board
VSPI_MISO: U901.12 (4A), U902.5 (2A), U904.2 (DO(IO1)); also elsewhere on the board
VSPI_MOSI: U901.5 (2A), U902.12 (4A), U904.5 (DI(IO0)); also elsewhere on the board
VSPI_SCK: U901.9 (3A), U902.9 (3A), U904.6 (CLK); also elsewhere on the board
~SD_CD: J901.CP (CARD_DETECT), R909.2; also elsewhere on the board
~SD_SSEL: U901.2 (1A), U903.11; also elsewhere on the board
~VFLASH_SSEL: U903.8, U904.1 (~CS)
~VSPI_SSEL: R908.1, U902.2 (1A), U903.4, U903.5; also elsewhere on the board

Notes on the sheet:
~{SD_SSEL} 1 1 0 1
This schematic contains portions of work done by Frank van den Hoe for the project VERA: https://github.com/fvdhoef/vera-module
~{VFLASH_SSEL} 0 1 1 1
Inputs
VFPGA_CDONE 0 0 1 1
package TSSOP-14 4.4x5mm
CAD: place PUs close to J401.
Outputs
package: SOIC-8 3.9x4.9mm
FTDI/ICD access multiplexer to VERA SPI flash memory
Description FPGA configuring from the SPI-Flash, or FTDI/ICD accessing. FPGA empty/in-reset FPGA loaded; User Design r/w to SDC FPGA loaded; idle
~{VSPI_SSEL} 0 1 0 1
Secure Digital Interface
SPI flash for VERA Bitstream
VERA SPI pins multiplexing

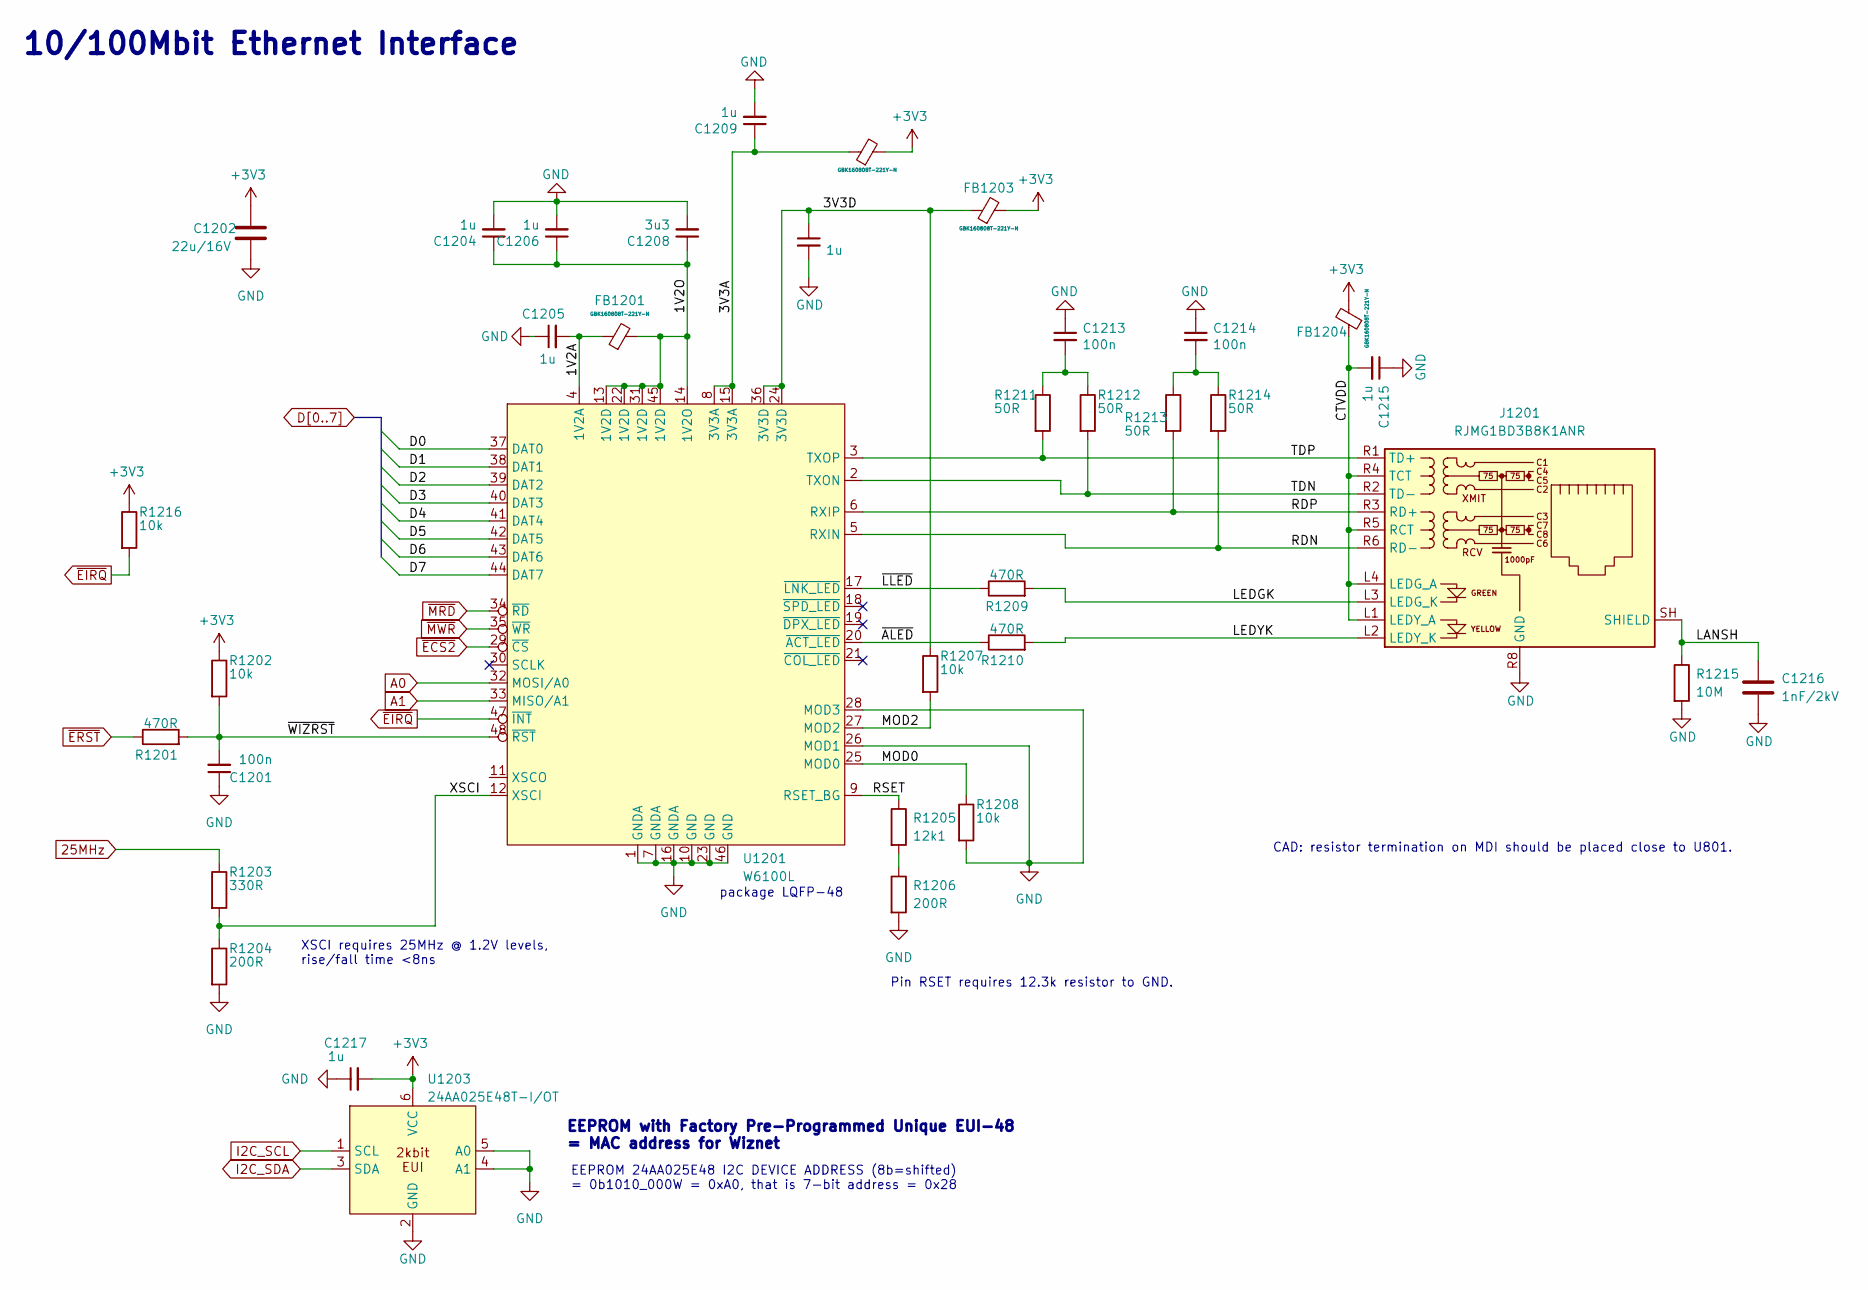
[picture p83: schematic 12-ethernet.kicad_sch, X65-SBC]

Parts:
C1201, C1213, C1214: 100n; C_0603_1608Metric_Pad1.08x0.95mm_HandSolder
C1202: 22u/16V; C_0805_2012Metric_Pad1.18x1.45mm_HandSolder
C1204, C1205, C1206, C1209, C1210, C1215, C1217: 1u; C_0603_1608Metric_Pad1.08x0.95mm_HandSolder
C1208: 3u3; C_0603_1608Metric_Pad1.08x0.95mm_HandSolder
C1216: 1nF/2kV; C_1206_3216Metric_Pad1.33x1.80mm_HandSolder
FB1201, FB1202, FB1203, FB1204: GBK160808T-221Y-N; R_0603_1608Metric_Pad0.98x0.95mm_HandSolder
J1201: RJMG1BD3B8K1ANR; RJ45_Amphenol_RJMG1BD3B8K1ANR
R1201, R1209, R1210: 470R; R_0603_1608Metric_Pad0.98x0.95mm_HandSolder
R1202, R1207, R1208, R1216: 10k; R_0603_1608Metric_Pad0.98x0.95mm_HandSolder
R1203: 330R; R_0603_1608Metric_Pad0.98x0.95mm_HandSolder
R1204, R1206: 200R; R_0603_1608Metric_Pad0.98x0.95mm_HandSolder
R1205: 12k1; R_0603_1608Metric_Pad0.98x0.95mm_HandSolder
R1211, R1212, R1213, R1214: 50R; R_0603_1608Metric_Pad0.98x0.95mm_HandSolder
R1215: 10M; R_2512_6332Metric_Pad1.40x3.35mm_HandSolder
U1201: W6100L; LQFP-48_7x7mm_P0.5mm
U1203: 24AA025E48T-I/OT; SOT-23-6_Handsoldering

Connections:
25MHz: R1203.1; also elsewhere on the board
+3V3: C1202.2, C1217.2, FB1202.2, FB1203.2, FB1204.2, R1202.1, R1216.1, U1203.6 (VCC); also elsewhere on the board
/Ethernet/1V2A: C1205.2, FB1201.1, U1201.4 (1V2A)
/Ethernet/1V2O: C1204.1, C1206.1, C1208.1, FB1201.2, U1201.13 (1V2D), U1201.14 (1V2O), U1201.22 (1V2D), U1201.31 (1V2D), U1201.45 (1V2D)
/Ethernet/3V3A: C1209.1, FB1202.1, U1201.8 (3V3A), U1201.15 (3V3A)
/Ethernet/3V3D: C1210.1, FB1203.1, R1207.1, U1201.24 (3V3D), U1201.36 (3V3D)
/Ethernet/CTVDD: C1215.2, FB1204.1, J1201.L1 (LEDY_A), J1201.L4 (LEDG_A), J1201.R4 (TCT), J1201.R5 (RCT)
/Ethernet/LANSH: C1216.1, J1201.SH (SHIELD), R1215.1
/Ethernet/LEDGK: J1201.L3 (LEDG_K), R1209.2
/Ethernet/LEDYK: J1201.L2 (LEDY_K), R1210.2
/Ethernet/MOD0: R1208.1, U1201.25 (MOD0)
/Ethernet/MOD2: R1207.2, U1201.27 (MOD2)
/Ethernet/RDN: J1201.R6 (RD-), R1214.2, U1201.5 (RXIN)
/Ethernet/RDP: J1201.R3 (RD+), R1213.2, U1201.6 (RXIP)
/Ethernet/RSET: R1205.1, U1201.9 (RSET_BG)
/Ethernet/TDN: J1201.R2 (TD-), R1212.2, U1201.2 (TXON)
/Ethernet/TDP: J1201.R1 (TD+), R1211.2, U1201.3 (TXOP)
/Ethernet/XSCI: R1203.2, R1204.1, U1201.12 (XSCI)
/Ethernet/~ALED: R1210.1, U1201.20 (~ACT_LED)
/Ethernet/~LLED: R1209.1, U1201.17 (~LNK_LED)
/Ethernet/~WIZRST: C1201.2, R1201.2, R1202.2, U1201.48 (~RST)
A0: U1201.32 (MOSI/A0); also elsewhere on the board
A1: U1201.33 (MISO/A1); also elsewhere on the board
D0: U1201.37 (DAT0); also elsewhere on the board
D1: U1201.38 (DAT1); also elsewhere on the board
D2: U1201.39 (DAT2); also elsewhere on the board
D3: U1201.40 (DAT3); also elsewhere on the board
D4: U1201.41 (DAT4); also elsewhere on the board
D5: U1201.42 (DAT5); also elsewhere on the board
D6: U1201.43 (DAT6); also elsewhere on the board
D7: U1201.44 (DAT7); also elsewhere on the board
GND: C1201.1, C1202.1, C1204.2, C1205.1, C1206.2, C1208.2, C1209.2, C1210.2, C1213.1, C1214.1, C1215.1, C1216.2, C1217.1, J1201.R8 (GND), R1204.2, R1206.2, R1208.2, R1215.2, U1201.1 (GNDA), U1201.7 (GNDA), U1201.10 (GND), U1201.16 (GNDA), U1201.23 (GND), U1201.26 (MOD1), U1201.28 (MOD3), U1201.46 (GND), U1203.2 (GND), U1203.4 (A1), U1203.5 (A0); also elsewhere on the board
I2C_SCL: U1203.1 (SCL); also elsewhere on the board
I2C_SDA: U1203.3 (SDA); also elsewhere on the board
unnamed: C1213.2, R1211.1, R1212.1
unnamed: C1214.2, R1213.1, R1214.1
unnamed: R1205.2, R1206.1
~ECS2: U1201.29 (~CS); also elsewhere on the board
~EIRQ: R1216.2, U1201.47 (~INT); also elsewhere on the board
~ERST: R1201.1; also elsewhere on the board
~MRD: U1201.34 (~RD); also elsewhere on the board
~MWR: U1201.35 (~WR); also elsewhere on the board

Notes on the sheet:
EEPROM 24AA025E48 I2C DEVICE ADDRESS (8b=shifted) = 0b1010_000W = 0xA0, that is 7-bit address = 0x28
package LQFP-48
CAD: resistor termination on MDI should be placed close to U801.
XSCI requires 25MHz @ 1.2V levels, rise/fall time <8ns
Pin RSET requires 12.3k resistor to GND.
10/100Mbit Ethernet Interface
EEPROM with Factory Pre-Programmed Unique EUI-48 = MAC address for Wiznet

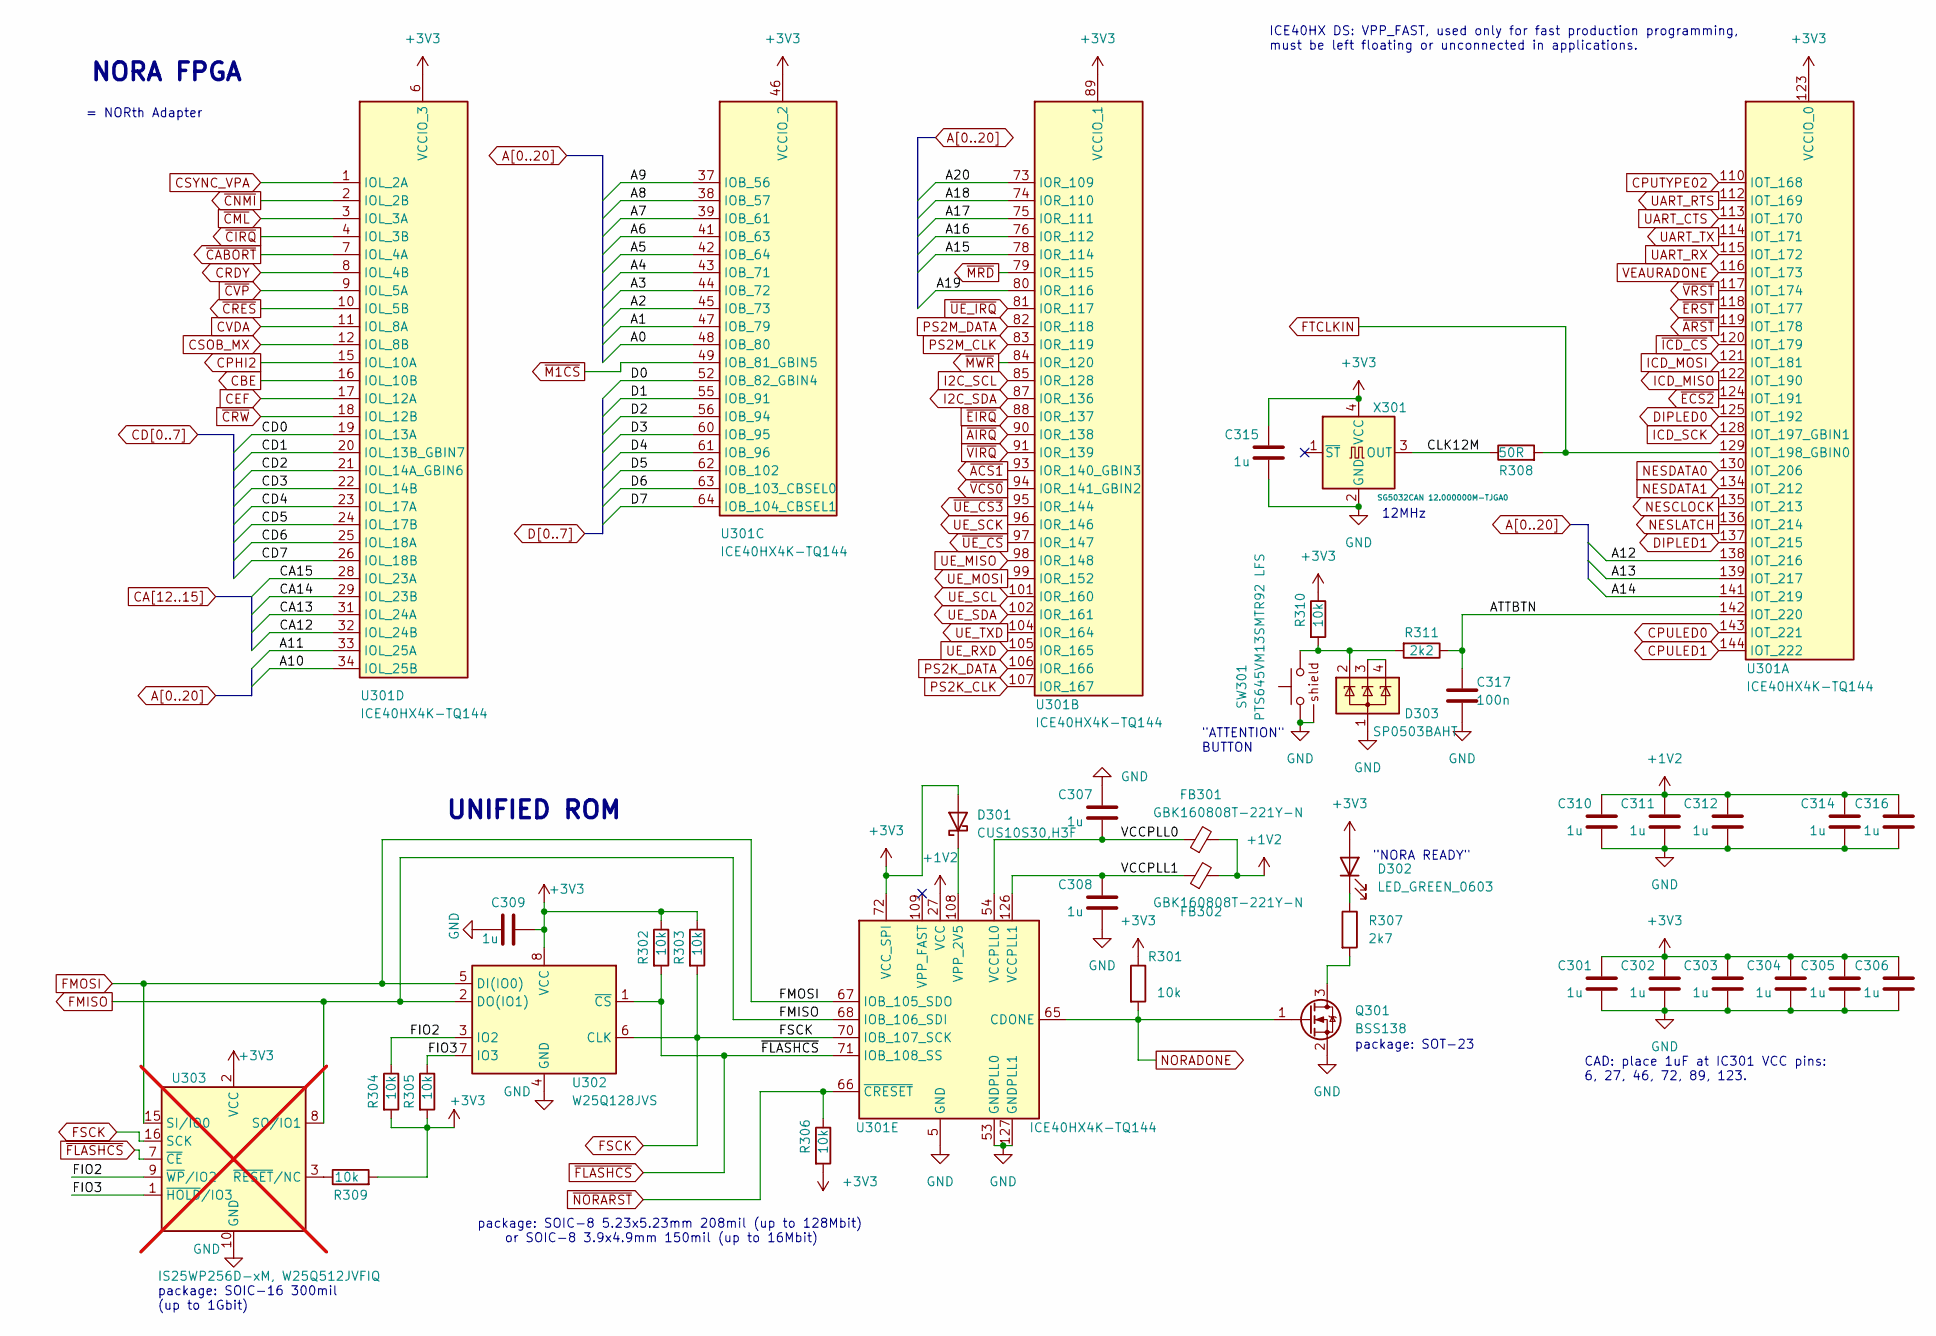
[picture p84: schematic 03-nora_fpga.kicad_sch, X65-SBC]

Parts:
C301, C302, C303, C304, C305, C306, C307, C308, C309, C310, C311, C312, C314, C315, C316: 1u; C_0603_1608Metric_Pad1.08x0.95mm_HandSolder
C317: 100n; C_0603_1608Metric_Pad1.08x0.95mm_HandSolder
D301: CUS10S30,H3F; D_SOD-323_HandSoldering
D302: LED_GREEN_0603; LED_0603_1608Metric_Pad1.05x0.95mm_HandSolder
D303: SP0503BAHT; SOT-143
FB301, FB302: GBK160808T-221Y-N; R_0603_1608Metric_Pad0.98x0.95mm_HandSolder
Q301: BSS138; SOT-23
R301, R302, R303, R304, R305, R306, R309, R310: 10k; R_0603_1608Metric_Pad0.98x0.95mm_HandSolder
R307: 2k7; R_0603_1608Metric_Pad0.98x0.95mm_HandSolder
R308: 50R; R_0603_1608Metric_Pad0.98x0.95mm_HandSolder
R311: 2k2; R_0603_1608Metric_Pad0.98x0.95mm_HandSolder
SW301: PTS645VM13SMTR92 LFS
U301: ICE40HX4K-TQ144; TQFP-144_20x20mm_P0.5mm
U302: W25Q128JVS; SOIC-8_5.23x5.23mm_P1.27mm_Extended
U303: IS25WP256D-xM, W25Q512JVFIQ; SOIC-16W_7.5x10.3mm_P1.27mm; not fitted
X301: SG5032CAN 12.000000M-TJGA0; Oscillator_SMD_SeikoEpson_SG8002LB-4Pin_5.0x3.2mm_HandSolde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

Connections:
+1V2: C310.1, C311.1, C312.1, C314.1, C316.1, FB301.2, FB302.2, U301.27 (VCC), U301.40 (VCC), U301.92 (VCC), U301.111 (VCC); also elsewhere on the board
+3V3: C301.1, C302.1, C303.1, C304.1, C305.1, C306.1, C309.1, C315.1, D301.2 (A), D302.2 (A), R301.1, R302.1, R303.1, R304.2, R305.2, R306.2, R309.2, R310.1, U301.6 (VCCIO_3), U301.30 (VCCIO_3), U301.46 (VCCIO_2), U301.57 (VCCIO_2), U301.72 (VCC_SPI), U301.89 (VCCIO_1), U301.100 (VCCIO_1), U301.123 (VCCIO_0), U301.131 (VCCIO_0), U302.8 (VCC), U303.2 (VCC), X301.4 (VCC); also elsewhere on the board
/NORA FPGA/ATTBTN: C317.1, R311.1, U301.142 (IOT_220)
/NORA FPGA/CLK12M: R308.1, X301.3 (OUT)
/NORA FPGA/FIO2: R304.1, U302.3 (IO2), U303.9 (~WP/IO2)
/NORA FPGA/FIO3: R305.1, U302.7 (IO3), U303.1 (~HOLD/IO3)
/NORA FPGA/VCCPLL0: C307.2, FB301.1, U301.54 (VCCPLL0)
/NORA FPGA/VCCPLL1: C308.1, FB302.1, U301.126 (VCCPLL1)
A0: U301.48 (IOB_80); also elsewhere on the board
A1: U301.47 (IOB_79); also elsewhere on the board
A2: U301.45 (IOB_73); also elsewhere on the board
A3: U301.44 (IOB_72); also elsewhere on the board
A4: U301.43 (IOB_71); also elsewhere on the board
A5: U301.42 (IOB_64); also elsewhere on the board
A6: U301.41 (IOB_63); also elsewhere on the board
A7: U301.39 (IOB_61); also elsewhere on the board
A8: U301.38 (IOB_57); also elsewhere on the board
A9: U301.37 (IOB_56); also elsewhere on the board
A10: U301.34 (IOL_25B); also elsewhere on the board
A11: U301.33 (IOL_25A); also elsewhere on the board
A12: U301.138 (IOT_216); also elsewhere on the board
A13: U301.139 (IOT_217); also elsewhere on the board
A14: U301.141 (IOT_219); also elsewhere on the board
A15: U301.78 (IOR_114); also elsewhere on the board
A16: U301.76 (IOR_112); also elsewhere on the board
A17: U301.75 (IOR_111); also elsewhere on the board
A18: U301.74 (IOR_110); also elsewhere on the board
A19: U301.80 (IOR_116); also elsewhere on the board
A20: U301.73 (IOR_109); also elsewhere on the board
CA12: U301.32 (IOL_24B); also elsewhere on the board
CA13: U301.31 (IOL_24A); also elsewhere on the board
CA14: U301.29 (IOL_23B); also elsewhere on the board
CA15: U301.28 (IOL_23A); also elsewhere on the board
CBE: U301.16 (IOL_10B); also elsewhere on the board
CD0: U301.19 (IOL_13A); also elsewhere on the board
CD1: U301.20 (IOL_13B_GBIN7); also elsewhere on the board
CD2: U301.21 (IOL_14A_GBIN6); also elsewhere on the board
CD3: U301.22 (IOL_14B); also elsewhere on the board
CD4: U301.23 (IOL_17A); also elsewhere on the board
CD5: U301.24 (IOL_17B); also elsewhere on the board
CD6: U301.25 (IOL_18A); also elsewhere on the board
CD7: U301.26 (IOL_18B); also elsewhere on the board
CEF: U301.17 (IOL_12A); also elsewhere on the board
CPHI2: U301.15 (IOL_10A); also elsewhere on the board
CPULED0: U301.143 (IOT_221); also elsewhere on the board
CPULED1: U301.144 (IOT_222); also elsewhere on the board
CPUTYPE02: U301.110 (IOT_168); also elsewhere on the board
CRDY: U301.8 (IOL_4B); also elsewhere on the board
CSOB_MX: U301.12 (IOL_8B); also elsewhere on the board
CSYNC_VPA: U301.1 (IOL_2A); also elsewhere on the board
CVDA: U301.11 (IOL_8A); also elsewhere on the board
D0: U301.52 (IOB_82_GBIN4); also elsewhere on the board
D1: U301.55 (IOB_91); also elsewhere on the board
D2: U301.56 (IOB_94); also elsewhere on the board
D3: U301.60 (IOB_95); also elsewhere on the board
D4: U301.61 (IOB_96); also elsewhere on the board
D5: U301.62 (IOB_102); also elsewhere on the board
D6: U301.63 (IOB_103_CBSEL0); also elsewhere on the board
D7: U301.64 (IOB_104_CBSEL1); also elsewhere on the board
DIPLED0: U301.125 (IOT_192); also elsewhere on the board
DIPLED1: U301.137 (IOT_215); also elsewhere on the board
FMISO: U301.68 (IOB_106_SDI), U302.2 (DO(IO1)), U303.8 (SO/IO1); also elsewhere on the board
FMOSI: U301.67 (IOB_105_SDO), U302.5 (DI(IO0)), U303.15 (SI/IO0); also elsewhere on the board
FSCK: R303.2, U301.70 (IOB_107_SCK), U302.6 (CLK), U303.16 (SCK); also elsewhere on the board
FTCLKIN: R308.2, U301.129 (IOT_198_GBIN0); also elsewhere on the board
GND: C301.2, C302.2, C303.2, C304.2, C305.2, C306.2, C307.1, C308.2, C309.2, C310.2, C311.2, C312.2, C314.2, C315.2, C316.2, C317.2, D303.1 (A), Q301.2 (S), SW301.1, SW301.SH, U301.5 (GND), U301.13 (GND), U301.14 (GND), U301.53 (GNDPLL0), U301.59 (GND), U301.69 (GND), U301.86 (GND), U301.103 (GND), U301.127 (GNDPLL1), U301.132 (GND), U301.140 (GND), U302.4 (GND), U303.10 (GND), X301.2 (GND); also elsewhere on the board
I2C_SCL: U301.85 (IOR_128); also elsewhere on the board
I2C_SDA: U301.87 (IOR_136); also elsewhere on the board
ICD_MISO: U301.122 (IOT_190); also elsewhere on the board
ICD_MOSI: U301.121 (IOT_181); also elsewhere on the board
ICD_SCK: U301.128 (IOT_197_GBIN1); also elsewhere on the board
NESCLOCK: U301.135 (IOT_213); also elsewhere on the board
NESDATA0: U301.130 (IOT_206); also elsewhere on the board
NESDATA1: U301.134 (IOT_212); also elsewhere on the board
NESLATCH: U301.136 (IOT_214); also elsewhere on the board
NORADONE: Q301.1 (G), R301.2, U301.65 (CDONE); also elsewhere on the board
unnamed: D301.1 (K), U301.108 (VPP_2V5)
unnamed: D302.1 (K), R307.1
unnamed: D303.2 (K), R310.2, R311.2, SW301.2
unnamed: D303.3 (K), D303.4 (K)
unnamed: Q301.3 (D), R307.2
unnamed: R309.1, U303.3 (~RESET/NC)
PS2K_CLK: U301.107 (IOR_167); also elsewhere on the board
PS2K_DATA: U301.106 (IOR_166); also elsewhere on the board
PS2M_CLK: U301.83 (IOR_119); also elsewhere on the board
PS2M_DATA: U301.82 (IOR_118); also elsewhere on the board
UART_CTS: U301.113 (IOT_170); also elsewhere on the board
UART_RTS: U301.112 (IOT_169); also elsewhere on the board
UART_RX: U301.115 (IOT_172); also elsewhere on the board
UART_TX: U301.114 (IOT_171); also elsewhere on the board
UE_MISO: U301.98 (IOR_148); also elsewhere on the board
UE_MOSI: U301.99 (IOR_152); also elsewhere on the board
UE_RXD: U301.105 (IOR_165); also elsewhere on the board
UE_SCK: U301.96 (IOR_146); also elsewhere on the board
UE_SCL: U301.101 (IOR_160); also elsewhere on the board
UE_SDA: U301.102 (IOR_161); also elsewhere on the board
UE_TXD: U301.104 (IOR_164); also elsewhere on the board
VEAURADONE: U301.116 (IOT_173); also elsewhere on the board
~ACS1: U301.93 (IOR_140_GBIN3); also elsewhere on the board
~AIRQ: U301.90 (IOR_138); also elsewhere on the board
~ARST: U301.119 (IOT_178); also elsewhere on the board
~CABORT: U301.7 (IOL_4A); also elsewhere on the board
~CIRQ: U301.4 (IOL_3B); also elsewhere on the board
~CML: U301.3 (IOL_3A); also elsewhere on the board
~CNMI: U301.2 (IOL_2B); also elsewhere on the board
~CRES: U301.10 (IOL_5B); also elsewhere on the board
~CRW: U301.18 (IOL_12B); also elsewhere on the board
~CVP: U301.9 (IOL_5A); also elsewhere on the board
~ECS2: U301.124 (IOT_191); also elsewhere on the board
~EIRQ: U301.88 (IOR_137); also elsewhere on the board
~ERST: U301.118 (IOT_177); also elsewhere on the board
~FLASHCS: R302.2, U301.71 (IOB_108_SS), U302.1 (~CS), U303.7 (~CE); also elsewhere on the board
~ICD_CS: U301.120 (IOT_179); also elsewhere on the board
~M1CS: U301.49 (IOB_81_GBIN5); also elsewhere on the board
~MRD: U301.79 (IOR_115); also elsewhere on the board
~MWR: U301.84 (IOR_120); also elsewhere on the board
~NORARST: R306.1, U301.66 (~CRESET); also elsewhere on the board
~UE_CS3: U301.95 (IOR_144); also elsewhere on the board
~UE_CS: U301.97 (IOR_147); also elsewhere on the board
~UE_IRQ: U301.81 (IOR_117); also elsewhere on the board
~VCS0: U301.94 (IOR_141_GBIN2); also elsewhere on the board
~VIRQ: U301.91 (IOR_139); also elsewhere on the board
~VRST: U301.117 (IOT_174); also elsewhere on the board

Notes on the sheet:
package: SOIC-8 5.23x5.23mm 208mil (up to 128Mbit) or SOIC-8 3.9x4.9mm 150mil (up to 16Mbit)
12MHz
= NORth Adapter
ICE40HX DS: VPP_FAST, used only for fast production programming, must be left floating or unconnected in applications.
"NORA READY"
NORA FPGA
UNIFIED ROM
package: SOIC-16 300mil (up to 1Gbit)
package: SOT-23
"ATTENTION" BUTTON
CAD: place 1uF at IC301 VCC pins: 6, 27, 46, 72, 89, 123.

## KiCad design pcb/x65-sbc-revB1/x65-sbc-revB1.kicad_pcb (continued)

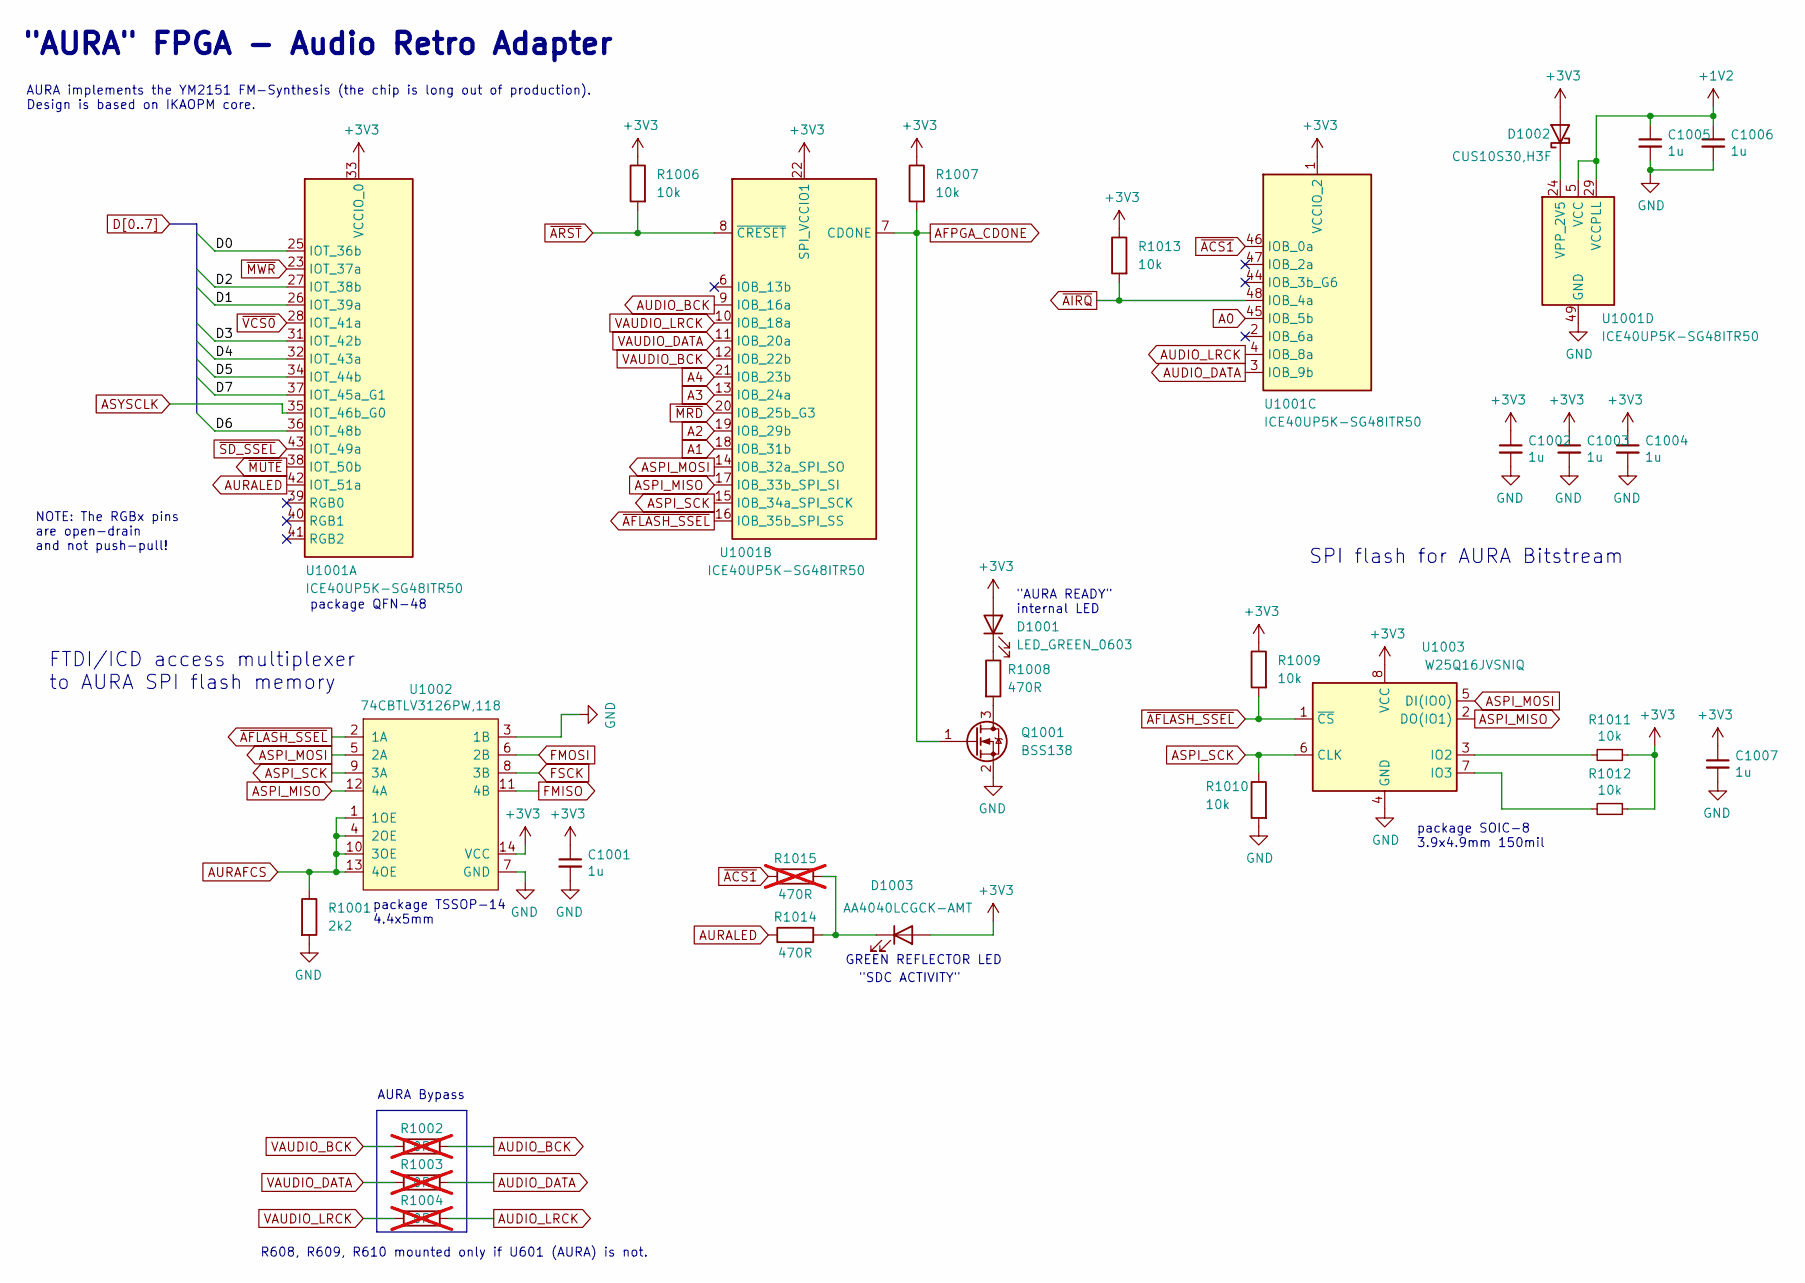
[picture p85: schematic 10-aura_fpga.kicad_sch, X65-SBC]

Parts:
C1001, C1002, C1003, C1004, C1005, C1006, C1007: 1u; C_0603_1608Metric_Pad1.08x0.95mm_HandSolder
D1001: LED_GREEN_0603; LED_0603_1608Metric_Pad1.05x0.95mm_HandSolder
D1002: CUS10S30,H3F; D_SOD-323_HandSoldering
D1003: AA4040LCGCK-AMT; PLCC2_4x4mm
Q1001: BSS138; SOT-23
R1001: 2k2; R_0603_1608Metric_Pad0.98x0.95mm_HandSolder
R1002, R1003, R1004: 0R; R_0603_1608Metric_Pad0.98x0.95mm_HandSolder; not fitted
R1006, R1007, R1009, R1010, R1011, R1012, R1013: 10k; R_0603_1608Metric_Pad0.98x0.95mm_HandSolder
R1008, R1014: 470R; R_0603_1608Metric_Pad0.98x0.95mm_HandSolder
R1015: 470R; R_0603_1608Metric_Pad0.98x0.95mm_HandSolder; not fitted
U1001: ICE40UP5K-SG48ITR50; QFN-48-1EP_7x7mm_P0.5mm_EP5.3x5.3mm
U1002: 74CBTLV3126PW,118; TSSOP-14_4.4x5mm_P0.65mm
U1003: W25Q16JVSNIQ; SOIC-8_3.9x4.9mm_P1.27mm

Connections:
+1V2: C1005.1, C1006.1, U1001.5 (VCC), U1001.29 (VCCPLL), U1001.30 (VCC); also elsewhere on the board
+3V3: C1001.1, C1002.1, C1003.1, C1004.1, C1007.1, D1001.2 (A), D1002.2 (A), D1003.2 (A), R1006.1, R1007.1, R1009.1, R1011.1, R1012.1, R1013.1, U1001.1 (VCCIO_2), U1001.22 (SPI_VCCIO1), U1001.33 (VCCIO_0), U1002.14 (VCC), U1003.8 (VCC); also elsewhere on the board
A0: U1001.45 (IOB_5b); also elsewhere on the board
A1: U1001.18 (IOB_31b); also elsewhere on the board
A2: U1001.19 (IOB_29b); also elsewhere on the board
A3: U1001.13 (IOB_24a); also elsewhere on the board
A4: U1001.21 (IOB_23b); also elsewhere on the board
AFPGA_CDONE: Q1001.1 (G), R1007.2, U1001.7 (CDONE); also elsewhere on the board
ASPI_MISO: U1001.17 (IOB_33b_SPI_SI), U1002.12 (4A), U1003.2 (DO(IO1))
ASPI_MOSI: U1001.14 (IOB_32a_SPI_SO), U1002.5 (2A), U1003.5 (DI(IO0))
ASPI_SCK: R1010.1, U1001.15 (IOB_34a_SPI_SCK), U1002.9 (3A), U1003.6 (CLK)
ASYSCLK: U1001.35 (IOT_46b_G0); also elsewhere on the board
AUDIO_BCK: R1002.2, U1001.9 (IOB_16a); also elsewhere on the board
AUDIO_DATA: R1003.2, U1001.3 (IOB_9b); also elsewhere on the board
AUDIO_LRCK: R1004.2, U1001.4 (IOB_8a); also elsewhere on the board
AURAFCS: R1001.1, U1002.1 (1OE), U1002.4 (2OE), U1002.10 (3OE), U1002.13 (4OE); also elsewhere on the board
AURALED: R1014.1, U1001.42 (IOT_51a)
D0: U1001.25 (IOT_36b); also elsewhere on the board
D1: U1001.26 (IOT_39a); also elsewhere on the board
D2: U1001.27 (IOT_38b); also elsewhere on the board
D3: U1001.31 (IOT_42b); also elsewhere on the board
D4: U1001.32 (IOT_43a); also elsewhere on the board
D5: U1001.34 (IOT_44b); also elsewhere on the board
D6: U1001.36 (IOT_48b); also elsewhere on the board
D7: U1001.37 (IOT_45a_G1); also elsewhere on the board
FMISO: U1002.11 (4B); also elsewhere on the board
FMOSI: U1002.6 (2B); also elsewhere on the board
FSCK: U1002.8 (3B); also elsewhere on the board
GND: C1001.2, C1002.2, C1003.2, C1004.2, C1005.2, C1006.2, C1007.2, Q1001.2 (S), R1001.2, R1010.2, U1001.49 (GND), U1002.3 (1B), U1002.7 (GND), U1003.4 (GND); also elsewhere on the board
unnamed: D1001.1 (K), R1008.1
unnamed: D1002.1 (K), U1001.24 (VPP_2V5)
unnamed: D1003.1 (K), R1014.2, R1015.2
unnamed: Q1001.3 (D), R1008.2
unnamed: R1011.2, U1003.3 (IO2)
unnamed: R1012.2, U1003.7 (IO3)
VAUDIO_BCK: R1002.1, U1001.12 (IOB_22b); also elsewhere on the board
VAUDIO_DATA: R1003.1, U1001.11 (IOB_20a); also elsewhere on the board
VAUDIO_LRCK: R1004.1, U1001.10 (IOB_18a); also elsewhere on the board
~ACS1: R1015.1, U1001.46 (IOB_0a); also elsewhere on the board
~AFLASH_SSEL: R1009.2, U1001.16 (IOB_35b_SPI_SS), U1002.2 (1A), U1003.1 (~CS)
~AIRQ: R1013.2, U1001.48 (IOB_4a); also elsewhere on the board
~ARST: R1006.2, U1001.8 (~CRESET); also elsewhere on the board
~MRD: U1001.20 (IOB_25b_G3); also elsewhere on the board
~MUTE: U1001.38 (IOT_50b); also elsewhere on the board
~MWR: U1001.23 (IOT_37a); also elsewhere on the board
~SD_SSEL: U1001.43 (IOT_49a); also elsewhere on the board
~VCS0: U1001.28 (IOT_41a); also elsewhere on the board

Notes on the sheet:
R608, R609, R610 mounted only if U601 (AURA) is not.
package TSSOP-14 4.4x5mm
"AURA" FPGA - Audio Retro Adapter
GREEN REFLECTOR LED
FTDI/ICD access multiplexer to AURA SPI flash memory
SPI flash for AURA Bitstream
package QFN-48
"SDC ACTIVITY"
AURA Bypass
NOTE: The RGBx pins are open-drain and not push-pull!
package SOIC-8 3.9x4.9mm 150mil
"AURA READY" internal LED
AURA implements the YM2151 FM-Synthesis (the chip is long out of production). Design is based on IKAOPM core.

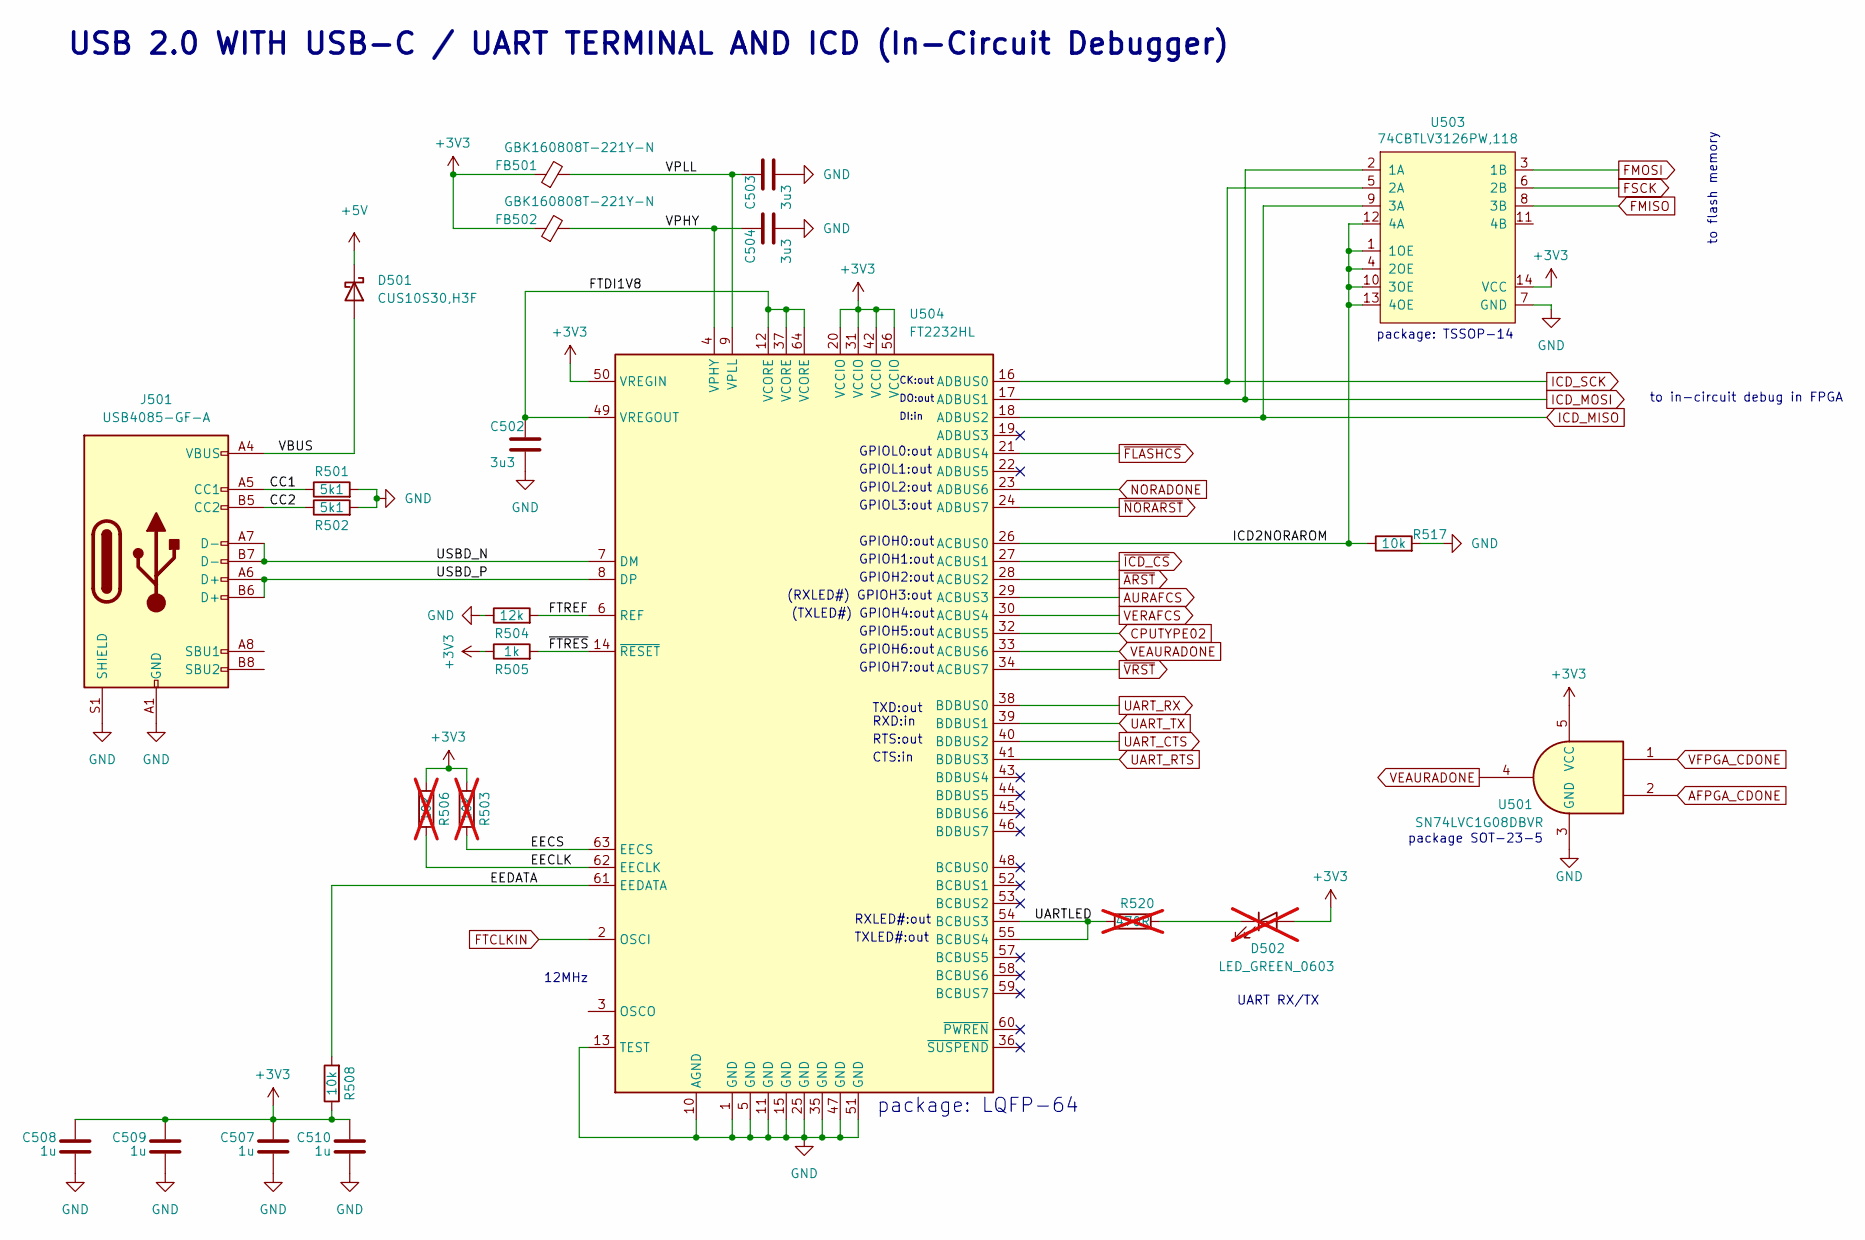
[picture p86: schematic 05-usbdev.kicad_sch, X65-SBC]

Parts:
C502, C503, C504: 3u3; C_0603_1608Metric_Pad1.08x0.95mm_HandSolder
C507, C508, C509, C510: 1u; C_0603_1608Metric_Pad1.08x0.95mm_HandSolder
D501: CUS10S30,H3F; D_SOD-323_HandSoldering
D502: LED_GREEN_0603; LED_0603_1608Metric_Pad1.05x0.95mm_HandSolder; not fitted
FB501, FB502: GBK160808T-221Y-N; R_0603_1608Metric_Pad0.98x0.95mm_HandSolder
J501: USB4085-GF-A; USB_C_Receptacle_GCT_USB4085
R501, R502: 5k1; R_0603_1608Metric_Pad0.98x0.95mm_HandSolder
R503, R506: 10k; R_0603_1608Metric_Pad0.98x0.95mm_HandSolder; not fitted
R504: 12k; R_0603_1608Metric_Pad0.98x0.95mm_HandSolder
R505: 1k; R_0603_1608Metric_Pad0.98x0.95mm_HandSolder
R508, R517: 10k; R_0603_1608Metric_Pad0.98x0.95mm_HandSolder
R520: 470R; R_0603_1608Metric_Pad0.98x0.95mm_HandSolder; not fitted
U501: SN74LVC1G08DBVR; SOT-23-5_HandSoldering
U503: 74CBTLV3126PW,118; TSSOP-14_4.4x5mm_P0.65mm
U504: FT2232HL; LQFP-64_10x10mm_P0.5mm

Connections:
+3V3: C507.1, C508.1, C509.1, C510.1, D502.2 (A), FB501.1, FB502.1, R503.2, R505.1, R506.2, R508.1, U501.5 (VCC), U503.14 (VCC), U504.20 (VCCIO), U504.31 (VCCIO), U504.42 (VCCIO), U504.50 (VREGIN), U504.56 (VCCIO); also elsewhere on the board
+5V: D501.1 (K); also elsewhere on the board
/USB-Terminal/CC1: J501.A5 (CC1), R501.1
/USB-Terminal/CC2: J501.B5 (CC2), R502.1
/USB-Terminal/EECLK: R506.1, U504.62 (EECLK)
/USB-Terminal/EECS: R503.1, U504.63 (EECS)
/USB-Terminal/EEDATA: R508.2, U504.61 (EEDATA)
/USB-Terminal/FTDI1V8: C502.1, U504.12 (VCORE), U504.37 (VCORE), U504.49 (VREGOUT), U504.64 (VCORE)
/USB-Terminal/FTREF: R504.2, U504.6 (REF)
/USB-Terminal/ICD2NORAROM: R517.1, U503.1 (1OE), U503.4 (2OE), U503.10 (3OE), U503.12 (4A), U503.13 (4OE), U504.26 (ACBUS0)
/USB-Terminal/UARTLED: R520.1, U504.54 (BCBUS3), U504.55 (BCBUS4)
/USB-Terminal/USBD_N: J501.A7 (D-), J501.B7 (D-), U504.7 (DM)
/USB-Terminal/USBD_P: J501.A6 (D+), J501.B6 (D+), U504.8 (DP)
/USB-Terminal/VBUS: D501.2 (A), J501.A4 (VBUS), J501.A9 (VBUS), J501.B4 (VBUS), J501.B9 (VBUS)
/USB-Terminal/VPHY: C504.1, FB502.2, U504.4 (VPHY)
/USB-Terminal/VPLL: C503.1, FB501.2, U504.9 (VPLL)
/USB-Terminal/~FTRES: R505.2, U504.14 (~RESET)
AFPGA_CDONE: U501.2; also elsewhere on the board
AURAFCS: U504.29 (ACBUS3); also elsewhere on the board
CPUTYPE02: U504.32 (ACBUS5); also elsewhere on the board
FMISO: U503.8 (3B); also elsewhere on the board
FMOSI: U503.3 (1B); also elsewhere on the board
FSCK: U503.6 (2B); also elsewhere on the board
FTCLKIN: U504.2 (OSCI); also elsewhere on the board
GND: C502.2, C503.2, C504.2, C507.2, C508.2, C509.2, C510.2, J501.A1 (GND), J501.A12 (GND), J501.B1 (GND), J501.B12 (GND), J501.S1 (SHIELD), R501.2, R502.2, R504.1, R517.2, U501.3 (GND), U503.7 (GND), U504.1 (GND), U504.5 (GND), U504.10 (AGND), U504.11 (GND), U504.13 (TEST), U504.15 (GND), U504.25 (GND), U504.35 (GND), U504.47 (GND), U504.51 (GND); also elsewhere on the board
ICD_MISO: U503.9 (3A), U504.18 (ADBUS2); also elsewhere on the board
ICD_MOSI: U503.2 (1A), U504.17 (ADBUS1); also elsewhere on the board
ICD_SCK: U503.5 (2A), U504.16 (ADBUS0); also elsewhere on the board
NORADONE: U504.23 (ADBUS6); also elsewhere on the board
unnamed: D502.1 (K), R520.2
UART_CTS: U504.40 (BDBUS2); also elsewhere on the board
UART_RTS: U504.41 (BDBUS3); also elsewhere on the board
UART_RX: U504.38 (BDBUS0); also elsewhere on the board
UART_TX: U504.39 (BDBUS1); also elsewhere on the board
VEAURADONE: U501.4, U504.33 (ACBUS6); also elsewhere on the board
VERAFCS: U504.30 (ACBUS4); also elsewhere on the board
VFPGA_CDONE: U501.1; also elsewhere on the board
~ARST: U504.28 (ACBUS2); also elsewhere on the board
~FLASHCS: U504.21 (ADBUS4); also elsewhere on the board
~ICD_CS: U504.27 (ACBUS1); also elsewhere on the board
~NORARST: U504.24 (ADBUS7); also elsewhere on the board
~VRST: U504.34 (ACBUS7); also elsewhere on the board

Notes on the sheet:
GPIOH6:out
GPIOL0:out
12MHz
TXLED#:out
CK:out
to in-circuit debug in FPGA
RXLED#:out
(RXLED#) GPIOH3:out
GPIOL3:out
(TXLED#) GPIOH4:out
GPIOH1:out
RTS:out
GPIOH2:out
package: LQFP-64
to flash memory
GPIOL2:out
CTS:in
DI:in
package: TSSOP-14
GPIOL1:out
DO:out
UART RX/TX
RXD:in
GPIOH7:out
TXD:out
package SOT-23-5
GPIOH5:out
USB 2.0 WITH USB-C / UART TERMINAL AND ICD (In-Circuit Debugger)
GPIOH0:out

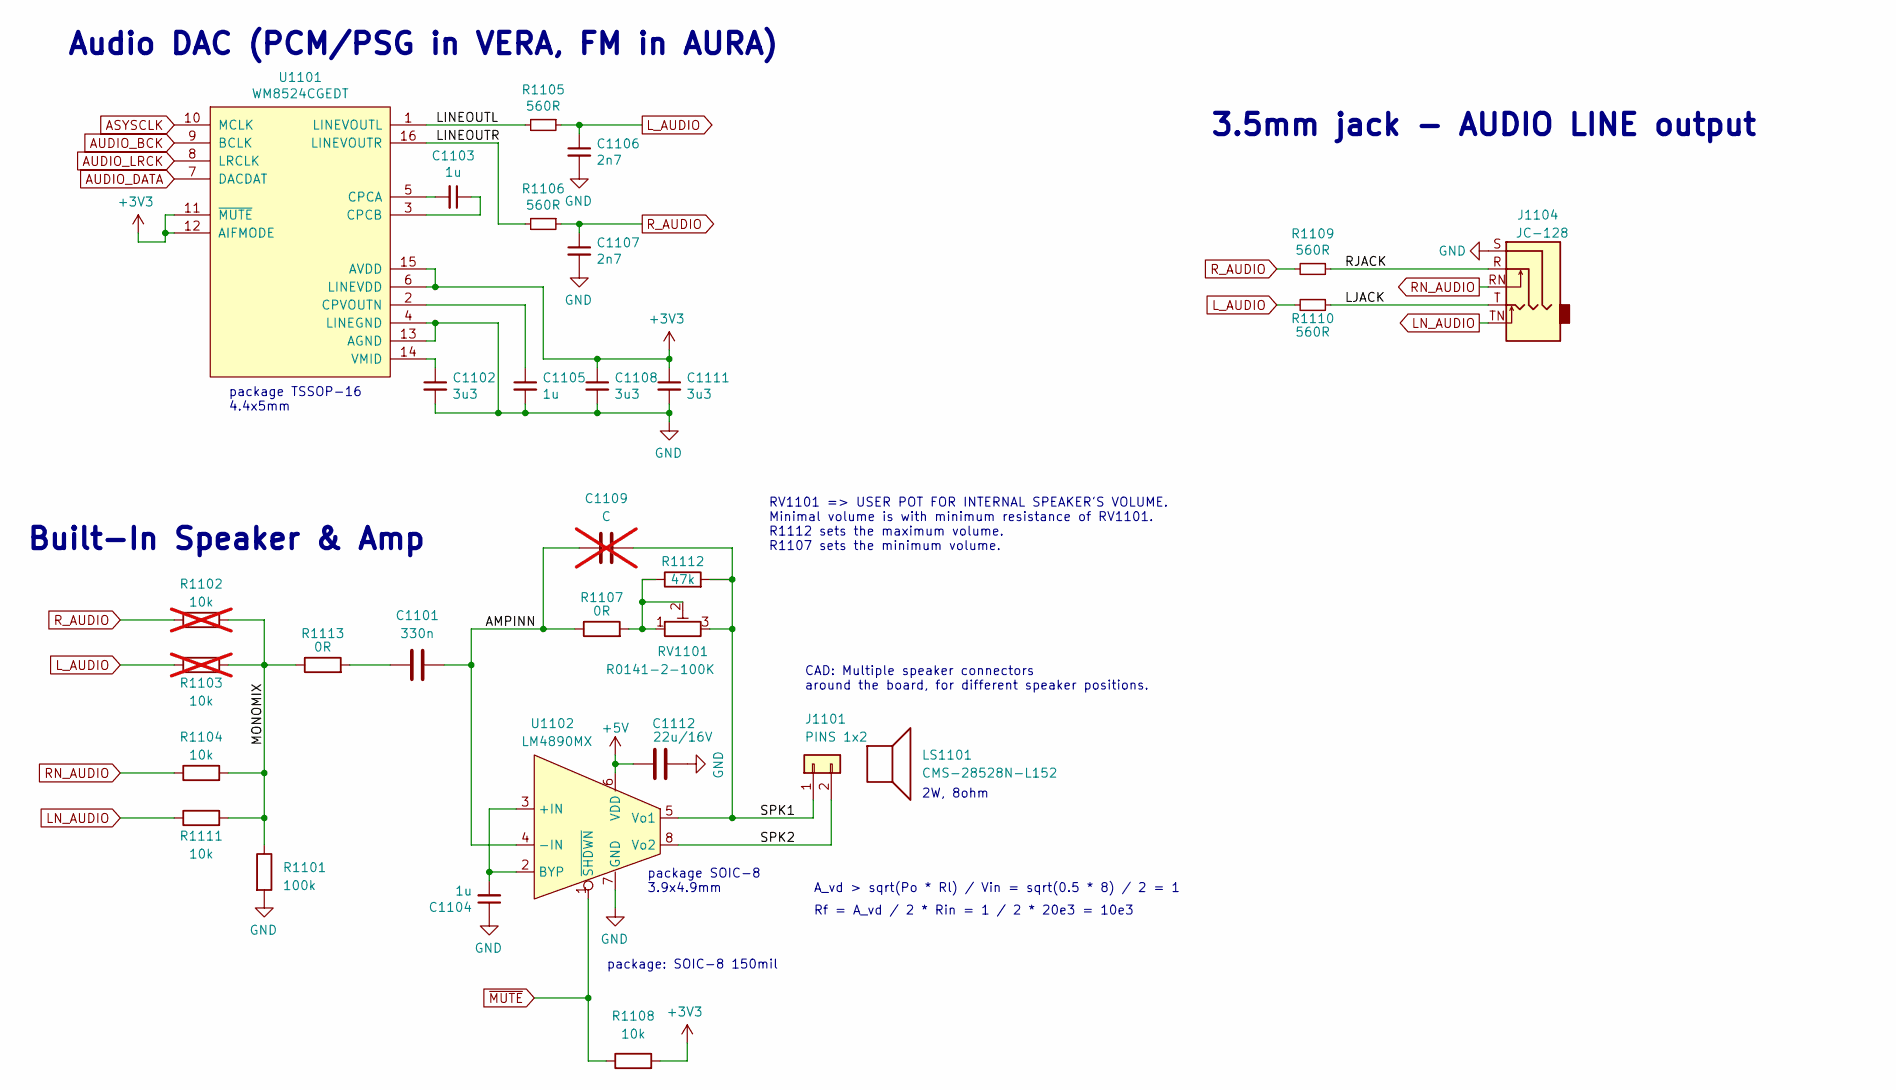
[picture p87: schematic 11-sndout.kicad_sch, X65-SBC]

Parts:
C1101: 330n; C_0603_1608Metric_Pad1.08x0.95mm_HandSolder
C1102, C1108, C1111: 3u3; C_0603_1608Metric_Pad1.08x0.95mm_HandSolder
C1103, C1104, C1105: 1u; C_0603_1608Metric_Pad1.08x0.95mm_HandSolder
C1106, C1107: 2n7; C_0603_1608Metric_Pad1.08x0.95mm_HandSolder
C1109: C; C_0603_1608Metric_Pad1.08x0.95mm_HandSolder; not fitted
C1112: 22u/16V; C_0805_2012Metric_Pad1.18x1.45mm_HandSolder
J1101: PINS 1x2; PinHeader_1x02_P2.54mm_Horizontal
J1104: JC-128
LS1101: CMS-28528N-L152
R1101: 100k; R_0603_1608Metric_Pad0.98x0.95mm_HandSolder
R1102, R1103: 10k; R_0603_1608Metric_Pad0.98x0.95mm_HandSolder; not fitted
R1104, R1108, R1111: 10k; R_0603_1608Metric_Pad0.98x0.95mm_HandSolder
R1105, R1106, R1109, R1110: 560R; R_0603_1608Metric_Pad0.98x0.95mm_HandSolder
R1107, R1113: 0R; R_0603_1608Metric_Pad0.98x0.95mm_HandSolder
R1112: 47k; R_0603_1608Metric_Pad0.98x0.95mm_HandSolder
RV1101: R0141-2-100K; Trimmer_R0141-2
U1101: WM8524CGEDT; TSSOP-16_4.4x5mm_P0.65mm
U1102: LM4890MX; SOIC-8_3.9x4.9mm_P1.27mm

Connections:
+3V3: C1108.1, C1111.1, R1108.2, U1101.6 (LINEVDD), U1101.11 (~MUTE), U1101.12 (AIFMODE), U1101.15 (AVDD); also elsewhere on the board
+5V: C1112.2, U1102.6 (VDD); also elsewhere on the board
/Sound Output/AMPINN: C1101.2, C1109.1, R1107.1, U1102.4 (-IN)
/Sound Output/LINEOUTL: R1105.2, U1101.1 (LINEVOUTL)
/Sound Output/LINEOUTR: R1106.2, U1101.16 (LINEVOUTR)
/Sound Output/LJACK: J1104.T, R1110.1
/Sound Output/MONOMIX: R1101.1, R1102.2, R1103.2, R1104.2, R1111.2, R1113.1
/Sound Output/RJACK: J1104.R, R1109.1
/Sound Output/SPK1: C1109.2, J1101.1, R1112.2, RV1101.3, U1102.5 (Vo1)
/Sound Output/SPK2: J1101.2, U1102.8 (Vo2)
ASYSCLK: U1101.10 (MCLK); also elsewhere on the board
AUDIO_BCK: U1101.9 (BCLK); also elsewhere on the board
AUDIO_DATA: U1101.7 (DACDAT); also elsewhere on the board
AUDIO_LRCK: U1101.8 (LRCLK); also elsewhere on the board
GND: C1102.2, C1104.1, C1105.2, C1106.2, C1107.2, C1108.2, C1111.2, C1112.1, J1104.S, R1101.2, U1101.4 (LINEGND), U1101.13 (AGND), U1102.7 (GND); also elsewhere on the board
LN_AUDIO: J1104.TN, R1111.1
L_AUDIO: C1106.1, R1103.1, R1105.1, R1110.2
unnamed: C1101.1, R1113.2
unnamed: R1107.2, R1112.1, RV1101.1, RV1101.2
unnamed: C1103.2, U1101.5 (CPCA)
unnamed: C1103.1, U1101.3 (CPCB)
unnamed: C1105.1, U1101.2 (CPVOUTN)
unnamed: C1102.1, U1101.14 (VMID)
unnamed: C1104.2, U1102.2 (BYP), U1102.3 (+IN)
RN_AUDIO: J1104.RN, R1104.1
R_AUDIO: C1107.1, R1102.1, R1106.1, R1109.2
~MUTE: R1108.1, U1102.1 (~SHDWN); also elsewhere on the board

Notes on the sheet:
Built-In Speaker & Amp
package TSSOP-16 4.4x5mm
3.5mm jack - AUDIO LINE output
CAD: Multiple speaker connectors around the board, for different speaker positions.
2W, 8ohm
A_vd > sqrt(Po * Rl) / Vin = sqrt(0.5 * 8) / 2 = 1
RV1101 => USER POT FOR INTERNAL SPEAKER'S VOLUME. Minimal volume is with minimum resistance of RV1101. R1112 sets the maximum volume. R1107 sets the minimum volume.
package: SOIC-8 150mil
Audio DAC (PCM/PSG in VERA, FM in AURA)
package SOIC-8 3.9x4.9mm
Rf = A_vd / 2 * Rin = 1 / 2 * 20e3 = 10e3

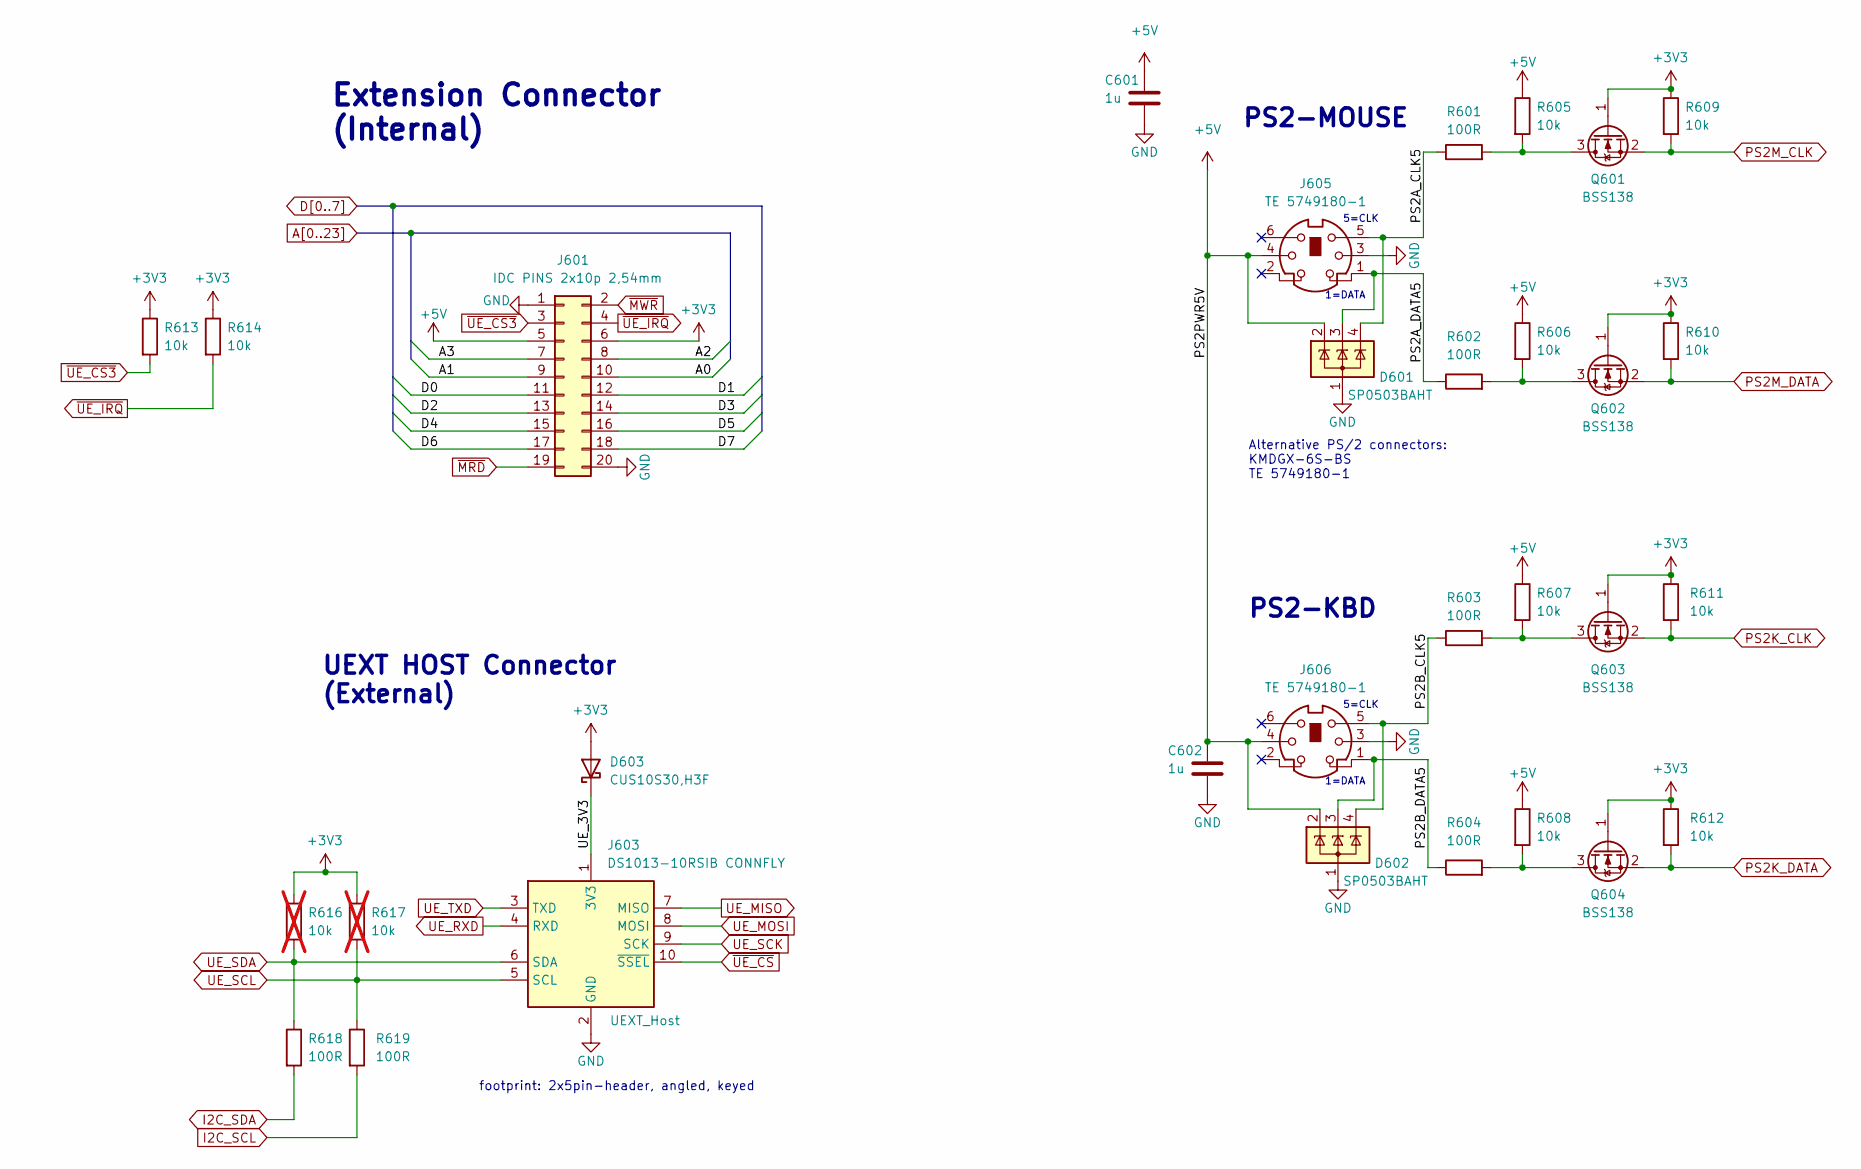
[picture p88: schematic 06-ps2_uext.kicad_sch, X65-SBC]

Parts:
C601, C602: 1u; C_0603_1608Metric_Pad1.08x0.95mm_HandSolder
D601, D602: SP0503BAHT; SOT-143
D603: CUS10S30,H3F; D_SOD-323_HandSoldering
J601: IDC PINS 2x10p 2,54mm; IDC-Header_2x10_P2.54mm_Vertical
J603: DS1013-10RSIB CONNFLY; IDC-Header_2x05_P2.54mm_Horizontal
J605, J606: TE 5749180-1; TE_5749180-1
Q601, Q602, Q603, Q604: BSS138; SOT-23
R601, R602, R603, R604, R618, R619: 100R; R_0603_1608Metric_Pad0.98x0.95mm_HandSolder
R605, R606, R607, R608, R609, R610, R611, R612, R613, R614: 10k; R_0603_1608Metric_Pad0.98x0.95mm_HandSolder
R616, R617: 10k; R_0603_1608Metric_Pad0.98x0.95mm_HandSolder; not fitted

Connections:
+3V3: D603.2 (A), J601.6, Q601.1 (G), Q602.1 (G), Q603.1 (G), Q604.1 (G), R609.1, R610.1, R611.1, R612.1, R613.1, R614.1, R616.1, R617.1; also elsewhere on the board
+5V: C601.1, C602.1, D601.2 (K), D602.2 (K), J601.5, J605.4, J606.4, R605.1, R606.1, R607.1, R608.1; also elsewhere on the board
/PS2 Kbd+Mouse, UEXT/PS2A_CLK5: D601.4 (K), J605.5, R601.1
/PS2 Kbd+Mouse, UEXT/PS2A_DATA5: D601.3 (K), J605.1, R602.1
/PS2 Kbd+Mouse, UEXT/PS2B_CLK5: D602.4 (K), J606.5, R603.1
/PS2 Kbd+Mouse, UEXT/PS2B_DATA5: D602.3 (K), J606.1, R604.1
/PS2 Kbd+Mouse, UEXT/UE_3V3: D603.1 (K), J603.1 (3V3)
A0: J601.10; also elsewhere on the board
A1: J601.9; also elsewhere on the board
A2: J601.8; also elsewhere on the board
A3: J601.7; also elsewhere on the board
D0: J601.11; also elsewhere on the board
D1: J601.12; also elsewhere on the board
D2: J601.13; also elsewhere on the board
D3: J601.14; also elsewhere on the board
D4: J601.15; also elsewhere on the board
D5: J601.16; also elsewhere on the board
D6: J601.17; also elsewhere on the board
D7: J601.18; also elsewhere on the board
GND: C601.2, C602.2, D601.1 (A), D602.1 (A), J601.1, J601.20, J603.2 (GND), J605.3, J606.3; also elsewhere on the board
I2C_SCL: R619.2; also elsewhere on the board
I2C_SDA: R618.2; also elsewhere on the board
unnamed: Q601.3 (D), R601.2, R605.2
unnamed: Q602.3 (D), R602.2, R606.2
unnamed: Q603.3 (D), R603.2, R607.2
unnamed: Q604.3 (D), R604.2, R608.2
PS2K_CLK: Q603.2 (S), R611.2; also elsewhere on the board
PS2K_DATA: Q604.2 (S), R612.2; also elsewhere on the board
PS2M_CLK: Q601.2 (S), R609.2; also elsewhere on the board
PS2M_DATA: Q602.2 (S), R610.2; also elsewhere on the board
UE_MISO: J603.7 (MISO); also elsewhere on the board
UE_MOSI: J603.8 (MOSI); also elsewhere on the board
UE_RXD: J603.4 (RXD); also elsewhere on the board
UE_SCK: J603.9 (SCK); also elsewhere on the board
UE_SCL: J603.5 (SCL), R617.2, R619.1; also elsewhere on the board
UE_SDA: J603.6 (SDA), R616.2, R618.1; also elsewhere on the board
UE_TXD: J603.3 (TXD); also elsewhere on the board
~MRD: J601.19; also elsewhere on the board
~MWR: J601.2; also elsewhere on the board
~UE_CS3: J601.3, R613.2; also elsewhere on the board
~UE_CS: J603.10 (~SSEL); also elsewhere on the board
~UE_IRQ: J601.4, R614.2; also elsewhere on the board

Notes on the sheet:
UEXT HOST Connector (External)
1=DATA
5=CLK
PS2-MOUSE
PS2-KBD
Extension Connector (Internal)
footprint: 2x5pin-header, angled, keyed
Alternative PS/2 connectors: KMDGX-6S-BS TE 5749180-1

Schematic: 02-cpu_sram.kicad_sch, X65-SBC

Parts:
C201, C202, C203, C204: 1u; C_0603_1608Metric_Pad1.08x0.95mm_HandSolder
R201, R202, R203, R204, R205, R207, R214, R215: 10k; R_0603_1608Metric_Pad0.98x0.95mm_HandSolder
R208, R210, R213: 0R; R_0603_1608Metric_Pad0.98x0.95mm_HandSolder
R211: 50R; R_0603_1608Metric_Pad0.98x0.95mm_HandSolder
R212: 100R; R_0603_1608Metric_Pad0.98x0.95mm_HandSolder
R216: 10k; R_0603_1608Metric_Pad0.98x0.95mm_HandSolder; not fitted
R217: 2k; R_0603_1608Metric_Pad0.98x0.95mm_HandSolder
U201: W65C816S6TQG-14; MQFP-44_10x10mm_P0.8mm
U202: IS61WV20488FBLL-10TLI; TSOP-II-44_10.16x18.41mm_P0.8mm

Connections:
+3V3: C201.1, C202.1, C203.1, C204.1, R201.1, R202.1, R203.1, R204.1, R214.1, R216.1, U201.3 (VDD), U201.31 (VDD), U202.11 (VDD), U202.33 (VDD); also elsewhere on the board
A0: U201.4 (A0), U202.3 (A0); also elsewhere on the board
A1: U201.5 (A1), U202.4 (A1); also elsewhere on the board
A2: U201.7 (A2), U202.5 (A2); also elsewhere on the board
A3: U201.8 (A3), U202.6 (A3); also elsewhere on the board
A4: U201.9 (A4), U202.7 (A4); also elsewhere on the board
A5: U201.10 (A5), U202.16 (A5); also elsewhere on the board
A6: U201.11 (A6), U202.17 (A6); also elsewhere on the board
A7: U201.12 (A7), U202.18 (A7); also elsewhere on the board
A8: U201.13 (A8), U202.19 (A8); also elsewhere on the board
A9: U201.14 (A9), U202.20 (A9); also elsewhere on the board
A10: U201.15 (A10), U202.26 (A10); also elsewhere on the board
A11: U201.16 (A11), U202.27 (A11); also elsewhere on the board
A12: U202.28 (A12); also elsewhere on the board
A13: U202.29 (A13); also elsewhere on the board
A14: U202.30 (A14); also elsewhere on the board
A15: U202.38 (A15); also elsewhere on the board
A16: U202.39 (A16); also elsewhere on the board
A17: U202.40 (A17); also elsewhere on the board
A18: U202.41 (A18); also elsewhere on the board
A19: U202.25 (A19); also elsewhere on the board
A20: U202.42 (A20); also elsewhere on the board
CA12: U201.19 (A12); also elsewhere on the board
CA13: U201.20 (A13); also elsewhere on the board
CA14: U201.21 (A14); also elsewhere on the board
CA15: U201.22 (A15); also elsewhere on the board
CBE: R205.1, U201.34 (BE); also elsewhere on the board
CD0: U201.30 (D0); also elsewhere on the board
CD1: U201.29 (D1); also elsewhere on the board
CD2: U201.28 (D2); also elsewhere on the board
CD3: U201.27 (D3); also elsewhere on the board
CD4: U201.26 (D4); also elsewhere on the board
CD5: U201.25 (D5); also elsewhere on the board
CD6: U201.24 (D6); also elsewhere on the board
CD7: U201.23 (D7); also elsewhere on the board
CEF: R202.2, R210.1; also elsewhere on the board
CPHI2: R211.1; also elsewhere on the board
CPUTYPE02: R216.2, R217.1; also elsewhere on the board
CRDY: R212.2, R214.2; also elsewhere on the board
CSOB_MX: R204.2, U201.36 (SOB/MX); also elsewhere on the board
CSYNC_VPA: U201.2 (SYNC/VPA); also elsewhere on the board
CVDA: R213.2, R215.1; also elsewhere on the board
D0: U202.9 (D0); also elsewhere on the board
D1: U202.10 (D1); also elsewhere on the board
D2: U202.13 (D2); also elsewhere on the board
D3: U202.14 (D3); also elsewhere on the board
D4: U202.31 (D4); also elsewhere on the board
D5: U202.32 (D5); also elsewhere on the board
D6: U202.35 (D6); also elsewhere on the board
D7: U202.36 (D7); also elsewhere on the board
GND: C201.2, C202.2, C203.2, C204.2, R205.2, R207.2, R215.2, R217.2, U201.17 (VSS), U201.18 (VSS), U201.39 (VSS), U202.12 (VSS), U202.34 (VSS); also elsewhere on the board
unnamed: R210.2, U201.33 (NC/E)
unnamed: R208.2, U201.42 (PHI1O/ABORTB)
unnamed: R211.2, U201.35 (PHI2)
unnamed: R213.1, U201.37 (PHI2O/VDA)
unnamed: R212.1, U201.41 (RDY)
~CABORT: R203.2, R208.1; also elsewhere on the board
~CIRQ: U201.43 (IRQB); also elsewhere on the board
~CML: U201.44 (MLB); also elsewhere on the board
~CNMI: U201.1 (NMIB); also elsewhere on the board
~CRES: R207.1, U201.38 (RESB); also elsewhere on the board
~CRW: U201.32 (RWB); also elsewhere on the board
~CVP: U201.40 (VPB); also elsewhere on the board
~M1CS: R201.2, U202.8 (CS#); also elsewhere on the board
~MRD: U202.37 (OE#); also elsewhere on the board
~MWR: U202.15 (WE#); also elsewhere on the board

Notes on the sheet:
R216 assemble just in case CPU=65C02
CD[0..7] => only to "NORA" FPGA
CPU
CPU U201 assembly options: a) W65C02S6TQG-14 => 8-bit CPU => do not populate R208, R210, R213, R217. => do populate R216 (so that CPUTYPE02=Hi) b) W65C816S6TQG-14 => 16-bit CPU => as shown in the schematic.
44-pin TSOP Type-II package
MQFP-44 package
R217 assemble just in case CPU=65C816
RAM
DEFAULT

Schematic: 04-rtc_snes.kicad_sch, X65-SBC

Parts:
BT401: BAT-HLD-012-SMT; BatteryHolder_LINX_BAT-HLD-012-SMT
C401, C404: 1u; C_0603_1608Metric_Pad1.08x0.95mm_HandSolder
C402, C403: 18p; C_0603_1608Metric_Pad1.08x0.95mm_HandSolder
D401: CUS10S30,H3F; D_SOD-323_HandSoldering
D402: AA4040LCGCK-AMT; PLCC2_4x4mm
D403: AA4040SESK; PLCC2_4x4mm
D404, D405: SP0503BAHT; SOT-143
D406, D407: LED_YELLOW_0603; LED_0603_1608Metric_Pad1.05x0.95mm_HandSolder
J403, J404: SNES_Controller_Conn; SNES_Controller_Conn_7p_90deg_P1Left
R401, R413, R421, R422: 33k; R_0603_1608Metric_Pad0.98x0.95mm_HandSolder
R402, R414, R417, R418, R419, R420: 2k7; R_0603_1608Metric_Pad0.98x0.95mm_HandSolder
R403, R404, R411, R412: 10k; R_0603_1608Metric_Pad0.98x0.95mm_HandSolder
R405, R406, R407, R408, R409, R410: 100R; R_0603_1608Metric_Pad0.98x0.95mm_HandSolder
R415, R416: 470R; R_0603_1608Metric_Pad0.98x0.95mm_HandSolder
SW401: SW_DIP_x02 TE 1825058-1; SW_DIP_SPSTx02_Slide_6.7x6.64mm_W8.61mm_P2.54mm_LowProfile
U401, U403: 74LVC2G17DBVR; SOT-23-6_Handsoldering
U402: MCP7940N-xSN; SO-8_3.9x4.9mm_P1.27mm
Y402: CM8V-T1A-32.768kHz-9pF-20PPM-TA-QC; Crystal_SMD_MicroCrystal_CC8V-T1A-2Pin_2.0x1.2mm_HandSolder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

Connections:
+3V3: D402.2 (A), D403.2 (A), D406.2 (A), D407.2 (A), R401.2, R403.2, R404.2, R413.2, R421.2, R422.2, U401.5 (VCC), U402.8 (VCC); also elsewhere on the board
+5V: C404.1, J403.1 (V+5V), J404.1 (V+5V), R411.2, R412.2, U403.5 (VCC); also elsewhere on the board
/LEDs, RTC, SNES/NES0DATA5: R409.1, R411.1, U401.1
/LEDs, RTC, SNES/NES1DATA5: R410.1, R412.1, U401.3
/LEDs, RTC, SNES/NESCLOCK5: R405.1, R407.1, U403.4
/LEDs, RTC, SNES/NESLATCH5: R406.1, R408.1, U403.6
/LEDs, RTC, SNES/VBAT3V: C401.1, D401.1 (K), U402.3 (VBAT)
CPULED0: R401.1, R402.2, R415.1; also elsewhere on the board
CPULED1: R413.1, R414.2, R416.1; also elsewhere on the board
DIPLED0: R417.2, R419.1, R421.1; also elsewhere on the board
DIPLED1: R418.2, R420.1, R422.1; also elsewhere on the board
GND: BT401.2 (-), C401.2, C402.2, C403.2, C404.2, D404.1 (A), D405.1 (A), J403.7 (GND), J404.7 (GND), SW401.1, SW401.2, U401.2 (GND), U402.4 (VSS), U403.2 (GND); also elsewhere on the board
I2C_SCL: R403.1, U402.6 (SCL); also elsewhere on the board
I2C_SDA: R404.1, U402.5 (SDA); also elsewhere on the board
NESCLOCK: U403.3; also elsewhere on the board
NESDATA0: U401.6; also elsewhere on the board
NESDATA1: U401.4; also elsewhere on the board
NESLATCH: U403.1; also elsewhere on the board
unnamed: BT401.1 (+), D401.2 (A)
unnamed: D402.1 (K), R415.2
unnamed: D403.1 (K), R416.2
unnamed: D406.1 (K), R419.2
unnamed: D407.1 (K), R420.2
unnamed: D404.2 (K), J403.2 (CLOCK), R405.2
unnamed: D404.4 (K), J403.4 (DATA1), R409.2
unnamed: D404.3 (K), J403.3 (LATCH), R406.2
unnamed: D405.2 (K), J404.2 (CLOCK), R407.2
unnamed: D405.3 (K), J404.4 (DATA1), R410.2
unnamed: D405.4 (K), J404.3 (LATCH), R408.2
unnamed: R417.1, SW401.4
unnamed: R418.1, SW401.3
unnamed: C403.1, U402.1 (X1), Y402.2
unnamed: C402.1, U402.2 (X2), Y402.1
SD_WP: R414.1; also elsewhere on the board
~SD_CD: R402.1; also elsewhere on the board

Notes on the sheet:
RTC
SMD
RTC/MCP7940N I2C DEVICE ADDRESS (8b=shifted) = 0b1101_111W = 0xDE, that is 7-bit addr 0x6F PS2 CONTROLLER (IN NORA) I2C DEVICE ADDRESS (8b=shifted) = 0b1000010W = 0x84, that is 7-bit addr 0x42
2x SNES JOYPAD CONTROLLER PORTS
2x package: SOT-23-6
User LEDs
ORANGE REFLECTOR LED
Battery holder for CR1216/1225 3V cell
SNES CONTROLLER EXAMPLE:
MCP7940N datasheet says: * crystal loading shall be 6-9pf; 12pf not recommended! * CX should be 2* X_loading, so that in parallel the crystal see the expected capacitance * layout must be according to the DS.
GREEN REFLECTOR LED
package: SOIC-8 150mil
package: SOT-23-6
J403, J404 TYPE:
Dual purpose CPULED0/1 signals: a) CPULED0/1 configured as OUTPUT DRIVING: set 0 => LED ON set 1 => LED OFF b) CPULED0/1 configured as INPUT: read 0 => switch SD_CD or SD_WP closed. read 1 => switch SD_CD or SD_WP open.

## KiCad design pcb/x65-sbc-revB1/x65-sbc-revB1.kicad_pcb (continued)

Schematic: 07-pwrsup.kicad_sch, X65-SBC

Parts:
C701, C702, C703, C704: 22u/16V; C_0805_2012Metric_Pad1.18x1.45mm_HandSolder
C705: 1u; C_0603_1608Metric_Pad1.08x0.95mm_HandSolder
D701: LED_GREEN_0603; LED_0603_1608Metric_Pad1.05x0.95mm_HandSolder
J701: Conn_01x02; PinHeader_1x02_P2.54mm_Vertical; not fitted
J702, J703, J704: Conn_01x01; PinHeader_1x01_P2.54mm_Vertical; not fitted
JP701, JP702: SolderJumper_2_Bridged; SolderJumper-2_P1.3mm_Open_RoundedPad1.0x1.5mm
L701: DFE252010P-2R2M=P2; L_1008_2520Metric_Pad1.43x2.20mm_HandSolder
L702: DFE252010P-1R0M=P2; L_1008_2520Metric_Pad1.43x2.20mm_HandSolder
R701: 12k; R_0603_1608Metric_Pad0.98x0.95mm_HandSolder
R702, R707: 2k7; R_0603_1608Metric_Pad0.98x0.95mm_HandSolder
R703, R706: 10R; R_0603_1608Metric_Pad0.98x0.95mm_HandSolder
R704, R705, R708: 10k; R_0603_1608Metric_Pad0.98x0.95mm_HandSolder
U701: MP2149GJ; TSOT-23-8_HandSoldering

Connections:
+1V2: JP702.2 (B); also elsewhere on the board
+3V3: D701.2 (A), JP701.2 (B); also elsewhere on the board
+5V: C701.1, C704.2, J701.2, R708.1, U701.2 (EN2), U701.7 (IN); also elsewhere on the board
/Power Supply/EN3V3: C705.1, R708.2, U701.4 (EN1)
/Power Supply/FB1: R701.2, R702.1, U701.8 (FB1)
/Power Supply/FB2: R704.2, R705.1, U701.1 (FB2)
/Power Supply/RAW1V2: C703.2, JP702.1 (A), L702.2, R706.1
/Power Supply/RAW3V3: C702.2, JP701.1 (A), L701.1, R703.1
/Power Supply/SW1: L701.2, U701.6 (SW1)
/Power Supply/SW2: L702.1, U701.3 (SW2)
GND: C701.2, C702.1, C703.1, C704.1, C705.2, J701.1, J702.1, J703.1, J704.1, R702.2, R705.2, R707.2, U701.5 (GND); also elsewhere on the board
unnamed: D701.1 (K), R707.1
unnamed: R701.1, R703.2
unnamed: R704.1, R706.2

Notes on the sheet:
1uH
2,2uH
"POWER ON" GREEN REFLECTOR LED
POWER SUPPLY 5V -> 3.3V, 1.2V
1V2 consumption: 20mA
GND testpoints
package: TSOT-23-8
Close JP701, JP702 by solder after testing the PSU.
Alternative power input connector
R708/C705 delays 3V3 start by 10ms (FPGA seq. requirement: first 1V2, then 3V3)
3V3 consumption: 80mA to 300mA

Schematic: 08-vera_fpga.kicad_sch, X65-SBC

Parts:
C801, C802, C803, C804, C805, C806: 1u; C_0603_1608Metric_Pad1.08x0.95mm_HandSolder
D801: LED_GREEN_0603; LED_0603_1608Metric_Pad1.05x0.95mm_HandSolder
D802: CUS10S30,H3F; D_SOD-323_HandSoldering
J801: ICD15S13E4GV00LF
Q801: BSS138; SOT-23
R802, R803, R831: 10k; R_0603_1608Metric_Pad0.98x0.95mm_HandSolder
R804: 2k7; R_0603_1608Metric_Pad0.98x0.95mm_HandSolder
R805, R806: 50R; R_0603_1608Metric_Pad0.98x0.95mm_HandSolder
R808, R812, R816: 510R; R_0603_1608Metric_Pad0.98x0.95mm_HandSolder
R809, R813, R817: 910R; R_0603_1608Metric_Pad0.98x0.95mm_HandSolder
R810, R814, R818: 2k; R_0603_1608Metric_Pad0.98x0.95mm_HandSolder
R811, R815, R819: 4k3; R_0603_1608Metric_Pad0.98x0.95mm_HandSolder
R820, R823, R826: 27R; R_0603_1608Metric_Pad0.98x0.95mm_HandSolder
R821, R824, R827: 160R; R_0603_1608Metric_Pad0.98x0.95mm_HandSolder
R822, R825, R828: 150R; R_0603_1608Metric_Pad0.98x0.95mm_HandSolder
R829, R830: 820R; R_0603_1608Metric_Pad0.98x0.95mm_HandSolder
U801: ICE40UP5K-SG48ITR50; QFN-48-1EP_7x7mm_P0.5mm_EP5.3x5.3mm
X801: SG5032CAN_25.000000M-TJGA3; Oscillator_SMD_SeikoEpson_SG8002LB-4Pin_5.0x3.2mm_HandSolde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

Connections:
25MHz: R805.1, R806.1, X801.3 (OUT); also elsewhere on the board
+1V2: C801.1, C803.1, U801.5 (VCC), U801.29 (VCCPLL), U801.30 (VCC); also elsewhere on the board
+3V3: C802.1, C804.1, C805.1, C806.1, D801.2 (A), D802.2 (A), R802.1, R803.1, R831.1, U801.1 (VCCIO_2), U801.22 (SPI_VCCIO1), U801.33 (VCCIO_0), X801.4 (VCC); also elsewhere on the board
+5V: J801.9; also elsewhere on the board
/VERA FPGA/BLUE: J801.3, R819.1, R826.1, R827.1, R828.1
/VERA FPGA/GREEN: J801.2, R815.1, R823.1, R824.1, R825.1
/VERA FPGA/HSYNC: J801.13, R830.1
/VERA FPGA/RED: J801.1, R811.1, R820.1, R821.1, R822.1
/VERA FPGA/VSYNC: J801.14, R829.1
A0: U801.40 (RGB1); also elsewhere on the board
A1: U801.39 (RGB0); also elsewhere on the board
A2: U801.37 (IOT_45A_G1); also elsewhere on the board
A3: U801.41 (RGB2); also elsewhere on the board
A4: U801.34 (IOT_44B); also elsewhere on the board
ASYSCLK: R806.2; also elsewhere on the board
D0: U801.27 (IOT_38B); also elsewhere on the board
D1: U801.26 (IOT_39A); also elsewhere on the board
D2: U801.25 (IOT_36B); also elsewhere on the board
D3: U801.23 (IOT_37A); also elsewhere on the board
D4: U801.21 (IOB_23B); also elsewhere on the board
D5: U801.20 (IOB_25B_G3); also elsewhere on the board
D6: U801.19 (IOB_29B); also elsewhere on the board
D7: U801.18 (IOB_31B); also elsewhere on the board
GND: C801.2, C802.2, C803.2, C804.2, C805.2, C806.2, J801.0, J801.5, J801.6, J801.7, J801.8, J801.10, Q801.2 (S), U801.49 (GND), X801.2 (GND); also elsewhere on the board
unnamed: D801.1 (K), R804.2
unnamed: D802.1 (K), U801.24 (VPP_2V5)
unnamed: Q801.3 (D), R804.1
unnamed: R808.1, R820.2
unnamed: R809.1, R821.2
unnamed: R810.1, R822.2
unnamed: R812.1, R823.2
unnamed: R813.1, R824.2
unnamed: R814.1, R825.2
unnamed: R816.1, R826.2
unnamed: R817.1, R827.2
unnamed: R818.1, R828.2
VAUDIO_BCK: U801.38 (IOT_50B); also elsewhere on the board
VAUDIO_DATA: U801.42 (IOT_51A); also elsewhere on the board
VAUDIO_LRCK: U801.43 (IOT_49A); also elsewhere on the board
VFPGA_CDONE: Q801.1 (G), R803.2, U801.7 (CDONE); also elsewhere on the board
VGA_B0: R819.2, U801.46 (IOB_0A)
VGA_B1: R818.2, U801.47 (IOB_2A)
VGA_B2: R817.2, U801.48 (IOB_4A)
VGA_B3: R816.2, U801.2 (IOB_6A)
VGA_G0: R815.2, U801.3 (IOB_9B)
VGA_G1: R814.2, U801.4 (IOB_8A)
VGA_G2: R813.2, U801.6 (IOB_13B)
VGA_G3: R812.2, U801.9 (IOB_16A)
VGA_HSYNC: R830.2, U801.44 (IOB_3B_G6)
VGA_R0: R811.2, U801.10 (IOB_18A)
VGA_R1: R810.2, U801.11 (IOB_20A)
VGA_R2: R809.2, U801.12 (IOB_22A)
VGA_R3: R808.2, U801.13 (IOB_24A)
VGA_VSYNC: R829.2, U801.45 (IOB_5B)
VSPI_MISO: U801.17 (IOB_33B_SPI_SI); also elsewhere on the board
VSPI_MOSI: U801.14 (IOB_32A_SPI_SO); also elsewhere on the board
VSPI_SCK: U801.15 (IOB_34A_SPI_SCK); also elsewhere on the board
VSYSCLK: R805.2, U801.35 (IOT_46B_G0)
~MRD: U801.36 (IOT_48B); also elsewhere on the board
~MWR: U801.31 (IOT_42B); also elsewhere on the board
~VCS0: U801.28 (IOT_41A); also elsewhere on the board
~VIRQ: R831.2, U801.32 (IOT_43A); also elsewhere on the board
~VRST: R802.2, U801.8 (CRESET_B); also elsewhere on the board
~VSPI_SSEL: U801.16 (IOB_35B_SPI_SS); also elsewhere on the board

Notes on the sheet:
"VERA" FPGA - Video Embedded Retro Adapter
VGA interface
(orig: 536R)
package: SOT-23
package QFN-48
"VERA READY" internal LED
This schematic contains portions of work done by Frank van den Hoe for the project VERA: https://github.com/fvdhoef/vera-module
Common 25MHz oscillator
(orig:536R)

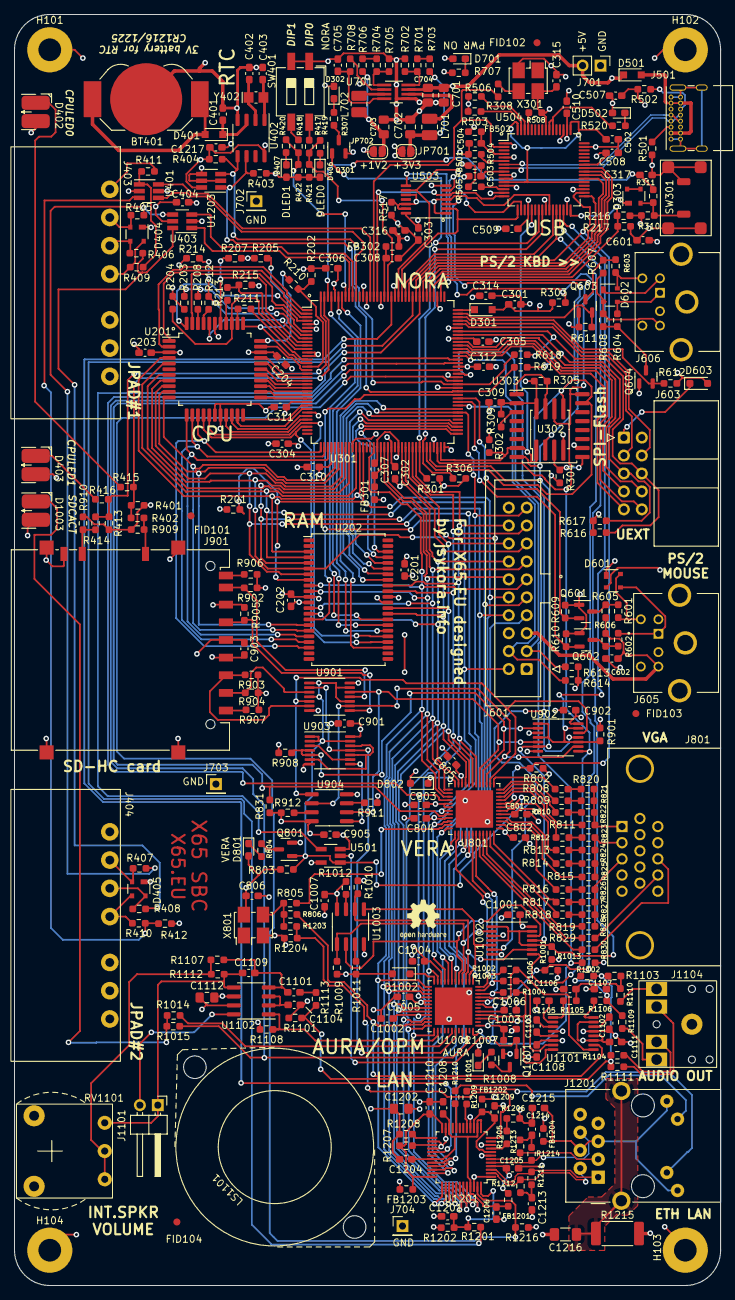
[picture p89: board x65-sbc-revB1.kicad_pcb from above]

Board: 4 copper layers, 100.0 x 180.0 mm, 343 parts (0 on the bottom side), 299 nets.

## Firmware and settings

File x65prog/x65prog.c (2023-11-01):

/*
 *  x65prog -- simple programming tool for OpenX65 computer with built-in FTDI host,
 *
 *  Based on:
 *  iceprog -- simple programming tool for FTDI-based Lattice iCE programmers
 *
 *  Copyright (C) 2015  Clifford Wolf <clifford@clifford.at>
 *  Copyright (C) 2018  Piotr Esden-Tempski <piotr@esden.net>
 *
 *  Permission to use, copy, modify, and/or distribute this software for any
 *  purpose with or without fee is hereby granted, provided that the above
 *  copyright notice and this permission notice appear in all copies.
 *
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
 *  Relevant Documents:
 *  -------------------
 *  http://www.latticesemi.com/~/media/Documents/UserManuals/EI/icestickusermanual.pdf
 *  http://www.micron.com/~/media/documents/products/data-sheet/nor-flash/serial-nor/n25q/n25q_32mb_3v_65nm.pdf
 */

#define _GNU_SOURCE

#include <stdio.h>
#include <stdint.h>
#include <stdbool.h>
#include <stdlib.h>
#include <unistd.h>
#include <string.h>
#include <getopt.h>
#include <errno.h>
#include <sys/types.h>
#include <sys/stat.h>

#ifdef _WIN32
#include <io.h> /* _setmode() */
#include <fcntl.h> /* _O_BINARY */
#endif

#include "mpsse.h"

static bool verbose = false;

// ---------------------------------------------------------
// FLASH definitions
// ---------------------------------------------------------

/* Flash command definitions */
/* This command list is based on the Winbond W25Q128JV Datasheet */
enum flash_cmd {
	FC_WE = 0x06, /* Write Enable */
	FC_SRWE = 0x50, /* Volatile SR Write Enable */
	FC_WD = 0x04, /* Write Disable */
	FC_RPD = 0xAB, /* Release Power-Down, returns Device ID */
	FC_MFGID = 0x90, /*  Read Manufacturer/Device ID */
	FC_JEDECID = 0x9F, /* Read JEDEC ID */
	FC_UID = 0x4B, /* Read Unique ID */
	FC_RD = 0x03, /* Read Data */
	FC_FR = 0x0B, /* Fast Read */
	FC_PP = 0x02, /* Page Program */
	FC_SE = 0x20, /* Sector Erase 4kb */
	FC_BE32 = 0x52, /* Block Erase 32kb */
	FC_BE64 = 0xD8, /* Block Erase 64kb */
	FC_CE = 0xC7, /* Chip Erase */
	FC_RSR1 = 0x05, /* Read Status Register 1 */
	FC_WSR1 = 0x01, /* Write Status Register 1 */
	FC_RSR2 = 0x35, /* Read Status Register 2 */
	FC_WSR2 = 0x31, /* Write Status Register 2 */
	FC_RSR3 = 0x15, /* Read Status Register 3 */
	FC_WSR3 = 0x11, /* Write Status Register 3 */
	FC_RSFDP = 0x5A, /* Read SFDP Register */
	FC_ESR = 0x44, /* Erase Security Register */
	FC_PSR = 0x42, /* Program Security Register */
	FC_RSR = 0x48, /* Read Security Register */
	FC_GBL = 0x7E, /* Global Block Lock */
	FC_GBU = 0x98, /* Global Block Unlock */
	FC_RBL = 0x3D, /* Read Block Lock */
	FC_RPR = 0x3C, /* Read Sector Protection Registers (adesto) */
	FC_IBL = 0x36, /* Individual Block Lock */
	FC_IBU = 0x39, /* Individual Block Unlock */
	FC_EPS = 0x75, /* Erase / Program Suspend */
	FC_EPR = 0x7A, /* Erase / Program Resume */
	FC_PD = 0xB9, /* Power-down */
	FC_QPI = 0x38, /* Enter QPI mode */
	FC_ERESET = 0x66, /* Enable Reset */
	FC_RESET = 0x99, /* Reset Device */
};

// bit masks of the signals on ACBUSx
#define ICD2NORAROM 		0x01			// ACBUS0
#define ICDCSN				0x02			// ACBUS1
#define AURARSTN			0x04			// ACBUS2
#define AURAFCS				0x08			// ACBUS3
#define VERAFCS				0x10			// ACBUS4
#define VERAAURADONE		0x40			// ACBUS6
#define VERARSTN			0x80			// ACBUS7

/* x65 target flash memory */
enum target_flash 
{
	TARGET_UNKNOWN = 'U',
	TARGET_NORA = 'N',
	TARGET_AURA = 'A',
	TARGET_VERA = 'V'
};

static enum target_flash target = TARGET_UNKNOWN;

// ---------------------------------------------------------
// Hardware specific CS, CReset, CDone functions
// ---------------------------------------------------------

static void set_cs_creset_nora(int cs_b, int creset_b)
{
	uint8_t gpio = 0;
	uint8_t direction = 0x03;

	if (!cs_b) {
		// ADBUS4 (GPIOL0) = FLASHCSN for NORA
		direction |= 0x10;		// set to output mode, will drive 0
	}

	if (!creset_b) {
		// ADBUS7 (GPIOL3) = NORARSTN
		direction |= 0x80;		// set to output mode, will drive 0
	}

	mpsse_set_gpio_low(gpio, direction);
}

static void set_cs_creset_vera(int cs_b, int creset_b)
{
	// bitmap of GPIO output register values (0/1 drive)
	uint8_t gpio = ICD2NORAROM;
	// bitmap of GPIO direction register values (0=in, 1=out)
	uint8_t direction = 0x03 | ICD2NORAROM | VERAFCS | AURAFCS;

	if (!cs_b) {
		// ADBUS4 (GPIOL0) = VERAFCS for VERA
		// direction |= VERAFCS;		// set to output mode, will drive logic 1
		gpio |= VERAFCS;			// drive HIGH to VERAFCS; this enables the bus-switch U404 on VABO
	}

	if (!creset_b) {
		// ADBUS7 (GPIOL3) = VERARSTN
		direction |= VERARSTN;		// set to output mode, will drive 0
	}

	mpsse_set_gpio_high(gpio, direction);
}

static void set_cs_creset_aura(int cs_b, int creset_b)
{
	// bitmap of GPIO output register values (0/1 drive)
	uint8_t gpio = ICD2NORAROM;				// drive high ICD2NORAROM, so that FTDI gets to FMOSI/FSCK bus
	// bitmap of GPIO direction register values (0=in, 1=out)
	uint8_t direction = 0x03 | ICD2NORAROM | VERAFCS | AURAFCS;		// drive ICD2NORAROM, VERAFCS, AURAFCS

	if (!cs_b) {
		// ACBUS3) = AURAFCS for AURA
		gpio |= AURAFCS;			// drive HIGH to AURAFCS; this enables the bus-switch U602 on VABO
	}

	if (!creset_b) {
		// ACBUS2  = AURARSTN
		direction |= AURARSTN;		// set to output mode, will drive 0
	}

	mpsse_set_gpio_high(gpio, direction);
}


static bool get_cdone_nora(void)
{
	// ADBUS6 (GPIOL2) = NORADONE
	return (mpsse_readb_low() & 0x40) != 0;
}

static bool get_cdone_vera_aura(void)
{
	return (mpsse_readb_high() & VERAAURADONE) != 0;
}


// ---------------------------------------------------------
// Indirection functions - for different targets we have
// ---------------------------------------------------------

static void (*set_cs_creset)(int cs_b, int creset_b);

static bool (*get_cdone)(void);


// ---------------------------------------------------------
// FLASH function implementations
// ---------------------------------------------------------


// configure the high-byte (ACBUSx) to route SPI to the flashes,
// and disable ICD.
static void x65_select_flash()
{
	// drive high ICD2NORAROM (= ICD2FLASHES), ICDCSN, 
	// drive low AURAFCS, low VERAFCS,
	// keep others as IN.
	mpsse_set_gpio_high(ICD2NORAROM | ICDCSN  | VERAAURADONE | VERARSTN, 
				ICD2NORAROM | ICDCSN | AURAFCS | VERAFCS);
}

// configure the high-byte (ACBUSx) to route SPI to the ICD,
// and keep ICD high (deselect).
static void x65_idle()
{
	// drive low ICD2NORAROM (this unroutes SPI to flash), 
	// drive high ICDCSN, keep others as IN.
	mpsse_set_gpio_high(ICDCSN | AURAFCS | VERAFCS | VERAAURADONE | VERARSTN, 
				ICD2NORAROM | ICDCSN);
}

// the NORA FPGA reset is released so also FLASH chip select should be deasserted
static void flash_release_reset_nora()
{
	set_cs_creset_nora(1, 1);	
}

// the FPGA reset is released so also FLASH chip select should be deasserted
static void flash_release_reset()
{
	set_cs_creset(1, 1);	
}

// FLASH chip select assert
// should only happen while FPGA reset is asserted
static void flash_chip_select()
{
	set_cs_creset(0, 0);
}

// FLASH chip select deassert
static void flash_chip_deselect()
{
	set_cs_creset(1, 0);
}

// SRAM reset is the same as flash_chip_select()
// For ease of code reading we use this function instead
static void sram_reset()
{
	// Asserting chip select and reset lines
	set_cs_creset(0, 0);
}

// SRAM chip select assert
// When accessing FPGA SRAM the reset should be released
static void sram_chip_select()
{
	set_cs_creset(0, 1);
}

static void flash_read_id()
{
	/* JEDEC ID structure:
	 * Byte No. | Data Type
	 * ---------+----------
	 *        0 | FC_JEDECID Request Command
	 *        1 | MFG ID
	 *        2 | Dev ID 1
	 *        3 | Dev ID 2
	 *        4 | Ext Dev Str Len
	 */

	uint8_t data[260] = { FC_JEDECID };
	int len = 5; // command + 4 response bytes

	if (verbose)
		fprintf(stderr, "read flash ID..\n");

	flash_chip_select();

	// Write command and read first 4 bytes
	mpsse_xfer_spi(data, len);

	if (data[4] == 0xFF)
		fprintf(stderr, "Extended Device String Length is 0xFF, "
				"this is likely a read error. Ignoring...\n");
	else {
		// Read extended JEDEC ID bytes
		if (data[4] != 0) {
			len += data[4];
			mpsse_xfer_spi(data + 5, len - 5);
		}
	}

	flash_chip_deselect();

	// TODO: Add full decode of the JEDEC ID.
	fprintf(stderr, "flash ID:");
	for (int i = 1; i < len; i++)
		fprintf(stderr, " 0x%02X", data[i]);
	fprintf(stderr, "\n");
}

static void flash_reset()
{
	uint8_t data[8] = { 0xff, 0xff, 0xff, 0xff, 0xff, 0xff, 0xff, 0xff };

	// This disables CRM is if it was enabled
	flash_chip_select();
	mpsse_xfer_spi(data, 8);
	flash_chip_deselect();

	// This disables QPI if it was enable
	flash_chip_select();
	mpsse_xfer_spi_bits(0xFF, 2);
	flash_chip_deselect();
}

static void flash_power_up()
{
	uint8_t data_rpd[1] = { FC_RPD };
	flash_chip_select();
	mpsse_xfer_spi(data_rpd, 1);
	flash_chip_deselect();
}

static void flash_power_down()
{
	uint8_t data[1] = { FC_PD };
	flash_chip_select();
	mpsse_xfer_spi(data, 1);
	flash_chip_deselect();
}

static uint8_t flash_read_status()
{
	uint8_t data[2] = { FC_RSR1 };

	flash_chip_select();
	mpsse_xfer_spi(data, 2);
	flash_chip_deselect();

	if (verbose) {
		fprintf(stderr, "SR1: 0x%02X\n", data[1]);
		fprintf(stderr, " - SPRL: %s\n",
			((data[1] & (1 << 7)) == 0) ? 
				"unlocked" : 
				"locked");
		fprintf(stderr, " -  SPM: %s\n",
			((data[1] & (1 << 6)) == 0) ?
				"Byte/Page Prog Mode" :
				"Sequential Prog Mode");
		fprintf(stderr, " -  EPE: %s\n",
			((data[1] & (1 << 5)) == 0) ?
				"Erase/Prog success" :
				"Erase/Prog error");
		fprintf(stderr, "-  SPM: %s\n",
			((data[1] & (1 << 4)) == 0) ?
				"~WP asserted" :
				"~WP deasserted");
		fprintf(stderr, " -  SWP: ");
		switch((data[1] >> 2) & 0x3) {
			case 0:
				fprintf(stderr, "All sectors unprotected\n");
				break;
			case 1:
				fprintf(stderr, "Some sectors protected\n");
				break;
			case 2:
				fprintf(stderr, "Reserved (xxxx 10xx)\n");
				break;
			case 3:
				fprintf(stderr, "All sectors protected\n");
				break;
		}
		fprintf(stderr, " -  WEL: %s\n",
			((data[1] & (1 << 1)) == 0) ?
				"Not write enabled" :
				"Write enabled");
		fprintf(stderr, " - ~RDY: %s\n",
			((data[1] & (1 << 0)) == 0) ?
				"Ready" :
				"Busy");
	}

	usleep(1000);

	return data[1];
}

static void flash_write_enable()
{
	if (verbose) {
		fprintf(stderr, "status before enable:\n");
		flash_read_status();
	}

	if (verbose)
		fprintf(stderr, "write enable..\n");

	uint8_t data[1] = { FC_WE };
	flash_chip_select();
	mpsse_xfer_spi(data, 1);
	flash_chip_deselect();

	if (verbose) {
		fprintf(stderr, "status after enable:\n");
		flash_read_status();
	}
}

static void flash_bulk_erase()
{
	fprintf(stderr, "bulk erase..\n");

	uint8_t data[1] = { FC_CE };
	flash_chip_select();
	mpsse_xfer_spi(data, 1);
	flash_chip_deselect();
}

static void flash_4kB_sector_erase(int addr)
{
	fprintf(stderr, "erase 4kB sector at 0x%06X..\n", addr);

	uint8_t command[4] = { FC_SE, (uint8_t)(addr >> 16), (uint8_t)(addr >> 8), (uint8_t)addr };

	flash_chip_select();
	mpsse_send_spi(command, 4);
	flash_chip_deselect();
}

static void flash_32kB_sector_erase(int addr)
{
	fprintf(stderr, "erase 64kB sector at 0x%06X..\n", addr);

	uint8_t command[4] = { FC_BE32, (uint8_t)(addr >> 16), (uint8_t)(addr >> 8), (uint8_t)addr };

	flash_chip_select();
	mpsse_send_spi(command, 4);
	flash_chip_deselect();
}

static void flash_64kB_sector_erase(int addr)
{
	fprintf(stderr, "erase 64kB sector at 0x%06X..\n", addr);

	uint8_t command[4] = { FC_BE64, (uint8_t)(addr >> 16), (uint8_t)(addr >> 8), (uint8_t)addr };

	flash_chip_select();
	mpsse_send_spi(command, 4);
	flash_chip_deselect();
}

static void flash_prog(int addr, uint8_t *data, int n)
{
	if (verbose)
		fprintf(stderr, "prog 0x%06X +0x%03X..\n", addr, n);

	uint8_t command[4] = { FC_PP, (uint8_t)(addr >> 16), (uint8_t)(addr >> 8), (uint8_t)addr };

	flash_chip_select();
	mpsse_send_spi(command, 4);
	mpsse_send_spi(data, n);
	flash_chip_deselect();

	if (verbose)
		for (int i = 0; i < n; i++)
			fprintf(stderr, "%02x%c", data[i], i == n - 1 || i % 32 == 31 ? '\n' : ' ');
}

static void flash_read(int addr, uint8_t *data, int n)
{
	if (verbose)
		fprintf(stderr, "read 0x%06X +0x%03X..\n", addr, n);

	uint8_t command[4] = { FC_RD, (uint8_t)(addr >> 16), (uint8_t)(addr >> 8), (uint8_t)addr };

	flash_chip_select();
	mpsse_send_spi(command, 4);
	memset(data, 0, n);
	mpsse_xfer_spi(data, n);
	flash_chip_deselect();

	if (verbose)
		for (int i = 0; i < n; i++)
			fprintf(stderr, "%02x%c", data[i], i == n - 1 || i % 32 == 31 ? '\n' : ' ');
}

static void flash_wait()
{
	if (verbose)
		fprintf(stderr, "waiting..");

	int count = 0;
	while (1)
	{
		uint8_t data[2] = { FC_RSR1 };

		flash_chip_select();
		mpsse_xfer_spi(data, 2);
		flash_chip_deselect();

		if ((data[1] & 0x01) == 0) {
			if (count < 2) {
				count++;
				if (verbose) {
					fprintf(stderr, "r");
					fflush(stderr);
				}
			} else {
				if (verbose) {
					fprintf(stderr, "R");
					fflush(stderr);
				}
				break;
			}
		} else {
			if (verbose) {
				fprintf(stderr, ".");
				fflush(stderr);
			}
			count = 0;
		}

		usleep(1000);
	}

	if (verbose)
		fprintf(stderr, "\n");

}
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
int main(int argc, char **argv)
{
	/* used for error reporting */
	const char *my_name = argv[0];
	for (size_t i = 0; argv[0][i]; i++)
		if (argv[0][i] == '/')
			my_name = argv[0] + i + 1;

	int read_size = 256 * 1024;
	int erase_block_size = 64;
	int erase_size = 0;
	int rw_offset = 0;

	bool read_mode = false;
	bool check_mode = false;
	bool erase_mode = false;
	bool bulk_erase = false;
	bool dont_erase = false;
	bool prog_sram = false;
	int  test_mode = 0;
	bool slow_clock = false;
	bool disable_protect = false;
	bool disable_verify = false;
	bool disable_powerdown = false;
	const char *filename = NULL;
	const char *devstr = NULL;
	int ifnum = 0;

#ifdef _WIN32
	_setmode(_fileno(stdin), _O_BINARY);
	_setmode(_fileno(stdout), _O_BINARY);
#endif

	static struct option long_options[] = {
		{"help", no_argument, NULL, -2},
		{NULL, 0, NULL, 0}
	};

	/* Decode command line parameters */
	int opt;
	char *endptr;
	while ((opt = getopt_long(argc, argv, "d:i:I:rR:e:o:cbnStQvspXkANV", long_options, NULL)) != -1) {
		switch (opt) {
		case 'd': /* device string */
			devstr = optarg;
			break;
		case 'i': /* block erase size */
			if (!strcmp(optarg, "4"))
				erase_block_size = 4;
			else if (!strcmp(optarg, "32"))
				erase_block_size = 32;
			else if (!strcmp(optarg, "64"))
				erase_block_size = 64;
			else {
				fprintf(stderr, "%s: `%s' is not a valid erase block size (must be `4', `32' or `64')\n", my_name, optarg);
				return EXIT_FAILURE;
			}
			break;
		case 'I': /* FTDI Chip interface select */
			if (!strcmp(optarg, "A"))
				ifnum = 0;
			else if (!strcmp(optarg, "B"))
				ifnum = 1;
			else if (!strcmp(optarg, "C"))
				ifnum = 2;
			else if (!strcmp(optarg, "D"))
				ifnum = 3;
			else {
				fprintf(stderr, "%s: `%s' is not a valid interface (must be `A', `B', `C', or `D')\n", my_name, optarg);
				return EXIT_FAILURE;
			}
			break;
		case 'r': /* Read 256 bytes to file */
			read_mode = true;
			break;
		case 'R': /* Read n bytes to file */
			read_mode = true;
			read_size = strtol(optarg, &endptr, 0);
			if (*endptr == '\0')
				/* ok */;
			else if (!strcmp(endptr, "k"))
				read_size *= 1024;
			else if (!strcmp(endptr, "M"))
				read_size *= 1024 * 1024;
			else {
				fprintf(stderr, "%s: `%s' is not a valid size\n", my_name, optarg);
				return EXIT_FAILURE;
			}
			break;
		case 'e': /* Erase blocks as if we were writing n bytes */
			erase_mode = true;
			erase_size = strtol(optarg, &endptr, 0);
			if (*endptr == '\0')
				/* ok */;
			else if (!strcmp(endptr, "k"))
				erase_size *= 1024;
			else if (!strcmp(endptr, "M"))
				erase_size *= 1024 * 1024;
			else {
				fprintf(stderr, "%s: `%s' is not a valid size\n", my_name, optarg);
				return EXIT_FAILURE;
			}
			break;
		case 'o': /* set address offset */
			rw_offset = strtol(optarg, &endptr, 0);
			if (*endptr == '\0')
				/* ok */;
			else if (!strcmp(endptr, "k"))
				rw_offset *= 1024;
			else if (!strcmp(endptr, "M"))
				rw_offset *= 1024 * 1024;
			else {
				fprintf(stderr, "%s: `%s' is not a valid offset\n", my_name, optarg);
				return EXIT_FAILURE;
			}
			break;
		case 'c': /* do not write just check */
			check_mode = true;
			break;
		case 'b': /* bulk erase before writing */
			bulk_erase = true;
			break;
		case 'n': /* do not erase before writing */
			dont_erase = true;
			break;
		case 'S': /* write to sram directly */
			prog_sram = true;
			break;
		case 't': /* just read flash id */
			test_mode = 1;
			break;
		case 'Q': /* just read flash id */
			test_mode = 2;
			break;
		case 'v': /* provide verbose output */
			verbose = true;
			break;
		case 's': /* use slow SPI clock */
			slow_clock = true;
			break;
		case 'p': /* disable flash protect before erase/write */
			disable_protect = true;
			break;
		case 'X': /* disable verification */
			disable_verify = true;
			break;
		case 'k': /* disable power down command */
			disable_powerdown = true;
			break;
		case 'A': /* access AURA flash */
			target = TARGET_AURA;
			break;
		case 'N': /* access NORA flash (default) */
			target = TARGET_NORA;
			break;
		case 'V': /* access VERA flash */
			target = TARGET_VERA;
			break;
		case -2:
			help(argv[0]);
			return EXIT_SUCCESS;
		default:
			/* error message has already been printed */
			fprintf(stderr, "Try `%s --help' for more information.\n", argv[0]);
			return EXIT_FAILURE;
		}
	}

	/* Make sure that the combination of provided parameters makes sense */

	if (read_mode + erase_mode + check_mode + prog_sram + !!test_mode > 1) {
		fprintf(stderr, "%s: options `-r'/`-R', `-e`, `-c', `-S', and `-t' are mutually exclusive\n", my_name);
		return EXIT_FAILURE;
	}

	if (bulk_erase && dont_erase) {
		fprintf(stderr, "%s: options `-b' and `-n' are mutually exclusive\n", my_name);
		return EXIT_FAILURE;
	}

	if (disable_protect && (read_mode || check_mode || prog_sram || test_mode)) {
		fprintf(stderr, "%s: option `-p' only valid in programming mode\n", my_name);
		return EXIT_FAILURE;
	}

	if (bulk_erase && (read_mode || check_mode || prog_sram || test_mode)) {
		fprintf(stderr, "%s: option `-b' only valid in programming mode\n", my_name);
		return EXIT_FAILURE;
	}

	if (dont_erase && (read_mode || check_mode || prog_sram || test_mode)) {
		fprintf(stderr, "%s: option `-n' only valid in programming mode\n", my_name);
		return EXIT_FAILURE;
	}

	if (rw_offset != 0 && prog_sram) {
		fprintf(stderr, "%s: option `-o' not supported in SRAM mode\n", my_name);
		return EXIT_FAILURE;
	}

	if (rw_offset != 0 && test_mode) {
		fprintf(stderr, "%s: option `-o' not supported in test mode\n", my_name);
		return EXIT_FAILURE;
	}

	if (optind + 1 == argc) {
		if (test_mode) {
			fprintf(stderr, "%s: test mode doesn't take a file name\n", my_name);
			fprintf(stderr, "Try `%s --help' for more information.\n", argv[0]);
			return EXIT_FAILURE;
		}
		filename = argv[optind];
	} else if (optind != argc) {
		fprintf(stderr, "%s: too many arguments\n", my_name);
		fprintf(stderr, "Try `%s --help' for more information.\n", argv[0]);
		return EXIT_FAILURE;
	} else if (bulk_erase || disable_protect) {
		filename = "/dev/null";
	} else if (!test_mode && !erase_mode && !disable_protect) {
		fprintf(stderr, "%s: missing argument\n", my_name);
		fprintf(stderr, "Try `%s --help' for more information.\n", argv[0]);
		return EXIT_FAILURE;
	}

	switch (target)
	{
		case TARGET_AURA:
			set_cs_creset = set_cs_creset_aura;
			get_cdone = get_cdone_vera_aura;
			break;
		case TARGET_NORA:
			set_cs_creset = set_cs_creset_nora;
			get_cdone = get_cdone_nora;
			break;
		case TARGET_VERA:
			set_cs_creset = set_cs_creset_vera;
			get_cdone = get_cdone_vera_aura;
			break;
		default:
			fprintf(stderr, "%s: the target flash memory in X65 must be specified. "
							"Give one of -N, -V or -A for NORA, VERA, or AURA.\n", 
				my_name);
			return EXIT_FAILURE;
	}

	/* open input/output file in advance
	   so we can fail before initializing the hardware */

	FILE *f = NULL;
	long file_size = -1;

	if (test_mode) {
		/* nop */;
	} else if (erase_mode) {
		file_size = erase_size;
	} else if (read_mode) {
		f = (strcmp(filename, "-") == 0) ? stdout : fopen(filename, "wb");
		if (f == NULL) {
			fprintf(stderr, "%s: can't open '%s' for writing: ", my_name, filename);
			perror(0);
			return EXIT_FAILURE;
		}
	} else {
		f = (strcmp(filename, "-") == 0) ? stdin : fopen(filename, "rb");
		if (f == NULL) {
			fprintf(stderr, "%s: can't open '%s' for reading: ", my_name, filename);
			perror(0);
			return EXIT_FAILURE;
		}

		/* For regular programming, we need to read the file
		   twice--once for programming and once for verifying--and
		   need to know the file size in advance in order to erase
		   the correct amount of memory.

		   See if we can seek on the input file.  Checking for "-"
		   as an argument isn't enough as we might be reading from a
		   named pipe, or contrarily, the standard input may be an
		   ordinary file. */

		if (!prog_sram && !check_mode) {
			if (fseek(f, 0L, SEEK_END) != -1) {
				file_size = ftell(f);
				if (file_size == -1) {
					fprintf(stderr, "%s: %s: ftell: ", my_name, filename);
					perror(0);
					return EXIT_FAILURE;
				}
				if (fseek(f, 0L, SEEK_SET) == -1) {
					fprintf(stderr, "%s: %s: fseek: ", my_name, filename);
					perror(0);
					return EXIT_FAILURE;
				}
			} else {
				FILE *pipe = f;

				f = tmpfile();
				if (f == NULL) {
					fprintf(stderr, "%s: can't open temporary file\n", my_name);
					return EXIT_FAILURE;
				}
				file_size = 0;
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

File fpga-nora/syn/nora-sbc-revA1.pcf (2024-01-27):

# X65 SBC rev.A1

#
# Bank 3
#   Pins 1 - 34
#
set_io CSYNC_VPA    1
set_io CNMIn        2
set_io CMLn         3
set_io CIRQn        4
set_io CABORTn      7
set_io CRDY         8
set_io CVPn         9
set_io CRESn        10
set_io CVDA         11
set_io CSOB_MX      12
set_io CPHI2        15
set_io CBE          16
set_io CEF          17
set_io CRWn         18
set_io CD[0]          19  
set_io CD[1]          20
set_io CD[2]          21
set_io CD[3]          22
set_io CD[4]          23
set_io CD[5]          24
set_io CD[6]          25
set_io CD[7]          26
set_io CA[15]         28
set_io CA[14]         29
set_io CA[13]         31
set_io CA[12]         32
set_io MAL[11]          33
set_io MAL[10]          34

#
# Bank 2
#   Pins 37 - 64
#
set_io MAL[9]           37
set_io MAL[8]           38
set_io MAL[7]           39
set_io MAL[6]           41
set_io MAL[5]           42
set_io MAL[4]           43
set_io MAL[3]           44
set_io MAL[2]           45
set_io MAL[1]           47
set_io MAL[0]           48
set_io M1CSn        49
set_io MD[0]           52
set_io MD[1]           55
set_io MD[2]           56
set_io MD[3]           60
set_io MD[4]           61
set_io MD[5]           62
set_io MD[6]           63
set_io MD[7]           64


#
# Bank 1
#   Pins 73 - 107
#
set_io MAH[20]          73
set_io MAH[18]          74
set_io MAH[17]          75
set_io MAH[16]          76
set_io MAH[15]          78
set_io MRDn             79
set_io MAH[19]          80
set_io UE_IRQn          81
set_io PS2M_DATA        82
set_io PS2M_CLK         83
set_io MWRn         84
set_io I2C_SCL      85
set_io I2C_SDA      87
set_io EIRQn        88
set_io AIRQn        90
set_io VIRQn        91
set_io ACS1n        93
set_io VCS0n        94
set_io UE_CS3n      95
set_io UE_SCK       96
set_io UE_CSn       97
set_io UE_MISO      98
set_io UE_MOSI      99
set_io UE_SCL       101
set_io UE_SDA       102
set_io UE_TXD       104
set_io UE_RXD       105
set_io PS2K_DATA    106
set_io PS2K_CLK     107

#
# Bank 0
#   Pins 110 - 144
#
set_io CPUTYPE02    110
set_io UART_RTS     112
set_io UART_CTS     113
set_io UART_TX      114
set_io UART_RX      115
set_io VEAURADONE   116
set_io VERARSTn     117
set_io ERSTn        118
set_io ARSTn        119
set_io ICD_CSn      120
set_io ICD_MOSI     121
set_io ICD_MISO     122
set_io ECS2n        124
set_io DIPLED0      125
set_io ICD_SCK      128
set_io FPGACLK      129
set_io NESDATA0     130
set_io NESDATA1     134
set_io NESCLOCK     135
set_io NESLATCH     136
set_io DIPLED1      137
set_io MAH[12]          138
set_io MAH[13]          139
set_io MAH[14]          141
set_io ATTBTN       142
set_io CPULED0      143
set_io CPULED1      144


#
# Bank SPI
#
set_io FMOSI        67
set_io FMISO        68
set_io FSCK         70
set_io FLASHCSn     71

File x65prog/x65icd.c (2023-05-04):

/*
 *  x65icd -- ICD tool for OpenX65 with FTDI-based USB/SPI interface,
 *
 *  Copyright (C) 2015  Clifford Wolf <clifford@clifford.at>
 *  Copyright (C) 2018  Piotr Esden-Tempski <piotr@esden.net>
 *
 *  Permission to use, copy, modify, and/or distribute this software for any
 *  purpose with or without fee is hereby granted, provided that the above
 *  copyright notice and this permission notice appear in all copies.
 *
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
 *  Relevant Documents:
 *  -------------------
 *  http://www.latticesemi.com/~/media/Documents/UserManuals/EI/icestickusermanual.pdf
 *  http://www.micron.com/~/media/documents/products/data-sheet/nor-flash/serial-nor/n25q/n25q_32mb_3v_65nm.pdf
 */

#define _GNU_SOURCE

#include <stdio.h>
#include <stdint.h>
#include <stdbool.h>
#include <stdlib.h>
#include <unistd.h>
#include <string.h>
#include <getopt.h>
#include <errno.h>
#include <sys/types.h>
#include <sys/stat.h>
#include <time.h>

#ifdef _WIN32
#include <io.h> /* _setmode() */
#include <fcntl.h> /* _O_BINARY */
#endif

#include "mpsse.h"

static bool verbose = false;

// ---------------------------------------------------------
// ICD definitions
// ---------------------------------------------------------

#define BLOCKSIZE 		256
#define PAGESIZE		8192
#define SIZE_2MB 		(2048 * 1024)


#define CMD_GETSTATUS 		0x0
#define CMD_BUSMEM_ACC 		0x1
#define CMD_CPUCTRL 		0x2
#define CMD_READTRACE 		0x3

#define nSRAM_OTHER_BIT 	4
#define nWRITE_READ_BIT 	5
#define ADR_INC_BIT 		6



// ---------------------------------------------------------
// Hardware specific CS, CReset, CDone functions
// ---------------------------------------------------------

static void set_flash_cs_creset(int cs_b, int creset_b)
{
	uint8_t gpio = 0;
	uint8_t direction = 0x03;

	if (!cs_b) {
		// ADBUS4 (GPIOL0)
		direction |= 0x10;
	}

	if (!creset_b) {
		// ADBUS7 (GPIOL3)
		direction |= 0x80;
	}

	mpsse_set_gpio_low(gpio, direction);
}

static bool get_cdone(void)
{
	// ADBUS6 (GPIOL2)
	return (mpsse_readb_low() & 0x40) != 0;
}

// ---------------------------------------------------------
// FLASH function implementations
// ---------------------------------------------------------

// bit masks of the signals on ACBUSx
#define ICD2NORAROM 		0x01			// ACBUS0
#define ICDCSN				0x02			// ACBUS1
#define ICD2VERAROM			0x04			// ACBUS2
#define VERA2FCSN			0x08			// ACBUS3
#define VERAFCSN			0x10			// ACBUS4
#define VERADONE			0x40			// ACBUS6
#define VERARSTN			0x80			// ACBUS7

#if 0
// configure the high-byte (ACBUSx) to route SPI to the flash,
// and disable ICD.
static void x65_select_flash()
{
	// drive high ICD2NORAROM, ICDCSN, keep others as IN.
	mpsse_set_gpio_high(ICD2NORAROM | ICDCSN | VERA2FCSN | VERAFCSN | VERADONE | VERARSTN, 
				ICD2NORAROM | ICDCSN);
}
#endif

// configure the high-byte (ACBUSx) to route SPI to the ICD,
// and keep ICD high (deselect).
static void x65_idle()
{
	// drive low ICD2NORAROM (this unroutes SPI to flash),
	// drive high ICDCSN, keep others as IN.
	mpsse_set_gpio_high(ICDCSN | VERA2FCSN | VERAFCSN | VERADONE | VERARSTN, 
				ICD2NORAROM | ICDCSN);
}

// the FPGA reset is released so also FLASH chip select should be deasserted
static void flash_release_reset()
{
	set_flash_cs_creset(1, 1);
}

// ICD chip select assert
// should only happen while ICD2NORAROM=Low
static void icd_chip_select()
{
	// drive low ICD2NORAROM (this unroutes SPI to flash),
	// drive low ICDCSN to activate the ICD
	mpsse_set_gpio_high(VERA2FCSN | VERAFCSN | VERADONE | VERARSTN, 
				ICD2NORAROM | ICDCSN);
}

// ICD chip select deassert
static void icd_chip_deselect()
{
	// drive low ICD2NORAROM (this unroutes SPI to flash),
	// drive high ICDCSN to de-activate the ICD
	mpsse_set_gpio_high(ICDCSN | VERA2FCSN | VERAFCSN | VERADONE | VERARSTN, 
				ICD2NORAROM | ICDCSN);
}

// #define ICD_SRAM_WRITE		0x01
// #define ICD_SRAM_READ		0x03

#define ICD_SRAM_WRITE			(CMD_BUSMEM_ACC | (1 << ADR_INC_BIT))
#define ICD_SRAM_READ			(CMD_BUSMEM_ACC | (1 << nWRITE_READ_BIT) | (1 << ADR_INC_BIT))



static void icd_busread(uint8_t cmd, uint32_t maddr, int n, uint8_t *data)
{
	uint8_t hdr[5] = { cmd, maddr & 0xFF, maddr >> 8, maddr >> 16, 0x00 /*dummy*/ };

    icd_chip_select();
    mpsse_xfer_spi(hdr, 5);
    mpsse_xfer_spi(data, n);
    icd_chip_deselect();
}

static void icd_buswrite(uint8_t cmd, uint32_t maddr, int n, uint8_t *data)
{
	uint8_t hdr[4] = { cmd, maddr & 0xFF, maddr >> 8, maddr >> 16 };

    icd_chip_select();
    mpsse_xfer_spi(hdr, 4);
    mpsse_xfer_spi(data, n);
    icd_chip_deselect();
}


static void icd_sram_blockwrite(uint32_t maddr, int n, uint8_t *data)
{
	icd_buswrite(ICD_SRAM_WRITE, maddr, n, data);
}

static void icd_sram_blockread(uint32_t maddr, int n, uint8_t *data)
{
	icd_busread(ICD_SRAM_READ, maddr, n, data);
}

static void rand_fill_block(uint8_t *buf)
{
	for (int i = 0; i < BLOCKSIZE; i += 2)
	{
		uint16_t r = (uint16_t)rand();
		buf[i] = r;
		buf[i+1] = r >> 8;
	}
}

static int icd_sram_memtest(unsigned int seed, uint32_t mstart, int mbytes)
{
	uint8_t buf[BLOCKSIZE];
	int blocks = mbytes / BLOCKSIZE;

	printf("SRAM Memtest from 0x%08X to 0x%08X, rand seed 0x%08X\n",
			mstart, mstart + mbytes - 1, seed);

	srand(seed);

	for (int b = 0; b < blocks; b++)
	{
		rand_fill_block(buf);
		if ((b * BLOCKSIZE) % PAGESIZE == 0)
		{
			printf("  Writing page %d (0x%08X to 0x%08X)...\n", (b + mstart/BLOCKSIZE) * BLOCKSIZE / PAGESIZE,
					(b + mstart/BLOCKSIZE) * BLOCKSIZE, ((b+1) + mstart/BLOCKSIZE) * BLOCKSIZE - 1);
		}
		icd_sram_blockwrite(mstart + b * BLOCKSIZE, BLOCKSIZE, buf);
	}
	
	srand(seed);

	uint8_t buf2[BLOCKSIZE];
	int errors = 0;

	for (int b = 0; b < blocks; b++)
	{
		if ((b * BLOCKSIZE) % PAGESIZE == 0)
		{
			printf("  Reading page %d (0x%08X to 0x%08X)...\n", (b + mstart/BLOCKSIZE) * BLOCKSIZE / PAGESIZE,
					(b + mstart/BLOCKSIZE) * BLOCKSIZE, ((b+1) + mstart/BLOCKSIZE) * BLOCKSIZE - 1);
		}
		icd_sram_blockread(mstart + b * BLOCKSIZE, BLOCKSIZE, buf);
		rand_fill_block(buf2);
		if (memcmp(buf, buf2, BLOCKSIZE))
		{
			++errors;
			printf("  Error in page %d (0x08%X to 0x08%X)!\n", (b + mstart/BLOCKSIZE) * BLOCKSIZE / PAGESIZE,
						mstart + b*BLOCKSIZE, mstart + (b-1)*BLOCKSIZE - 1);
		}
	}

	printf("Memtest done with %d errors.\n", errors);
	return errors;
}


static void icd_cpu_ctrl(int run_cpu, int cstep_cpu, int reset_cpu)
{
	run_cpu &= 1;
	cstep_cpu &= 1;
	reset_cpu &= 1;

	uint8_t hdr[2] = { CMD_CPUCTRL | (run_cpu << 4) | (cstep_cpu << 5), reset_cpu };

    icd_chip_select();
    mpsse_xfer_spi(hdr, 2);
    icd_chip_deselect();
}

static void icd_cpu_read_trace(int *is_valid, int *is_ovf, uint8_t *tbuf, int tbuflen)
{
	uint8_t hdr[3] = { CMD_READTRACE, 0 /*dummy*/, 0 /*RX:buf-status*/ };

    icd_chip_select();
    mpsse_xfer_spi(hdr, 3);
	*is_valid = hdr[2] & 1;
	*is_ovf = hdr[2] & 2;

    mpsse_xfer_spi(tbuf, tbuflen);
    
	icd_chip_deselect();
}
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

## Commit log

2023-04-11 PCB mobo rev01
    [#101--openX65 BOM.ods, 5749180-1.step, 5749180-1.stp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]
2023-04-12 65C02 is alive: trace and icd cpu control
2023-04-18 Started the video/audio board
    [BOM Open65.ods, BOM Overview Open65.ods, CUI_MD-40S.step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]
2023-04-28 V/A board rev01 finished and submitted to pcbway
    [BOM Overview Open65.ods, PCB Constraints.ods, openX65 vabo BOM.ods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]
2023-04-29 start of pythonic ICD
    [Address Space.ods]
2023-04-30 Implement basic simple_via; missing timer regs
    [Address Space.ods]
2023-04-30 Add LED-blink x65 program
2023-05-04 PS2 port can read keyboard scan-codes
    [Address Space.ods]
2023-05-07 pcb productions: update assembling scm/bom
    [M#101--openX65 BOM.ods, V#101--openX65 vabo BOM--assembled.ods]
2023-05-13 Various updates; I2C slave
    [Address Space.ods]
2023-05-13 Fix RAMBANK_MASK, add dummy SMC with I2C Slave
    [do-cpureset.py, do-cpustep.py]
2023-05-13 CX16 is READY.
    [Address Space.ods]
2023-05-14 New photos, update Address Space
    [Address Space.ods]
2023-05-15 cpustep: fix disassembly; poke: add banks area
    [do-cpustep.py, do-poke.py]
2023-05-15 fix verilog undefined wires
    yosis reports undefined wires just as warnings, but then the
    output bitstream fails intermitently... what?
2023-05-21 Photos: front and rear view with connectors
2023-06-02 smc: respond to BAT OK (0xAA) by sending LED-Off sequence
2023-06-10 vabo: audio assembly and testing...
    [V#101--openX65 vabo BOM--assembled.ods]
2023-06-20 Update readme & scm with the latest PCB bringup info
2023-07-03 nora: invert the NESCLOCK and NESLATCH since we assembled the 74LVC2G17 buffer
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2023-07-16 Add initial PBL ROM code (led blink)
2023-07-16 nora: fix bootrom writing from the icd
    [do-loadbin.py, do-loadprg.py, do-poke.py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]
2023-07-22 nora: spi master and host, syregs at 0x9F50 started
2023-07-29 rom pbl can load CX16 ROM from SPI-Flash
    TBD: hard-coded length and parameters
    TBD: NORA starts in debug-stop by default
2023-07-29 update Address Space table
    [Address Space.ods]
2023-08-11 Experimental AURA code using JT51 in UP5K, but it does not fit.
    [aura-vabo-rev01.pcf]
2023-10-29 Update bringup scm pdf with test notes
    [speakers.ods]
2023-10-30 AURA: rework to IKAOPM, testbench works, synthesis fits in 5k device
    up5k device:
    Info: Device utilisation:
    Info: ICESTORM_LC: 4519/ 5280 85%
    Info: ICESTORM_RAM: 10/ 30 33%
    Info: SB_IO: 30/ 96 31%
    Info: SB_GB: 8/ 8 100%
    Info: ICESTORM_PLL: 0/ 1 0%
    Info: SB_WARMBOOT: 0/ 1 0%
    Info: ICESTORM_DSP: 0/ 8 0%
    Info: ICESTORM_HFOSC: 0/ 1 0%
    Info: ICESTORM_LFOSC: 0/ 1 0%
    Info: SB_I2C: 0/ 2 0%
    Info: SB_SPI: 0/ 2 0%
    Info: IO_I3C: 0/ 2 0%
    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
2023-11-02 nora's ikaopm: switch to compressed channel outputs as recommended
2023-11-03 nora: add PBL mem files, although they are generated from assembly
2023-11-25 add rom-sbl/Makefile: flashing SBL to the NORA Spi-flash
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2023-11-25 nora: integrate the trace buffer memory
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2023-11-25 doc Address Space update with AURA, IO REGS, WIZNET
    [Address Space.ods]
2023-12-02 nora: implement the Attention button -> short-press triggers NMI, long-press (>1s) does system reset
2023-12-02 fix do-loadprg.py start address
    [do-loadprg.py]
2023-12-09 update schematic with corrections
2023-12-10 Update BOM and add wiznet notes
    [BOM Overview Open65.ods]
2023-12-14 BOM update/cleanup
    [BOM Overview Open65.ods]
2023-12-16 nora: cleanup the M and X flag in case of emulation
2023-12-16 update scm pdf and address space sheet
    [Address Space.ods]
2023-12-16 do-cpustep: handle M, X; add sanity checks for comm errors
    [do-cpustep.py]
2023-12-18 nora: record the Cpu Bank Address in trace buffer; display in do-cpustep.py
2023-12-22 nora: memory map rework to suit 65c816
    [Address Space.ods]
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2023-12-26 update docu
    [Address Space.ods, BOM Overview Open65.ods]
2023-12-26 nora: hack ps2 top-level wiring to work on both boards of rev01 that i have
2023-12-26 pyhost: read cputype from FTDI strap and use it in cpu instr. decoding
2024-01-01 doc update
    [Address Space.ods, BOM Overview Open65.ods, BOM_Overview_SBC.ods]
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2024-01-01 pcb: 3d-step models for speaker, sdcard, ethernet jack
    [CMS-28528N-L152.stp, DM1AA-SF-PEJ.STEP, RJMG1BD3B8K1ANR--3DModel-STEP-56544.STEP]
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2024-01-01 pcb: started the sbc
    [02-cpu_sram.kicad_sch, 03-nora_fpga.kicad_sch, 04-rtc_snes.kicad_sch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]
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2024-01-03 nora: uart_host with tb, doc: ioregs in progress (with futures :-)
2024-01-06 new BOM updates
    [Address Space.ods, BOM Overview Open65.ods, BOM_Overview_SBC.ods]
2024-01-06 pcb: fix footprints based on DRC errors
2024-01-06 pcb sbc: more pcb work
    [02-cpu_sram.kicad_sch, 03-nora_fpga.kicad_sch, 04-rtc_snes.kicad_sch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]
2024-01-07 nora uart: first syn works, basic hwflow works
2024-01-07 nora: fix UART HwFlowControl RTS generation
2024-01-13 x65-sbc: pcb done
    [02-cpu_sram.kicad_sch, 03-nora_fpga.kicad_sch, 04-rtc_snes.kicad_sch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]
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2024-01-13 pcb/scm x65-sbc update
    [03-nora_fpga.kicad_sch, x65-sbc-revA1.kicad_pcb, x65-sbc-revA1.kicad_sch]
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2024-01-13 sbc rev.A1 gerbers
    [x65-sbc-revA1-B_Cu.gbr, x65-sbc-revA1-B_Mask.gbr, x65-sbc-revA1-B_Paste.gbr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]
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2024-01-15 nora: change SPI regs to the triple CTRL+STAT+DATA as per ioregs.md, update PBL code
2024-01-26 nora rom: fix red led blinking
2024-01-26 nora: fix do-cpustep after change in ROMBLOCK bits regarding bootrom
    [do-cpustep.py, icd.py]
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2024-01-27 nora: implement via#2 and move leds there, update of pbl
2024-01-28 testsw: add baremetal memory test with UART output
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2024-02-11 update SBC bom overview
    [BOM_Overview_SBC.ods]
2024-02-12 Add SBC revB1
    [02-cpu_sram.kicad_sch, 03-nora_fpga.kicad_sch, 04-rtc_snes.kicad_sch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]
2024-02-12 update sbc-revB1
    [02-cpu_sram.kicad_sch, 03-nora_fpga.kicad_sch, 04-rtc_snes.kicad_sch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]
2024-02-12 various updated related to the pcb
    [x65-sbc-revA1.csv, x65-sbc-revA1.ods]
2024-02-16 cleanup obsolete files
    [BOM_Overviev_MOBO_VABO_obsolete.ods, BOM_Overview_SBC.ods, PCB Constraints.ods]
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2024-03-16 x65pyhost icd MAHDecode fixes wrong "upcoming instruction" print.
    [cpuidec.py, do-cpustep.py, icd.py]
2024-03-16 rom-pbl: add debugging option to reset through any ROMBLOCK rom
    [do-dump.py]
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2024-03-22 move nora reg addresses: SPI to the end, move RAMBMASK
2024-03-23 new spi-flash sbl/app organization: update of the pbl
2024-03-23 icd.py: fix the online determination if PBL bootrom is active by reading the rmbctrl reg
    [icd.py]
2024-03-24 cpuidec: make value width explicit in the prints
2024-03-24 pcb: update the overview list of components with the current stock
    [BOM_Overview_SBC.ods]
2024-03-27 vt: corrected the wrong screen print position: vera does not like 16-bit stores!!
2024-03-30 nora: disable ABRT02 mode on cpu reset always
    [sysregs.v]
2024-03-30 icd: fix trace decode in the case ROMBLOCKs are disabled
    [cpuidec.py, icd.py]
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2024-04-01 icd: fix memory decode map in instruction trace prints
    [icd.py]
2024-04-06 of816: add initial kbd driver, works a bit
2024-04-13 pcb: add notes to the corrections pdf
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2024-04-23 do-i2cdump.py can dump RTC or EEPROM EUI data
2024-11-26 add pcb/3dshapes step models
    [AA4040.stp, CMS-28528N-L152.stp, PTS645VN13SMTR92LFS.stp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]
2025-01-03 remove pcb/ftdi-test - obsolete
    [ftdi-test.kicad_pcb, ftdi-test.kicad_sch]
2025-01-03 remove pcb/mobo - obsolete design
    [b2b-conns.kicad_sch, cpu_sram.kicad_sch, fpga.kicad_sch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]
2025-01-03 remove pcb/vabo - obsolete design
    [openX65 vabo BOM.ods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]
